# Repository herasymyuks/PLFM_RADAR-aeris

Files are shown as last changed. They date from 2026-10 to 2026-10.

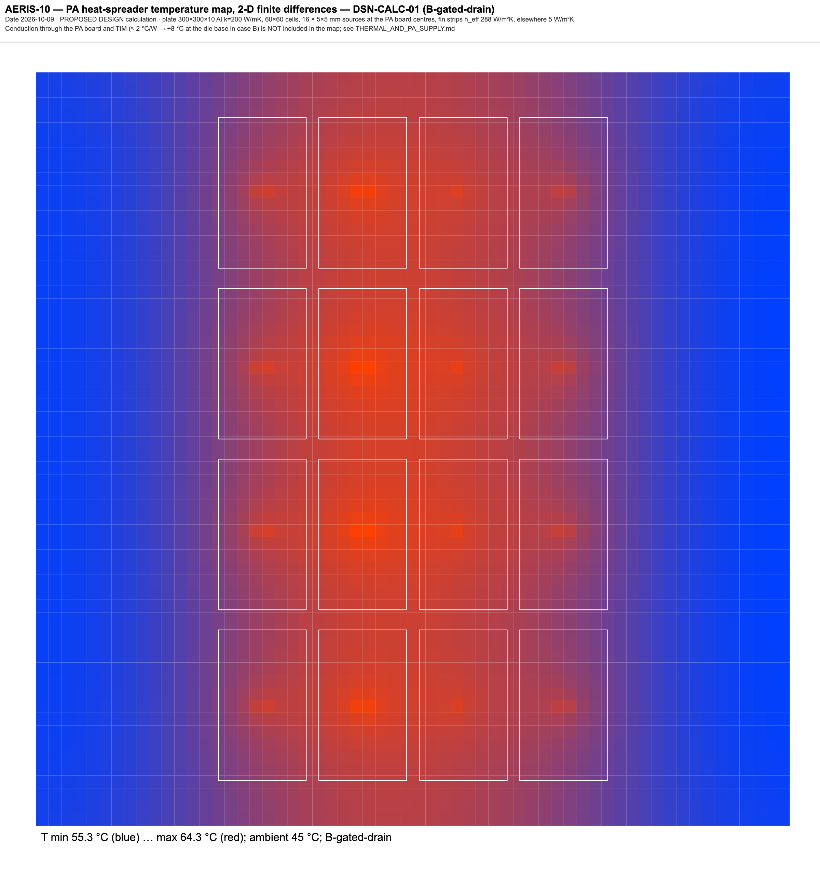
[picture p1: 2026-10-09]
manual/figures/thermal_map_B-gated-drain.png

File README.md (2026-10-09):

# AERIS-10: Open Source Pulse Linear Frequency Modulated Phased Array Radar



)


AERIS-10 Radar System

AERIS-10 is an open-source, low-cost 10.5 GHz phased array radar system featuring Pulse Linear Frequency Modulated (LFM) modulation. Available in two versions (3km and 20km range), it's designed for researchers, drone developers, and serious SDR enthusiasts who want to explore and experiment with phased array radar technology.

AERIS-10 Radar System

## 📡 Overview

The AERIS-10 project aims to democratize radar technology by providing a fully open-source, modular, and hackable radar system. Whether you're a university researcher, a drone startup, or an advanced maker, AERIS-10 offers a platform for experimenting with beamforming, pulse compression, Doppler processing, and target tracking.

## 🔬 Key Features

- **Open Source Hardware & Software** - Complete schematics, PCB layouts, firmware, and software available
- **Dual Version Availability**:
  - **AERIS-10N (Nexus)**: 3km range with 8x16 patch antenna array
  - **AERIS-10X (Extended)**: 20km range with 32x16 dielectric-filled slotted waveguide array
- **Full Electronic Beam Steering** - ±45° electronic steering in elevation and azimuth
- **Advanced Signal Processing** - On-board FPGA handles pulse compression, Doppler FFT, MTI, and CFAR
- **Python GUI** - User-friendly interface with map integration
- **GPS/IMU Integration** - Real-time position and attitude correction
- **Modular Design** - Separate power management, frequency synthesis, and RF boards

## 🏗️ System Architecture

AERIS-10 Radar System

### Hardware Components

The AERIS-10 main sub-systems are:

- **Power Management Board** - Supplies all necessary voltage levels to the electronics components with proper filtering and sequencing (sequencing ensured by the microcontroller)

- **Frequency Synthesizer Board** - Uses a high-performance Low Jitter Clock Generator (AD9523-1) that supplies phase-aligned clock references for:
  - RX and TX Frequency Synthesizers (ADF4382)
  - DAC
  - ADC
  - FPGA

- **Main Board** containing:
  - **DAC** - Generates the RADAR Chirps
  - **2x Microwave Mixers (LT5552)** - For up-conversion and IF-down-conversion
  - **4x 4-Channel Phase Shifters (ADAR1000)** - For RX and TX chain beamforming
  - **16x Front End Chips (ADTR1107)** - Used for both Low Noise Amplifying (RX) and Power Amplifying (TX) stages
  - **XC7A50T-2FTG256I FPGA** (per the Main Board schematic, U42; earlier documentation said XC7A100T — see `docs/FPGA/FPGA_PROJECT_RECONSTRUCTION.md`) - Handles RADAR Signal Processing:
    - PLFM Chirps generation via the DAC
    - Raw ADC data read
    - Automatic Gain Control (AGC)
    - I/Q Baseband Down-Conversion
    - Decimation
    - Filtering
    - Forward FFT
    - Pulse Compression
    - Doppler, MTI and CFAR processing
    - USB Interface
  - **STM32F746xx Microcontroller** - Used for:
    - Power-up and power-down sequencing (see Power Management Excel File)
    - FPGA communication
    - Setup and Interface with:
      - Clock Generator (AD9523-1)
      - 2x Frequency Synthesizers (ADF4382)
      - 4x 4-Channel Phase Shifters (ADAR1000) for RADAR pulse sequencing
      - 2x ADS7830 ADCs (on Power Amplifier Boards) for Idq measurement
      - 2x DAC5578 (on Power Amplifier Boards) for Vg control
      - GPS module for GUI map centering
      - GY-85 IMU for pitch/roll correction of target coordinates
      - BMP180 Barometer
      - Stepper Motor
      - 8x ADS7830 Temperature Sensors for cooling fan control
      - RF switches

- **16x Power Amplifier Boards** - Used only for AERIS-10E version, featuring 10Watt QPA2962 GaN amplifier for extended range

- **Antenna Arrays**:
  - **AERIS-10N (Nexus)** - 8x16 patch antenna array
  - **AERIS-10X (Extended)** - 32x16 dielectric-filled slotted waveguide antenna array

- **Miscellaneous Components**:
  - Slip-Ring
  - Stepper Motor and drivers
  - Cooling Fans
  - Enclosure) 

### Processing Pipeline

1. **Waveform Generation** - DAC creates LFM chirps
2. **Up/Down Conversion** - LT5552 mixers handle frequency translation
3. **Beam Steering** - ADAR1000 phase shifters control 16 elements
4. **Signal Processing (FPGA)**:
   - Raw ADC data capture
   - I/Q baseband down-conversion
   - Decimation & filtering (CIC/FIR)
   - Pulse compression
   - Doppler FFT processing
   - MTI & CFAR detection
5. **System Management (STM32)**:
   - Power sequencing
   - Peripheral configuration
   - GPS/IMU integration
   - Stepper motor control
6. **Visualization (Python GUI)**:
   - Real-time target plotting
   - Map integration
   - Radar control interface

AERIS-10 Radar System

## 📊 Technical Specifications

| Parameter | AERIS-10N (Nexus) | AERIS-10X (Extended) |
|---|---|---|
| **Frequency** | 10.5 GHz | 10.5 GHz |
| **Max Range** | 3 km | 20 km |
| **Antenna** | 8x16 Patch Array | 32x16 Slotted Waveguide |
| **Beam Steering** | Electronic (±45°) | Electronic (±45°) |
| **Mechanical Scan** | 360° (stepper motor) | 360° (stepper motor) |
| **Output Power** | ~1Wx16 | 10Wx16 (GaN amplifier) |
| **Processing** | FPGA + STM32 | FPGA + STM32 |

## 🚀 Getting Started

### Prerequisites

- Basic understanding of radar principles
- Experience with PCB assembly (for hardware build)
- Python 3.8+ for the GUI software
- FPGA development tools (Vivado) for signal processing modifications

### Hardware Assembly

1. **Order PCBs**: the designer-released EAGLE export does not exist in `4_Schematics and Boards Layout/4_7_Production Files` (only the Synthesizer P&P/BOM). KiCad-converted manufacturing packages (Gerber, drill, drawings, STEP, DRC) for all four boards are in `engineering/PCB/<BOARD>/` (status in each README — Main and Power Board layouts are unfinished in the source); BETA completions in `beta/pcb/`.
2. **Source Components**: bills of materials with reference designators in `docs/BOM/` (no manufacturer part numbers in the source schematics; BETA BOMs with proposed MPNs in `beta/pcb/`).
3. **Assembly**: `engineering/ASSEMBLY/ASSEMBLY_SEQUENCE.md`, `PARTS_LIST.md` and the CONCEPTUAL exploded view (the `10_docs/assembly_guide.md` referenced earlier was never committed).
4. **Antenna**: no antenna CAD exists in the repository; a PROPOSED 16×8 patch-array panel (KiCad) is in `engineering/DESIGN/ANTENNA/`.
5. **Enclosure**: no enclosure files exist (the `10_docs/Hardware/Enclosure` folder referenced earlier was never committed); a PROPOSED head/pedestal design (FreeCAD/STEP, drawings) is in `engineering/DESIGN/MECHANICAL/`.

> **Reconstruction status (2026-10-09):** see `docs/AERIS10_ENGINEERING_BUILD_MANUAL.md` (master manual), `engineering/DRAWING_REGISTER.md` and `beta/README.md`. Run `bash tools/run_all_checks.sh` for the current validation state.

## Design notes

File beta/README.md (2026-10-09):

# beta/ — BETA completions of the missing AERIS-10 elements

Created 2026-10-09. Everything here is **BETA**: it builds/parses/simulates/routes with the tools on the authoring machine but has **not** been synthesised in Vivado, flashed, run on hardware, reviewed by the original designer or fabricated. Originals under `9_Firmware/` and `4_Schematics and Boards Layout/` are untouched; each sub-project starts from a copy and keeps a `CHANGELOG.md` of every change.

| Sub-project | Content | Build/verify | Status |
|---|---|---|---|
| `fpga/` | RTL copies with syntax/driver fixes, the 5 missing modules (ADC capture, matched-filter chain, range-bin decimator, FFT wrappers), seg3 `.mem`, self-checking testbenches, timing + schematic-derived XDC, Vivado Tcl | `bash beta/fpga/build.sh` (iverilog + verilator) | see `fpga/README.md` |
| `stm32/` | Firmware copies with the 7 defect fixes and hardware-truth decisions (8 MHz HSE), hand-written CubeMX-equivalent files (USB CDC, startup, linker, HAL conf), CMake build with the ARM GNU toolchain, host unit tests | `bash beta/stm32/build.sh` | see `stm32/README.md` |
| `gui/` | `aeris10_gui` package: firmware-exact settings packet, FPGA packet parser, CDC I/O, CFAR/clustering/tracking, simulator, Tk UI, pytest suite, PyInstaller | `pytest -q` in `beta/gui` | see `gui/README.md` |
| `pcb/` | KiCad routing completion (Freerouting), placement of off-board parts, DRC dispositions, BOMs with proposed MPNs, fabrication notes/stack-up proposals, re-exported packages | DRC reports in each board folder | see `pcb/README.md` |

Simulation of the proposed antenna (openEMS, built from source on this machine) is reported in `engineering/DESIGN/ANTENNA/` once run.

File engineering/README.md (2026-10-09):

# engineering/ — AERIS-10 engineering drawings and CAD package

Generated 2026-10-09 (claude.md addendum §16–26). Everything here is derived from the repository's native design files; the EAGLE `.sch/.brd` files remain the design masters and were not modified. Start with:

- `DRAWING_REGISTER.md` — all 73 registered drawings with status (39 SOURCE-DERIVED, 28 PARTIAL, 1 CONCEPTUAL, 5 BLOCKED — MISSING DATA; 0 VERIFIED).
- `MISSING_DRAWINGS_RECOVERY_PLAN.md` — step-by-step guides MDR-01…MDR-11 for what could not be generated.
- `VALIDATION/` — `DRAWING_CHECKS.md` (what was checked and how), `CAD_EXPORT_LOG.md` (every kicad-cli command + exit code), `PCB_CROSS_CHECK.md` (EAGLE XML ↔ KiCad counts), `UNRESOLVED_GEOMETRY.md` (G-01…G-12).

| Directory | Content | Generator |
|---|---|---|
| `SYSTEM/block_diagrams`, `interfaces`, `data_flow`, `architecture/README.md` | SYS-01…SYS-03 DOT + SVG/PDF/PNG, Mermaid twin, interconnection table | hand-authored DOT from schematic nets (Graphviz) |
| `ELECTRICAL/schematics/<BOARD>/` | SVG per sheet, multi-page PDF, PNG, `sheets.json` | `tools/render_eagle_schematic.py`, `tools/svg_sheets_to_pdf.py` |
| `ELECTRICAL/netlists`, `connection_diagrams` | netlist CSV (by net, by part), connection reports, unresolved-connection and missing-symbol/footprint reports | `tools/gen_schematic_reports.py` |
| `ELECTRICAL/power_distribution` | ELEC-PWR-01 diagram + 36-row rail register | hand-authored DOT |
| `PCB/<BOARD>/` | KiCad conversion (`kicad/`), Gerber, drill, PDF drawings, SVG layers, DXF/STEP, P&P, BOM, IPC-2581, IPC-D-356, DRC, 3-D renders, `README.md`, `STACKUP.md` | `tools/kicad_pcb_pipeline.sh`, `tools/kicad_project_from_dru.py`, `tools/gen_engineering_pcb_docs.py` |
| `MECHANICAL/CAD`, `STEP`, `DXF`, `PDF`, `dimensions` | board bodies, outlines + holes (two independent DXF sources), 1:1 plan view, dimension sheets with hole tables | `tools/gen_mechanical_package.py` |
| `ASSEMBLY/` | parts list, assembly sequence, CONCEPTUAL exploded view, per-board assembly drawing index | `tools/gen_assembly_exploded_view.py` + hand-written MD |
| `SOFTWARE_DIAGRAMS/FPGA`, `STM32`, `PYTHON`, `DATA_FLOW` | SD-01…SD-07 DOT + renders, hierarchy/module tables | `tools/gen_verilog_hierarchy.py`, `tools/gen_python_module_graph.py`, hand-authored DOT |

Regenerate everything (≈ 10 min, needs KiCad 10 and Google Chrome on the machine; Graphviz for the DOT renders):

```bash
bash tools/kicad_pcb_pipeline.sh                      # 4 boards → engineering/PCB/*
python3 tools/gen_engineering_pcb_docs.py             # README/STACKUP per board + PCB_CROSS_CHECK.md
python3 tools/gen_schematic_reports.py                # netlists + connection reports
for b in RF_PA FREQUENCY_SYNTHESIZER MAIN_BOARD POWER_SUPPLY; do
  python3 tools/render_eagle_schematic.py "<path to .sch>" --out engineering/ELECTRICAL/schematics/$b/svg --board $b --root .
  python3 tools/svg_sheets_to_pdf.py -o engineering/ELECTRICAL/schematics/$b/${b}_schematic.pdf --png-dir engineering/ELECTRICAL/schematics/$b/png engineering/ELECTRICAL/schematics/$b/svg/*.svg
done
python3 tools/gen_mechanical_package.py && python3 tools/gen_assembly_exploded_view.py
python3 tools/gen_verilog_hierarchy.py --rtl 9_Firmware/9_2_FPGA --out engineering/SOFTWARE_DIAGRAMS/FPGA
python3 tools/gen_python_module_graph.py
for d in $(find engineering -name "*.dot"); do dot -Tsvg -o ${d%.dot}.svg $d; dot -Tpdf -o ${d%.dot}.pdf $d; dot -Tpng -Gdpi=150 -o ${d%.dot}.png $d; done
python3 tools/gen_drawing_register.py --check
```

Size note: `PCB/MAIN_BOARD/ipc/MAIN_BOARD.xml.gz` and the other large IPC-2581 files are gzip-compressed; `gunzip -k` before use.

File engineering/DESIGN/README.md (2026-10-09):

# engineering/DESIGN — PROPOSED designs for the missing elements

Generated 2026-10-09. Everything here is new engineering content (status **PROPOSED DESIGN**), derived from the verified constraints in the repository plus the decisions logged in `00_DESIGN_BASIS.md` (D-01…D-15). Parameters: `design_parameters.json` (single source; every generator reads it). Nothing here has been simulated on hardware, built or measured.

| Item | Directory | Native / editable | Exports | Generator |
|---|---|---|---|---|
| Design basis + decision log | `00_DESIGN_BASIS.md`, `design_parameters.json` | Markdown/JSON | — | hand-written |
| Antenna: 16-row × 8-patch microstrip array, 10.5 GHz, RO4350B | `ANTENNA/` | `kicad/aeris10_patch_array.kicad_pcb` (KiCad 8+) | layout SVG/PDF/PNG, Gerber + drill + STEP + render in `kicad_exports/`, `ANTENNA_DESIGN_CALC.md`, `openems_patch_row.py` | `tools/design_antenna_array.py` |
| Thermal budget, 22 V supply sizing | `THERMAL/` | Markdown + JSON | — | `tools/design_thermal.py` |
| 22 V PA supply / enable switch / per-PA pulse gating | `ELECTRICAL/PA_SUPPLY_22V/` | block schematic SVG (editable), BOM CSV, net list | PDF/PNG | `tools/design_pa_supply_schematic.py` |
| Radar head + pedestal 3-D | `MECHANICAL/CAD/` | `aeris10_head_pedestal.FCStd` (FreeCAD 1.1) | STEP (assembly, head, pedestal), STL, TechDraw DXF page, mass table, isometric SVG/PDF/PNG (`tools/stl_to_svg_iso.py`) | `tools/design_mechanical_freecad.py` (run with `freecadcmd`) |
| Head/pedestal 2-D drawings DSN-MECH-01…05 | `MECHANICAL/drawings/` | SVG 1:1 | PDF (5 pages), PNG | `tools/design_mechanical_drawings.py` |
| Harness schedule (144 cables, computed lengths) | `HARNESS/` | CSV | Markdown | `tools/design_mechanical_drawings.py` |

Key proposed numbers: head 315 × 315 × 133 mm (W × H × D), all boards vertical; PA heat spreader 300 × 300 × 10 mm with two fin fields; antenna panel 165 × 248 mm; 16 PA boards 4 × 4; pedestal 360 × 360 × 130 mm with slewing bearing, 1:3 GT3 belt to a NEMA 23 (needs `Stepper_steps = 600` in firmware), 12-circuit slip ring; PA drain gating per chirp reduces the PA dissipation from 591 W (as coded) to 68 W.

Regenerate: `python3 tools/design_thermal.py && python3 tools/design_antenna_array.py && python3 tools/design_pa_supply_schematic.py && python3 tools/design_mechanical_drawings.py && freecadcmd -c "exec(open('tools/design_mechanical_freecad.py').read())"`.

What the owner must decide before any of this is built: D-01 (antenna variant), D-07 (measure component heights), D-12 (firmware constant / gear ratio), D-13 (host link through the slip ring), D-14 (where the `TX_GATE` signal comes from), plus conflicts K1–K8.

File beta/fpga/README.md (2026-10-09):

# AERIS-10 FPGA design - BETA project (`beta/fpga/`)

**Status: BETA.** Everything in this directory parses, elaborates, lints and simulates with
open-source tools (Icarus Verilog 13.0, Verilator 5.052, Python 3 / numpy). It has **not been
synthesised** (no Vivado on the authoring machine), has **no timing closure**, has **not been
loaded on hardware**, and the two Xilinx FFT IP cores it needs have **not been generated**.
Nothing under `9_Firmware/9_2_FPGA/` was modified; every difference is listed in
[`CHANGELOG.md`](CHANGELOG.md) with original file:line references.

Starting point: `docs/FPGA/FPGA_PROJECT_RECONSTRUCTION.md` (the original RTL did not elaborate:
3 syntax defects, 5 missing modules, multi-driven registers, undriven control inputs, no 400 MHz
capture, placeholder constraints).

## Directory

```
beta/fpga/
├── build.sh                 open-source flow (exit code = number of failures)      <- RUN THIS
├── gen_chirp_mem.py         verifies the .mem formula, writes the missing seg3 files
├── CHANGELOG.md             every change vs. 9_Firmware/9_2_FPGA, file:line + reason
├── rtl/                     synthesisable Verilog-2001 (34 files; incl. host-link option B and the ISERDES capture path)
│   ├── sim/unisim_sim_models.v   BUFG/IBUFDS/IDDR stand-ins (simulation + lint only)
│   └── unused_orig/              5 untouched originals that are no longer compiled (+README)
├── mem/                     8 original .mem copies + generated long_chirp_seg3_{i,q}.mem
├── tb/                      8 self-checking testbenches (9 runs), gen_vectors.py, vectors/, original TB (reference)
├── constraints/radar_system_top_beta.xdc
├── vivado/create_project.tcl, vivado/build.tcl     (NOT executed)
├── ip/README.md             exact FFT IP settings (xfft v9.1) derived from the port usage
└── logs/                    output of the last build.sh run (iverilog, verilator, vvp logs)
```

## How to run

```sh
cd beta/fpga
./build.sh                 # ~2 min; SKIP_SYSTEM=1 ./build.sh skips the long system test; VERBOSE=1 prints sim output
```
`build.sh` runs, in order: iverilog elaboration (simulation view `-DSIM` and synthesis view),
`verilator --lint-only -Wall` on both views, `gen_chirp_mem.py`, `tb/gen_vectors.py`, and every
`tb/tb_*.v` with `vvp`. A testbench passes only if it exits 0 and prints `PASS` and never `FAIL`.
The RTL's `$readmemh` paths are `mem/...` relative to `beta/fpga` (the script `cd`s there; Vivado
resolves Memory Files by name).

## What passed (last run 2026-10-09, after command set v2 + blind calibration; logs in `logs/`)

| Step | Command (from `build.sh`) | Result | Log |
|---|---|---|---|
| 1 | `iverilog -g2005 -DSIM -s radar_system_top rtl/*.v rtl/sim/unisim_sim_models.v` | PASS | `logs/iverilog_top_sim.log` |
| 2 | `iverilog -g2005 -s radar_system_top ...` (synthesis view) | PASS | `logs/iverilog_top_synth.log` |
| 3a | `verilator --lint-only -Wall -Wno-fatal --top-module radar_system_top ...` (synth view) | PASS, **0 %Error, 165 %Warning** (unchanged) | `logs/verilator_synth.log` |
| 3b | same with `-DSIM` | PASS, **0 %Error, 159 %Warning** | `logs/verilator_sim.log` |
| 4 | `python3 gen_chirp_mem.py` | PASS: seg0/1/2 reproduced within 1 LSB, seg3 written | `logs/gen_chirp_mem.log` |
| 5 | `python3 tb/gen_vectors.py` | PASS | `logs/gen_vectors.log` |
| 6a | `tb_fft_wrappers` - xfft_32 (4 frames incl. back-pressure) and FFT_enhanced (fwd + inv) vs numpy | PASS: 2176 samples within +/-2 LSB | `logs/tb_fft_wrappers.run.log` |
| 6b | `tb_matched_filter` - chain + memory, reference chirp delayed 300 samples | PASS: peak at bin 302 (300 +/-4), peak/sidelobe 4.76 | `logs/tb_matched_filter.run.log` |
| 6c | `tb_range_bin_decimator` - 2 x 1024 bins (one with input gaps) vs numpy, peak mode | PASS: 128/128 bins | `logs/tb_range_bin_decimator.run.log` |
| 6d | `tb_system_smoke` - full top, 10 chirps, synthetic IF echoes, 3.3 ms (see 6i for the two capture modes) | PASS (~65 s each): see below | `logs/tb_system_smoke_mode1.run.log` |
| 6e | `tb_host_bridge` - HOST_LINK unit test (packer + SPI slave): 3 detections, 32 detections (det_wr regression), command set v2 against a 4-word register model | PASS: 2075- and 2162-byte frames, CRC ok; v2 write/read-back/status/unknown ok | `logs/tb_host_bridge.run.log` |
| 6f | `tb_host_bridge_top` - option B bridge through the top: v2 register commands (CFAR_THR 10000 -> 150 written over SPI, 5 read-backs, 0x04 status before/with/after a frame, 0xEE), then the SPI master reads one 64x32 frame after DRDY | PASS (~77 s): 2162-byte frame, 32 detections (only possible because the threshold write took effect), sync/dims/az-el/chirp-count/map/CRC ok, ADAR pass-through gated | `logs/tb_host_bridge_top.run.log` |
| 6g | `tb_adc_iserdes_capture` - ISERDES capture + IDELAY calibration (pattern and blind) + FIFO | PASS (~30 s): pattern method 8/8 lanes locked, centre tap 13, skewed lane 5 -> 5 (8 taps = 0.6 ns compensated), bitslip detected/realigned, 4000 samples exact; blind method on a 120 MHz tone + 0.7 LSB rms noise with lane 2 parked on a metastable tap and lane 0 mis-framed: 8/8 lanes locked, every lane within **+/-0 taps** of the pattern centre, framing restored, 4000 tone samples exact | `logs/tb_adc_iserdes_capture.run.log` |
| 6h | `tb_ddc_4x` - legacy 400 MHz DDC vs polyphase DDC, same input | PASS: 1855 outputs, max diff 0 LSB | `logs/tb_ddc_4x.run.log` |
| 6i | `tb_system_smoke` runs twice: `ADC_CAPTURE_MODE=1` (default) and `=0` | both PASS | `logs/tb_system_smoke_mode1.run.log`, `_mode0` |

`build.sh` summary line: `0 failure(s), 324 verilator warning line(s) (both views)` (165 synth view + 159 sim view; 219 for the first beta, 241 after the host link, 324 after the ISERDES capture path, unchanged 324 after command set v2 + blind calibration: the only new lint findings were two BLKSEQ on block-local temporaries in the sim-only ISERDESE2 model, marked as intended).

System smoke test evidence (`logs/tb_system_smoke.run.log`): DAC left mid-scale (57540 samples);
40 range profiles (4 segments x 10 chirps); for alternating echo delays of 100 and 420 baseband
samples the segment-0 peak sat at decimated bin 8 and 28 on every chirp - a shift of 20 bins for a
320-sample delay change (320/16 = 20), i.e. pulse compression works end to end through capture ->
DDC -> matched filter -> decimator; 2048 Doppler outputs (one 64 x 32 frame); 2688 USB packets with
0 header/footer/sequence errors; no X on outputs; the matched-filter FSM was idle at every toggle.

Verilator warning breakdown (synthesis view, 165): 59 PINCONNECTEMPTY (monitor/unused IP outputs left
unconnected on purpose), 32 UNUSEDSIGNAL (diagnostic nets of the original, unused IP tready/tlast),
22 WIDTHTRUNC / 16 WIDTHEXPAND (original arithmetic widths, the copied host-link modules, the UNISIM
models), 13 PROCASSINIT + 2 BLKSEQ + 1 ZERODLY (simulation-only UNISIM models in `rtl/sim/`), 9
DECLFILENAME (original file names differ from module names - kept so the docs stay valid), 7
UNUSEDPARAM, 3 GENUNNAMED (original `generate`), 1 CMPCONST (`host_bridge_spi`). None was hidden
with a global `-Wno-*`; the few local `lint_off` pragmas are documented in the source next to the
reason.

Additional checks: `tools/check_fpga_constraints.py --top beta/fpga/rtl/radar_system_top.v --xdc
beta/fpga/constraints/radar_system_top_beta.xdc` -> 0 placeholders, 0 invalid properties, 67/183
port bits constrained (the 116 unconstrained bits are exactly the UNRESOLVED ports below).
`tools/gen_verilog_hierarchy.py --rtl beta/fpga/rtl` -> 0 missing RTL modules; the only "missing"
names are the two deliberate IP placeholders (`logs/hier/`).

## What was found and decided (engineering notes)

1. **The reference memories are frequency-domain matched-filter coefficients.**
   `long_chirp_seg{0,1,2}_{i,q}.mem` = `conj(FFT_1024(u_s)) * 31128/max|.|`, where `u` is a
   unit-amplitude 10 -> 30 MHz linear up-chirp, 3000 samples at 100 MSPS (phase fit residual
   0.0018 rad; regenerated to within 1 LSB by `gen_chirp_mem.py`). Segment 3 lies beyond the
   chirp and is therefore all zeros - that is the file that was missing.
   Consequence: the brief's suggestion of a time-domain FIR matched filter would not have used
   the repository data. `matched_filter_processing_chain` is therefore the frequency-domain chain
   the original architecture implies (orphan wrappers `fft_1024_forward/inverse_enhanced` +
   `frequency_matched_filter`), and the reference is multiplied **without** the extra conjugation
   (`CONJUGATE_REF = 0`): with the original conjugating form the numpy model and the RTL produce no
   compression peak (convolution instead of correlation).
   **Open point for the designer:** the same data equals `FFT` of a 30 -> 10 MHz down-chirp, so the
   actual baseband chirp direction after the RF/IF chain decides whether `CONJUGATE_REF` must be
   0 (up-chirp at baseband, as the beta assumes) or 1. `short_chirp_{i,q}.mem` (50 words) matches
   neither a time- nor a frequency-domain chirp and cannot be used - the short-chirp path is
   UNRESOLVED.
2. **AD9484 output is SDR LVDS at the sample rate** (datasheet: "LVDS SDR output", "data clock
   output ... must be captured on the rising edge of the DCO", tSKEW +/-0.07 ns). The capture module
   uses the DCO as the 400 MHz clock (IBUFDS -> BUFG) and an IDDR as a dual-edge sampler, taking
   the falling-edge sample (mid-bit for an edge-aligned bus) by default (`CAPTURE_FALLING`). This
   assumption is documented in `rtl/ad9484_lvds_to_cmos_400m.v` and constrained in the XDC; it must
   be confirmed by Vivado timing analysis and an ADC test pattern on hardware.
3. **Reference alignment by address, not by delay line.** The chain requests reference bin k when
   FFT output bin k appears (1-cycle memory latency compensated), so the fixed 3187-cycle
   `latency_buffer_2159` (tied to an unknown IP latency) is not needed. Works with the behavioural
   model (latency 160) and with any IP latency.
4. **Clock-domain crossings**: `cdc_adc_to_processing` (Gray-coded data words) replaced by Gray-pointer
   FIFOs; a reset synchroniser per non-100 MHz domain; STM32 toggles synchronised in the clock
   domain that consumes them (TX: 120 MHz FSM, RX: 100 MHz).
5. **Register map** (`radar_control_regs`): the receiver's control inputs that were floating wires
   now have one driver with documented reset defaults. Its write/read port is driven by the SPI
   bridge (command set v2, see "Host path"); 5-bit word addresses 0x00..0x10, 16-bit registers,
   table in `engineering/DESIGN/HOST_LINK/HOST_LINK_DESIGN.md` section 7 (kept identical to the RTL).

## ADC capture and DDC front end (`ADC_CAPTURE_MODE`, default 1)

| | mode 0 (legacy) | mode 1 (default) |
|---|---|---|
| Capture | `ad9484_lvds_to_cmos_400m`: IBUFDS -> BUFG (400 MHz global clock) -> IDDR as dual-edge sampler | `ad9484_iserdes_capture`: IBUFDS(DCO) -> BUFIO + BUFR/4; IDELAYE2 (VAR_LOAD) -> ISERDESE2 SDR 1:4 per lane; IDELAYCTRL on 200 MHz from `clk_gen` (MMCM); 32-bit `async_fifo` into clk_100m |
| DDC | `ddc_400m_enhanced`: NCO, mixer, 5-stage CIC at 400 MHz in fabric (timing closure unrealistic), FIFO, FIR | `ddc_4x_100m`: 4-phase NCO + 8 mixers + CIC as 16-tap FIR + the same FIRs, all at 100 MHz; **bit-exact** with the legacy path (`tb_ddc_4x`: max diff 0 LSB) |
| Calibration | none (`CAPTURE_FALLING` edge choice) | `adc_capture_calib`: default tap 16; manual tap/bitslip per lane; **pattern method** (CAL_CTRL bit4 = 0): auto IDELAY sweep with the ADC in a 2-code test pattern (register 0x0D = 0x48, P1/P2 = 0x19..0x1C = pattern A/B; or 0x04 checkerboard / 0x07 toggle), centre tap per lane, lane rotation alignment, lock/undetermined/align_fail status, pattern error counter; **blind method** (CAL_CTRL bit4 = 1, no ADC SPI needed): a CW tone at the IF on the live input, notch residual r[n] = x[n] - 2cos(w)x[n-1] + x[n-2] (CAL_BLIND_COEF = Q1.14 cos(w)), metric = sum of abs(r) over 512 words per tap, one lane swept at a time MSB first, pass = metric <= min + CAL_BLIND_MARGIN + min/16, longest linear run (1-tap holes closed), eye truncated at tap 0 extrapolated with the 32-taps-per-bit period, blind framing alignment (best of 4 framings per lane) before and after each of 2 passes; CAL_BLIND_MIN read-back (register map 0x4..0x10) |

Datasheet facts used (AD9484.pdf, re-checked): LVDS SDR, DCO at the sample rate (400 MHz), data valid
on the rising DCO edge, tSKEW -0.07..+0.07 ns (tPD 0.85 / tCPD 0.6 ns typ), offset binary.

Resource estimate for mode 1 (XC7A50T): 8 ISERDESE2 + 8 IDELAYE2 + 1 IDELAYCTRL (bank 14), 1 BUFIO +
1 BUFR, 1 MMCME2 (of 5) + 1 BUFG, 8 DSP48E1 for the mixers (9x16) + 64 DSP48E1 for the two
unchanged 32-tap FIRs (of 120), CIC adder trees in LUTs (~16 constant multiplies per I/Q), 1 BRAM18
for the 32-bit FIFO (or distributed RAM), small ROM for the 65-entry sine table. The 400 MHz
fabric path (mode 0) is kept only for comparison.

Remaining risks / what to check in Vivado (mode 1):
* BUFR (DCO/4) versus clk_100m (AD9523 OUT6): same nominal frequency, unknown phase; the FIFO
  absorbs phase/jitter, `cal_status[15]` (FIFO overflow) must stay 0 on hardware. If the two clocks
  are not frequency-locked the design needs a re-sampler (not present).
* IDELAYCTRL placement: all IDELAYE2 and the IDELAYCTRL must be in bank 14 (`IODELAY_GROUP` set in
  the XDC); the 200 MHz reference comes from the MMCM through a BUFG.
* Bank 14 is 3.3 V: LVDS_25 inputs only with `DIFF_TERM FALSE` and external 100 Ohm termination
  (design conflict kept visible in the XDC).
* ISERDESE2 Q1..Q4 bit order: resolved from UG471 (see "UG471 checks" below) - `Q1_IS_OLDEST = 0`
  (first bit received on Q4, newest on Q1) in RTL, receiver and TB, and the simulation model was
  corrected to the same order; still confirm on hardware with the ADC PN9 pattern (0x0D = 0x06)
  against a PN9 generator. BUFR framing (which DCO edge starts a 4-sample word) is irrelevant for
  the data path (common rotation of all lanes) and is absorbed by the per-lane alignment.
* Blind calibration limits (`adc_capture_calib.v` header): single CW tone at the programmed
  frequency with every bit toggling (>= ~64 LSB peak for bit 7); the LSB lanes need <= ~1 LSB rms
  input noise at the default 512-word window (0.7 LSB rms in the TB; AD9484 ~47 dB SNR = ~0.5 LSB
  rms) - at 1.4 LSB rms lane 0 reports `undetermined` and keeps its tap; the eye-centre
  extrapolation for runs cut at tap 0 assumes exactly 32 taps per bit (400 MSPS, 78.125 ps/tap)
  and a 5-tap metastable region (`FAIL_HALF = 2`, the simulation model's 0.4 ns; the hardware
  value is unknown, an error of e taps moves the centre by e); the blind framing alignment takes
  the minimum of four metrics without a significance test (`align_fail` stays 0). Run time
  ~3.3 ms (2 passes x 8 lanes x 32 taps x 528 clk_div cycles + 3 alignments).
* Checks after implementation: `report_clock_interaction` (clk_div <-> clk_100m only through the
  FIFO, adc_dco/clk_div/clk_200m as derived clocks), `report_timing_summary` for the clk_div and
  clk_200m paths, `report_cdc`, `report_io`; on hardware: run the auto calibration with the ADC test
  pattern, read `CAL_STAT`/`CAL_LANE_INFO` per lane (windows should be ~27 of 32 taps wide at
  400 MSPS), then switch to normal data and check `CAL_ERR` stays 0 while the pattern check is off.

## UG471 checks (v1.10, `build/docs_ext/ug471.txt` = pdftotext of the web-archive copy, 2026-10-09)

Verbatim quotes used to settle two open points; the simulation model and the RTL default were
changed where they disagreed (CHANGELOG "Command set v2, blind calibration, UG471").

1. ISERDESE2 output order, section "ISERDESE2 Ports - Registered Outputs - Q1 to Q8" (p. 146):
   *"The first data bit received appears on the highest order Q output. The bit ordering at the
   input of an OSERDESE2 is the opposite of the bit ordering at the output of an ISERDESE2 block,
   as shown in Figure 3-3. For example, the least significant bit A of the word FEDCBA is placed at
   the D1 input of an OSERDESE2, but the same bit A emerges from the ISERDESE2 block at the Q8
   output. In other words, D1 is the least significant input to the OSERDESE2, while Q8 is the
   least significant output of the ISERDESE2 block."* (OSERDESE2 section, p. 161: *"data on the D1
   input pin is the first bit transmitted"*). For the 1:4 SDR configuration the first (oldest) bit
   is therefore on **Q4**, the newest on **Q1** -> `Q1_IS_OLDEST = 0`, `word[7:0] = Q4` (s0 = oldest).
   The sim model had Q1 = oldest and was corrected.
2. BITSLIP in SDR mode, section "BITSLIP Submodule - Bitslip Operation" (p. 158): *"By asserting
   the Bitslip pin of the ISERDESE2 block, the incoming serial data stream is reordered at the
   parallel side. ... (Bit 8 of an input ISERDESE2 is the first bit received.) ... The Bitslip
   operation is synchronous to CLKDIV. In SDR mode, every Bitslip operation causes the output
   pattern to shift left by one. In DDR mode, every Bitslip operation causes the output pattern to
   alternate between a shift right by one and shift left by three."* and *"Although the repeating
   pattern seems to show that bitslip is a barrel shifting operation, this is not the case. A
   bitslip operation adds one bit to the input data stream and loses the nth bit in the input data
   stream."* Figure 3-11 (SDR): initial 10010011 -> after one Bitslip 00100111 (Q8..Q1 notation),
   i.e. the word boundary moves one bit later in the serial stream. "Guidelines for Using the
   Bitslip Submodule" (p. 159): *"In NETWORKING mode the Bitslip submodule is available. ... the
   BITSLIP port must be asserted High for one CLKDIV cycle. Bitslip cannot be asserted for two
   consecutive CLKDIV cycles; ... the total latency ... is two CLKDIV cycles. ... The user logic
   should wait for at least two CLKDIV cycles in SDR mode ... before analyzing the received data
   pattern"* - `adc_capture_calib` pulses BITSLIP for one cycle with >= 1 idle cycle between
   pulses and waits SETTLE = 16 cycles; the sim model's slip direction was corrected to Fig. 3-11.
3. LVDS_25 inputs in a 3.3 V HR bank, section "LVDS and LVDS_25 (Low Voltage Differential
   Signaling)" (p. 92): *"It is acceptable to have differential inputs such as LVDS and LVDS_25 in
   I/O banks that are powered at voltage levels other than the nominal voltages required for the
   outputs of those standards (1.8V for LVDS outputs, and 2.5V for LVDS_25 outputs). However,
   these criteria must be met: - The optional internal differential termination is not used
   (DIFF_TERM = FALSE, which is the default value). - The differential signals at the input pins
   meet the VIN requirements in the Recommended Operating Conditions table of the specific device
   family data sheet. - The differential signals at the input pins meet the VIDIFF (min)
   requirements in the corresponding LVDS or LVDS_25 DC specifications tables of the specific
   device family data sheet. - For HR I/O banks in bidirectional configuration, internal
   differential termination is always used."*; Figure 1-72 text: *"RDIFF provides the 100 Ohm
   differential receiver termination because the internal DIFF_TERM is set to FALSE."*; Table 1-55
   note 1a: *"The optional internal differential termination is not used (DIFF_TERM = FALSE, which
   is the default value) unless the VCCO voltage is at the level required for outputs."*;
   "Differential Termination Attribute" (p. 49): *"The VCCO of the I/O bank must be connected to
   1.8V for LVDS, and 2.5V for the other differential I/O standards to provide 100 Ohm of effective
   differential termination. DIFF_TERM is only available for inputs and can only be used the
   appropriate VCCO voltage."* -> the XDC keeps `LVDS_25` + `DIFF_TERM FALSE` on the nine bank-14
   pairs and states that an external 100 Ohm termination at the FPGA (absent on the schematic) and a
   VIN/VIDIFF/VICM check of the AD9484 output against DS181 are REQUIRED (board change / verification).

## Constraints (`constraints/radar_system_top_beta.xdc`)

* Pins: verbatim schematic-derived candidates for 64 ports / 64 bits (`PIN_MAP_FROM_SCHEMATIC.md`),
  every ball still to be cross-checked against the AMD FTG256 package file and the final layout.
* Clocks: `create_clock` for clk_100m (10 ns), clk_120m_dac (8.333 ns), adc_dco (2.5 ns),
  ft601_clk_in (10 ns, no pin); `set_clock_groups -asynchronous` for all four; false paths for the
  asynchronous STM32 lines and the SPI pass-through; `set_input_delay` for the ADC bus from the
  datasheet skew plus an **unverified** +/-0.25 ns board allowance (both edges, falling-edge capture).
* **Design conflict kept visible:** bank 14 is 3.3 V on the schematic; the LVDS_25 ADC inputs are
  therefore constrained with `DIFF_TERM FALSE` (external 100 Ohm termination required - option A,
  REQUIRES VERIFICATION; the UG471 criteria are quoted verbatim in the XDC header) and the
  `DIFF_TERM TRUE` lines are left commented as option B (bank VCCO change). `CFGBVS VCCO` / `CONFIG_VOLTAGE 3.3` set from the bank-0 supply.
* Host-link option B pins H11/G12/H12 (DIG_5..7, bank 15, LVCMOS33) added; `spi_sclk` (37 ns)
  is a fifth asynchronous clock group.
* UNRESOLVED (116 bits, listed at the end of the file, unconstrained): `dac_clk` (DAC is clocked by
  AD9523 OUT10, not by the FPGA), all `ft601_*` (FT601 U6 has 0/77 pins connected), `current_*`,
  `new_chirp_frame`, `dbg_*`, `system_status` (no board nets). `write_bitstream` will refuse the
  unconstrained I/O unless they are removed from the top or `UNCONSTRAINEDPINS ALLOW` is set for a
  resource/timing trial only.

## Host path

**Option B (implemented, BETA): SPI bridge on the STM32 SPI1 bus.** `rd_map_packer` turns each
64 x 32 Doppler frame into a 2066..2162-byte frame (header, 2048 x uint8 log-magnitude, up to 32
detections, CRC-16/CCITT-FALSE; layout in `engineering/DESIGN/HOST_LINK/HOST_LINK_DESIGN.md` section
5) and `host_bridge_spi` streams it to the STM32 as an SPI slave (mode 0, MSB first, <= 27 MHz) on
the existing SCLK/MOSI/MISO nets with DIG_5 = `spi_bridge_cs_n` (H11), DIG_6 = `spi_bridge_drdy`
(G12), DIG_7 = `spi_bridge_spare` (H12, packer overflow flag). While the bridge CS is low the
ADAR1000 pass-through is gated (CS high, SCLK/MOSI idle on the 1.8 V side) and MISO is driven by
the bridge; `system_status[1]` latches a conflict if any ADAR CS is low during a transfer. Beam
indices come from the transmitter's STM32-toggle counters (synchronised), the chirp count from the
receiver's chirp pulses, `long_chirp` from the register map. Verified by `tb_host_bridge_top`
(frame read end to end through the top, see table). Firmware side: STM32 PD13 must become an
output (`main.cpp:2313-2317` configures PD13..15 as inputs), see `engineering/DESIGN/HOST_LINK/stm32`.
**Command set v2** (`host_bridge_spi.v`, `HOST_LINK_DESIGN.md` section 7, firmware
`beta/stm32/Core/Src/host_bridge_proto.c`): 0x01 frame read (unchanged), 0x02 register write
(`02 a0 a1 d0 d1 d2 d3 00`, ack 0xA2 in byte 7), 0x03 register read (`03 a0 a1 00 00 00 00`, value
little-endian in bytes 3..6, no turnaround byte: the read is launched when a0 is complete), 0x04
status (8 reply bytes: status word / RTL version 0x0002 / frames produced / 0), unknown command ->
0xEE. The bridge drives the register map's write/read port (5-bit addresses, 16-bit data); the
status word is assembled in the top (bit0 DRDY, bit1 ADAR CS conflict, bit2 capture FIFO overflow,
bit3 all-lanes calibration lock, bit4 packer overflow). Register toggles cross SCLK -> clk through
3-flop synchronisers; a read needs the >= 8 SCLK periods between a0 and d0 (>= 296 ns at 27 MHz,
the fetch takes <= 5 clk cycles); the 0x04 values are sampled in the SCLK domain (quasi-static).
Unresolved for option B: STM32 SPI1 timing versus the FPGA pins (XDC placeholders), BRAM inference
of the SCLK-domain frame RAM read (`host_bridge_spi.v`, asynchronous read registered on falling
SCLK), and the firmware rule that no ADAR1000 transaction overlaps a bridge read.

**Option A (kept unchanged, Main Board rev. B): FT601.** The RTL's original host interface is an FT601 slave-FIFO packetiser. On the Main Board the FT601 is placed but
not wired, and the STM32 reaches the FPGA only via `DIG_0..7` and the SPI1 pass-through (no chip
select for the FPGA). The beta keeps `usb_data_interface` (packet format defined in its header,
checked by `tb_system_smoke`) running on clk_100m so the data path can be simulated; a real FT601
needs the FSM re-timed to `ft601_clk` through `async_fifo`. Any other host path (SPI slave on
`DIG_5..7`, STM32 USB-FS forwarding, a wired FT601) is a board + firmware decision; the register
map's write port is the hook for it.

## Remaining work (ordered)

1. **Generate the two FFT IP cores** per `ip/README.md`, run `tb_fft_wrappers` against the IP
   simulation models (adjust `TOL` if the IP's per-stage rounding differs), record the IP latency
   and check `FFT_WAIT_TIMEOUT` in `doppler_processor.v`.
2. **Synthesis / implementation** with `vivado/create_project.tcl` + `vivado/build.tcl`
   (default part `xc7a50tftg256-2` = schematic U42; README/XDC claim XC7A100T - resolve first).
   Expect resource pressure: two 1024-point FFT IPs, 2 x 32 parallel 18x18 multipliers in the FIR
   (`fir_lowpass.v`, 64 DSP48E1 of the 50T's 120), 400 MHz fabric logic (next item).
3. **400 MHz fabric path replaced** (`ADC_CAPTURE_MODE = 1`, see "ADC capture and DDC front
   end"): ISERDESE2 SDR 1:4 + BUFR/4 + IDELAY calibration and a polyphase DDC at 100 MHz, bit-exact
   with the legacy path in simulation. Remaining: Vivado timing on the clk_div/clk_200m paths,
   IDELAYCTRL/IODELAY_GROUP placement, hardware calibration with the ADC test pattern, Q1..Q4 order.
4. **Matched-filter throughput.** The chain is not pipelined against the collector: one long chirp
   (4 segments) occupies the FSM for ~92 us with the behavioural FFT latency (160 clocks) and
   ~270 us with a realistic IP latency (~2.3k clocks per transform), while the TX repeats long chirps
   every 167 us (`plfm_chirp_controller.v`: 30 us chirp + 137 us listen). Samples arriving while the
   FSM is not in `ST_COLLECT_DATA` are dropped (original behaviour). Needs ping-pong buffering or
   overlapping collect/process; the smoke test uses a 300 us period for this reason.
5. **Segment semantics.** Each 1024-sample segment is compressed against its own reference segment
   and produces its own 64-bin profile; the four profiles per chirp are not summed, and the Doppler
   processor counts each profile as a "chirp" (a 32-"chirp" frame = 8 real chirps). Decide whether to
   sum the partial correlations (true partitioned matched filter) or to use a 4096-point transform.
6. **Hardware bring-up items** (all UNRESOLVED): confirm the chirp direction / `CONJUGATE_REF`;
   AD9484 capture edge and trace skew; bank-14 LVDS termination; ADC test pattern check; DAC data
   timing versus the externally clocked AD9708 (`dac_clk` has no pin); STM32 SPI1 clock rate versus
   the 1-cycle SPI pass-through re-timing; the short-chirp reference; the FT601/host decision.
7. CFAR (the detector is still a fixed threshold, default 10000 via `CFAR_THRESHOLD_DEFAULT`, now
   writable over the bridge as CFAR_THR); removal of the 116 unconstrained debug/status bits from
   the top before a board build. (Register-map host interface: done, command set v2; `det_wr`
   back-port: done - `engineering/DESIGN/HOST_LINK/rtl/` carries the v2 bridge and the extended unit TB.)
8. GUI `beta/gui/aeris10_gui/protocol/register_map.py` still assumes 4-bit addresses (`ADDR_MASK = 0xF`) — RESOLVED 2026-10-09: beta/gui register_map.py now ADDR_MASK = 0x1F with 0x0D/0x0E/0x10
   and carries a "DISCREPANCY" note about section 7 that is now resolved; it needs 0x04 bit4,
   0x0D, 0x0E, 0x10 and a 5-bit address mask.

## Known limitations of the beta (summary)

* Not synthesised, no timing, no hardware test; FFT IP not generated (fail-loud placeholders).
* Behavioural FFT models are not bit-exact with the Xilinx IP (total-shift scaling, round-half-up;
  TB tolerance +/-2 LSB) and their latencies (72 / 160 clocks) are placeholders.
* `rtl/sim/unisim_sim_models.v` models only the behaviour the design uses (no timing, IB ignored).
* USB packetiser runs on clk_100m and drops records that arrive while a packet is in flight
  (counted internally); 11-word packet format is a beta definition.
* The level-shifter pass-through adds one clk_100m cycle to SCLK/MOSI/CS and two to MISO.
* `use_long_chirp` is a register bit (default 1); the TX sequence's long/short alternation is not
  mirrored automatically in the receiver.

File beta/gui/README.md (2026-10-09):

# AERIS-10 Radar Host GUI -- BETA (`beta/gui`)

**BETA statement.** This package has **never been run against hardware**.

* FPGA -> host data: the **default path is the SPI bridge (option B, DSN-LINK-01)**. The
  FPGA serves 64x32 log-magnitude frames over SPI, and the STM32 forwards them unchanged
  over USB CDC, interleaved with status strings and `REG` replies
  (`engineering/DESIGN/HOST_LINK/HOST_LINK_DESIGN.md` section 5). This is simulated and
  unit-tested only. The raw 35-byte RTL packet path (option A, FT601) stays available with
  `--raw-ft601`, but on the board the FT601 is not wired (`docs/PCB/MAIN_BOARD.md`).
* FPGA register access (`REG W/R` over CDC, "FPGA registers / ADC calibration" tab) follows
  `beta/fpga/rtl/radar_control_regs.v`. The text protocol is **the same as the firmware's**
  (`beta/stm32/Core/Src/host_bridge_proto.c`): one command per USB transfer, replies
  `REG 0x%04X 0x%08X\r\n` / `REG ERR\r\n`, a write echoes the written value, and the
  firmware holds a single command slot, so the GUI sends one command at a time and waits for
  the reply (timeout + retransmit). Not bench-tested.
* The STM32 USB CDC path (settings upload, status/GPS reception) is implemented from
  the firmware sources but is **unverified on a board**; the firmware RX path itself is
  reported dead in `docs/STM32/`.
* Range/velocity scaling of the display rests on assumptions listed below.

The original GUI versions in `9_Firmware/9_3_GUI/` are untouched; this is a separate
package. `CHANGELOG.md` records what was taken from which original file and every
behavioural change.

## Install

Tested with CPython 3.14.7 + Tk 9.0 on macOS arm64 (2026-10-09). Python >= 3.10 is
declared; older interpreters are unverified. A Tk-enabled Python is required
(`python3 -c "import tkinter"` must work).

```sh
cd beta/gui
python3 -m venv .venv
.venv/bin/pip install -r requirements.txt       # pinned to the tested versions
# or, for development:  .venv/bin/pip install -e .[dev,packaging]
```

`pyusb` (optional raw-USB fallback) needs the libusb-1.0 system library
(`brew install libusb` / `apt install libusb-1.0-0`). Nothing else needs system packages.

## Run

```sh
.venv/bin/python -m aeris10_gui --demo            # simulator, no hardware
.venv/bin/python -m aeris10_gui                   # hardware mode: pick the STM32 CDC port, press Start
.venv/bin/python -m aeris10_gui --selftest        # hidden window, 3 simulated frames, exit 0 on success
.venv/bin/python -m aeris10_gui --port /dev/cu.usbmodemXXXX
.venv/bin/python -m aeris10_gui --demo --raw-ft601   # option A: raw RTL packets instead of bridge frames
```

In demo mode the simulator also answers `REG` commands from an in-memory model of
`radar_control_regs.v`, so the register panel works without hardware.

After `pip install -e .` the same is available as `aeris10-gui [--demo]`.

Per frame the simulator emits one **bridge frame** (`build_frame`, packed exactly like
`rd_map_packer.v`) plus a status string in the **firmware format**, all in one CDC byte
stream. With `--raw-ft601` it emits 2048 packets in the **RTL wire format** instead. The
GUI decodes both through the same parsers it would use for hardware.

## Test

```sh
.venv/bin/python -m pytest -q
```

72 tests: bridge frames (RTL testbench vector, a hardware source fed a synthetic
CDC stream that interleaves frames, status strings, GPS and REG replies), register commands
(codec, RTL register semantics, client <-> demo register file round trip), settings packet (byte-exact firmware vector, round trip, a model of the
firmware receiver proving unpadded framing is accepted and GUI_V5's 64-byte zero
padding is rejected), FPGA packet (word-level and byte-level vectors from the Verilog,
corruption of footer/redundant copies/detection byte, truncation, stream
resynchronisation), status text / GPS text / GPSB binary, CA-CFAR on synthetic scenes,
DBSCAN clustering, Kalman tracker, simulator -> parser -> assembler exactness,
pipeline target recovery, testbench CSV loading, and a headless Tk smoke test (skipped
if no display).

## Package

```sh
.venv/bin/pip install pyinstaller      # already in requirements.txt
./build_app.sh                         # PyInstaller --onedir -> dist/aeris10-gui/, then runs --demo --selftest
```

Result on the test machine: PyInstaller 6.22.3 on Python 3.14.7 built a 134 MB `--onedir`
bundle and `dist/aeris10-gui/aeris10-gui --demo --selftest` exited 0. If PyInstaller
fails on your interpreter, the fallback is simply `python -m aeris10_gui --demo` inside
the venv. Note: `aeris10_gui/__main__.py` uses a relative import, so PyInstaller is
pointed at `pyinstaller_launcher.py` instead.

## Mapping: original file -> beta module

| Original (`9_Firmware/9_3_GUI/`) | Lines | Beta module | Notes |
|---|---|---|---|
| `GUI_V5.py` `RadarSettings`, `RadarTarget`, `GPSData` dataclasses | 56-88 | `aeris10_gui/model.py` | defaults = firmware defaults |
| `GUI_V5.py` `STM32USBInterface._create_settings_packet` | 454-467 | `protocol/settings_packet.py` | layout re-derived from `RadarSettings.cpp`; padding made a flag (default off) |
| `GUI_V5.py` `STM32USBInterface` (pyusb bulk) | 307-477 | `io/usb_cdc.py` | pyserial CDC-ACM port is primary; pyusb fallback picks the CDC *data* interface |
| `GUI_V5.py` `FTDIInterface` (pyftdi FT2232H) | 479-549 | `io/ftdi_ft601.py` | replaced by an explicit `NotImplementedError` (no hardware) |
| `GUI_V5.py` `RadarProcessor.clustering` | 587-605 | `dsp/clustering.py` | DBSCAN, now actually called |
| `GUI_V5.py` `RadarProcessor.association/tracking` | 607-670 | `dsp/tracking.py` | filterpy Kalman, time injected |
| `GUI_V5.py` `USBPacketParser` (GPS text / GPSB) | 672-751 | `protocol/status_text.py` | 3-field firmware GPS text accepted; status string parser added |
| `GUI_V5.py` `RadarPacketParser` (A5C3 + CRC16) | 753-865 | `protocol/fpga_packet.py` | **replaced**: decodes the RTL format (0xAA ... 0x55, no CRC) |
| `GUI_V5.py` `RadarGUI` (dark theme, control row, notebook, imshow, Treeview, settings tab) | 867-1300 | `ui/main_window.py`, `ui/theme.py` | Google Maps HTML export dropped; PPI polar plot added; no threads |
| `GUI_V6_Demo.py` `SimulatedRadarProcessor` | 61-231 | `sim/simulator.py` | emits I/Q 64x32 + RTL packets + firmware status string |
| `GUI_V6_Demo.py` `animate()` timer loop | 718-748 | `ui/main_window.py` `_tick/step` | |
| `GUI_V4_2_CSV.py` CSV reader | 354-372 | `sim/replay.py` | csv module instead of pandas |
| `test_radar_data.csv` | -- | used by `tests/test_sim_pipeline.py` | read only |
| -- (none existed) | -- | `dsp/cfar.py` | new CA-CFAR 1-D/2-D |
| -- | -- | `processing.py` | frame assembly + pipeline (new) |
| -- | -- | `protocol/bridge_frame.py`, `protocol/register_cmd.py`, `protocol/register_map.py`, `sim/register_file.py`, `ui/register_panel.py` | host link option B + register access (new) |

## Protocol facts the beta relies on (with sources)

| Item | Source | Beta |
|---|---|---|
| Start flag `17 2E 9E ED` | `USBHandler.cpp:38` | `settings_packet.START_FLAG` |
| 82-byte `SET`+3x`>d`+`>I`+6x`>d`+`END`, big-endian | `RadarSettings.cpp:23-120` | `build_settings_packet`, frozen vector in tests |
| `SET` must be at buffer offset 0 after the flag | `USBHandler.cpp:70` | no zero padding by default (`pad_to_64=False`) |
| Firmware value limits | `RadarSettings.cpp:86-101` | `validate_settings` (UI refuses values the firmware would reject) |
| FPGA packet = 11 FT601 words, `0xAA`, 4 range words, 4 Doppler words, detection, `0x55` | `usb_data_interface.v:39-160` | `fpga_packet.encode_words/decode_packet` |
| `range_profile` = `{Q, I}` Doppler word; `doppler_real` = bits 15:0 | `radar_system_top.v:294-331`, `doppler_processor.v:244` | `encode_cell`, `check_top_level_consistency` |
| Emission order range-major, 64 x 32 cells | `doppler_processor.v:244-266`, `radar_receiver_final.v:291-293` | `processing.FrameAssembler` |
| Detection bit = `|I|+|Q| > 10000` | `radar_system_top.v:318` | simulator |
| Status string fields, `ChirpCount` last | `main.cpp:807-877` | `status_text.parse_status_line` |
| `GPS:%.8f,%.8f,%.2f\r\n` (UART3) and 30-byte `GPSB` (CDC) | `gps_handler.cpp:45-119` | `parse_gps_text`, `parse_gpsb` |

## Assumptions and known limitations

1. **A1 -- FT601 byte-lane order.** Bus words are mapped to the host byte stream
   little-endian (lane 0 = `DATA[7:0]` first); `be=01` -> 1 byte, `be=11` -> 4 bytes.
   The RTL declares a 2-bit `ft601_be` for a 32-bit bus (FT601 has 4 byte enables);
   this is an RTL defect to resolve at bring-up. Packet length 35 bytes follows from A1.
2. **No CRC in the RTL packet.** Integrity checking uses header, footer and the
   redundant shifted copies the RTL emits. The simulation-only `usb_packet_analyzer.v`
   expects a *different* layout from the writer; the beta follows the writer.
3. **No bin indices in the packet.** The host counts packets to place cells; any lost
   packet shifts the whole frame until the next resync. Needs a frame marker in the RTL.
4. **Range scaling UNVERIFIED**: cell `r` -> `r * max_distance / 64` m. The physical
   spacing of the 64 decimated range bins is not documented anywhere in the repository.
5. **Velocity scaling** uses the standard pulse-Doppler relation with `prf1` and
   `system_frequency`, natural FFT order (bins >= N/2 negative). Not confirmed against RTL.
6. **Azimuth angle** = `(Azimuth-1) * 360/50` degrees from `main.cpp:188-189`; the
   firmware has no angle table. `BeamPos` (elevation index) is shown as an index.
7. **Settings acknowledgement** does not exist in the protocol; the UI cannot confirm
   the firmware accepted the packet.
8. The status string from the firmware has no terminator; the parser uses the
   `ChirpCount:<n>|` field as end marker.
9. Google Maps export (placeholder API key in V4-V6) was dropped.
10. `filterpy` 1.4.5 (2018) runs on numpy 2.5.3 here; long-term maintenance risk.
11. Only CPython 3.14.7 (Tk 9.0, then 9.1) on macOS was exercised; Windows/Linux and older Pythons
    are unverified.
12. Register map = `radar_control_regs.v` (RTL 0x0002) = HOST_LINK_DESIGN.md section 7 (5-bit
    addresses, 16-bit registers, pattern and blind calibration). The demo register file only
    *simulates* calibration results (lock mask, windows, blind metric); real values come from
    `adc_capture_calib.v` on hardware.
13. **REG text protocol** matches the firmware implementation line for line, but neither side
    has been exercised on hardware. No request ID exists: the client keeps one command in
    flight and relies on timeout/retransmit.

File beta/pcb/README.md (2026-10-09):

# AERIS-10 — BETA PCB packages

**Status of everything in this directory: BETA.** KiCad 10.0.6 copies of the EAGLE → KiCad conversion in `engineering/PCB/`, brought to a routed / DRC-checked state by scripts and Freerouting 2.5.0, with proposed BOM part numbers and fabrication notes. **Not reviewed by the original designer. Not fabricated. Not a release.** The EAGLE originals in `4_Schematics and Boards Layout/` and the reference conversion in `engineering/PCB/` are untouched; no circuit connectivity (netlist) was changed on the four BETA boards. The only exception is the separate, explicitly labelled **Main Board rev. B proposal** in `MAIN_BOARD_REVB/` (FT601 host interface wired; netlist delta in `MAIN_BOARD_REVB/NETLIST_DELTA.csv`) — the EAGLE schematic must be updated by the designer to match it.

| Board | Dir | Unconnected before → after | DRC before → after | Outside outline before → after | Routing work | Remaining blockers |
|---|---|---|---|---|---|---|
| Main Board (10 L, 260×300) | `MAIN_BOARD/` | 15 → **0** | 912 → 1049 (0 real new; +polygon/thermal-pad items now visible, see README) | 11 → 6 (6 net-less 0201 resistors left, DNP) | 7 arc tails, 5-part filter cluster placed + hand-routed, 14 copper polygons given their net | no-net thermal-via pads of U69/U7 and 4 ambiguous BPF2 polygons (schematic/footprint level); FT601 unwired in the schematic |
| Power Supply (2 L, 280×300) | `POWER_SUPPLY/` | 308 → **89** | 163 → 328 | 132 → **0** | 132 parts placed by script, Freerouting ×2 (+1372 tracks, +171 vias), 29 bridges, 22 stitching items, B.Cu GND plane | 89 open connections (`UNROUTED.md`: pour-to-pour VIN/GND distribution, fragmented bottom plane); placement needs designer review |
| RF PA (4 L, 35×60) | `RF_PA/` | 1 → **0** | 67 → 18 | 0 → 0 | 1 GND strap, paddle polygon → GND, zone priorities; RF tracks untouched | 1 clearance 0.123 mm in the source (VIN_M stub) |
| Frequency Synthesizer (6 L, 100×100) | `FREQUENCY_SYNTHESIZER/` | 0 → **0** | 639 → 639 (capped; silk conflicts 147 → 103 measured) | 0 → 0 | copper untouched; 43 silk texts nudged; `DRC_DISPOSITION.md` | 7 courtyard overlaps to review; 0201 silk density |
| Main Board rev. B PROPOSAL (FT601 wired) | `MAIN_BOARD_REVB/` | 0 (rev. A) → 59 | 1049 → 1071 | — | **netlist change**: 64 nets, 20 parts (USB-C, ESD, crystal…); USB/power partly routed by Freerouting | 32-bit FIFO bus unrouted (U42 bank-35 balls have no escape-via room); EAGLE schematic not updated |

"DRC before" = `engineering/PCB/<BOARD>/reports/DRC_report.json`; "after" = `<BOARD>/exports/reports/DRC_report.json` (KiCad caps each violation type at 199 entries). Counts went *up* on the Main Board and Power Supply because the net-less copper polygons that previously hid behind one `shorting_items` entry each are now checked as real copper, and because newly placed/routed parts expose their footprint-level silk/pad issues — the per-board READMEs classify every type.

## Per-board contents

```
beta/pcb/<BOARD>/
├── <BOARD>.kicad_pcb, <BOARD>.kicad_pro   BETA board (open in KiCad 10)
├── README.md                              before/after table, change list, what remains, BETA statement
├── FAB_NOTES.md                           PCBWay stack-up / material / finish / impedance proposal (PROPOSED)
├── BOM_<BOARD>_beta.csv                   BOM with manufacturer, mpn, mpn_confidence, dnp, note
├── UNROUTED.md | DRC_DISPOSITION.md | POLYGON_NET_DISPOSITION.md   where applicable
├── *.json                                 logs of every scripted change (placement, routing merge, bridges, nudges)
├── *.dsn / *.ses / freerouting*.log       Freerouting input/output (Power Supply)
├── reports/                               working DRC reports
└── exports/                               Gerber, drill, PDF drawings, SVG, DXF, STEP, pick-and-place, IPC-2581,
                                           IPC-D-356, DRC, statistics, 3-D renders (tools/beta_export_package.sh)
```

## BOM confidence (lines / quantity)

| Board | HIGH (deviceset = MPN) | MEDIUM (standard passive from value+package) | LOW (guess / non-standard value / conflict) | EMPTY (no value in the source) |
|---|---|---|---|---|
| Main Board | 23 / 204 | 41 / 461 | 30 / 93 | 4 / 18 |
| Power Supply | 7 / 79 | 18 / 225 | 3 / 8 | 0 / 0 |
| RF PA | 5 / 6 | 6 / 19 | 0 / 0 | 0 / 0 |
| Frequency Synthesizer | 10 / 37 | 22 / 110 | 6 / 29 | 2 / 8 |

MPNs are proposals (`tools/beta_bom_mpn.py`): Murata GRM / Yageo RC / Murata LQP03 / TDK VLP families for passives, orderable IC codes for the device sets; voltage ratings, non-E-series values (e.g. 2.443 kΩ, 103 pF, 107.3 nH) and package/value conflicts (47 µF in 0201, NX3225 footprint with a 32.768 kHz value, 5 mΩ shunt with a 0.1 Ω part number) are flagged in the `note` column and must be resolved by the designer.

## Tooling and provenance

`tools/` — pcbnew/kicad-cli scripts (see `tools/README.md`), Freerouting 2.5.0 jar (OpenJDK 27). `CHANGELOG.md` — every change per board in order. All scripts are re-runnable; the sequence per board is documented in `tools/README.md`.

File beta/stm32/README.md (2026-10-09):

# AERIS-10 STM32F746ZGT7 firmware — BETA build tree

**Status: BETA = compiles and links with the ST HAL/USB stack. Not flashed. Not run on hardware. No
peripheral, RF or power-sequence behaviour has been observed.** Everything "hardware" in this tree is an
engineering decision recorded in `DECISIONS.md`, derived from the schematic-based tables in
`docs/STM32/STM32_PROJECT_RECONSTRUCTION.md`, `main.h`, `engineering/ELECTRICAL/power_distribution/power_rails.md`
and ST reference material in `cube/`.

The originals under `9_Firmware/9_1_Microcontroller/` are untouched; this directory holds edited copies.
Every difference is listed in `CHANGELOG.md` (file:line, reason, "defect fix" vs "hardware-truth decision").

## Layout
```
beta/stm32/
├── Core/Inc, Core/Src, Core/Startup   main.cpp/main.h + CubeMX glue (copied), startup_stm32f746xx.s (ST CMSIS template)
├── LIB/                               copy of 9_1_1_C_Cpp_Libraries (+ aeris_beam.*, _excluded/)
├── USB_DEVICE/App, USB_DEVICE/Target  hand-written CubeMX-equivalent USB CDC files
├── STM32F746ZGTx_FLASH.ld             ST Nucleo-F746ZG template (AXIM flash 1 MB @0x08000000, RAM 320 KB @0x20000000)
├── CMakeLists.txt, cmake/arm-none-eabi.cmake, build.sh, setup_cube.sh
├── cube/                              STM32CubeF7 sparse checkout (git-ignored; pinned commits in DECISIONS.md D-15)
├── tests/                             host-side unit tests (run_tests.sh)
├── build/ (ignored), build_out/       artefacts: aeris10_fw.elf/.hex/.bin/.map
├── logs/                              build, size, warning, include-check and test logs
└── CHANGELOG.md, DECISIONS.md, CUBEMX_SETTINGS.md, README.md
```

## 1. Toolchain
- **Arm GNU Toolchain 14.2.Rel1** (`arm-none-eabi-gcc 14.2.1 20241119`). On this machine it was installed from the
  Arm tarball (`arm-gnu-toolchain-14.2.rel1-darwin-arm64-arm-none-eabi.tar.xz`) extracted to
  `~/opt/arm-gnu-toolchain` and symlinked into `/opt/homebrew/bin/arm-none-eabi-*`. The Homebrew cask
  `gcc-arm-embedded` **failed** (its installer needs sudo). Any 12.x–14.x arm-none-eabi GCC should work; the
  CMake toolchain file searches `/opt/homebrew/bin`, `~/opt/arm-gnu-toolchain/bin` and
  `/Applications/ArmGNUToolchain/*/arm-none-eabi/bin`, or pass `-DTOOLCHAIN_PREFIX=/path/arm-none-eabi-`.
- CMake ≥ 3.20 (4.4.3 used), Ninja (optional), Python 3 for the checks, a host C/C++ compiler for the tests.

## 2. STM32CubeF7 (HAL, CMSIS, USB Device Library)
```sh
bash beta/stm32/setup_cube.sh          # sparse clone at the pinned commits, verifies with tools/stm32_check_cube_package.sh
```
Expected: `Package: beta/stm32/cube — missing 0 of 34 required files` (exit 0). Components: HAL 1.3.3
(`e860c4ff`), cmsis_device_f7 v1.2.10 (`2352e888`), USB Device Library (`2a0a3521`), STM32CubeF7 `79165e26`.

## 3. Build
```sh
bash beta/stm32/build.sh               # Debug (-Og -g3); or: bash beta/stm32/build.sh Release
```
`build.sh` configures CMake, builds, prints `arm-none-eabi-size`, writes `logs/build_full.log`,
`logs/build_warnings.log`, `logs/build_errors.log`, `logs/size.log` and copies
`aeris10_fw.elf/.hex/.bin/.map` to `build_out/`. **Exit code 0 only on a clean link.**

### Result on 2026-10-09 (clean build, Debug; includes host bridge v2 + VM tables)
```
Memory region         Used Size  Region Size  %age Used
             RAM:       17480 B       320 KB      5.33%
           FLASH:       93276 B         1 MB      8.90%
   text    data     bss     dec     hex filename
  92480     788   16704  109972   1ad94 aeris10_fw.elf
```
0 errors. 5 unique warnings, all pre-existing code (`logs/build_warnings.log`): `main.cpp` unused `settings`
reference (the original commented-out block), `BMP180.cpp` misleading indentation ×3, `TinyGPS++.cpp` implicit
fall-through. Third-party HAL/USB sources are compiled with `-w`.

Include audit: `python3 tools/check_stm32_includes.py --root <copy>` on `Core/LIB/USB_DEVICE`
(`logs/check_stm32_includes_beta.log`): **0 case mismatches** (was 6); the 11 remaining UNKNOWN headers are
all in `iio*.c` / `iiod.c`, which are not built; HAL/CMSIS/USB headers are reported "not in repository" because
the script does not know about `cube/`. (The script hard-codes the `9_Firmware/9_1_Microcontroller` sub-path,
so it was run against a scratch copy laid out that way.)

## 4. Host unit tests
```sh
bash beta/stm32/tests/run_tests.sh     # needs cc/c++ + python3 only
```
Result 2026-10-09: **6/6 PASSED** (`logs/tests_*.log`)
| Test | What it checks |
|---|---|
| `test_settings_parser.cpp` | real `USBHandler.cpp` + `RadarSettings.cpp`: start flag `[23,46,158,237]`, 82-byte big-endian `SET…END` packet, unpadded and GUI-style 64-byte zero-padded framing, flag+settings in one packet, `SET` straddling a packet boundary, byte-at-a-time, short packets, invalid-value rejection and recovery, big-endian decode against a hand-encoded constant, `REG` text commands coexisting with the binary path (10 cases) |
| `test_beam_matrix.c` | `aeris_beam.c` (verbatim arithmetic of `initializeBeamMatrices`/`degreesTo7BitPhase`): 7-bit phase conversion, reference element, range, hand-computed samples, mirror symmetry, linearity |
| `test_ad9523_regs.c` | real `ad9523.c` + `no_os_spi.c` against a mock SPI register file: full `ad9523_setup()` path, channel distribution registers for OUT0/1/4/5/6/7/8/9/10/11 (dividers 12/9/36/180/60/30, LVDS/CMOS modes), unused outputs powered down, IO_UPDATE/SYNC/status. **This test found defect C8** (see below) |
| `test_adar_vm_tables.c` | ADAR1000 VM tables vs data sheet Tables 10-13: 128 entries, bits 7:6 clear, quadrant signs, spot rows 0/45/90/180/230.625/270/312.1875/357.1875°, strictly monotonic decoded phase (max error 3.12°), `degreesTo7BitPhase` → table round trip |
| `test_host_bridge_cmds.c` | bridge v2 byte sequences with a mock SPI (0x02 + ack 0xA2 / no ack / 0xEE / transfer error, 0x03 LE decode, 0x04 status fields), ASCII `REG W/R` parser (hex/decimal, errors) and reply formatting |
| `check_i2c_timing.py` | decodes TIMINGR: original `0x00808CD2`@36 MHz ≈ 100 kHz; beta `0x10916EA0`@54 MHz ≈ 97.6 kHz, I2C Standard-mode minima met |

Not host-testable as-is (need HAL types): `stm32_spi_prescaler_for()`, the USB glue, power sequencing.

## 5. Defects fixed (details and line numbers in `CHANGELOG.md`)
| ID | Defect in the original | Fix |
|---|---|---|
| C2 | `adf4382a_manager.h` drove PG0..PG9 (PA/clock power enables) as ADF4382 CE/CS/lock-detect | macros alias `main.h` PG6..PG15; CE parameter widened to 16 bit |
| C3 | ADF4382 `platform_ops = NULL` → `no_os_spi_init` returns `-EINVAL` → `Error_Handler()` | `&stm32_spi_ops` |
| C4 | USB RX callback never bound; start-flag wait loop could never exit | `usbd_cdc_if.c:CDC_Receive_FS` → `AERIS_USB_OnReceive()` → `USBHandler` |
| C5 | GUI zero-padding after the start flag landed in the settings buffer; `"SET"` never at offset 0 | parser synchronises on `SET`, handles padded/unpadded/split frames (tested) |
| C6 | `GPS_Init()` never called → `GPS_SendBinaryToGUI()` returned early | `GPS_Init(&huart3)` |
| C7 | SPI chip selects driven low permanently and never toggled; SPI clock PCLK/2 regardless of the 10 MHz request | CS index table + toggling in `stm32_spi.c`, CS parked high, prescaler from `max_speed_hz` |
| C8 | `ad9523_init()` called after `pdata` was configured → whole AD9523 channel/PLL configuration reset to defaults | call removed |
| C9 | `ad9523_setup()` executed twice (first device leaked) | single call after reset release |
| C10 | ADAR1000 phase/gain setters used `(channel & 3)` with 1-based channels → element pattern rotated by one channel per device | `((channel - 1) & 3)` |
| — | `VM_I/VM_Q/VM_GAIN` empty → every phase write was I = Q = 0 | tables from the data sheet (D-19) |
| U10 | IDQ servo for DAC2 read ADC2 into `adc1_readings` and computed from stale data | `adc2_readings` |
| — | `printf()` → weak `__io_putchar` undefined → call to address 0 | retargeted to USART3 |
| — | `USBHandler::processStartFlag` unsigned underflow on packets < 4 bytes | guarded |
| — | `stm32_spi_write_and_read` prototype mismatch (`uint32_t` vs `uint16_t`), hard error on GCC 14 | fixed |
| — | `LIB/errno.h` `#include_next` self-inclusion → `EINVAL` undefined | shim excluded |
| — | `.H` include-case mismatches | files renamed `.h` |

## 6. Hardware-truth decisions (full text in `DECISIONS.md`)
D-01 8 MHz HSE → PLL M8/N432/P2/Q9, 216 MHz, over-drive, 7 WS · D-02 APB1 54 / APB2 108 MHz, TIM1 PSC 215 ·
D-03 I2C TIMINGR 0x10916EA0 (computed, not CubeMX) · D-04 ADF4382 pins per schematic · D-05 CS index/idle-high ·
D-06 SPI 6.75 MHz (≤10 MHz) · D-07 OTG_FS device-only PA11/PA12, no VBUS sensing · D-08 USB IRQ priority 0 ·
D-09 VID/PID 0x0483:0x5740 PLACEHOLDER · D-10 CDC RX hook · D-11 PA sequencing: `+5V5_PA` before VG DAC
programming, VG before VD, VD removed first on power-down (delays are estimates) · D-12 AD9523 single setup ·
D-13 compiler flags = CubeIDE defaults (assumed) · D-14 excluded sources · D-15 pinned Cube commits · D-16 `GPS_Init` · D-17 REG commands executed from the main loop · D-18 bridge v2 framing assumptions · D-19 VM tables / VM_GAIN = 0.

## 6a. Beam steering and host register access (added 2026-10-09)
- **Beam steering is now functional in software**: `ADAR1000_Manager` VM tables come from the ADAR1000 data sheet
  (Rev. B Tables 10-13, `LIB/adar1000_vm_tables.h`), and the channel-offset bug C10 is fixed. Phase words for the 31
  beam positions go through `degreesTo7BitPhase` → table → CHx_RX/TX_PHASE_I/Q. **Not verified on hardware**: no
  phase/gain measurement, no array calibration.
- **Bridge command set v2** (`Core/Src/host_bridge*.c`): `HostBridge_WriteReg/ReadReg/Status` and the CDC text
  commands `REG W <addr> <value>` / `REG R <addr>` → `REG <addr> <value>\r\n` or `REG ERR\r\n` in the status
  stream (D-17, D-18). The FPGA side of 0x02..0x04 is not implemented in `beta/fpga` yet.

## 7. Unresolved / remaining work
1. **Regenerate the CubeMX project** from `CUBEMX_SETTINGS.md` and diff the generated `usbd_conf.c`, `usbd_desc.c`,
   `usbd_cdc_if.c`, `usb_device.c`, startup and linker script against the hand-written files; let CubeMX recompute
   the I2C TIMINGR (D-03) and confirm the clock tree (D-01/D-02).
2. **Hardware bring-up** per `engineering/ASSEMBLY/ASSEMBLY_SEQUENCE.md` §B: flash via SWD
   (`STM32_Programmer_CLI -c port=SWD -w beta/stm32/build_out/aeris10_fw.elf -v -rst`), verify HSE/PLL lock and
   216 MHz (SWO/USART3 output at 115200 proves the clock), CDC enumeration (placeholder VID/PID), start flag +
   settings acceptance, enable-rail order on a scope (power_rails.md §3 + D-11), AD9523 lock, ADF4382 lock, SPI
   waveforms (CS, ≤10 MHz).
3. ADAR1000 phase accuracy on hardware (data-sheet tables realise the nominal phase within ~3°; array calibration
   needed); FPGA implementation of bridge commands 0x02..0x04 and an end-to-end `REG` test.
4. ADAR1000 SCLK limit and FPGA level-shifter bandwidth (SPI1 clock, D-06); AD9523/ADF4382 register-level
   correctness; ADF4382 `DELADJ` "PWM" is a stub (`adf4382a_manager.c:433-460`).
5. VBUS wiring to PA9 (D-07); production VID/PID (D-09); USB interrupt priority policy (D-08).
6. `main.cpp` logic not touched: 180 s OCXO wait at boot; `last_check` reused for the temperature timer
   (`main.cpp:1774` updates `last_check` instead of `last_check1`); `getSystemStatusForGUI()` reports raw ADC
   codes as temperatures (no 0.64705 scale); health check thresholds; the IDQ servo exit conditions.
7. Cache (I/D) stays disabled, MPU background region as generated — review for 216 MHz performance needs.
8. PA drain 22 V source/switch and stepper supply are not in CAD (K4 — hardware design item).
9. Static analysis (cppcheck) and `-fstack-usage` review (`build/**/*.su` are generated) not yet done.

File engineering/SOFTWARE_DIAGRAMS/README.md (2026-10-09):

# AERIS-10 - Editable Software Architecture Diagrams

Project AERIS-10 | Revision A | Date 2026-10-09 | Author: reconstruction team (evidence-based; nothing drawn that is not in the repository)

All diagrams are Graphviz DOT sources (edit the `.dot`, re-render with `dot -Tsvg|-Tpdf|-Tpng -Gdpi=150`). Two of them are generated by scripts in `tools/` and must not be edited by hand; re-run the script instead. Every graph carries a title block (project, drawing ID, revision, date, status, sources) and a legend node with the file:line evidence.

Status vocabulary: VERIFIED (checked against executed tool output or hardware), SOURCE-DERIVED (drawn 1:1 from repository source text), PARTIAL (source-derived but the depicted system is incomplete in the repository), CONCEPTUAL (intent only), BLOCKED - MISSING DATA (cannot be drawn from repository evidence).

| ID | Title | Source evidence | Native file | Exports | Status |
|---|---|---|---|---|---|
| SD-01 | FPGA RTL module hierarchy (auto-generated) | 26 files `9_Firmware/9_2_FPGA/*.v` parsed by `tools/gen_verilog_hierarchy.py` (28 module definitions, 39 instantiations, 5 missing: `ad9484_lvds_to_cmos_400m`, `matched_filter_processing_chain`, `range_bin_decimator`, `xfft_32`, `FFT_enhanced`) | `FPGA/fpga_module_hierarchy.dot` + `FPGA/fpga_module_hierarchy.md` | `.svg .pdf .png` | SOURCE-DERIVED |
| SD-02 | FPGA signal-processing pipeline (ADC -> DDC -> CIC -> FIR -> matched filter -> Doppler -> packetizer; TX chirp -> DAC) with clock domains | `radar_system_top.v`, `radar_receiver_final.v`, `radar_transmitter.v`, `ddc_400m.v`, `usb_data_interface.v`, `lvds_to_cmos_400m.v`, `matched_filter_multi_segment.v`, `doppler_processor.v`, `reconstructed/PIN_MAP_FROM_SCHEMATIC.md` (file:line in every box) | `FPGA/fpga_data_pipeline.dot` | `.svg .pdf .png` | PARTIAL - 5 missing modules, 400 MHz capture not implemented, CFAR/range-profile placeholders, FT601 unwired |
| SD-03 | STM32F746 firmware layered architecture (application -> drivers -> HAL/CubeMX -> peripherals -> external devices) | `9_1_3_C_Cpp_Code/main.cpp`, `main.h`, `9_1_1_C_Cpp_Libraries/*` (includes and call sites cited on every edge), `docs/STM32/STM32_PROJECT_RECONSTRUCTION.md` | `STM32/stm32_firmware_architecture.dot` + `STM32/stm32_architecture.md` | `.svg .pdf .png` | PARTIAL - HAL, CMSIS, startup, linker, USB middleware absent from repository |
| SD-04 | STM32 USB CDC communication flow (GUI -> CDC -> usbd_cdc_if -> USBHandler -> settings) with defects C4/C5/C6 | `main.cpp:128-132, 328-339, 1534-1555, 1692`; `USBHandler.cpp:1-93`; `RadarSettings.h:12`; `gps_handler.cpp:65-119`; `GUI_V5.py:307-477` | `STM32/stm32_usb_cdc_flow.dot` | `.svg .pdf .png` | PARTIAL - `usbd_cdc_if.c` missing; RX callback never bound (static finding, bench-unverified) |
| SD-05 | Python GUI modules, imports and definitions (auto-generated) | 9 files `9_Firmware/9_3_GUI/*.py` parsed with `ast` by `tools/gen_python_module_graph.py`; `GUI_V1.py` shown as SYNTAX ERROR | `PYTHON/python_gui_modules.dot` + `PYTHON/python_gui_modules.md` | `.svg .pdf .png` | SOURCE-DERIVED |
| SD-06 | Python GUI runtime architecture: `GUI_V5.py` (threads, USB/FTDI readers, packet parsers, processing, matplotlib TkAgg) and `GUI_V6_Demo.py` (offline simulator) | `GUI_V5.py` and `GUI_V6_Demo.py` class/method definitions and call sites (line numbers in every box); `docs/GUI/DEPENDENCIES.md` | `PYTHON/python_gui_architecture.dot` | `.svg .pdf .png` | SOURCE-DERIVED (no GUI was executed) |
| SD-07 | End-to-end data flow: antenna -> RF -> ADC -> FPGA -> host, and control path GUI -> STM32 -> SPI/I2C -> AD9523/ADF4382/ADAR1000 -> FPGA DIG_0..4 | `docs/SYSTEM/BLOCK_DIAGRAM.md`, `docs/FPGA/FPGA_PROJECT_RECONSTRUCTION.md`, `docs/STM32/STM32_PROJECT_RECONSTRUCTION.md`, `docs/GUI/DEPENDENCIES.md`, `PIN_MAP_FROM_SCHEMATIC.md`, `main.cpp`, `radar_system_top.v`, `GUI_V5.py` | `DATA_FLOW/end_to_end_data_flow.dot` | `.svg .pdf .png` | PARTIAL - the FPGA-to-host radar-data path is BLOCKED - MISSING DATA (FT601 has no nets; no GUI decodes the RTL packet); antenna, LO mapping and harness unspecified |

## Edge / box conventions

- SD-01: solid box = module defined in repo; dashed red = instantiated without a definition; grey = Xilinx UNISIM primitive; dotted outline = defined but never instantiated. Edge label = instance name @line.
- SD-02 / SD-03 / SD-04 / SD-06: blue = present in source; orange = present but with a documented defect or source-commented placeholder; red dashed = absent from repository; grey dotted = defined/imported but not used (or UNVERIFIED).
- SD-07: solid = confirmed by a schematic net and a firmware/RTL reference; dashed = unverified (single source, anonymous net, inferred mapping, or wiring confirmed but driver/RTL broken); dotted red = missing specification / no hardware path.

## Regeneration

```sh
# from the repository root
python3 tools/gen_verilog_hierarchy.py  --rtl 9_Firmware/9_2_FPGA --out engineering/SOFTWARE_DIAGRAMS/FPGA     # exit 1 = missing module definitions exist (expected today)
python3 tools/gen_python_module_graph.py --src 9_Firmware/9_3_GUI  --out engineering/SOFTWARE_DIAGRAMS/PYTHON   # exit 1 = a file has a SyntaxError (GUI_V1.py, expected today)
for d in engineering/SOFTWARE_DIAGRAMS/*/*.dot; do for f in svg pdf png; do dot -T$f -Gdpi=150 "$d" -o "${d%.dot}.$f"; done; done
```

Tool versions used for the committed exports: Graphviz `dot` 16.1.0 (`/opt/homebrew/bin/dot`), Python 3.14.7. Both scripts are standard-library only, non-destructive, and return 2 on usage/I-O errors.

## What these diagrams do not claim

They document the software **as committed**. They do not establish that any subsystem compiles, synthesises, enumerates, or functions: the FPGA tree has 5 missing modules and no project file, the STM32 tree lacks the HAL/USB stack, and no GUI has been launched. Where a connection is shown dashed or dotted, the repository does not contain enough evidence to call it verified; the legend of each graph lists exactly what was and was not checked.

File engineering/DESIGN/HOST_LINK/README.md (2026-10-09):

# DSN-LINK-01 — FPGA → host data path (PROPOSED DESIGN; option B implemented as BETA)

| File | Content | Verified by |
|---|---|---|
| `HOST_LINK_DESIGN.md` | problem, data-rate budget, options A/B/C, decisions D-16…D-19, pin plans, frame format | — |
| `ft601_pin_assignment.csv`, `ft601_bank35.xdc`, `ft601_added_parts_BOM.csv` | option A: FT601 on the 50 free bank-35 pins (CLK on MRCC C4), constraint fragment, parts to add for Main Board rev. B | pins cross-checked against the EAGLE netlist (no nets on those pads) |
| `option_b_signal_map.csv` | option B: existing nets DIG_5/6/7 + SPI1 ↔ FPGA pads | schematic netlist |
| `rtl/rd_map_packer.v`, `rtl/host_bridge_spi.v` | FPGA frame builder + SPI slave bridge (Verilog-2001) | `rtl/run_tb.sh` → `PASS tb_host_bridge` (iverilog); verilator `-Wall` clean except width warnings |
| `rtl/tb_host_bridge.v` | self-checking testbench; dumps `tb_frame.hex` used by the GUI tests | — |
| `stm32/host_bridge.c/.h` | STM32 driver (EXTI + SPI1 + CDC forward); integrated into `beta/stm32` | `beta/stm32/build.sh` exit 0 |
| `gui/bridge_frame.py` | reference parser; integrated into `beta/gui/aeris10_gui/protocol/` | `pytest tests/test_bridge_frame.py` 9 passed, on the RTL vector |

Not done: integration of the packer into `beta/fpga` (the FPGA beta agent was still working; hook it between `doppler_processor` and the existing `usb_data_interface`, and gate the ADAR1000 SPI pass-through with `bridge_active`), `ui/sources.py` hardware source switch to the bridge frames, bench test of SPI timing and CDC throughput, Main Board rev. B for option A.

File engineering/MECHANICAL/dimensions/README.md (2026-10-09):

# PCB dimensions summary (generated 2026-10-09)

| Board | Outline W × H (mm) | Holes/mounting pads | Bare-board mass ESTIMATE (g, 1.6 mm assumed) | Document |
|---|---|---|---|---|
| Main Board | 260.00 × 300.00 | 10 | ≈ 231 | `MAIN_BOARD_dimensions.md` |
| Power Supply Board | 280.00 × 300.00 | 8 | ≈ 249 | `POWER_SUPPLY_dimensions.md` |
| Frequency Synthesizer | 100.00 × 100.00 | 4 | ≈ 30 | `FREQUENCY_SYNTHESIZER_dimensions.md` |
| RF Power Amplifier | 35.00 × 60.00 | 7 | ≈ 6 | `RF_PA_dimensions.md` |

Thickness is not recorded in any source file; masses are estimates for planning only (see each document §3). Component heights, enclosure, antenna and pedestal geometry: BLOCKED — MISSING DATA (`../../VALIDATION/UNRESOLVED_GEOMETRY.md`).

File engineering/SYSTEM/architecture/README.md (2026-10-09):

# AERIS-10 — System-level engineering diagrams (index)

Revision A · 2026-10-09. All diagrams are **editable Graphviz DOT** (plus one Mermaid twin) and were rendered with `dot` (Graphviz 16.1.0) to SVG/PDF/PNG (`-Gdpi=150`). Every box and edge is traceable to a repository file; nothing was taken from memory of the parts or from the README alone unless marked "documented only". Re-render with:

```sh
cd engineering/SYSTEM/block_diagrams      && dot -Tsvg system_block_diagram.dot -o system_block_diagram.svg && dot -Tpdf system_block_diagram.dot -o system_block_diagram.pdf && dot -Tpng -Gdpi=150 system_block_diagram.dot -o system_block_diagram.png
cd engineering/SYSTEM/interfaces          && dot -Tsvg hardware_interconnection.dot -o hardware_interconnection.svg && dot -Tpdf hardware_interconnection.dot -o hardware_interconnection.pdf && dot -Tpng -Gdpi=150 hardware_interconnection.dot -o hardware_interconnection.png
cd engineering/SYSTEM/data_flow           && dot -Tsvg signal_and_data_flow.dot -o signal_and_data_flow.svg && dot -Tpdf signal_and_data_flow.dot -o signal_and_data_flow.pdf && dot -Tpng -Gdpi=150 signal_and_data_flow.dot -o signal_and_data_flow.png
cd engineering/ELECTRICAL/power_distribution && dot -Tsvg power_distribution.dot -o power_distribution.svg && dot -Tpdf power_distribution.dot -o power_distribution.pdf && dot -Tpng -Gdpi=150 power_distribution.dot -o power_distribution.png
```

Status vocabulary: **VERIFIED** = every element checked against CAD nets and consistent with firmware; **SOURCE-DERIVED** = built from CAD/firmware/docs, some elements unverifiable (listed); **PARTIAL** = significant parts missing from the sources; **CONCEPTUAL** = documented intent only; **BLOCKED — MISSING DATA** = cannot be drawn from the repository.

## Diagram index

| ID | Title | Native file | Exports | Source evidence | Status | Open conflicts referenced |
|---|---|---|---|---|---|---|
| SYS-01 | System block diagram — all subsystems (host, GUI, Power Board, Synth Board, Main Board digital/converter/RF/PA-bias groups, RF PA board, antenna, peripherals) with status legend | `engineering/SYSTEM/block_diagrams/system_block_diagram.dot`; Mermaid twin `system_block_diagram.mmd` | `.svg`, `.pdf`, `.png` | `RADAR_Main_Board.sch` (parts U1, U2, U3, U4, U5, U6, U8, U13, U16, U42, U$1, U$2, U$3, ADAR1_..4_, ADTR1107_1..16, RF_SW_1..16, U7/U69, U11/U73..U87, U10/U88/U89, connectors), `PowerBoard.sch` (U1..U34, X1..X35, SV1), `Clocks_Freq_Synth_board.sch` (IC1, U1..U10, X4..X6, J1..J13, JP1, JP2, X10..X15), `RF_PA.sch` (U$1, J1, J2, X2, X3, `22V`), `main.h` / `main.cpp` (pins, AD9523 channels), `adf4382a_manager.h:32-34`, `radar_system_top.v`, `Power Management V6.xlsx`, `RADAR_V6.drawio` (original block names: FPGA XC7A50T-2FTG256, AD9708, ADF4382 TX/RX, LTC5552 ×2, LPF/BPF, AD9484, EP4RKU+, ADAR1000 ×4, ADTR1107, M3SWA2-34DR+, FT601, STM32F746ZGT7, AD8352, OCXO ECOC-2522-10.000, AD9523, XO CCHD-957-100, VCXO CVHD-950-100.000, MTX2-143+, ATS1005-3DB, QPA2862 ×4 — note drawio writes "QPA2862", CAD has QPA2962_B), `README.md`, `docs/SYSTEM/BLOCK_DIAGRAM.md` | SOURCE-DERIVED (antenna, host PC, 22 V supply, off-board modules are CONCEPTUAL) | K1 (FPGA part), K2 (HSE), K3 (host link / FT601), K4 (22 V PA supply), K6 (ADF4382 pins), K7 (oscillators), K8 (antenna) |
| SYS-02 | Hardware interconnection diagram — one node per board/module, one edge per connector/cable, with connector IDs, pin numbers (where the symbol has them), signal names and interface standard; companion table `interconnection_table.md` (every edge, CONFIRMED / UNVERIFIED / MISSING SPEC) | `engineering/SYSTEM/interfaces/hardware_interconnection.dot`; `engineering/SYSTEM/interfaces/interconnection_table.md` | `.svg`, `.pdf`, `.png` | Connector nets of all four schematics (extracted from the EAGLE XML `<pinref>`s — same method as `tools/extract_eagle_netlist.py`), Synth/PA `.brd` silkscreen text nearest to each connector (SMA function names `LO TX`, `LO RX`, `ADC`, `FPGA=ADC`, `DAC`, `FPGA=DAC`, `FPGA SYS. CLOCK`, `TEST`, `RFIN`, `RFOUT`, `VG`, `CURRENT SENSOR`), `main.h:62-165` (MCU pin per header signal), `docs/SYSTEM/BLOCK_DIAGRAM.md` §2 (corrected: SV1 carries 15 not 16 enables; the "17th SMA pair" J22/J23 are the LO inputs; Synth power connectors X10..X15 resolved through L9..L13) | SOURCE-DERIVED — cables themselves (type, length, gauge, pin order of Molex `S` pads, SMA pair → PA RFIN/RFOUT side, PA instance → Main connector) are UNVERIFIED | K3, K4, K6, K8 |
| SYS-03 | Signal and data flow — reference/clock tree (AD9523 outputs with firmware-programmed frequencies), TX chain (FPGA LUT → AD9708 → LC → LTC5552 → BPF → switch → combiner → ADAR1000 → ADTR1107 → switch → SMA → PA → antenna), RX chain (… → LTC5552 → LC → AD8352 ×2 → AD9484 → FPGA DSP → FT601/USB), control paths; three edge styles (solid confirmed / dashed unverified / dotted-red missing spec) | `engineering/SYSTEM/data_flow/signal_and_data_flow.dot` | `.svg`, `.pdf`, `.png` | `RADAR_Main_Board.sch` nets traced through passives (C272/C274 LO coupling, DAC LC network L22/L25/L26/L27/C127/C59, IF network C268…L9, ADC input R13/R1/C3, 1 pF switch couplings, series resistors on LVDS), `Clocks_Freq_Synth_board.sch` (OUT0/1 → ADF4382 REF via C11/C12/R12, C68/C69/R1; OUT8/9 → SYNC; OUT6 → R39/C15 → J7; OUT10/11 → R40/C17, R41/C19 → J5/J6; balun/attenuator chains), `main.cpp:190` (IF 120 MHz), `main.cpp:933-1072` (VCXO 100 MHz, PLL2 3.6 GHz, dividers /12 /9 /36 /180 /60 /30), `adf4382a_manager.h:32-34` (REF 300 MHz, TX 10.5 GHz, RX 10.38 GHz), `radar_system_top.v:20-114`, `docs/SYSTEM/BLOCK_DIAGRAM.md` §3 | SOURCE-DERIVED — frequencies are firmware intent, not measurements; BPF part numbers, sideband selection, antenna path and FT601 path MISSING | K1, K3, K5 (packet format), K7, K8 |
| SYS-04 (ELEC-PWR-01) | Power distribution — every Power Board rail with regulator, feedback divider, source rail, enable net/MCU pin, firmware sequence step, output connector → destination connector → consumer on Main/Synth/PA boards; companion register `power_rails.md` | `engineering/ELECTRICAL/power_distribution/power_distribution.dot`; `engineering/ELECTRICAL/power_distribution/power_rails.md` | `.svg`, `.pdf`, `.png` | `PowerBoard.sch` (U1..U34 pin nets, R1..R56 dividers, X1..X35, SV1), `RADAR_Main_Board.sch` (rail connectors and consumer pins), `Clocks_Freq_Synth_board.sch` (X10..X15 via L9..L13), `RF_PA.sch` (`22V`, R10, X2, X3), `main.h:94-123`, `main.cpp:1237-1276, 1483-1489, 1560-1601, 372-409, 2239-2247`, `ADAR1000_Manager.cpp:45-55`, `Power Management V6.xlsx` rows 2-64 | SOURCE-DERIVED — output voltages from net names (dividers listed, not recomputed); currents UNKNOWN; findings: 5 enables never asserted in firmware, `+1V8_CLOCK` single output needed twice, U30 fed from VIN, 8 spare outputs | K4; new findings recorded in `power_rails.md` §4 |

## What was verified against the schematics (method)

The four `.sch` files were parsed with Python `xml.etree` (read-only). For each board, `<part>` (name, library, deviceset, device, value) and `<net>/<segment>/<pinref>` (part, gate, pin, net) were tabulated; anonymous nets (`N$…`) were followed through two-pin passives (C, R, L, ferrites) until a named net or an IC pin was reached. The `.brd` files were parsed for `<element>` coordinates and layer-21/51 `<text>` items to attach silkscreen labels to the nearest connector (Synth and PA boards only — the Main Board `.brd` contains no free silkscreen text). Firmware pin macros were read from `main.h`; the enable order and AD9523/ADF4382 settings from `main.cpp`, `ADAR1000_Manager.cpp` and `adf4382a_manager.{h,c}`. The xlsx was unzipped and `xl/worksheets/sheet1.xml` + `sharedStrings.xml` parsed with `xml.etree`. The drawio file was parsed for `mxCell` values to list the original author's block names.

Corrections to `docs/SYSTEM/BLOCK_DIAGRAM.md` established here: (1) SV1 has 15 enable lines; (2) Synth power connectors X10..X15 = `+3V3_XO`, `+3V3_CLOCK`, `+1V8_CLOCK`, `+3V3_LO_1`, `+3V3_LO_2`, `+5V0_LO`; (3) the "17th SMA pair" J22/J23 are the RX-LO and TX-LO inputs of U13/U5 (18 pF coupled); (4) Synth LO SMAs: J10 = `LO TX` (U1 RFOUT1 path), J11 = `LO RX` (U6 RFOUT1 path), J1 = `AUX. LO TX`, J12 = second RX path; (5) `+5V0_ADAR`, `+5V0_ADTR`, `+3V3_SW` outputs (X13, X26, X29) and `+5V0_1..5` (X2, X9, X17, X25, X28) are intermediate rails with no off-board consumer; (6) the PA gate-bias cables are X_1..X_16 (VG_n), the 3-pin X3/X38..X52 carry the INA241 shunt-sense pair.

## Items left UNVERIFIED (and why)

| Item | Reason |
|---|---|
| Pin order of all Molex 22-23-2021/2031 connections | EAGLE symbol names every pad `S`; order not recoverable from the schematic |
| Which SMA of each element pair (e.g. J27/J26) goes to PA `RFIN` vs returns from `RFOUT`, and PA-board-instance → Main-connector assignment | no silkscreen text on the Main Board `.brd`, no cabling document |
| Synth J12 function (`AUX. LO RX`) | silkscreen text not adjacent; assigned by elimination |
| Oscillator identities (X4 100 MHz OCXO vs net `10MHZ_OUT`; X5/X6 50 MHz VCXO vs nets `100MHZ_OUT`/`VCXO_OUT` and firmware 100 MHz) | contradictory sources (K7) |
| `+1V8_CLOCK` distribution to both Main X17 and Synth X12 from the single Power output X10 | no cable/Y-splice in CAD |
| 22 V PA drain source and the switch driven by `EN/DIS_RFPA_VDD` | absent from all CAD (K4) |
| GPS / IMU / BMP180 / stepper-driver / relay module pinouts and supplies | modules named only in the xlsx; no module schematics |
| JP3 pin → FPGA TAP signal assignment | nets `N$32..N$36` not traced here (see `docs/FPGA/`) |
| Host-link packet format, USB 3.0 path | no FT601 nets (K3); RTL/GUI packet formats differ (K5) |
| DIG_0..7 bit meaning | inferred from firmware/RTL names only (`docs/SYSTEM/BLOCK_DIAGRAM.md` §3) |
| Output voltages, regulator current capability, VIN total current | dividers listed, no datasheet for TPS562208 in repo; no budget sum in xlsx |
| Cable types, lengths, coax grade, wire gauge | not in any repository file |
| Antenna feed network, element-to-port mapping, waveguide transition | no antenna CAD (K8) |

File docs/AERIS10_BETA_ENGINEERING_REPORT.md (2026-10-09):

# AERIS-10 — BETA Engineering Report (consolidated)

Version 0.9 (draft, 2026-10-09) · companion to `AERIS10_ENGINEERING_BUILD_MANUAL.md` (v1.3 Part XIII) · repository `https://github.com/herasymyuks/PLFM_RADAR-aeris` (branch `main`).

This report consolidates everything that was built, simulated and calculated for the missing elements of AERIS-10 during the reconstruction and BETA phases, with the verification actually executed for each item and the decisions still owned by the hardware owner. Status words: **BETA** = builds/simulates/tests on the authoring machine, not on hardware; **PROPOSED** = new design content; **BLOCKED** = cannot be done without hardware, Vivado or an owner decision.

## 1. Executive summary

| Area | State before | State now | Executed evidence |
|---|---|---|---|
| FPGA RTL | did not parse; 5 modules/IP missing; 400 MHz fabric; no host path | parses/lints; all modules present; ISERDES 1:4 capture + 100 MHz polyphase DDC (bit-exact vs legacy); SPI host bridge; register map | `beta/fpga/build.sh`: 0 failures, 9 testbench runs PASS (§3) |
| STM32 firmware | no build system/HAL; 7+ defects; empty ADAR1000 phase tables | builds and links (93 KB flash); 12 defects fixed; ADAR1000 tables from the datasheet; bridge + REG commands | `beta/stm32/build.sh` exit 0; host tests 6/6 (§4) |
| Python GUI | V6 stub; no tests; wrong packet format | package with firmware-exact protocol, bridge-frame path, register panel, simulator; PyInstaller app | pytest 72 passed; selftests exit 0 (§5) |
| PCBs | no Gerbers; Main 15 / Power 308 unconnected; 0 MPN | Main/RF PA 0 unconnected; Power 89 (listed); BOM MPNs; fab notes; full packages; Main rev. B with FT601 (§6) | KiCad DRC reports, export logs |
| Host data path | FT601 unwired | option A pin plan (bank 35) + option B SPI bridge implemented end-to-end | tb PASS, firmware build, GUI tests on the RTL vector (§7) |
| Antenna | none | 16×8 patch panel, KiCad board, openEMS simulated | S11 −18 dB at f0, 128 MHz band, coupling −20.7 dB (§8) |
| Thermal / power | none | drain-gating requirement, 22 V module design, 2-D plate map | 64 °C plate / ≈ 73 °C PA base in case B (§9) |
| Mechanics | none | head + pedestal, 51-part detail model, flat patterns, parts list; torque check | FreeCAD model builds; register file check 0 problems (§10) |
| Radar performance | TBD everywhere | range equation with simulated gain | R(1 m²) ≈ 6 km at B = 50 MHz (§11) |

## 2. What is still impossible here

Vivado synthesis/timing/bitstream (open-source flow attempted — §3.4), flashing and bench tests, fabrication, measurement of component heights, antenna coupon on a VNA, PA thermal test, 89 Power Board pour connections (manual CAD), EAGLE schematic updates for rev. B, owner decisions K1–K8 and D-01…D-19.

## 3. FPGA (beta/fpga)

### 3.1 What exists
28 RTL files (15 modified copies of the originals, 9 new, 4 identical), `mem/` incl. generated `long_chirp_seg3`, 7 testbenches, XDC with datasheet input delays and schematic-derived pins (67/183 bits constrained; 116 UNRESOLVED ports are FT601/status/debug), Vivado Tcl, open-source synthesis scripts (§3.4).

### 3.2 Key technical findings
- The `.mem` references are **conjugate FFT-domain** chirp spectra (1024-point); the matched filter is therefore frequency-domain (FFT → × ref → IFFT) and must not conjugate again; `short_chirp_*.mem` matches neither domain → short-chirp path UNRESOLVED.
- AD9484 is SDR LVDS at the sample rate (datasheet); capture redesigned with ISERDESE2 1:4 (BUFIO/BUFR), IDELAYE2 calibration (pattern-based and blind), MMCM 200 MHz reference, async FIFO into `clk_100m`; the 4-phase DDC/CIC at 100 MHz is bit-exact against the legacy 400 MHz chain (8000 samples, max diff 0 LSB).
- Original bugs fixed beyond the inventory: FFT wrapper `tlast` off-by-one, Doppler FFT valid timing, NCO LUT not a sine, FIR/CIC multi-driven monitors, 2-bit FT601 byte-enable, USB packetizer/analyzer inconsistency.
- SPI host bridge (option B) integrated: packer → 2-bank frame RAM → SPI slave on the STM32 SPI1 lines; ADAR1000 pass-through gated during transfers; command set v2 (frame / write / read / status) — see §7.

### 3.3 Executed tests (build.sh)
| Test | Result |
|---|---|
| iverilog elaboration, sim and synth views | PASS |
| verilator --lint-only -Wall | 0 errors (warnings listed in logs) |
| tb_fft_wrappers (vs numpy, ±2 LSB) | PASS |
| tb_matched_filter (peak at expected bin) | PASS |
| tb_range_bin_decimator (128/128) | PASS |
| tb_adc_iserdes_capture (8/8 lanes lock, skewed lane compensated) | PASS |
| tb_ddc_4x (bit-exact vs legacy) | PASS |
| tb_host_bridge / tb_host_bridge_top (frame + register commands) | PASS |
| tb_system_smoke, ADC_CAPTURE_MODE 1 and 0 (pulse compression end-to-end, 2688 packets) | PASS |

### 3.4 Synthesis without Vivado
Open-source flow (`beta/fpga_synth/`, Yosys 0.69 `synth_xilinx -family xc7 -flatten -abc9`, snapshot 65cd160, FFT IP as 3 black boxes): **12 793 LUT (39 %, incl. 3 100 LUTRAM), 4 726 FF (7 %), 106/120 DSP48E1 (88 %), 2 RAMB18, 0 latches, 0 multi-driven**. nextpnr-xilinx (openXC7, chipdb xc7a50t generated from prjxray) packed every primitive (IBUFDS, BUFG, BUFIO, BUFR, IDELAYE2, IDELAYCTRL, ISERDESE2, MMCME2, DSP48E1, RAMB18E1) but placement did not complete (DSP cascade legalisation; SA placer unbounded retry) — **no open-source Fmax, no bitstream**.

Design consequences found by synthesis: (1) only 14 DSPs remain for the three FFT cores (2 × 1024-point + 1 × 32-point) — the design may not fit the XC7A50T as written (K1 decision: XC7A100T would); (2) six `ram_style=block` memories (chirp ROM, Doppler buffer, bridge frame RAM) have asynchronous reads and become ≈ 4 900 LUTs instead of ≈ 8 RAMB36 — needs registered reads; (3) `stm32_sclk_3v3` on J16 is not clock-capable but drives a BUFG — needs `CLOCK_DEDICATED_ROUTE FALSE` or an oversampled SPI slave in `clk_100m`; (4) the full top needs 192 package pins vs 170 user I/O on FTG256 — the 116 unconstrained debug/FT601 bits must leave the top for a board build.

### 3.5 Open
Vivado run (timing on BUFR/MMCM paths, IDELAYCTRL placement), ISERDES bit order on hardware (PN9 check), matched filter not pipelined (~270 µs/chirp with real IP latency vs 167 µs PRI), FFT IP generation, bank-14 LVDS inputs on a 3.3 V bank (UG471 check in §3.6).

### 3.6 UG471 documentary checks
UG471 v1.10 (fetched from the web archive, `build/docs_ext/ug471.txt`): ISERDESE2 "the first data bit received appears on the highest order Q output" → for SDR 1:4 the oldest bit is on Q4 (the beta model had Q1; fixed, `Q1_IS_OLDEST=0`); BITSLIP in SDR mode shifts the output pattern left by one per pulse, one CLKDIV pulse with a gap, latency two CLKDIV cycles (model corrected); LVDS_25 inputs are acceptable in banks powered at other voltages "provided DIFF_TERM = FALSE, VIN/VIDIFF requirements met" → bank 14 at 3.3 V is allowed for inputs with **external 100 Ω termination, which the schematic does not have** (board change, REQUIRES VERIFICATION). Quotes recorded in `beta/fpga/README.md` and the XDC header.

## 4. STM32 firmware (beta/stm32)
Build: CMake + Arm GNU 14.2.Rel1 + STM32CubeF7 (pinned); FLASH 93 276 B, RAM 17 480 B. Hand-written CubeMX-equivalent USB CDC/startup/linker; clock tree for the real 8 MHz crystal. Defects fixed: ADF4382 pin collision, `platform_ops = NULL`, unbound CDC RX, padded settings frames, GPS_Init, AD9523 CS/SPI speed, AD9523 double init (new), IDQ reading bug, printf to UART, ADAR1000 channel index (new, rotated the beam by one element). ADAR1000 vector-modulator tables filled from datasheet Tables 10–13 (128 rows, ≤ 3.1° encoding error). Bridge: frame forwarding + REG W/R text commands. Host tests 6/6 (settings parser incl. padding, beam matrix, AD9523 registers, I2C timing, ADAR tables, bridge commands). Open: CubeMX regeneration, hardware bring-up, per-board phase calibration.

## 5. Python GUI (beta/gui)
Package `aeris10_gui`; default hardware path = bridge frames over CDC (raw FT601 behind `--raw-ft601`); register map transcribed from the RTL; demo register file; PyInstaller bundle. 72 tests; selftests pass in both modes. Open: hardware CDC test, request IDs for REG replies (ordered matching today).

## 6. PCBs (beta/pcb)
| Board | Unconnected before → after | DRC after | Notes |
|---|---|---|---|
| Main | 15 → 0 | 1049 (U69/U7 paddle pads without net, dangling stubs, silk) | +3V3_FT cluster placed/routed; polygon nets dispositioned |
| Power | 308 → 89 | 328 | 132 parts placed by script; Freerouting 2.5.0; 89 pour-to-pour joins listed in `UNROUTED.md` |
| RF PA | 1 → 0 | 18 | 1 clearance in the source |
| Synth | 0 → 0 | 639 (capped; dispositioned) | silk nudged |
BOM MPN confidence per board in `BOM_<BOARD>_beta.csv`; stack-ups/impedance widths in `FAB_NOTES.md` (PROPOSED).
**Main Board rev. B (`beta/pcb/MAIN_BOARD_REVB/`, FT601 host interface):** FT601 fully wired in the KiCad netlist (64 new nets, 194 pad connections, USB-C receptacle, 30 MHz crystal, RREF, VBUS divider, ESD arrays, SuperSpeed coupling caps); first routing attempt with existing copper locked left 59 open connections because 36 of the 47 bank-35 balls have no escape under the existing fan-out; owner decision (2026-10-09): redo the bank-35 fan-out in rev. B — in progress (result in the rev. B README when finished). The EAGLE schematic must be updated by the designer to match; FT601 datasheet checks (RREF, VBUS, VD10, crystal load) are open.

## 7. Host data path (DSN-LINK-01)
Budget: raw RTL stream 16 MB/s needs the FT601 (option A, rev. B); compact map frame 383 kB/s fits the STM32 CDC (option B). Option A: 47 FT601 signals mapped to free bank-35 pins (CLK on MRCC), XDC fragment, added parts BOM. Option B: implemented and tested end-to-end in simulation; firmware and GUI implement the same frame and the same command set (write 0x02 with ack 0xA2, read 0x03, status 0x04). Bench test on hardware is open.

## 8. Antenna (DSN-ANT-01)
16 rows × 8 series-fed patches on RO4350B 0.508 mm (KiCad native board, Gerbers, STEP). openEMS (built from source): one row S11 = −18 dB at 10.5 GHz but only ≈ 128 MHz contiguous −10 dB band (comb of narrow resonances; −6…−8 dB between dips); row directivity 11.5 dBi; three-row coupling S12 ≈ −20.7 dB at f0 (−18.8 dB worst in band). Consequence: if the chirp bandwidth B exceeds ≈ 100 MHz, the row feed must change (travelling-wave or corporate) — decision D-01 rev. B.

## 9. Thermal and 22 V supply (DSN-THM-01, DSN-PSU-01)
QPA2962 dissipates 37 W per device when the drain is on. Firmware as coded (VD left on) → 591 W (case A, plate ≈ 213 °C in the 2-D model — infeasible). With per-chirp drain gating (11.5 % duty) → 68 W; 2-D finite-difference map of the 300×300×10 plate with two fin fields gives plate max 64 °C, PA base ≈ 73 °C at 45 °C ambient. 22 V module: 2-phase boost, LM5069 enable, 16 pulse gates, ≥ 2.7 mF bulk; requires a `TX_GATE` line (FPGA spare pin — UNRESOLVED).

## 10. Mechanics (DSN-MECH-*)
Head 315 × 315 × 133 mm with vertical boards; 51-part FreeCAD detail model (tray 7 bends, front plate, lid, PTFE window stack, PA plate with tapped holes and brackets, carrier rails, standoffs, gland plate; pedestal plates, bearing, GT3 pulleys, slip ring, motor bracket, mast flange), flat patterns with bend allowance, assembly section, parts list (286 fasteners). Mass estimates: head structure 6.4 kg (+ ≈ 4 kg boards/antenna/cables), pedestal 12.4 kg. **Torque check revises D-12:** a NEMA 23 with 1:3 needs ≥ 200 ms per 7.2° step (revolution ≈ 19 s); NEMA 34 allows ≈ 100 ms.

## 11. Radar performance (DSN-CALC-01 §3)
With 16 × 10 W, the simulated panel gain (≈ 22.5 dBi), T_c = 30 µs, 16-chirp integration, NF 4 dB, 6 dB losses and **B = 50 MHz assumed**: R_max ≈ 6 km (1 m²), 3.4 km (0.1 m²), 1.9 km (0.01 m²). The 3 km Nexus goal is met for RCS ≥ 0.1 m²; the 20 km Extended goal needs ≈ +21 dB (longer integration, narrower B, lower losses, higher gain).

## 12. Decisions required from the owner
K1 FPGA part, K2 HSE crystal (beta assumes 8 MHz), K3 host path (option A rev. B vs option B), K4 22 V supply/`TX_GATE` pin, K5 packet format (bridge frame proposed), K6 ADF4382 pins, K7 synth oscillators, K8 antenna variant; D-01 feed topology vs B, D-07 component heights, D-12 motor class/ratio, D-13 slip-ring channels, D-14 gating line, D-16…D-19 host link.

## 13. File index
`beta/README.md`, `engineering/README.md`, `engineering/DRAWING_REGISTER.md`, `engineering/DESIGN/README.md`, `engineering/DESIGN/CALCS/DESIGN_CALCULATIONS.md`, `engineering/DESIGN/ANTENNA/simulation/TUNING_LOG.md`, `engineering/DESIGN/HOST_LINK/HOST_LINK_DESIGN.md`, `engineering/DESIGN/MECHANICAL/MECHANICAL_PARTS_LIST.md`, `docs/04_RECOVERY_TASKS.md`, `docs/TESTING/ACCEPTANCE_CRITERIA.md`.

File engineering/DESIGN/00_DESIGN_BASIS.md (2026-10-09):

# AERIS-10 — Design basis for the missing elements (PROPOSED DESIGNS)

Document DSN-00 · Rev A · 2026-10-09 · Status: **PROPOSED DESIGN** (new engineering content; nothing here is a reconstruction of an existing design).

Everything under `engineering/DESIGN/` is *proposed*: it closes the BLOCKED items of `engineering/DRAWING_REGISTER.md` (enclosure, internal layout, antenna, cooling, pedestal, 22 V PA supply, harness) with designs derived from the **verified constraints** of the repository plus **explicit design decisions** logged below. Parameters live in `design_parameters.json`; every generator (`tools/design_*.py`) reads that file so a changed decision regenerates every drawing. Status vocabulary for these drawings: `PROPOSED DESIGN` (with the decisions it depends on) — never SOURCE-DERIVED or VERIFIED.

## 1. Verified inputs (from the repository)

| Input | Value | Evidence |
|---|---|---|
| Carrier | 10.5 GHz, λ = 28.57 mm | `main.cpp` wavelength constant; `00_notation/parameter_table.md` |
| Array | 16 elements, uniform linear, pitch λ/2 = 14.3 mm, electronically scanned in **elevation** (31 positions, Δφ ±160° ⇒ ≈ ±33°); azimuth by **mechanical rotation**, 50 positions/rev = 7.2°, 4 stepper steps per position (200 steps/rev) | `02_hardware/04_antenna_beamforming.md` §3–4; `main.cpp:187-195, 514-521` |
| Patch variant | "8×16 patch array", ~20 dBi TBD, 1 W/element (ADTR1107); Extended variant: slotted waveguide + QPA2962 10 W | `parameter_table.md` rows 77, 87 |
| Waveform timing | 16 long chirps (30 µs / PRI 167 µs) + guard 175.4 µs + 16 short chirps (0.5 µs / PRI 175 µs) per beam position | `main.cpp:180-186` |
| PA | QPA2962: PSAT 40 dBm, PAE 22 %, VD 22 V, IDQ 1.68 A, PDISS max 40 W @ TBASE 85 °C, 5×5 mm package | `7_Components Datasheets…/QPA2962/QPA2962 Data Sheet.pdf` p.1-2 |
| PA board | 35 × 60 mm, 7 × Ø3.2 holes, X2 VG (Molex 2-pin), X3 sense (3-pin), `22V` AK300/2 terminal, J1 RFIN / J2 RFOUT SMA | `engineering/PCB/RF_PA/`, `engineering/MECHANICAL/dimensions/RF_PA_dimensions.md` |
| Other boards | Main 260 × 300 (10 holes), Power 280 × 300 (8 holes), Synth 100 × 100 (4 holes) | `engineering/MECHANICAL/dimensions/` |
| System DC input | VIN 12–17 V (Power Board X1) | `Power Management V6.xlsx`; `power_rails.md` |
| Stepper driver | TB6600-class, 9–42 V, 4 A, 20 V selected | xlsx row 63 |
| Cooling | "apply when temperature reaches a threshold (relay)" — a fan relay exists in the plan | xlsx row 64 |
| Host link | USB 2.0 full-speed CDC via Main Board X53 | schematic |
| Yaw sensor | IMU in the head is used to point the array north at start-up | `main.cpp:1513-1519` |

## 2. Design decisions (log)
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

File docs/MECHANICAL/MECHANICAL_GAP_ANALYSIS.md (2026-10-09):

# Mechanical Gap Analysis — AERIS-10

Status date 2026-10-08. Evidence: repository-wide file search (`find` by extension), EAGLE `.brd` parsing (`tools/gen_board_outline_svg.py`), documentation grep, Word/draw.io text extraction. No dimension in this document was invented; every number has a file source.

> **Update 2026-10-09:** mechanical artefacts generated from the PCB geometry (DXF, STEP bodies, 1:1 plan view, dimension sheets with hole tables and mass ESTIMATES), the CONCEPTUAL exploded view, parts list and assembly sequence are in `engineering/MECHANICAL/` and `engineering/ASSEMBLY/`; the unresolved geometry register is `engineering/VALIDATION/UNRESOLVED_GEOMETRY.md`; reconstruction guides for enclosure/antenna/pedestal/cooling drawings are MDR-01…MDR-05 in `engineering/MISSING_DRAWINGS_RECOVERY_PLAN.md`.

## 1. Mechanical source files found

| Path | Type | What it is | Mechanical value |
|---|---|---|---|
| `2_Functional Diagram & Interconnection Matrices/Functional_Diagram.dwg` | AutoCAD DWG (header `AC1027`, AutoCAD 2013–2017) | functional block diagram | none (not a drawing of a part) |
| `5_Simulations/Sim_BPF_Te_100um/Drawing1.dxf` (+ `.bak`) | DXF (`AC1032`) | 2-D layout of the simulated microstrip band-pass filter (7 MLIN + 2 MTEE from the Qucs netlist); units unverified | filter geometry only |
| `5_Simulations/Sim_BPF_Te_100um/Sim_BPF_Te_100um.gds` | GDSII | same filter | same |
| `4_Schematics and Boards Layout/4_6_Schematics/*/*.brd` | EAGLE board | PCB outlines, mounting holes | **the only verified mechanical data** (section 3) |
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

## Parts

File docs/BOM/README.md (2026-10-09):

# Bill of Materials Package — AERIS-10

Generated 2026-10-08 by `python3 tools/gen_eagle_bom.py` directly from the EAGLE schematics (no EAGLE run). Regenerate after any schematic change:

```
S="4_Schematics and Boards Layout/4_6_Schematics"
python3 tools/gen_eagle_bom.py "$S/MainBoard/RADAR_Main_Board.sch"                        --out docs/BOM/BOM_MAIN_BOARD.csv            --refs docs/BOM/REFS_MAIN_BOARD.csv            --md docs/BOM/BOM_MAIN_BOARD.md
python3 tools/gen_eagle_bom.py "$S/PowerBoard/PowerBoard.sch"                              --out docs/BOM/BOM_POWER_SUPPLY.csv          --refs docs/BOM/REFS_POWER_SUPPLY.csv          --md docs/BOM/BOM_POWER_SUPPLY.md
python3 tools/gen_eagle_bom.py "$S/PowerAmplifierBoard/RF_PA.sch"                          --out docs/BOM/BOM_RF_PA.csv                 --refs docs/BOM/REFS_RF_PA.csv                 --md docs/BOM/BOM_RF_PA.md
python3 tools/gen_eagle_bom.py "$S/FrequencySynthesizerBoard/Clocks_Freq_Synth_board.sch"  --out docs/BOM/BOM_FREQUENCY_SYNTHESIZER.csv --refs docs/BOM/REFS_FREQUENCY_SYNTHESIZER.csv --md docs/BOM/BOM_FREQUENCY_SYNTHESIZER.md
```

## What is in each file

| File | Content |
|---|---|
| `BOM_<BOARD>.csv` | grouped line items: `item, qty, value, deviceset, device, package, library, mpn_attribute, manufacturer_attribute, mpn_candidate, mpn_status, references` |
| `BOM_<BOARD>.md` | same, human-readable |
| `REFS_<BOARD>.csv` | one row per reference designator (for pick-and-place / assembly cross-check) |

## Summary

| Board | Physical references | Line items | Lines with MPN attribute | References without value | Status |
|---|---:|---:|---:|---:|---|
| Main Board | 776 | 98 | 0 | 244 | INCOMPLETE — no MPNs, FT601 (U6) unconnected but listed, 11 parts parked off-board |
| Power Supply | 312 | 28 | 0 | 80 | INCOMPLETE — no MPNs, 132 parts not placed on the board |
| RF PA | 25 | 11 | 0 | 6 | INCOMPLETE — no MPNs; `QPA2962_B` is a deviceset name |
| Frequency Synthesizer | 184 | 40 | 0 | 47 | INCOMPLETE — matches the existing `Clocks_Freq_Synth_board_BOM.xlsx` (40 lines) which also has empty MPN columns |

**`mpn_status` meaning:** `VERIFIED (attribute)` — an explicit MPN attribute exists in the schematic (none today); `UNVERIFIED (deviceset name)` — the EAGLE deviceset name looks like a part number (e.g. `ADAR1000ACCZN`, `TPS562208DDCT`) but has not been checked against a distributor; `GENERIC — value/package only` — passive to be sourced by value/package/tolerance (tolerance and voltage rating are **not** in the schematics).

## System-level items not on any PCB (from `README.md`, `Power Management V6.xlsx`, `main.cpp`) — quantities and part numbers UNKNOWN unless stated

| Item | Evidence | Part number |
|---|---|---|
| GPS module (NMEA 9600 on UART5) | `main.cpp:2143-2170`; xlsx "NEO-6M" | NEO-6M (xlsx only) |
| IMU GY-85 (ADXL345/ITG3205/HMC5883L, I2C3) | `GY_85_HAL.c`; xlsx | GY-85 module |
| Barometer BMP180 (I2C3) | `BMP180.cpp`; xlsx | BMP180 |
| Temperature sensors TMP37 ×8 via ADS7830 | `main.cpp:1752-1775`; xlsx | TMP37 |
| Stepper motor 200 steps/rev + driver | `main.cpp:195`; xlsx "TBS6600 [9-42 V]" (TB6600-class) | motor UNKNOWN |
| Slip ring | `README.md:86`; `Project_Description.docx` | UNKNOWN |
| Cooling fans | `main.h:142` `EN_DIS_COOLING`; xlsx "COOLING SYSTEM" | UNKNOWN |
| Antenna array (8×16 patch or 32×16 slotted waveguide) | `README.md:82-83` | no CAD, no part |
| Enclosure | `README.md:143` (missing path) | none |
| Inter-board cables: SMA (37 + 11 + 2 ports), Molex 22-23-20xx (56 + 34 + 6 + 2 headers) | schematics | cable assemblies not defined |

## Validation procedure (BOM)

1. Regenerate with the command above; compare `qty` sum with the element count of the `.brd` (776 / 312 / 25 / 184).
2. For every `UNVERIFIED` line, look the deviceset up at a distributor and write the confirmed MPN into the schematic part attribute `MPN` (EAGLE: part → *Attributes*), then regenerate — the status becomes `VERIFIED (attribute)`.
3. Fill every empty `value` (244/80/6/47 today) in the schematic; passives also need tolerance/voltage attributes.
4. Add a `DNP` attribute for parts not populated in a given variant (FT601 and its decoupling; variant-specific PA parts).
5. Acceptance: 0 `UNVERIFIED`, 0 empty values, DNP column present, generated CSV identical in part count to the `.mnt` pick-and-place.

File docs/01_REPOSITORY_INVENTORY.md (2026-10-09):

# 01 — Repository Inventory (AERIS-10)

Generated 2026-10-08 by `tools/gen_inventory_doc.py` from the live file tree (524 files, `.git` excluded). Regenerate after any change: `python3 tools/gen_inventory_doc.py`.

Status legend: COMPLETE — usable as-is for its purpose; INCOMPLETE — exists but cannot fulfil its purpose (syntax error, fragment, contradictory); MISSING DEPENDENCY — needs files absent from the repository; PLACEHOLDER — template/stub content; REQUIRES VALIDATION — plausible but not verified by an executed check; UNKNOWN — no check applied.

## Status summary

| Status | Files |
|---|---:|
| COMPLETE | 220 |
| INCOMPLETE | 7 |
| MISSING DEPENDENCY | 37 |
| PLACEHOLDER | 3 |
| REQUIRES VALIDATION | 256 |
| UNKNOWN | 1 |

## Subsystem summary

| Subsystem | Files |
|---|---:|
| Automation | 16 |
| Datasheets | 48 |
| Docs: hardware | 9 |
| Docs: notation | 3 |
| Docs: physics | 12 |
| Docs: research | 9 |
| Docs: software | 4 |
| Engineering manual (generated) | 37 |
| FPGA | 37 |
| Media / utilities | 7 |
| PCB | 2 |
| PCB: Frequency Synthesizer | 2 |
| PCB: Main Board | 2 |
| PCB: Power Supply | 2 |
| PCB: Production files | 8 |
| PCB: RF PA | 2 |
| Planning (GSD) | 71 |
| Power management | 1 |
| Project description | 1 |
| Python GUI | 14 |
| Root | 2 |
| STM32 firmware | 138 |
| Simulation | 82 |
| System diagrams | 3 |
| Utility scripts | 12 |

## File table

| Path | File type | Subsystem | Purpose | Dependencies | Status |
|---|---|---|---|---|---|
| `README.md` | Markdown | Root | Project overview; claims Gerbers, assembly guide (10_docs/) and enclosure files that do not exist | — | INCOMPLETE |
| `claude.md` | Markdown | Root | Task specification for this engineering reconstruction | — | COMPLETE |
| `.planning/PROJECT.md` | Markdown | Planning (GSD) | GSD planning / phase records (process artefacts) | — | COMPLETE |
| `.planning/REQUIREMENTS.md` | Markdown | Planning (GSD) | GSD planning / phase records (process artefacts) | — | COMPLETE |
| `.planning/ROADMAP.md` | Markdown | Planning (GSD) | GSD planning / phase records (process artefacts) | — | COMPLETE |
| `.planning/STATE.md` | Markdown | Planning (GSD) | GSD planning / phase records (process artefacts) | — | COMPLETE |
| `.planning/config.json` | JSON | Planning (GSD) | GSD planning / phase records (process artefacts) | — | COMPLETE |
| `.planning/codebase/ARCHITECTURE.md` | Markdown | Planning (GSD) | GSD planning / phase records (process artefacts) | — | COMPLETE |
| `.planning/codebase/CONCERNS.md` | Markdown | Planning (GSD) | GSD planning / phase records (process artefacts) | — | COMPLETE |
| `.planning/codebase/CONVENTIONS.md` | Markdown | Planning (GSD) | GSD planning / phase records (process artefacts) | — | COMPLETE |
| `.planning/codebase/INTEGRATIONS.md` | Markdown | Planning (GSD) | GSD planning / phase records (process artefacts) | — | COMPLETE |
| `.planning/codebase/STACK.md` | Markdown | Planning (GSD) | GSD planning / phase records (process artefacts) | — | COMPLETE |
| `.planning/codebase/STRUCTURE.md` | Markdown | Planning (GSD) | GSD planning / phase records (process artefacts) | — | COMPLETE |
| `.planning/codebase/TESTING.md` | Markdown | Planning (GSD) | GSD planning / phase records (process artefacts) | — | COMPLETE |
| `.planning/phases/01-notation-parameter-standardization/01-01-PLAN.md` | Markdown | Planning (GSD) | GSD planning / phase records (process artefacts) | — | COMPLETE |
| `.planning/phases/01-notation-parameter-standardization/01-01-SUMMARY.md` | Markdown | Planning (GSD) | GSD planning / phase records (process artefacts) | — | COMPLETE |
| `.planning/phases/01-notation-parameter-standardization/01-02-PLAN.md` | Markdown | Planning (GSD) | GSD planning / phase records (process artefacts) | — | COMPLETE |
| `.planning/phases/01-notation-parameter-standardization/01-02-SUMMARY.md` | Markdown | Planning (GSD) | GSD planning / phase records (process artefacts) | — | COMPLETE |
| `.planning/phases/01-notation-parameter-standardization/01-RESEARCH.md` | Markdown | Planning (GSD) | GSD planning / phase records (process artefacts) | — | COMPLETE |
| `.planning/phases/01-notation-parameter-standardization/01-VERIFICATION.md` | Markdown | Planning (GSD) | GSD planning / phase records (process artefacts) | — | COMPLETE |
| `.planning/phases/02-physics-foundation/02-01-PLAN.md` | Markdown | Planning (GSD) | GSD planning / phase records (process artefacts) | — | COMPLETE |
| `.planning/phases/02-physics-foundation/02-01-SUMMARY.md` | Markdown | Planning (GSD) | GSD planning / phase records (process artefacts) | — | COMPLETE |
| `.planning/phases/02-physics-foundation/02-02-PLAN.md` | Markdown | Planning (GSD) | GSD planning / phase records (process artefacts) | — | COMPLETE |
| `.planning/phases/02-physics-foundation/02-02-SUMMARY.md` | Markdown | Planning (GSD) | GSD planning / phase records (process artefacts) | — | COMPLETE |
| `.planning/phases/02-physics-foundation/02-03-PLAN.md` | Markdown | Planning (GSD) | GSD planning / phase records (process artefacts) | — | COMPLETE |
| `.planning/phases/02-physics-foundation/02-03-SUMMARY.md` | Markdown | Planning (GSD) | GSD planning / phase records (process artefacts) | — | COMPLETE |
| `.planning/phases/02-physics-foundation/02-04-PLAN.md` | Markdown | Planning (GSD) | GSD planning / phase records (process artefacts) | — | COMPLETE |
| `.planning/phases/02-physics-foundation/02-04-SUMMARY.md` | Markdown | Planning (GSD) | GSD planning / phase records (process artefacts) | — | COMPLETE |
| `.planning/phases/02-physics-foundation/02-RESEARCH.md` | Markdown | Planning (GSD) | GSD planning / phase records (process artefacts) | — | COMPLETE |
| `.planning/phases/02-physics-foundation/02-VERIFICATION.md` | Markdown | Planning (GSD) | GSD planning / phase records (process artefacts) | — | COMPLETE |
| `.planning/phases/03-hardware-documentation/03-01-PLAN.md` | Markdown | Planning (GSD) | GSD planning / phase records (process artefacts) | — | COMPLETE |
| `.planning/phases/03-hardware-documentation/03-01-SUMMARY.md` | Markdown | Planning (GSD) | GSD planning / phase records (process artefacts) | — | COMPLETE |
| `.planning/phases/03-hardware-documentation/03-02-PLAN.md` | Markdown | Planning (GSD) | GSD planning / phase records (process artefacts) | — | COMPLETE |
| `.planning/phases/03-hardware-documentation/03-02-SUMMARY.md` | Markdown | Planning (GSD) | GSD planning / phase records (process artefacts) | — | COMPLETE |
| `.planning/phases/03-hardware-documentation/03-03-PLAN.md` | Markdown | Planning (GSD) | GSD planning / phase records (process artefacts) | — | COMPLETE |
| `.planning/phases/03-hardware-documentation/03-03-SUMMARY.md` | Markdown | Planning (GSD) | GSD planning / phase records (process artefacts) | — | COMPLETE |
| `.planning/phases/03-hardware-documentation/03-04-PLAN.md` | Markdown | Planning (GSD) | GSD planning / phase records (process artefacts) | — | COMPLETE |
| `.planning/phases/03-hardware-documentation/03-04-SUMMARY.md` | Markdown | Planning (GSD) | GSD planning / phase records (process artefacts) | — | COMPLETE |
| `.planning/phases/03-hardware-documentation/03-05-PLAN.md` | Markdown | Planning (GSD) | GSD planning / phase records (process artefacts) | — | COMPLETE |
| `.planning/phases/03-hardware-documentation/03-05-SUMMARY.md` | Markdown | Planning (GSD) | GSD planning / phase records (process artefacts) | — | COMPLETE |
| `.planning/phases/03-hardware-documentation/03-RESEARCH.md` | Markdown | Planning (GSD) | GSD planning / phase records (process artefacts) | — | COMPLETE |
| `.planning/phases/03-hardware-documentation/03-VERIFICATION.md` | Markdown | Planning (GSD) | GSD planning / phase records (process artefacts) | — | COMPLETE |
| `.planning/phases/04-software-documentation/04-01-PLAN.md` | Markdown | Planning (GSD) | GSD planning / phase records (process artefacts) | — | COMPLETE |
| `.planning/phases/04-software-documentation/04-01-SUMMARY.md` | Markdown | Planning (GSD) | GSD planning / phase records (process artefacts) | — | COMPLETE |
| `.planning/phases/04-software-documentation/04-02-PLAN.md` | Markdown | Planning (GSD) | GSD planning / phase records (process artefacts) | — | COMPLETE |
| `.planning/phases/04-software-documentation/04-02-SUMMARY.md` | Markdown | Planning (GSD) | GSD planning / phase records (process artefacts) | — | COMPLETE |
| `.planning/phases/04-software-documentation/04-03-PLAN.md` | Markdown | Planning (GSD) | GSD planning / phase records (process artefacts) | — | COMPLETE |
| `.planning/phases/04-software-documentation/04-03-SUMMARY.md` | Markdown | Planning (GSD) | GSD planning / phase records (process artefacts) | — | COMPLETE |
| `.planning/phases/04-software-documentation/04-RESEARCH.md` | Markdown | Planning (GSD) | GSD planning / phase records (process artefacts) | — | COMPLETE |
| `.planning/phases/04-software-documentation/04-VERIFICATION.md` | Markdown | Planning (GSD) | GSD planning / phase records (process artefacts) | — | COMPLETE |
| `.planning/phases/05-software-improvement-research/05-01-PLAN.md` | Markdown | Planning (GSD) | GSD planning / phase records (process artefacts) | — | COMPLETE |
| `.planning/phases/05-software-improvement-research/05-01-SUMMARY.md` | Markdown | Planning (GSD) | GSD planning / phase records (process artefacts) | — | COMPLETE |
| `.planning/phases/05-software-improvement-research/05-02-PLAN.md` | Markdown | Planning (GSD) | GSD planning / phase records (process artefacts) | — | COMPLETE |
| `.planning/phases/05-software-improvement-research/05-02-SUMMARY.md` | Markdown | Planning (GSD) | GSD planning / phase records (process artefacts) | — | COMPLETE |
| `.planning/phases/05-software-improvement-research/05-03-PLAN.md` | Markdown | Planning (GSD) | GSD planning / phase records (process artefacts) | — | COMPLETE |
| `.planning/phases/05-software-improvement-research/05-03-SUMMARY.md` | Markdown | Planning (GSD) | GSD planning / phase records (process artefacts) | — | COMPLETE |
| `.planning/phases/05-software-improvement-research/05-04-PLAN.md` | Markdown | Planning (GSD) | GSD planning / phase records (process artefacts) | — | COMPLETE |
| `.planning/phases/05-software-improvement-research/05-04-SUMMARY.md` | Markdown | Planning (GSD) | GSD planning / phase records (process artefacts) | — | COMPLETE |
| `.planning/phases/05-software-improvement-research/05-RESEARCH.md` | Markdown | Planning (GSD) | GSD planning / phase records (process artefacts) | — | COMPLETE |
| `.planning/phases/05-software-improvement-research/05-VERIFICATION.md` | Markdown | Planning (GSD) | GSD planning / phase records (process artefacts) | — | COMPLETE |
| `.planning/phases/06-hardware-improvement-research/06-01-PLAN.md` | Markdown | Planning (GSD) | GSD planning / phase records (process artefacts) | — | COMPLETE |
| `.planning/phases/06-hardware-improvement-research/06-01-SUMMARY.md` | Markdown | Planning (GSD) | GSD planning / phase records (process artefacts) | — | COMPLETE |
| `.planning/phases/06-hardware-improvement-research/06-02-PLAN.md` | Markdown | Planning (GSD) | GSD planning / phase records (process artefacts) | — | COMPLETE |
| `.planning/phases/06-hardware-improvement-research/06-02-SUMMARY.md` | Markdown | Planning (GSD) | GSD planning / phase records (process artefacts) | — | COMPLETE |
| `.planning/phases/06-hardware-improvement-research/06-03-PLAN.md` | Markdown | Planning (GSD) | GSD planning / phase records (process artefacts) | — | COMPLETE |
| `.planning/phases/06-hardware-improvement-research/06-03-SUMMARY.md` | Markdown | Planning (GSD) | GSD planning / phase records (process artefacts) | — | COMPLETE |
| `.planning/phases/06-hardware-improvement-research/06-RESEARCH.md` | Markdown | Planning (GSD) | GSD planning / phase records (process artefacts) | — | COMPLETE |
| `.planning/phases/06-hardware-improvement-research/06-VERIFICATION.md` | Markdown | Planning (GSD) | GSD planning / phase records (process artefacts) | — | COMPLETE |
| `.planning/research/ARCHITECTURE.md` | Markdown | Planning (GSD) | GSD planning / phase records (process artefacts) | — | COMPLETE |
| `.planning/research/FEATURES.md` | Markdown | Planning (GSD) | GSD planning / phase records (process artefacts) | — | COMPLETE |
| `.planning/research/PITFALLS.md` | Markdown | Planning (GSD) | GSD planning / phase records (process artefacts) | — | COMPLETE |
| `.planning/research/STACK.md` | Markdown | Planning (GSD) | GSD planning / phase records (process artefacts) | — | COMPLETE |
| `.planning/research/SUMMARY.md` | Markdown | Planning (GSD) | GSD planning / phase records (process artefacts) | — | COMPLETE |
| `00_notation/conventions.md` | Markdown | Docs: notation | Notation / parameter documentation | — | COMPLETE |
| `00_notation/parameter_table.md` | Markdown | Docs: notation | Notation / parameter documentation | — | COMPLETE |
| `00_notation/symbol_table.md` | Markdown | Docs: notation | Notation / parameter documentation | — | COMPLETE |
| `01_physics/01_fmcw_theory.md` | Markdown | Docs: physics | Physics derivation documentation | — | COMPLETE |
| `01_physics/02_lfm_waveform_model.md` | Markdown | Docs: physics | Physics derivation documentation | — | COMPLETE |
| `01_physics/03_beamforming_theory.md` | Markdown | Docs: physics | Physics derivation documentation | — | COMPLETE |
| `01_physics/04_detection_theory.md` | Markdown | Docs: physics | Physics derivation documentation | — | COMPLETE |
| `01_physics/05_noise_analysis.md` | Markdown | Docs: physics | Physics derivation documentation | — | COMPLETE |
| `01_physics/06_calibration_theory.md` | Markdown | Docs: physics | Physics derivation documentation | — | COMPLETE |
| `01_physics/figures/beam_pattern_N16_taylor.svg` | SVG figure | Docs: physics | Generated physics figure or generator script | numpy, matplotlib | COMPLETE |
| `01_physics/figures/beam_pattern_N16_uniform.svg` | SVG figure | Docs: physics | Generated physics figure or generator script | numpy, matplotlib | COMPLETE |
| `01_physics/figures/detection_curves_swerling0.svg` | SVG figure | Docs: physics | Generated physics figure or generator script | numpy, matplotlib | COMPLETE |
| `01_physics/figures/detection_curves_swerling1.svg` | SVG figure | Docs: physics | Generated physics figure or generator script | numpy, matplotlib | COMPLETE |
| `01_physics/figures/gen_detection_curves.py` | Python | Docs: physics | Generated physics figure or generator script | numpy, matplotlib | COMPLETE |
| `01_physics/figures/generate_beam_patterns.py` | Python | Docs: physics | Generated physics figure or generator script | numpy, matplotlib | COMPLETE |
| `02_hardware/01_system_overview.md` | Markdown | Docs: hardware | Hardware documentation (derived from RTL/firmware; partly contradicts schematic) | — | REQUIRES VALIDATION |
| `02_hardware/02_rf_frontend.md` | Markdown | Docs: hardware | Hardware documentation (derived from RTL/firmware; partly contradicts schematic) | — | REQUIRES VALIDATION |
| `02_hardware/03_frequency_synthesis.md` | Markdown | Docs: hardware | Hardware documentation (derived from RTL/firmware; partly contradicts schematic) | — | REQUIRES VALIDATION |
| `02_hardware/04_antenna_beamforming.md` | Markdown | Docs: hardware | Hardware documentation (derived from RTL/firmware; partly contradicts schematic) | — | REQUIRES VALIDATION |
| `02_hardware/05_fpga_board.md` | Markdown | Docs: hardware | Hardware documentation (derived from RTL/firmware; partly contradicts schematic) | — | REQUIRES VALIDATION |
| `02_hardware/06_power_management.md` | Markdown | Docs: hardware | Hardware documentation (derived from RTL/firmware; partly contradicts schematic) | — | REQUIRES VALIDATION |
| `02_hardware/07_timing_budget.md` | Markdown | Docs: hardware | Hardware documentation (derived from RTL/firmware; partly contradicts schematic) | — | REQUIRES VALIDATION |
| `02_hardware/08_power_budget.md` | Markdown | Docs: hardware | Hardware documentation (derived from RTL/firmware; partly contradicts schematic) | — | REQUIRES VALIDATION |
| `02_hardware/09_gps_imu_transforms.md` | Markdown | Docs: hardware | Hardware documentation (derived from RTL/firmware; partly contradicts schematic) | — | REQUIRES VALIDATION |
| `03_software/01_fpga_pipeline.md` | Markdown | Docs: software | Software documentation | — | REQUIRES VALIDATION |
| `03_software/02_stm32_firmware.md` | Markdown | Docs: software | Software documentation | — | REQUIRES VALIDATION |
| `03_software/03_python_gui.md` | Markdown | Docs: software | Software documentation | — | REQUIRES VALIDATION |
| `03_software/04_usb_protocol.md` | Markdown | Docs: software | Software documentation | — | REQUIRES VALIDATION |
| `04_research/01_cfar_variants.md` | Markdown | Docs: research | Improvement research survey | — | COMPLETE |
| `04_research/02_clutter_rejection.md` | Markdown | Docs: research | Improvement research survey | — | COMPLETE |
| `04_research/03_range_extension.md` | Markdown | Docs: research | Improvement research survey | — | COMPLETE |
| `04_research/04_fpga_optimization.md` | Markdown | Docs: research | Improvement research survey | — | COMPLETE |
| `04_research/05_ml_detection.md` | Markdown | Docs: research | Improvement research survey | — | COMPLETE |
| `04_research/06_pulse_compression.md` | Markdown | Docs: research | Improvement research survey | — | COMPLETE |
| `04_research/07_target_tracking.md` | Markdown | Docs: research | Improvement research survey | — | COMPLETE |
| `04_research/08_adaptive_beamforming.md` | Markdown | Docs: research | Improvement research survey | — | COMPLETE |
| `1_Project_Description/Project_Description.docx` | Word document | Project description | Project description (Word) | — | COMPLETE |
| `2_Functional Diagram & Interconnection Matrices/Functional_Diagram.dwg` | AutoCAD drawing | System diagrams | AutoCAD functional diagram (binary; not a mechanical drawing) | AutoCAD | REQUIRES VALIDATION |
| `2_Functional Diagram & Interconnection Matrices/RADAR_V6.drawio` | draw.io diagram | System diagrams | System block diagram (draw.io XML) | — | COMPLETE |
| `2_Functional Diagram & Interconnection Matrices/RADAR_V6.jpg` | Image | System diagrams | Rendered block diagram | — | COMPLETE |
| `3_Power Management/Power Management V6.xlsx` | Excel workbook | Power management | Rail list and sequencing table (source for STM32 EN_* GPIO sequencing) | — | REQUIRES VALIDATION |
| `4_Schematics and Boards Layout/4_4_Board Stack-up/Stack_Hybrid.png` | Image | PCB | Hybrid stack-up image (no numeric layer table in text form) | — | REQUIRES VALIDATION |
| `4_Schematics and Boards Layout/4_6_Schematics/Stack_Hybrid.png` | Image | PCB | Duplicate of 4_4_Board Stack-up/Stack_Hybrid.png | — | COMPLETE |
| `4_Schematics and Boards Layout/4_6_Schematics/FrequencySynthesizerBoard/Clocks_Freq_Synth_board.brd` | EAGLE board | PCB: Frequency Synthesizer | EAGLE board: frequency synthesizer | .sch | REQUIRES VALIDATION |
| `4_Schematics and Boards Layout/4_6_Schematics/FrequencySynthesizerBoard/Clocks_Freq_Synth_board.sch` | Schematic (EAGLE/Qucs) | PCB: Frequency Synthesizer | EAGLE schematic: AD9523-1 clock + 2x ADF4382 synthesizers | embedded libraries | REQUIRES VALIDATION |
| `4_Schematics and Boards Layout/4_6_Schematics/MainBoard/RADAR_Main_Board.brd` | EAGLE board | PCB: Main Board | EAGLE board layout for Main Board | .sch (forward/back annotation) | REQUIRES VALIDATION |
| `4_Schematics and Boards Layout/4_6_Schematics/MainBoard/RADAR_Main_Board.sch` | Schematic (EAGLE/Qucs) | PCB: Main Board | EAGLE 7.4.0 schematic: XC7A50T-2FTG256I (U42), STM32F746ZGT7 (U2), AD9484, AD9708, 4x ADAR1000, 16x ADTR1107, 2x LTC5552, FT601Q (U6, UNCONNECTED) | embedded libraries | REQUIRES VALIDATION |
| `4_Schematics and Boards Layout/4_6_Schematics/PowerAmplifierBoard/RF_PA.brd` | EAGLE board | PCB: RF PA | EAGLE board: RF PA | .sch | REQUIRES VALIDATION |
| `4_Schematics and Boards Layout/4_6_Schematics/PowerAmplifierBoard/RF_PA.sch` | Schematic (EAGLE/Qucs) | PCB: RF PA | EAGLE schematic: QPA2962 GaN PA board (AERIS-10X) | embedded libraries | REQUIRES VALIDATION |
| `4_Schematics and Boards Layout/4_6_Schematics/PowerBoard/PowerBoard.brd` | EAGLE board | PCB: Power Supply | EAGLE board: power supply board | .sch | REQUIRES VALIDATION |
| `4_Schematics and Boards Layout/4_6_Schematics/PowerBoard/PowerBoard.sch` | Schematic (EAGLE/Qucs) | PCB: Power Supply | EAGLE schematic: power supply board | embedded libraries | REQUIRES VALIDATION |
| `4_Schematics and Boards Layout/4_7_Production Files/Frequency_Synthesizer/Clocks_Freq_Synth_board-smd.mnt` | EAGLE mount/PnP | PCB: Production files | EAGLE SMD mount (pick-and-place) file | .brd | REQUIRES VALIDATION |
| `4_Schematics and Boards Layout/4_7_Production Files/Frequency_Synthesizer/Clocks_Freq_Synth_board-tht.csv` | CSV data | PCB: Production files | THT placement CSV | .brd | REQUIRES VALIDATION |
| `4_Schematics and Boards Layout/4_7_Production Files/Frequency_Synthesizer/Clocks_Freq_Synth_board-tht.mnt` | EAGLE mount/PnP | PCB: Production files | EAGLE THT mount file | .brd | REQUIRES VALIDATION |
| `4_Schematics and Boards Layout/4_7_Production Files/Frequency_Synthesizer/Clocks_Freq_Synth_board_BOM.xlsx` | Excel workbook | PCB: Production files | BOM for frequency synthesizer board (only board with a BOM) | .sch | REQUIRES VALIDATION |
| `4_Schematics and Boards Layout/4_7_Production Files/Frequency_Synthesizer/PCBWay_Impedance_Note_RO4350B_h0p102mm.pdf` | PDF | PCB: Production files | Fab impedance note (RO4350B, 0.102 mm) — only stack-up evidence in text form | — | REQUIRES VALIDATION |
| `4_Schematics and Boards Layout/4_7_Production Files/Frequency_Synthesizer/mnt.csv` | CSV data | PCB: Production files | Placement CSV | .brd | REQUIRES VALIDATION |
| `4_Schematics and Boards Layout/4_7_Production Files/Frequency_Synthesizer/smd_.xlsx` | Excel workbook | PCB: Production files | SMD placement workbook | .brd | REQUIRES VALIDATION |
| `4_Schematics and Boards Layout/4_7_Production Files/Frequency_Synthesizer/th_.xlsx` | Excel workbook | PCB: Production files | THT placement workbook | .brd | REQUIRES VALIDATION |
| `5_Simulations/E_plane_Kaiser25dB_like.png` | Image | Simulation | RF/analog simulation (Qucs .sch/.dat/.dpl, Touchstone, MATLAB/Octave, Python) | Qucs / Octave / Python | REQUIRES VALIDATION |
| `5_Simulations/E_plane_cut.png` | Image | Simulation | RF/analog simulation (Qucs .sch/.dat/.dpl, Touchstone, MATLAB/Octave, Python) | Qucs / Octave / Python | REQUIRES VALIDATION |
| `5_Simulations/H_plane_Kaiser25dB_like.png` | Image | Simulation | RF/analog simulation (Qucs .sch/.dat/.dpl, Touchstone, MATLAB/Octave, Python) | Qucs / Octave / Python | REQUIRES VALIDATION |
| `5_Simulations/H_plane_cut.png` | Image | Simulation | RF/analog simulation (Qucs .sch/.dat/.dpl, Touchstone, MATLAB/Octave, Python) | Qucs / Octave / Python | REQUIRES VALIDATION |
| `5_Simulations/Heatmap_Kaiser25dB_like.png` | Image | Simulation | RF/analog simulation (Qucs .sch/.dat/.dpl, Touchstone, MATLAB/Octave, Python) | Qucs / Octave / Python | REQUIRES VALIDATION |
| `5_Simulations/QPA2962.dat` | Simulation data (Qucs) | Simulation | RF/analog simulation (Qucs .sch/.dat/.dpl, Touchstone, MATLAB/Octave, Python) | Qucs / Octave / Python | REQUIRES VALIDATION |
| `5_Simulations/QPA2962.dpl` | Qucs display | Simulation | RF/analog simulation (Qucs .sch/.dat/.dpl, Touchstone, MATLAB/Octave, Python) | Qucs / Octave / Python | REQUIRES VALIDATION |
| `5_Simulations/QPA2962.sch` | Schematic (EAGLE/Qucs) | Simulation | RF/analog simulation (Qucs .sch/.dat/.dpl, Touchstone, MATLAB/Octave, Python) | Qucs / Octave / Python | REQUIRES VALIDATION |
| `5_Simulations/Slotted_DielectricFilled_Waveguide.m` | MATLAB/Octave | Simulation | RF/analog simulation (Qucs .sch/.dat/.dpl, Touchstone, MATLAB/Octave, Python) | Qucs / Octave / Python | REQUIRES VALIDATION |
| `5_Simulations/Stub_BPF_V5.dat` | Simulation data (Qucs) | Simulation | RF/analog simulation (Qucs .sch/.dat/.dpl, Touchstone, MATLAB/Octave, Python) | Qucs / Octave / Python | REQUIRES VALIDATION |
| `5_Simulations/Stub_BPF_V5.dpl` | Qucs display | Simulation | RF/analog simulation (Qucs .sch/.dat/.dpl, Touchstone, MATLAB/Octave, Python) | Qucs / Octave / Python | REQUIRES VALIDATION |
| `5_Simulations/Stub_BPF_V5.sch` | Schematic (EAGLE/Qucs) | Simulation | RF/analog simulation (Qucs .sch/.dat/.dpl, Touchstone, MATLAB/Octave, Python) | Qucs / Octave / Python | REQUIRES VALIDATION |
| `5_Simulations/array_pattern_Kaiser25dB_like.py` | Python | Simulation | RF/analog simulation (Qucs .sch/.dat/.dpl, Touchstone, MATLAB/Octave, Python) | Qucs / Octave / Python | REQUIRES VALIDATION |
| `5_Simulations/array_pattern_heatmap.png` | Image | Simulation | RF/analog simulation (Qucs .sch/.dat/.dpl, Touchstone, MATLAB/Octave, Python) | Qucs / Octave / Python | REQUIRES VALIDATION |
| `5_Simulations/slot_layout_taper32.csv` | CSV data | Simulation | RF/analog simulation (Qucs .sch/.dat/.dpl, Touchstone, MATLAB/Octave, Python) | Qucs / Octave / Python | REQUIRES VALIDATION |
| `5_Simulations/wg_alumina_slotted_openems.m` | MATLAB/Octave | Simulation | RF/analog simulation (Qucs .sch/.dat/.dpl, Touchstone, MATLAB/Octave, Python) | Qucs / Octave / Python | REQUIRES VALIDATION |
| `5_Simulations/Antenna/Quartz_Waveguide.py` | Python | Simulation | openEMS antenna simulation script | openEMS, CSXCAD python | REQUIRES VALIDATION |
| `5_Simulations/Antenna/openems_quartz_slotted_wg_10p5GHz.py` | Python | Simulation | openEMS antenna simulation script | openEMS, CSXCAD python | REQUIRES VALIDATION |
| `5_Simulations/DAC_ReconstructionFilter/DAC_RLPF.dat` | Simulation data (Qucs) | Simulation | RF/analog simulation (Qucs .sch/.dat/.dpl, Touchstone, MATLAB/Octave, Python) | Qucs / Octave / Python | REQUIRES VALIDATION |
| `5_Simulations/DAC_ReconstructionFilter/DAC_RLPF.dpl` | Qucs display | Simulation | RF/analog simulation (Qucs .sch/.dat/.dpl, Touchstone, MATLAB/Octave, Python) | Qucs / Octave / Python | REQUIRES VALIDATION |
| `5_Simulations/DAC_ReconstructionFilter/DAC_RLPF.sch` | Schematic (EAGLE/Qucs) | Simulation | RF/analog simulation (Qucs .sch/.dat/.dpl, Touchstone, MATLAB/Octave, Python) | Qucs / Octave / Python | REQUIRES VALIDATION |
| `5_Simulations/DAC_ReconstructionFilter/Generate_ChirpcsvFile.py` | Python | Simulation | RF/analog simulation (Qucs .sch/.dat/.dpl, Touchstone, MATLAB/Octave, Python) | Qucs / Octave / Python | REQUIRES VALIDATION |
| `5_Simulations/DAC_ReconstructionFilter/dac_output.csv` | CSV data | Simulation | RF/analog simulation (Qucs .sch/.dat/.dpl, Touchstone, MATLAB/Octave, Python) | Qucs / Octave / Python | REQUIRES VALIDATION |
| `5_Simulations/DAC_ReconstructionFilter/multi_ramp_output.csv` | CSV data | Simulation | RF/analog simulation (Qucs .sch/.dat/.dpl, Touchstone, MATLAB/Octave, Python) | Qucs / Octave / Python | REQUIRES VALIDATION |
| `5_Simulations/DAC_ReconstructionFilter/multi_ramp_stairs.csv` | CSV data | Simulation | RF/analog simulation (Qucs .sch/.dat/.dpl, Touchstone, MATLAB/Octave, Python) | Qucs / Octave / Python | REQUIRES VALIDATION |
| `5_Simulations/DAC_ReconstructionFilter/ramp_output.csv` | CSV data | Simulation | RF/analog simulation (Qucs .sch/.dat/.dpl, Touchstone, MATLAB/Octave, Python) | Qucs / Octave / Python | REQUIRES VALIDATION |
| `5_Simulations/Fencing/Via_fencing.py` | Python | Simulation | RF/analog simulation (Qucs .sch/.dat/.dpl, Touchstone, MATLAB/Octave, Python) | Qucs / Octave / Python | REQUIRES VALIDATION |
| `5_Simulations/Fencing/Via_fencing2.py` | Python | Simulation | RF/analog simulation (Qucs .sch/.dat/.dpl, Touchstone, MATLAB/Octave, Python) | Qucs / Octave / Python | REQUIRES VALIDATION |
| `5_Simulations/Fencing/via_fence_setup_pitch.png` | Image | Simulation | RF/analog simulation (Qucs .sch/.dat/.dpl, Touchstone, MATLAB/Octave, Python) | Qucs / Octave / Python | REQUIRES VALIDATION |
| `5_Simulations/Fencing/via_fence_setup_pitch_offset.png` | Image | Simulation | RF/analog simulation (Qucs .sch/.dat/.dpl, Touchstone, MATLAB/Octave, Python) | Qucs / Octave / Python | REQUIRES VALIDATION |
| `5_Simulations/IF_BPF/IF_BPF.dat` | Simulation data (Qucs) | Simulation | RF/analog simulation (Qucs .sch/.dat/.dpl, Touchstone, MATLAB/Octave, Python) | Qucs / Octave / Python | REQUIRES VALIDATION |
| `5_Simulations/IF_BPF/IF_BPF.dpl` | Qucs display | Simulation | RF/analog simulation (Qucs .sch/.dat/.dpl, Touchstone, MATLAB/Octave, Python) | Qucs / Octave / Python | REQUIRES VALIDATION |
| `5_Simulations/IF_BPF/IF_BPF.sch` | Schematic (EAGLE/Qucs) | Simulation | RF/analog simulation (Qucs .sch/.dat/.dpl, Touchstone, MATLAB/Octave, Python) | Qucs / Octave / Python | REQUIRES VALIDATION |
| `5_Simulations/IF_BPF_Balanced/IF_BPF_Balanced.dat` | Simulation data (Qucs) | Simulation | RF/analog simulation (Qucs .sch/.dat/.dpl, Touchstone, MATLAB/Octave, Python) | Qucs / Octave / Python | REQUIRES VALIDATION |
| `5_Simulations/IF_BPF_Balanced/IF_BPF_Balanced.dpl` | Qucs display | Simulation | RF/analog simulation (Qucs .sch/.dat/.dpl, Touchstone, MATLAB/Octave, Python) | Qucs / Octave / Python | REQUIRES VALIDATION |
| `5_Simulations/IF_BPF_Balanced/IF_BPF_Balanced.sch` | Schematic (EAGLE/Qucs) | Simulation | RF/analog simulation (Qucs .sch/.dat/.dpl, Touchstone, MATLAB/Octave, Python) | Qucs / Octave / Python | REQUIRES VALIDATION |
| `5_Simulations/IF_BPF_Balanced/multiband_signal.csv` | CSV data | Simulation | RF/analog simulation (Qucs .sch/.dat/.dpl, Touchstone, MATLAB/Octave, Python) | Qucs / Octave / Python | REQUIRES VALIDATION |
| `5_Simulations/IF_BPF_Balanced/six_tone_signal.csv` | CSV data | Simulation | RF/analog simulation (Qucs .sch/.dat/.dpl, Touchstone, MATLAB/Octave, Python) | Qucs / Octave / Python | REQUIRES VALIDATION |
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

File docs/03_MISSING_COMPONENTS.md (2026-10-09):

# 03 — Missing Components Register

Status date 2026-10-08. Priorities: **P0** blocks a reproducible build or a required artefact; **P1** blocks a complete release or reliable validation; **P2** documentation/maintainability. "Impact" names the build output that cannot be produced. Recovery procedures are detailed in `docs/04_RECOVERY_TASKS.md` (task IDs in the last column). Automated presence check: `python3 tools/check_missing_files.py` (IDs starting with FPGA-/STM-/GUI-/PCB-/MECH-/REPO- are the manifest IDs of that script).

## FPGA

| ID | Component | Evidence | Impact | Recovery procedure | Verification | Priority | Task |
|---|---|---|---|---|---|---|---|
| FPGA-00 | Parseable RTL | `radar_system_top.v:312` `wire` inside `always`; `:155-156` procedural assignment to `wire`; `ddc_400m.v:252-266` use-before-declare; `radar_receiver_final.v:150/192`, `:216-217` phantom ports (iverilog/verilator logs `build/lint/`) | no elaboration, no synthesis | edit the six locations (FPGA-T03) | `tools/fpga_lint.sh` no "syntax error" | P0 | R-FPGA-03 |
| FPGA-01 | Pin-complete XDC | `cntrt.xdc`: 142 placeholder lines, 180/180 bits unassigned, `PACKAGE_PIN_BANK` invalid (:320-321), LVCMOS33 on 1.8 V bank signals (:85,:92) | no implementation/bitstream | use `reconstructed/radar_system_top_schematic_derived.xdc` after designer verification; resolve 25 ports with no board counterpart | `tools/check_fpga_constraints.py` exit 0 | P0 | R-FPGA-02 |
| FPGA-02 | Vivado project / build script | no `.xpr`, `.tcl` existed | no reproducible build | `tools/vivado/create_project.tcl` (generated; part must be passed) | `.xpr` created, elaboration log archived | P0 | R-FPGA-04 |
| FPGA-03 | RTL modules `ad9484_lvds_to_cmos_400m`, `range_bin_decimator`, `matched_filter_processing_chain` | instantiated at `radar_receiver_final.v:82,226`, `matched_filter_multi_segment.v:361`; no definition repo-wide | elaboration fails | obtain original ISE project or re-implement to the inferred interfaces (FPGA-T04) | iverilog "missing modules" list empty | P0 | R-FPGA-05 |
| FPGA-04 | Xilinx FFT IP `xfft_32`, `FFT_enhanced` (.xci) | `doppler_processor.v:283`, `fft_1024_forward.v:102`, `fft_1024_inverse.v:78` | elaboration fails | regenerate in Vivado IP catalog to the port widths used | `.xci` committed; elaboration OK | P0 | R-FPGA-05 |
| FPGA-05 | `long_chirp_seg3_i/q.mem` | `chirp_memory_loader_param.v:58-59`; files absent; other 8 present | ROM segment 3 uninitialised | obtain from generator or set `LONG_SEGMENTS=3` (designer) | `$readmemh` without warnings | P0 | R-FPGA-06 |
| FPGA-06 | Portable `$readmemh` paths | `chirp_memory_loader_param.v:3-12` absolute `C:/Users/dell/...` | sim/synth cannot find files on any other machine | override parameters at `radar_receiver_final.v:144` with relative names | Vivado log no "cannot open" | P0 | R-FPGA-06 |
| FPGA-07 | Device decision XC7A50T vs XC7A100T | schematic/xlsx/drawio 50T vs README/XDC/docs 100T | wrong part → wrong resources, wrong constraints | designer decision (FPGA-T01) | recorded decision | P0 | R-FPGA-01 |
| FPGA-08 | 400 MHz LVDS capture structure | `lvds_to_cmos_400m.v:35-43` flop-derived clock; no ISERDES/IDDR in active path | design non-functional | redesign ADC front-end with IDDR/ISERDES + BUFIO/BUFR or MMCM | timing report; hardware capture test | P0 (functional) | R-FPGA-07 |
| FPGA-09 | Multi-driven registers | `plfm_chirp_controller.v:564-576/683-784`; `usb_data_interface.v:65-79/176-182`; `cic_decimator_4x_enhanced.v:71/181/291` | synthesis error | single-driver refactor | verilator MULTIDRIVEN = 0 | P0 | R-FPGA-07 |
| FPGA-10 | Level-shifter instantiation (STM32 SPI → ADAR1000) | `radar_transmitter.v:59-71` undriven; `level_shifter_interface.v` orphan | ADAR1000 unreachable | instantiate or route SPI differently | verilator UNDRIVEN = 0 for those nets | P0 (functional) | R-FPGA-07 |
| FPGA-11 | Host data path | FT601 unconnected on Main Board; RTL assumes it | no radar data to host | architecture decision (K3) | decision record | P0 | R-SYS-01 |
| FPGA-12 | Clock-group constraints, CDC fixes | no `set_clock_groups`; `cdc_adc_to_processing` Gray-codes data | timing/CDC unsafe | add constraints; use `cdc_handshake` | `report_cdc` clean | P1 | R-FPGA-08 |
| FPGA-13 | Runnable testbench with pass/fail | SVA only, no gating (`radar_system_tb.v:528-543`) | no regression | add `$fatal`, scoreboard; run xsim | sim log PASS | P1 | R-FPGA-09 |
| FPGA-14 | Authoritative TX LUT | `plfm_chirp_controller.v:99-560` vs `chirp_lut_init.v` differ; no generator script | waveform ambiguity | obtain generator; delete dead copy | one LUT source, generator committed | P1 | R-FPGA-06 |
| FPGA-15 | Bitstream | none | — | after all above | `.bit` + reports | P1 | R-FPGA-10 |

## STM32

| ID | Component | Evidence | Impact | Recovery procedure | Verification | Priority | Task |
|---|---|---|---|---|---|---|---|
| STM-01 | `.ioc` | absent repo-wide | no regeneration of USB/startup/linker | regenerate from `docs/STM32` §3 (STM-T02) | generated MSP = repo MSP | P0 | R-STM-02 |
| STM-02 | Linker script | absent | no link | CubeMX output | link OK | P0 | R-STM-02 |
| STM-03 | Startup `.s` | absent (`system_stm32f7xx.c:124` references it) | no boot | CubeF7 template | link OK | P0 | R-STM-02 |
| STM-04 | Build system | absent | no reproducible build | CubeIDE project or `reconstructed/CMakeLists.txt` (UNVERIFIED) | `.elf` built | P0 | R-STM-03 |
| STM-05..08 | USB Device app files | `main.cpp:21,23`; `gps_handler.h:6-7` include them; absent | no USB, no `MX_USB_DEVICE_Init` | CubeMX USB_DEVICE CDC generation + USER CODE RX forwarding (C4) | enumeration test | P0 | R-STM-02, R-STM-04 |
| STM-09 | HAL driver sources | 50 headers absent (`tools/check_stm32_includes.py`) | no compile | STM32CubeF7 | S-02 exit 0 | P0 | R-STM-01 |
| STM-10 | CMSIS device header | `system_stm32f7xx.c:47` | no compile | STM32CubeF7 | S-02 | P0 | R-STM-01 |
| STM-11 | HSE crystal consistency | 8 MHz (sch XTAL1) vs 25 MHz (`hal_conf.h:97`, `main.cpp:1823`) | PLL out of range → no clock/USB | designer decision (C1) | measured SYSCLK 72 MHz, USB 48 MHz | P0 | R-STM-05 |
| STM-12 | ADF4382 pin macros | `adf4382a_manager.h:9-28` collide with PA enables | PA rails toggled, LO never configured | use `main.h` macros (C2) | code review; LO lock LEDs | P0 | R-STM-06 |
| STM-13 | ADF4382 SPI platform ops | `adf4382a_manager.c:42,51` NULL → `Error_Handler` | firmware halts at init | set `stm32_spi_ops` + CS (C3, C7) | init returns 0 | P0 | R-STM-06 |
| STM-14 | USB RX forwarding | `main.cpp:328-339` never bound (C4); padding (C5) | GUI cannot start radar | USER CODE in `usbd_cdc_if.c`; fix padding | READY_FOR_DATA reached | P0 | R-STM-04 |
| STM-15 | Case-mismatched headers | `ADS7830.H`, `DAC5578.H`, `platform_noos_stm32.H` | build fails on Linux/CI | rename | includes check 0 mismatches | P1 | R-STM-03 |
| STM-16 | `hal_set_gpio_by_index` | `platform_noos_stm32.c:50-58` undefined | link error if compiled | exclude file | link OK | P1 | R-STM-03 |
| STM-17 | `GPS_Init` call | never called (`gps_handler.cpp:6,67`) | no GPS to GUI | add call (C6) | GPSB packets observed | P1 | R-STM-07 |
| STM-18 | USB VID/PID | unknown | GUI device filter | choose/record in `usbd_desc.c` | enumeration | P1 | R-STM-02 |
| STM-19 | `STM32_ALGO.docx` content | 0-byte file | algorithm documentation lost | obtain from author | file > 0 bytes | P2 | R-DOC-03 |

## Python GUI

| ID | Component | Evidence | Impact | Recovery | Verification | Priority | Task |
|---|---|---|---|---|---|---|---|
| GUI-01 | `requirements.txt` | absent → **generated** | env not reproducible | done (`9_Firmware/9_3_GUI/requirements.txt`) | P-01 PASSED | P1 | done |
| GUI-02 | `pyproject.toml` | absent → **generated** | no packaging | done | `python -m build` (NOT RUN) | P2 | R-GUI-03 |
| GUI-03 | Complete `GUI_V6.py` | stub classes `:90-92,365-375,419-425`; undefined `STM32USBInterface` `:392` | documented "current" GUI unusable | complete or demote to V5 | module runs | P1 | R-GUI-01 |
| GUI-04 | Protocol alignment with firmware/RTL | `docs/GUI/DEPENDENCIES.md` §6 | no end-to-end data | architecture decision K3/K5 | AC-P6 | P1 | R-SYS-01 |
| GUI-05 | Unit tests | none | no regression | write tests for parsers/CFAR | pytest | P1 | R-GUI-02 |
| GUI-06 | FT601 host library | pyftdi lacks FT601 support | V6 cannot open device | FTDI D3XX binding or drop FT601 | import + open | P1 | R-SYS-01 |
| GUI-07 | `GUI_V1.py` fragment, `GUI_V5_Demo.py` truncated | syntax error; `AttributeError` at `:955` | confusion, failed syntax check | archive | P-02 exit 0 | P2 | R-GUI-01 |
| GUI-08 | Google Maps API key | placeholder in V4–V6 | map blank | user key via config | map renders | P2 | R-GUI-03 |

## PCB

| ID | Component | Evidence | Impact | Recovery | Verification | Priority | Task |
|---|---|---|---|---|---|---|---|
| PCB-MB-01..04 | Main Board Gerber, drill, BOM(MPN), P&P | none exist | cannot fabricate | P-EAGLE-04/06/07 after layout completion | `check_manufacturing_files.py` | P0 | R-PCB-01, R-PCB-05 |
| PCB-MB-05 | Main Board layout completion | 2 390 airwires, 11 off-board parts, 211 approved DRC, `+3V3_FT` unrouted | fabrication would be wrong | designer completes routing; FT601 decision | RATSNEST nothing to do; DRC 0 | P0 | R-PCB-01 |
| PCB-PS-01..03 | Power Board Gerber, drill, BOM | none | cannot fabricate | as above | tool | P0 | R-PCB-02, R-PCB-05 |
| PCB-PS-04 | Power Board layout completion + sch/brd version mismatch | 309 airwires, 132 off-board, brd 7.4.0 vs sch 9.6.2 | — | re-link in 9.6.2, place, route | consistency + RATSNEST | P0 | R-PCB-02 |
| PCB-PA-01..03 | RF PA Gerber, drill, BOM | none (layout complete) | cannot fabricate | P-EAGLE-04/06 | tool | P0 | R-PCB-03, R-PCB-05 |
| PCB-FS-01..02 | Synth Gerber, drill | none (P&P + BOM exist) | cannot fabricate | P-EAGLE-04 | tool | P0 | R-PCB-04 |
| PCB-FS-03 | Synth BOM MPNs | xlsx MPN columns empty | cannot purchase | fill attributes | `mpn_status` VERIFIED | P0 | R-PCB-05 |
| PCB-ALL-01 | Stack-up per board | PNG (6L, unlabeled) ≠ DRU ≠ impedance note | impedance/thickness unknown | vendor stack-up | fab drawing | P0 | R-PCB-06 |
| PCB-ALL-02 | Fab + assembly drawings, schematic PDFs, ERC/DRC reports | none | incomplete package | P-EAGLE-02/03/07/08 | files present | P1 | R-PCB-05 |
| PCB-ALL-03 | Datasheets for parts actually used (TPS562208, LM2662, AD9523-1, FT601, STM32F746, XC7A50T, oscillators, GY-85, BMP180, NEO-6M, TB6600) | absent; unrelated ones present (TPS562201, LM2663, MAX20029, STUW81300, QPM1021, QPA1013, TGA2623) | review impossible | collect | files present | P2 | R-DOC-02 |

## Mechanical

| ID | Component | Evidence | Impact | Recovery | Verification | Priority | Task |
|---|---|---|---|---|---|---|---|
| MECH-01 | `10_docs/assembly_guide.md` | `README.md:141`; absent | no assembly instructions | write per `ASSEMBLY_DOCUMENTATION_REQUIREMENTS.md` §2 after CAD exists | link check | P1 | R-MECH-02 |
| MECH-02 | `10_docs/Hardware/Enclosure` | `README.md:143`; absent | no enclosure | obtain CAD from designer | STEP/STL present | P1 | R-MECH-01 |
| MECH-03 | Antenna array CAD/drawing | two contradictory simulations, no CAD | cannot build antenna | designer decision + CAD | drawing present | P1 | R-MECH-01 |
| MECH-04 | Pedestal, slip ring, stepper, fans part numbers | none | cannot source | designer | BOM lines | P1 | R-MECH-01 |
| MECH-05 | PCB thickness / mass | stack-up unresolved | no mass budget | after PCB-ALL-01 | table | P2 | R-PCB-06 |
| MECH-06 | Outline/hole drawings | absent → **generated** (`docs/MECHANICAL/drawings/`) | — | done | AC-M1 MET | — | done |

## Repository / documentation

| ID | Component | Evidence | Impact | Recovery | Verification | Priority | Task |
|---|---|---|---|---|---|---|---|
| REPO-01 | `LICENSE` | README MIT badge, no file | licensing unclear | add MIT LICENSE (owner decision) | file | P2 | R-DOC-01 |
| REPO-02 | `.gitignore` | none; 16 `.pyc`, `.bak`, zip committed | noise | add | file | P2 | R-DOC-01 |
| REPO-03 | Git repository scope | project folder has no own `.git`; `git rev-parse --show-toplevel` = `/Users/void` | history/attribution unreliable | `git init` in `PLFM_RADAR` (owner decision) | `.git` present | P2 | R-DOC-01 |
| REPO-04 | README accuracy | Gerber claim, XC7A100T, `10_docs` links | misleads users | correct (owner) | link check | P2 | R-DOC-01 |
| REPO-05 | Broken doc links | 34 (`tools/check_doc_links.py`) | navigation | fix targets | tool exit 0 | P2 | R-DOC-01 |
| DOC-01..06 | Documentation tree of `claude.md` §13 | absent → **generated** | — | done | manifest DOC-* present | P2 | done |

---

## Update 2026-10-09 — engineering drawings package

The PCB production entries above (Gerber/drill/BOM/P&P for the four boards) now have a **generated** counterpart under `engineering/PCB/<BOARD>/` (KiCad 10 conversion of the EAGLE boards, DRC with EAGLE-DRU-derived rules, cross-checked against the EAGLE XML). They remain listed as missing because the designer-released EAGLE export does not exist, manufacturer part numbers are absent and the Main/Power layouts are unfinished. New missing items identified by the drawing work are registered in `engineering/VALIDATION/UNRESOLVED_GEOMETRY.md` (G-01…G-12) and `engineering/MISSING_DRAWINGS_RECOVERY_PLAN.md` (MDR-01…MDR-11). New design findings (firmware never asserts `EN_+3V3_ADTR`, `EN_+5V0_PA1/2/3`, `EN_+5V5_PA`; Power Board U30 input from VIN; `+1V8_CLOCK` single output needed twice; SV1 carries 15 enables) are in `engineering/ELECTRICAL/power_distribution/power_rails.md` §4.

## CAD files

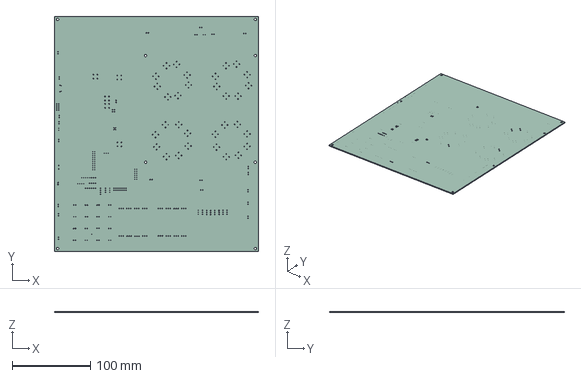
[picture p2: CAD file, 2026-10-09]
beta/pcb/MAIN_BOARD_REVB/exports/mechanical/MAIN_BOARD_REVB_board_only.step
260.0 x 300.0 x 1.51 mm

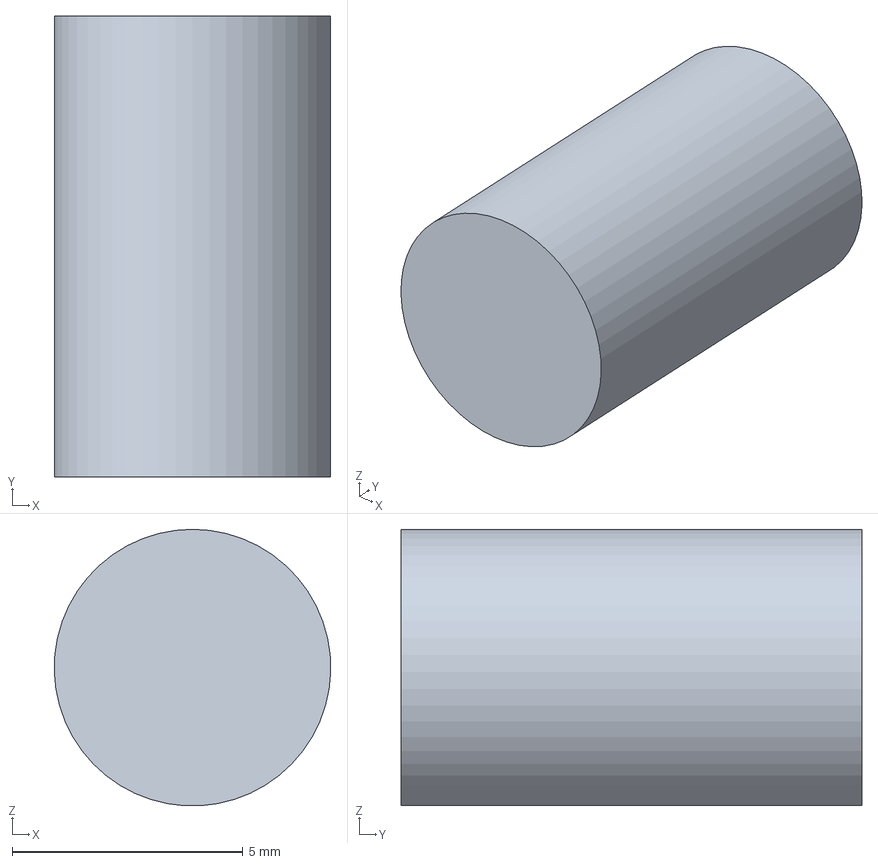
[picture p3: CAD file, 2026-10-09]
engineering/DESIGN/MECHANICAL/CAD/detail/parts/Main_Board_standoff_M3_10_hex_at__4_296_.step
6.00 x 10.0 x 5.99 mm

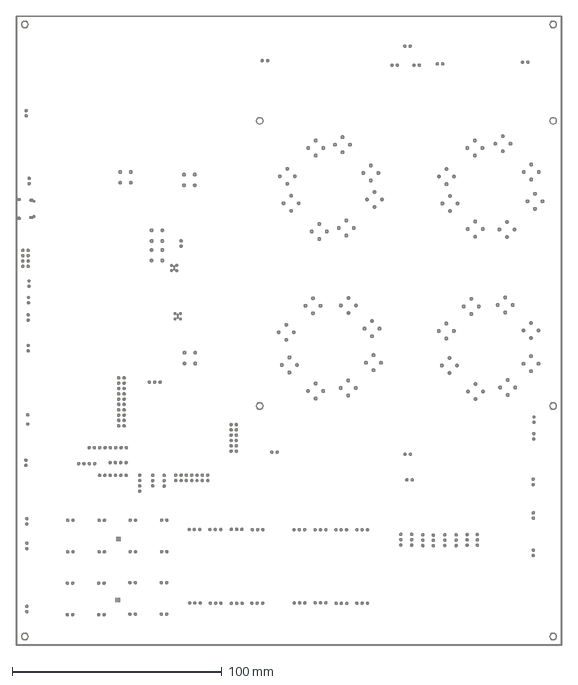
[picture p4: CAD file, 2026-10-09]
beta/pcb/MAIN_BOARD_REVB/exports/mechanical/MAIN_BOARD_REVB_outline.dxf
260.0 x 300.0 mm

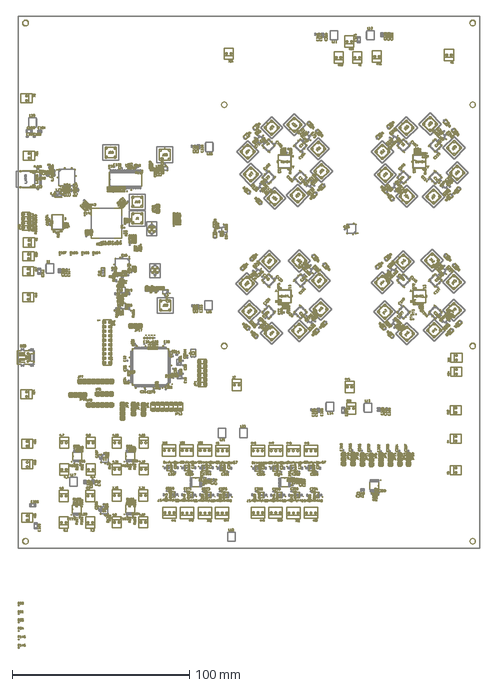
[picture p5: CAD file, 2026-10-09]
beta/pcb/MAIN_BOARD_REVB/exports/mechanical/MAIN_BOARD_REVB_top_fab.dxf
261.2 x 356.2 mm

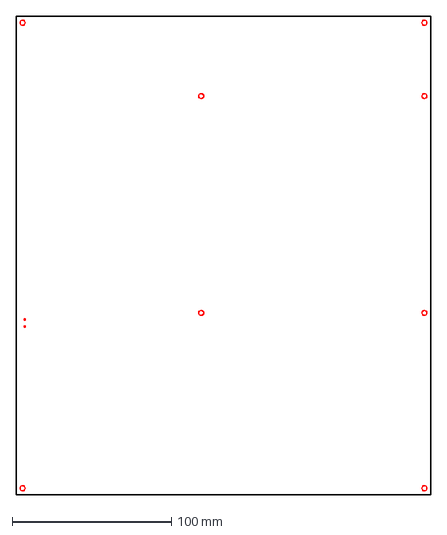
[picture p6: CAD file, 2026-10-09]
engineering/MECHANICAL/DXF/MAIN_BOARD_outline_holes_eagle.dxf
260.0 x 300.0 mm

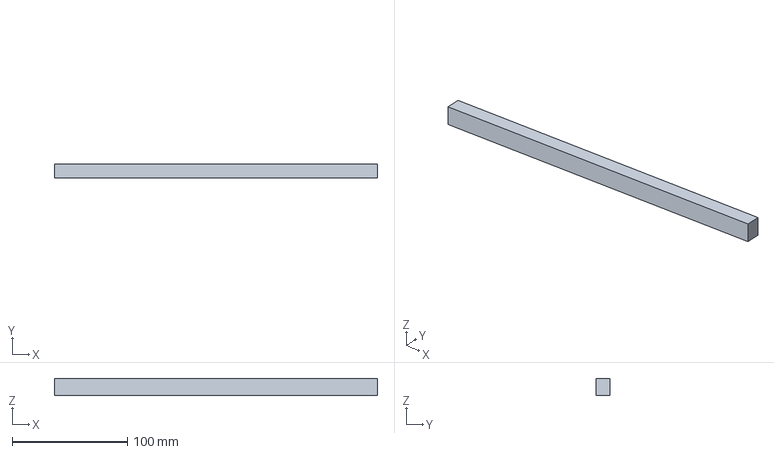
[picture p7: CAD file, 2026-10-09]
engineering/DESIGN/MECHANICAL/CAD/detail/parts/Main_Board_carrier_rail_bottom_U15_12_1_.step
280.0 x 12.0 x 15.0 mm

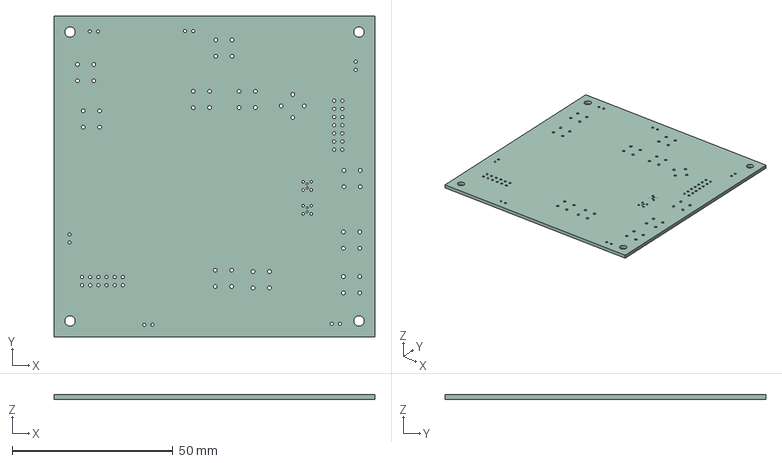
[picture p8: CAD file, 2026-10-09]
beta/pcb/FREQUENCY_SYNTHESIZER/exports/mechanical/FREQUENCY_SYNTHESIZER_board_only.step
100.0 x 100.0 x 1.51 mm

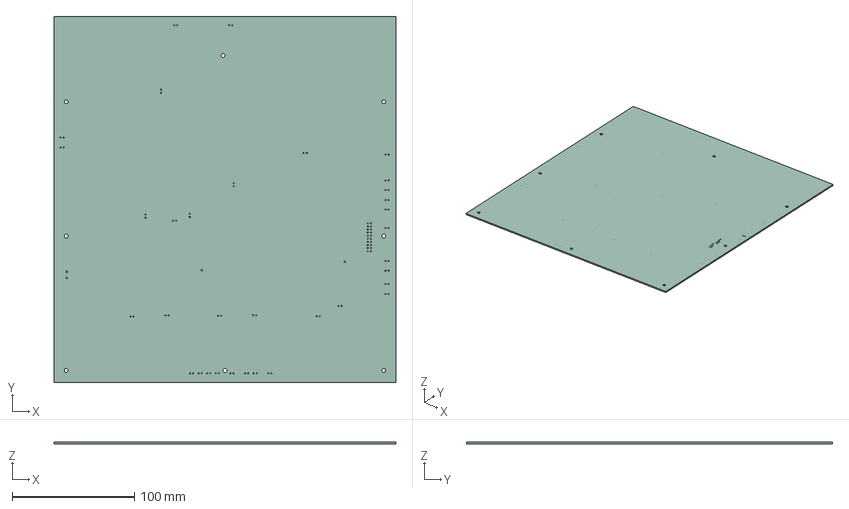
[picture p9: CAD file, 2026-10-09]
beta/pcb/POWER_SUPPLY/exports/mechanical/POWER_SUPPLY_board_only.step
280.0 x 300.0 x 1.51 mm

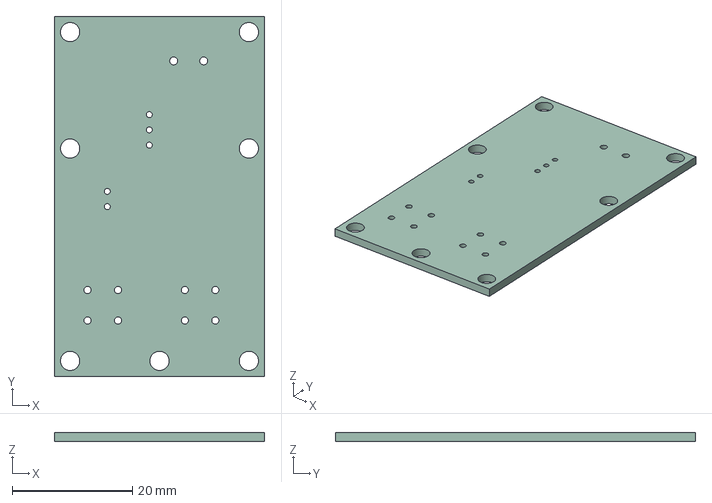
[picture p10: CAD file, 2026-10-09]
beta/pcb/RF_PA/exports/mechanical/RF_PA_board_only.step
35.0 x 60.0 x 1.51 mm

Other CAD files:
engineering/MECHANICAL/STEP/MAIN_BOARD_board_only.step
engineering/DESIGN/MECHANICAL/CAD/detail/parts/Main_Board_standoff_M3_10_hex_at__116_25.step
engineering/DESIGN/MECHANICAL/CAD/detail/parts/Main_Board_standoff_M3_10_hex_at__256_11.step
engineering/DESIGN/MECHANICAL/CAD/detail/parts/Main_Board_standoff_M3_10_hex_at__4_4_.step
engineering/DESIGN/MECHANICAL/CAD/detail/parts/Main_Board_standoff_M3_10_hex_at__116_11.step
engineering/DESIGN/MECHANICAL/CAD/detail/parts/Main_Board_carrier_rail_top_U15_12_1_5_A.step
engineering/DESIGN/MECHANICAL/CAD/detail/parts/Main_Board_standoff_M3_10_hex_at__256_25.step
engineering/DESIGN/MECHANICAL/CAD/detail/parts/Main_Board_standoff_M3_10_hex_at__256_29.step
engineering/DESIGN/MECHANICAL/CAD/detail/parts/Main_Board_standoff_M3_10_hex_at__256_4_.step
beta/pcb/FREQUENCY_SYNTHESIZER/exports/mechanical/FREQUENCY_SYNTHESIZER_outline.dxf
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

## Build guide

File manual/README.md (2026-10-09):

# manual/ — AERIS-10 complete manual (build kit)

This directory is the input kit for a Claude Design run that assembles the complete illustrated engineering & assembly manual. The instructions are in the repository root: **`MANUAL_BUILD_SPEC.md`** (role, hard rules, deliverables, procedure, response format).

| File | Purpose |
|---|---|
| `00_OUTLINE.md` | binding chapter list with sources and figure slots (concatenation order) |
| `STYLE_GUIDE.md` | writing/figure/caption/status rules |
| `FIGURE_PLAN.md` | figure per chapter: existing asset path or render command |
| `ASSET_INDEX.md` | generated index of 225 candidate figures with register status (`python3 tools/gen_manual_asset_index.py`) |
| `ASSEMBLY_STEPS_SOURCE.md` | consolidated assembly / harness / pedestal / bring-up steps with checks — source of chapter 15/16 |
| `chapters/*.md` | 22 chapter files (stubs until written) |
| `tools/build_manual.py` | `--check` validates chapters/figures/links; without flags builds `AERIS10_MANUAL.md`, `build/AERIS10_MANUAL.html` (images embedded) and `build/AERIS10_MANUAL.pdf` (headless Chrome) |

Workflow: write chapters → render missing figures into `manual/figures/` → `python3 tools/build_manual.py --check` (0 problems) → `python3 tools/build_manual.py` → fill `FIGURE_LOG.md` and `MANUAL_VALIDATION.md`.

## Build status (2026-10-09)

All 22 chapters written (97.6 k words, 69 figures); `build/AERIS10_MANUAL.pdf` (191 pages) and `.html` built; validation in `MANUAL_VALIDATION.md`, figures in `FIGURE_LOG.md`. Rebuild after any chapter edit: `python3 tools/build_manual.py --check && python3 tools/gen_figure_log.py && python3 tools/build_manual.py`.

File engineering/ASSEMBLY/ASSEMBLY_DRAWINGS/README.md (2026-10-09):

# Assembly drawings (per board)

ASM-DRW-01 · Rev A · 2026-10-09 · Status: SOURCE-DERIVED (KiCad plots of the converted EAGLE boards; not reviewed by the designer).

| Board | Top assembly (fab layer + silk + pad outlines) | Bottom assembly (mirrored) | Pick-and-place | BOM |
|---|---|---|---|---|
| Main Board | `../../PCB/MAIN_BOARD/drawings/MAIN_BOARD_assembly_top.pdf` | `../../PCB/MAIN_BOARD/drawings/MAIN_BOARD_assembly_bottom_mirrored.pdf` | `../../PCB/MAIN_BOARD/assembly/MAIN_BOARD_pick_and_place.csv` | `../../PCB/MAIN_BOARD/assembly/MAIN_BOARD_BOM.csv` |
| Power Supply | `../../PCB/POWER_SUPPLY/drawings/POWER_SUPPLY_assembly_top.pdf` | `../../PCB/POWER_SUPPLY/drawings/POWER_SUPPLY_assembly_bottom_mirrored.pdf` | `../../PCB/POWER_SUPPLY/assembly/POWER_SUPPLY_pick_and_place.csv` | `../../PCB/POWER_SUPPLY/assembly/POWER_SUPPLY_BOM.csv` |
| RF PA | `../../PCB/RF_PA/drawings/RF_PA_assembly_top.pdf` | `../../PCB/RF_PA/drawings/RF_PA_assembly_bottom_mirrored.pdf` | `../../PCB/RF_PA/assembly/RF_PA_pick_and_place.csv` | `../../PCB/RF_PA/assembly/RF_PA_BOM.csv` |
| Frequency Synthesizer | `../../PCB/FREQUENCY_SYNTHESIZER/drawings/FREQUENCY_SYNTHESIZER_assembly_top.pdf` | `../../PCB/FREQUENCY_SYNTHESIZER/drawings/FREQUENCY_SYNTHESIZER_assembly_bottom_mirrored.pdf` | `../../PCB/FREQUENCY_SYNTHESIZER/assembly/FREQUENCY_SYNTHESIZER_pick_and_place.csv` | `../../PCB/FREQUENCY_SYNTHESIZER/assembly/FREQUENCY_SYNTHESIZER_BOM.csv` |

System-level assembly: `../EXPLODED_VIEWS/aeris10_exploded_conceptual.pdf` (CONCEPTUAL), `../PARTS_LIST.md`, `../ASSEMBLY_SEQUENCE.md`.
Missing: component heights (no 3-D models), polarity/pin-1 marks depend on the EAGLE package silkscreen (present where the library drew them), no assembly notes from the designer.

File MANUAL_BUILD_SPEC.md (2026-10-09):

# CLAUDE DESIGN — AERIS-10 COMPLETE ENGINEERING & ASSEMBLY MANUAL

## ROLE

You are a technical-documentation team (radar systems engineer, FPGA/embedded engineer, PCB and RF engineer, mechanical engineer, technical illustrator, technical editor) assembling the **complete illustrated engineering and assembly manual of the AERIS-10 radar** from the material already in this repository. You do not re-derive the engineering: you compile, verify cross-references, render missing figures with the existing tools, and write the narrative and step-by-step procedures around the verified artefacts.

## OBJECTIVE

Produce `manual/AERIS10_MANUAL.md` (single Markdown master with relative figure links) and its rendered `manual/build/AERIS10_MANUAL.html` and `manual/build/AERIS10_MANUAL.pdf` (via `python3 tools/build_manual.py`), covering: system description, theory of operation, every subsystem with schematics/block diagrams/drawings, manufacturing data, firmware/FPGA/GUI build procedures, the proposed designs (antenna, host link, 22 V supply, enclosure, pedestal), the step-by-step assembly and integration procedure with inspection points, test and acceptance, and the honest status of every item.

## INPUTS (read in this order)

1. `manual/00_OUTLINE.md` — chapter plan with the source files for every chapter (binding).
2. `manual/STYLE_GUIDE.md` — writing, figure, caption, status-label and numbering rules (binding).
3. `manual/FIGURE_PLAN.md` — figure list per chapter (existing assets + figures to render) and `manual/ASSET_INDEX.md` (all 200+ candidate figures with register status).
4. `manual/ASSEMBLY_STEPS_SOURCE.md` — consolidated assembly/integration steps to turn into the procedure chapter.
5. `docs/AERIS10_ENGINEERING_BUILD_MANUAL.md` (v1.3, Parts I–XIII), `docs/AERIS10_BETA_ENGINEERING_REPORT.md`, `engineering/DRAWING_REGISTER.md`, `engineering/DESIGN/00_DESIGN_BASIS.md`, the `README.md`/`CHANGELOG.md` of `beta/fpga`, `beta/stm32`, `beta/gui`, `beta/pcb`.
6. Everything they reference (schematic reports, PCB READMEs, calculation sheets, interconnection table, power-rail register, harness schedule, parts lists).

## AUTHORSHIP (mandatory)

The manual is authored by **Antidrone Ukraine — antidrone.cc**. Put this on: the title page (author line + website), the running header/footer of every page (`tools/build_manual.py` does it automatically: header "AERIS-10 — Engineering & Assembly Manual", footer "© Antidrone Ukraine · antidrone.cc · <date> · <status>"), the front-matter revision table (author column), the title block line of every generated drawing (`tools/eagle_svg_common.py` `ATTRIBUTION`, applied when figures are regenerated), the HTML `<meta name="author">`, and the PDF metadata. Original project files from the upstream repository keep their own authorship and are labelled ORIGINAL PROJECT FILE; the manual's authorship covers the compilation, the generated drawings, the reconstruction and the proposed designs.

## HARD RULES

- **Never invent**: every number, pin, part, dimension and claim must trace to a file in the repository; cite it inline as `(source: path[:line])`. If a value is unknown, write "UNKNOWN — see <register/recovery item>", never a placeholder number.
- **Status labels are mandatory** on every figure caption and every procedure: VERIFIED / SOURCE-DERIVED / PARTIAL / CONCEPTUAL / PROPOSED DESIGN / BETA / ORIGINAL PROJECT FILE (vocabulary in `STYLE_GUIDE.md`). Nothing in this project is VERIFIED on hardware; do not promote a status.
- **Preserve originals**: do not modify anything under `9_Firmware/`, `4_Schematics and Boards Layout/`, `engineering/`, `beta/` except by running the listed generators. New files go under `manual/` only (plus `tools/build_manual.py` fixes).
- **Figures**: reuse existing SVG/PNG/PDF assets by relative path; render missing ones only with the repository's tools (`tools/render_eagle_schematic.py`, `tools/svg_sheets_to_pdf.py`, `tools/stl_to_svg_iso.py`, `tools/gen_assembly_exploded_view.py`, `tools/design_mechanical_drawings.py`, Graphviz `dot` for `.dot` files, kicad-cli for board plots). Do not hand-draw geometry; a new diagram may only be a DOT/Mermaid/SVG that restates verified relationships (and says so).
- **Assembly steps** must be numbered, each with: purpose, parts/tools (with the parts-list ID or BOM reference), the action, the check (acceptance value or visual criterion), and the figure reference. Steps that depend on an open decision (K1–K8, D-xx) carry a ⚠ marker and name the decision.
- **Language**: English for the manual (the repository's documentation language). Chat commentary to the user: Ukrainian.
- Keep the Markdown master buildable: `python3 tools/build_manual.py --check` must report 0 missing figures and 0 broken links before you finish.

## DELIVERABLES

| File | Content |
|---|---|
| `manual/AERIS10_MANUAL.md` | the complete manual (≥ the chapter set in `00_OUTLINE.md`; every chapter with text, figures, tables, cross-references) |
| `manual/chapters/*.md` | one file per chapter (the master `AERIS10_MANUAL.md` is concatenated from them by `tools/build_manual.py` — write the chapters, not the master) |
| `manual/build/AERIS10_MANUAL.html`, `.pdf` | rendered outputs with embedded figures (PNG preferred for PDF; SVG allowed in HTML) |
| `manual/FIGURE_LOG.md` | every figure used: number, caption, path, status, how it was produced (existing / rendered by which command) |
| `manual/MANUAL_VALIDATION.md` | `build_manual.py --check` output, link check, list of claims that could not be sourced (must be empty or explained), word/figure counts |

## PROCEDURE

1. Run `python3 tools/gen_manual_asset_index.py` and read `manual/ASSET_INDEX.md`; map each outline figure slot to an asset (or mark "to render").
2. Render the missing figures listed in `FIGURE_PLAN.md` §"to render" with the stated commands into `manual/figures/` (PNG, ≤ 2400 px wide; keep the SVG too).
3. Write each chapter file from its source list; copy tables from the source documents verbatim (do not retype numbers); add narrative only where the sources support it.
4. Write the assembly/integration chapter from `ASSEMBLY_STEPS_SOURCE.md`, one numbered step per row, with figures from DSN-MECH-04/06/07, the harness schedule and the connector matrix.
5. Build: `python3 tools/build_manual.py` (concatenates `chapters/` in outline order, numbers figures, embeds images, writes HTML and prints to PDF through headless Chrome).
6. Validate: `python3 tools/build_manual.py --check` and `python3 tools/check_doc_links.py`; fix until clean; write `MANUAL_VALIDATION.md`.
7. Report in the final message: chapter list with word counts, figure count by status, validation results, claims left unsourced, and the paths of the HTML/PDF.

## FINAL RESPONSE FORMAT

A. Manual structure (chapters, pages/words). B. Figures (count by status, rendered vs reused). C. Validation results (commands + PASS/FAIL). D. Unsourced or ambiguous items left in the text (with the exact phrase). E. Paths of all deliverables.

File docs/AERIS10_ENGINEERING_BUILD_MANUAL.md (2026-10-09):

# AERIS-10 — Engineering Reconstruction, Build Preparation & Documentation Manual

Version 1.4 — 2026-10-09 (1.3: beta completions; 1.2: proposed designs; 1.1: drawings package; 1.0: 2026-10-08). Produced from the repository `PLFM_RADAR` as found (original content dated 2026-03-14), without modifying any original file. Every statement cites repository evidence or an executed command; items that could not be verified are marked UNRESOLVED / REQUIRES VERIFICATION. The authoring environment had Python 3.14.7, Icarus Verilog 13.0, Verilator 5.052, and — from version 1.1 — KiCad 10.0.6 (kicad-cli), Graphviz 16.1 and Google Chrome (headless, for SVG→PDF/PNG); no Vivado, ARM toolchain or EAGLE. Nothing was synthesised, compiled for the target or tested on hardware; CAD exports were produced through a KiCad conversion of the EAGLE files (Part XI), not by EAGLE itself.

**Readiness in one sentence:** the repository is a documented design study with schematics for four boards, partially routed layouts, non-building FPGA RTL, non-building STM32 firmware, one offline-runnable Python demo, and no mechanical design. No subsystem can be built reproducibly today; the blockers, their evidence and the recovery procedures are enumerated in this manual and its companion documents.

Companion documents (all under `docs/`):

| File | Content |
|---|---|
| `01_REPOSITORY_INVENTORY.md` | 482-row file inventory with status |
| `02_DEPENDENCY_MAP.md` | source → output graphs per subsystem |
| `03_MISSING_COMPONENTS.md` | register with ID / evidence / impact / recovery / priority |
| `04_RECOVERY_TASKS.md` | task tracker (7 done, 20 open, 9 blocked) |
| `05_TRACEABILITY_MATRIX.md` | requirement ↔ evidence ↔ artefact |
| `FPGA/FPGA_PROJECT_RECONSTRUCTION.md` | RTL/XDC analysis, pin map, Vivado procedures |
| `STM32/STM32_PROJECT_RECONSTRUCTION.md` | firmware analysis, `.ioc` reconstruction, build procedures |
| `PCB/00_COMMON_EAGLE_PROCEDURES.md`, `PCB/MAIN_BOARD.md`, `PCB/POWER_SUPPLY.md`, `PCB/RF_PA.md`, `PCB/FREQUENCY_SYNTHESIZER.md` | per-board manufacturing readiness |
| `BOM/README.md` + `BOM_*.csv/.md` | bills of materials extracted from the schematics |
| `SYSTEM/BLOCK_DIAGRAM.md` | verified block diagram and inter-board connector matrix |
| `GUI/INSTALLATION.md`, `GUI/DEPENDENCIES.md` | Python environment and dependency analysis |
| `MECHANICAL/MECHANICAL_GAP_ANALYSIS.md`, `MECHANICAL/ASSEMBLY_DOCUMENTATION_REQUIREMENTS.md`, `MECHANICAL/drawings/*.svg` | mechanical evidence, gaps, PCB outline drawings |
| `TESTING/VALIDATION_PLAN.md`, `TESTING/ACCEPTANCE_CRITERIA.md` | tests with executed results; acceptance status |
| `../engineering/` (`DRAWING_REGISTER.md`, `MISSING_DRAWINGS_RECOVERY_PLAN.md`, `SYSTEM/`, `ELECTRICAL/`, `PCB/`, `MECHANICAL/`, `ASSEMBLY/`, `SOFTWARE_DIAGRAMS/`, `VALIDATION/`) | engineering drawings and CAD package (Part XI) |

---

# Part I — Project Overview

## I.1 Architecture (as evidenced)

AERIS-10 is a 10.5 GHz pulsed-LFM phased-array radar (README). The CAD shows four PCBs and off-board modules; the data flow is: AD9523 clock generator (Synth board) → ADF4382 LOs → LTC5552 mixers (Main) ← AD9708 DAC ← FPGA chirp LUT; receive ADTR1107 ×16 → ADAR1000 ×4 beamformers → mixer → AD8352 IF amps → AD9484 8-bit 400 MSPS ADC → FPGA (DDC, CIC, FIR, matched filter, Doppler) → host. The STM32F746ZGT7 sequences 16 power rails, programs AD9523/ADF4382/ADAR1000/DAC5578/ADS7830, reads GPS/IMU/barometer/temperatures, drives a stepper and talks to the host over USB-FS CDC. See `docs/SYSTEM/BLOCK_DIAGRAM.md` for the verified diagram and the connector matrix.

## I.2 Subsystems and their state

| Subsystem | Location | State (evidence) |
|---|---|---|
| FPGA RTL | `9_Firmware/9_2_FPGA/` (25 `.v`, 8 `.mem`, 1 `.xdc`) | does not parse (`radar_system_top.v:312`); 6 missing modules/IP; XDC 100 % placeholders; device contradiction (XC7A50T CAD vs XC7A100T docs) |
| STM32 firmware | `9_Firmware/9_1_Microcontroller/` (136 files) | application sources only; no `.ioc`, linker, startup, HAL, USB middleware, build system; 7 functional defects incl. HSE 8 vs 25 MHz |
| Python GUI | `9_Firmware/9_3_GUI/` (9 versions) | V5 complete for hardware; V6 (documented as current) is a stub; V6_Demo runs offline; no tests |
| Main Board | EAGLE 7.4.0, 260 × 300 mm, 10 Cu | 2 390 airwires, 11 parts off-board, 211 approved DRC; FT601 unconnected |
| Power Supply | sch 9.6.2 / brd 7.4.0, 280 × 300 mm, 2 Cu | 309 airwires, 132 parts off-board |
| RF PA | 9.6.2, 35 × 60 mm, 4 Cu | routed, no outputs |
| Frequency Synthesizer | 9.6.2, 100 × 100 mm, 6 Cu | routed; P&P + MPN-less BOM; no Gerbers |
| Mechanical | — | no CAD at all; README references to `10_docs/` are dead |
| Documentation | `00_notation … 04_research`, `.planning` | extensive, but derived from RTL/firmware and repeats the XC7A100T error |

## I.3 Repository map

See `docs/01_REPOSITORY_INVENTORY.md` (generated). Top level: `1_Project_Description` (docx), `2_Functional Diagram…` (drawio/dwg/jpg), `3_Power Management` (xlsx), `4_Schematics and Boards Layout` (EAGLE + partial production files), `5_Simulations` (Qucs, openEMS, KiCad filter export), `6_Application Notes`, `7_Components Datasheets…` (44 PDFs), `8_Utils` (photos, Python utilities), `9_Firmware` (STM32, FPGA, GUI), `00_notation`–`04_research` and `research/` (engineering docs), `.planning` (process records). Added by this reconstruction: `docs/`, `tools/`, `9_Firmware/9_2_FPGA/reconstructed/`, `9_Firmware/9_1_Microcontroller/reconstructed/`, `9_Firmware/9_3_GUI/requirements.txt`, `pyproject.toml`.

## I.4 Toolchains

| Subsystem | Required | Evidence of version used originally |
|---|---|---|
| FPGA | AMD Vivado (2020.2+; FFT IP v9.1) | none; `$readmemh` path names an ISE project (`chirp_memory_loader_param.v:3`) |
| STM32 | STM32CubeIDE/CubeMX + STM32CubeF7, GNU Arm Embedded | generated-file headers © 2025 (CubeMX ≥ 6.x), exact version unknown |
| GUI | CPython ≥ 3.10 with Tk; packages in `requirements.txt` | none; tested on 3.14.7 |
| PCB | EAGLE 9.6.2 (or Fusion 360 Electronics / KiCad import) | file headers 7.4.0 and 9.6.2 |
| Simulation | QucsStudio 5.8, openEMS, MATLAB/Octave | file headers |

---

# Part II — Environment Preparation

| Item | Procedure | Verification |
|---|---|---|
| OS | macOS 13+/Linux/Windows 10+ for Vivado (Linux/Windows only), CubeIDE, EAGLE, Python | — |
| Python | GUI-T01/T02 (`docs/GUI/INSTALLATION.md`) | `tools/check_python_imports.py --try-import` all OK (executed) |
| Open-source RTL tools | `brew install icarus-verilog verilator` (done on the authoring machine) | `tools/fpga_lint.sh` runs |
| Vivado | install ML Standard (Artix-7 in free list) | `vivado -version` |
| STM32 | STM-T01 | `tools/stm32_check_cube_package.sh <CubeF7>` exit 0 |
| EAGLE/KiCad | install; EAGLE 9.6.2 needed for the 9.6.2 files | opens `Clocks_Freq_Synth_board.sch` |
| Version compatibility | EAGLE 7.4 cannot open 9.6.2 files; KiCad importer approximates DRU; filterpy (2018) vs numpy 2 untested at runtime | documented in subsystem docs |
| External dependencies | STM32CubeF7, UNISIM, FFT IP, libusb, FTDI D3XX (only if FT601 is retained) | — |

---

# Part III — FPGA Project Preparation

Full detail: `docs/FPGA/FPGA_PROJECT_RECONSTRUCTION.md`.

**Missing configurations:** device/package/speed (CAD: `xc7a50tftg256-2`); every PACKAGE_PIN; three clock input constraints; FFT IP (`xfft_32`, `FFT_enhanced`); three RTL modules; `long_chirp_seg3_*.mem`; project file.

**Project reconstruction:** FPGA-T01 (part) → FPGA-T02 (`vivado -mode batch -source tools/vivado/create_project.tcl -tclargs xc7a50tftg256-2`) → FPGA-T03 (6 syntax/declaration edits) → FPGA-T04 (recover modules/IP, fix `.mem` paths) → FPGA-T05 (xsim) → FPGA-T06/T07 (synthesis, implementation, bitstream prerequisites).

**Source integration:** 23 synthesisable files (all `.v` except `radar_system_tb.v` and the module-less `chirp_lut_init.v`), `.mem` files as Memory Files, constraints = timing part of `cntrt.xdc` + `reconstructed/radar_system_top_schematic_derived.xdc` (64 ports mapped from the schematic with confidence levels; 25 ports UNRESOLVED because the FT601 is not wired and status/debug outputs have no nets).

**Static verification performed:** iverilog/verilator FAIL at `radar_system_top.v:312`; after scratch patches: 6 missing modules, 9 use-before-declare errors, 207 lint warnings (4 MULTIDRIVEN, 14 UNDRIVEN). `tools/check_fpga_constraints.py`: 142 placeholders, 180/180 bits unassigned. No test PASSED.

**Design-level findings that block function even after the build is repaired:** 400 MHz ADC capture not implemented (`lvds_to_cmos_400m.v:35-43`); level shifter never instantiated (ADAR1000 SPI dead); receiver controls undriven; fixed-threshold "CFAR"; bank-14 LVDS inputs on a 3.3 V bank with `DIFF_TERM`; LVCMOS33 assigned to 1.8 V bank-34 signals; no clock groups.

---

# Part IV — STM32 Firmware Preparation

Full detail: `docs/STM32/STM32_PROJECT_RECONSTRUCTION.md`.

**Project reconstruction:** STM-T01 (CubeIDE + CubeF7) → STM-T02 (regenerate `.ioc` from the verified peripheral/pin/clock tables: I2C1/2/3, SPI1/4, UART5, USART3, TIM1, OTG_FS CDC, 60 GPIO macros — all confirmed against schematic U2 nets) → STM-T03 (build-set cleanup: `.H` headers, excluded files, defines) → STM-T04 (7 defects) → STM-T05 (compile/link/size) → STM-T06 (hardware verification).

**Middleware integration:** USB Device Library Core + CDC from CubeF7; CubeMX-generated `usb_device.c`, `usbd_cdc_if.c` (must forward RX to `usbHandler.processUSBData()` in USER CODE — the repository's `main.cpp:328-339` callback is never bound), `usbd_conf.c`, `usbd_desc.c` (VID/PID unknown).

**Toolchain configuration:** `-DSTM32F746xx -DUSE_HAL_DRIVER`, Cortex-M7 FPv5-SP hard-float (ASSUMED CubeIDE defaults); `reconstructed/CMakeLists.txt` provided, UNVERIFIED.

**Build verification:** checklist in STM32 doc §6; current status: includes check FAIL (53 absent headers — expected until CubeF7 is added), no target build attempted.

**Unresolved:** HSE 8 MHz (board) vs 25 MHz (firmware) — PLL cannot lock as coded; ADF4382 pin macros collide with PA enables; ADF4382 SPI `platform_ops = NULL` → `Error_Handler`; USB RX dead; start-flag padding; `GPS_Init` never called; AD9523 CS never toggled; SPI at 36 MHz vs 10 MHz requested.

---

# Part V — Python Application

Full detail: `docs/GUI/INSTALLATION.md`, `docs/GUI/DEPENDENCIES.md`.

**Dependencies:** numpy, scipy, matplotlib (TkAgg), scikit-learn, filterpy, crcmod, pyusb (+libusb), pyftdi, pandas (CSV replay), tkinterweb (V5_Demo only). Generated `requirements.txt` (tested versions annotated; lower bounds UNVERIFIED) and `pyproject.toml` (entry points `aeris10-gui` → `GUI_V6:main`, `aeris10-gui-demo` → `GUI_V6_Demo:main`).

**Installation:** GUI-T01/T02 executed in a scratch venv: all packages installed and import-tested on Python 3.14.7.

**Configuration:** no config files; Google Maps API key placeholder in V4–V6; USB VID/PID for FTDI only (FT2232H 0403:6010 in V2–V5; FT601 0403:6030/6031 in V6, unsupported by pyftdi); STM32 CDC opened by raw bulk endpoints (platform-problematic).

**Offline validation:** `GUI_V6_Demo.py` is the only hardware-free runnable program (module import verified; window launch NOT executed). `GUI_V4_2_CSV.py` + `test_radar_data.csv` verified consistent (synthetic data). `GUI_V6.py` and `GUI_V5_Demo.py` cannot run (stubs / missing methods); `GUI_V1.py` is a fragment with a syntax error.

**Protocol:** GUI ↔ firmware settings packet consistent (82 B big-endian); start-flag padding breaks firmware parsing; FPGA packet format differs from every GUI parser; GPS text format mismatch. Documentation (`04_usb_protocol.md`) wrong on endianness and MCU family.

---

# Part VI — PCB Manufacturing Package Preparation

Full detail: `docs/PCB/*.md`, `docs/BOM/README.md`.

**CAD inspection (executed on XML):** formats/versions, sheet/part/net counts, routing completeness (airwires), approved DRC/ERC, layer setup, DRU parameters, outlines and holes, connector/net maps, sch/brd consistency — tabulated per board.

**Output generation:** executed on 2026-10-09 through KiCad 10 (`tools/kicad_pcb_pipeline.sh`): Gerber X2, Excellon PTH/NPTH + maps, layer/assembly/outline PDFs, per-layer SVG, DXF, STEP, P&P, IPC-2581, IPC-D-356, DRC (rules from the EAGLE DRU) and 3-D renders for all four boards → `engineering/PCB/<BOARD>/` (README with hole table, cross-check and checklist; `STACKUP.md`). The EAGLE-native path (P-EAGLE-01..09, P-KICAD-01 in `00_COMMON_EAGLE_PROCEDURES.md`) remains the authoritative export and is still not executed. Main/Power packages are PARTIAL (unfinished routing: 15 / 308 unconnected items after pour fill).

**BOM preparation (executed):** `tools/gen_eagle_bom.py` → 776 / 312 / 25 / 184 references in 98 / 28 / 11 / 40 lines; **0 MPN attributes on any board**; 244 / 80 / 6 / 47 references without value. Validation procedure in `docs/BOM/README.md`. System-level items (GPS, IMU, barometer, TMP37 ×8, stepper + TB6600-class driver, slip ring, fans, antenna, enclosure, cables) have no part numbers.

**Manufacturing checks:** `tools/check_manufacturing_files.py` FAIL for the designer-released folder (`4_Schematics and Boards Layout/4_7_Production Files/`: no Gerber/drill; Synth P&P + BOM only); with `--include-generated` (KiCad package) exit 0. `engineering/VALIDATION/PCB_CROSS_CHECK.md`: 32/32 EAGLE↔KiCad count checks OK. Stack-up unresolved for all boards (`Stack_Hybrid.png` 6-layer unlabeled vs DRU vs PCBWay note). README's "All Gerber files are available" is false.

---

# Part VII — Mechanical Documentation

Full detail: `docs/MECHANICAL/*.md`.

**Available design evidence:** PCB outlines and mounting holes from the `.brd` files (drawn in `docs/MECHANICAL/drawings/`; DXF/STEP/1:1 plan view/dimension sheets in `engineering/MECHANICAL/`): Main 260 × 300 mm / 8 × Ø3.2; Power 280 × 300 mm / 8 × Ø3.2 (hole pattern suggests a smaller final outline — UNRESOLVED); RF PA 35 × 60 mm / 7 × Ø3.2; Synth 100 × 100 mm / 4 × Ø3.2. Element spacing λ/2 ≈ 14.3 mm and 16-element aperture 214.3 mm (`02_hardware/04_antenna_beamforming.md:280,288`). Stepper 200 steps/rev, 50 azimuth positions (`main.cpp:189,195`).

**Missing models:** enclosure, antenna (two contradictory waveguide simulations, no patch CAD), pedestal/slip ring/stepper/fans, heatsinks, cables, 3-D PCB models, thickness and mass. `10_docs/assembly_guide.md` and `10_docs/Hardware/Enclosure` (README) do not exist.

**Required drawings:** A1–A11 list in `ASSEMBLY_DOCUMENTATION_REQUIREMENTS.md`; delivered: outline/dimension drawings, block/interconnection diagrams, CONCEPTUAL exploded view, parts list, assembly sequence (`engineering/ASSEMBLY/`); BLOCKED: enclosure, antenna, pedestal, cooling (guides MDR-01…05).

**Documentation requirements:** minimum content of the assembly guide (§2 of that document), exploded-view procedure (§3).

---

# Part VIII — Integration Dependencies

**Subsystem interface inventory:** `docs/SYSTEM/BLOCK_DIAGRAM.md` §2–3 (Power→Main/Synth rail connectors; Main↔Synth JP1/JP13 control + SMA clocks; Main↔PA 16 × bias/sense + 17 SMA pairs; Main↔host mini-USB; peripheral headers).

**Documentation gaps:** anonymous nets on 34 Main-Board SMAs and 16 PA connectors (assignment table must be produced from the schematic); cable lengths/gauges; LO SMA mapping; antenna feed transition.

**Configuration consistency:** eight open conflicts K1–K8 (FPGA part; HSE; host data path; PA supply; packet format; ADF4382 pins; Synth oscillators; antenna variant).

**Unresolved integration assumptions:** `clk_100m` is free-running (AD9523 OUT6) while the RTL crosses 400 MHz/4 samples into it without a phase relationship — sample drops/duplicates are expected unless the design is changed; the 3.3 V bank-14 LVDS inputs; whether the SPI1 pass-through through the FPGA was ever functional (level shifter not instantiated).

---

# Part IX — Test and Acceptance Procedures

`docs/TESTING/VALIDATION_PLAN.md` lists 10 FPGA, 10 STM32, 9 Python, 9 PCB and 3 repository tests with type (design check vs physical), command, tool availability and executed result; `ACCEPTANCE_CRITERIA.md` gives 41 objective criteria.

**Executed and PASSED:** P-01 dependency install, P-03 import test, P-08 demo-data consistency, B-03 embedded libraries, B-07 outline extraction, F-05 pin-map generation (generation only), S-07 GPIO macro cross-check (with two conflicts found), R-01 inventory.

**Executed and FAILED (expected, documenting the state):** F-01..F-04 (RTL parse/elaborate/lint/constraints), S-01 (includes), P-02 (GUI_V1 syntax), B-04 (Main/Power consistency), B-05 (BOM MPN), B-06 (manufacturing files), R-02 (doc links), R-03 (manifest: 25 P0 items missing).

**Not run (tools/hardware unavailable):** Vivado synthesis/timing/bitstream, xsim, ARM build, EAGLE ERC/DRC/CAM, GUI window launch, all physical tests.

**Evidence collection:** logs under `build/` (lint logs produced), test IDs referenced in reports; physical tests require instrument records.

Run everything: `bash tools/run_all_checks.sh` → currently 7 of 8 checks FAIL, 1 PASS (inventory).

---

# Part X — Final Readiness Report

## X.1 Completed items (this reconstruction)

- Documentation tree per specification + `docs/BOM`, `docs/SYSTEM`, `docs/PCB/00_COMMON_EAGLE_PROCEDURES.md`.
- 11 validation/generation scripts in `tools/` + `tools/vivado/create_project.tcl` (non-destructive; exit codes; stdlib only).
- Schematic-derived FPGA pin map (64/67 ports) and candidate XDC.
- BOMs for four boards; PCB outline/hole drawings; connector matrix; block diagram.
- Python `requirements.txt` / `pyproject.toml`, verified by installation.
- STM32 `.ioc` content reconstruction tables; Cube package checker; CMake template (unverified).
- **Version 1.1:** engineering drawings package `engineering/` — 73 registered drawings (39 SOURCE-DERIVED, 28 PARTIAL, 1 CONCEPTUAL, 5 BLOCKED), 13 additional generator/validation scripts (29 in `tools/` total). See Part XI.

## X.2 Missing items (P0, from `03_MISSING_COMPONENTS.md`)

FPGA: parseable RTL, pin-complete XDC, project, 3 RTL modules, 2 FFT IP, seg3 `.mem`, portable paths, device decision, ADC capture structure, multi-driven registers, level shifter, host data path (12). STM32: `.ioc`, linker, startup, build system, 4 USB files, HAL, CMSIS, HSE conflict, ADF4382 pins, ADF4382 SPI ops, USB RX (14 entries). PCB: Gerber/drill/BOM for 4 boards, two unfinished layouts, stack-ups (11). Total P0: 37 register entries; manifest check reports 25 missing P0 file patterns.

## X.3 Blockers (cannot be resolved from repository content)

1. FPGA part number (XC7A50T-2FTG256I vs XC7A100T).
2. Original FPGA project (missing modules, FFT IP, `.mem` generator, seg3 files, authoritative TX LUT).
3. STM32 HSE crystal (8 vs 25 MHz) and board revision.
4. Host data path architecture (FT601 unwired).
5. Main and Power Board layout completion; stack-ups for all boards.
6. All mechanical design data (enclosure, antenna, pedestal, part numbers).
7. PA supply architecture (22 V rail) and Synth oscillator topology.

## X.4 Open technical questions

Listed per subsystem: FPGA doc §8 (6 items), STM32 doc §5 (10 items), PCB docs §"open items", Mechanical gap analysis §7 (5 items), Block diagram §4 (K1–K8).

## X.5 Recommended next engineering actions (ordered, with dependencies)

1. **R-SYS-01, R-FPGA-01, R-STM-05, R-PCB-06** — architecture/designer decisions (host link, FPGA part, HSE, stack-ups). Everything else depends on these.
2. **R-STM-01..03** — toolchain + CubeMX regeneration + build-set cleanup → first firmware build (independent of hardware).
3. **R-FPGA-03..06** — syntax fixes, Vivado project, module/IP recovery, `.mem` → first elaboration.
4. **R-PCB-03, R-PCB-04, R-PCB-05** — export RF PA and Synth production packages; complete BOMs with MPNs (can proceed in parallel with 2–3).
5. **R-STM-04, R-STM-06, R-STM-07** — firmware functional fixes → bench test with the GUI (needs 2).
6. **R-FPGA-07..10** — functional RTL redesign (ADC capture, CDC, single drivers, CFAR), constraints, testbench, synthesis → bitstream (needs 1, 3).
7. **R-PCB-01, R-PCB-02** — finish Main and Power layouts (needs 1), then export.
8. **R-GUI-01..03** — consolidate GUI, tests, packaging (needs 1 for protocol).
9. **R-MECH-01, R-MECH-02** — obtain CAD, write assembly guide, exploded view (needs 7 for board outlines).
10. **R-DOC-01..03** — README/LICENSE/.gitignore/links, datasheets, `STM32_ALGO.docx`.

## X.6 Completeness metric

Method: acceptance criteria MET ÷ total criteria (`docs/TESTING/ACCEPTANCE_CRITERIA.md`), and manifest items present ÷ manifest items (`tools/check_missing_files.py`).

| Metric | Value |
|---|---|
| Acceptance criteria MET | 5 / 41 = **12 %** (AC-P1, AC-P2, AC-M1, AC-D1, AC-D5) |
| Expected-artefact manifest present | 24 / 59 = **41 %** after v1.1 (documentation + GUI packaging + Synth P&P/BOM + 13 engineering-package entries); P0 present 1 / 26 — unchanged, because generated Gerbers are not the designer-released export |
| Documentation package of the specification | 20 / 20 files = 100 % (plus 8 extra) |
| Build-artefact completeness (bitstream, firmware image, GUI package, 4 manufacturing packages) | 0 / 7 = **0 %** designer-released; 2 / 4 manufacturing packages exist as generated KiCad conversions of routed boards (RF PA, Synth) and 2 as PARTIAL conversions of unfinished layouts |
| Engineering drawings (addendum §26) | 73 registered: 68 generated (39 SOURCE-DERIVED + 28 PARTIAL + 1 CONCEPTUAL), 5 BLOCKED; 0 VERIFIED |

These percentages measure verified reproducibility, not effort; the design-level defects found (Parts III–IV) mean that even with all missing files recovered, functional hardware is not established by any evidence in the repository.

---

# Part XI — Engineering Drawings & CAD Package (addendum §16–26, version 1.1)

Index: `engineering/README.md`. Register: `engineering/DRAWING_REGISTER.md` (73 drawings, statuses, missing data, file check 0 problems). Recovery guides: `engineering/MISSING_DRAWINGS_RECOVERY_PLAN.md` (MDR-01…MDR-11). Validation: `engineering/VALIDATION/{DRAWING_CHECKS,CAD_EXPORT_LOG,PCB_CROSS_CHECK,UNRESOLVED_GEOMETRY}.md`.

## XI.1 Electrical schematics (§16)

| Deliverable | Location | Status |
|---|---|---|
| Editable native schematics | the EAGLE `.sch` files (unchanged masters); KiCad twins not created (GUI-only import, MDR-10) | present |
| SVG sheets + multi-page PDF + PNG, 7 sheets, title block with project/ID/rev/date/sheet/units/source/status | `engineering/ELECTRICAL/schematics/<BOARD>/` (`tools/render_eagle_schematic.py`, `tools/svg_sheets_to_pdf.py`) | SOURCE-DERIVED |
| Netlist (by net, by part), IPC-D-356 | `engineering/ELECTRICAL/netlists/<BOARD>_netlist*.csv`, `engineering/PCB/<BOARD>/ipc/*.d356` | SOURCE-DERIVED |
| Component-to-net report with connector pin-outs | `engineering/ELECTRICAL/connection_diagrams/<BOARD>_connection_report.md` | SOURCE-DERIVED |
| Unresolved-connection report (single-pin nets, open pins, sch↔brd parity, airwires) | `engineering/ELECTRICAL/netlists/<BOARD>_unresolved_connections.md` — Synth 5 single-pin nets / 34 open pins; Main 3 / 280 / 2 390 airwires; Power 0 / 24 / 309; PA 0 / 0 | needs designer disposition |
| Missing-symbol / footprint report | `engineering/ELECTRICAL/netlists/<BOARD>_missing_symbols_footprints.md` — none missing on any board | MET |

## XI.2 System architecture diagrams (§17)

SYS-01 block diagram (DOT + Mermaid), SYS-02 interconnection diagram + table (every connector/cable, pins where the symbols carry them, CBL-IDs proposed), SYS-03 signal/data flow (frequencies = firmware intent), ELEC-PWR-01 power distribution + 36-rail register; SD-01…SD-07 software diagrams (auto-generated FPGA hierarchy and Python module graph; hand-authored pipeline, STM32, USB CDC, GUI runtime, end-to-end flow). All DOT files are editable; SVG/PDF/PNG rendered with Graphviz. New findings from this work: 15 (not 16) enable lines on SV1; firmware never asserts the ADTR/PA/5V5 enables; U30 ADM7151 input from VIN; `+1V8_CLOCK` needed by two boards from one output; J22/J23 are the LO inputs.

## XI.3 PCB fabrication and assembly drawings (§18)

Per board, the 15 items of §18 are tabulated in `engineering/PCB/<BOARD>/README.md` §1 with file names and status. Stack-up: layer order and copper from the DRU; materials/thickness/finish/impedance BLOCKED — MISSING DATA (`STACKUP.md`). Every file identifies its source board file and the absence of a source revision. DRC results (KiCad, DRU-derived rules): RF PA 48, Synth 639, Main 912 + 15 unconnected, Power 160 + 308 unconnected — dispositions pending.

## XI.4 Mechanical (§19) and exploded views (§20)

Generated from verified geometry: outline + hole DXF (two independent sources, EAGLE XML and KiCad), board-only STEP (thickness ASSUMED 1.6 mm), 1:1 plan view, dimension sheets with hole tables, pitch and mass ESTIMATES. CONCEPTUAL only: exploded view ASM-EXP-01 (balloons ↔ `PARTS_LIST.md`), assembly sequence (electrical order SOURCE-DERIVED, mechanical steps CONCEPTUAL). BLOCKED: enclosure, internal layout, antenna, cooling, pedestal — no geometry exists; guides MDR-01…MDR-06 state exactly what must be decided and how to produce the drawings in FreeCAD/KiCad.

## XI.5 Standards and status vocabulary (§22)

Title blocks carry project, drawing ID, revision, date, sheet, units, scale, source and status (ISO 7200 fields); no standards compliance is claimed. No drawing is VERIFIED: nothing was compared with an EAGLE/vendor output or with hardware (MDR-11).

## XI.6 Final drawings report (§26)

| Item | Value |
|---|---|
| Drawings identified as required | 73 registered (+ the 15-item §18 list per board inside each PCB README) |
| Existing drawings found | drawio/jpg/dwg block diagram, unlabelled stack-up PNG, Synth P&P + BOM, photos, first-pass outline SVGs — none dimensioned |
| Generated from verified evidence (SOURCE-DERIVED) | 39 |
| Partially reconstructed (PARTIAL / CONCEPTUAL) | 28 + 1 |
| Blocked by missing source information | 5 (enclosure, internal layout, antenna, cooling, pedestal) |
| Native editable files created | 11 DOT, 1 Mermaid, 4 `.kicad_pcb` + `.kicad_pro`, 16 DXF, 8 STEP, 78 SVG (schematics, layers, mechanical, exploded), 16 CSV, 4 Gerber job sets |
| PDF/SVG/PNG exports | 53 PDF, 78 SVG, 32 PNG |
| CAD validation | export log 0 failed steps (final run); EAGLE↔KiCad cross-check 32/32; register file check 73 drawings / 0 problems; DRC executed (not passed) |
| Remaining engineering decisions | K1–K8 (part, HSE, host link, PA supply, packet format, ADF4382 pins, oscillators, antenna) + G-01…G-12 geometry + MPNs + stack-ups |

---

# Part XII — Proposed Designs for the Missing Elements (version 1.2)

The BLOCKED drawings of Part XI (enclosure, internal layout, antenna, cooling, pedestal) and conflict K4 (22 V PA supply) now have **PROPOSED DESIGNS** under `engineering/DESIGN/` (index `engineering/DESIGN/README.md`, basis and decision log `00_DESIGN_BASIS.md`, parameters `design_parameters.json`). They are new engineering content derived from the verified constraints (board outlines/holes, connector positions from the P&P files, firmware timing and scan geometry, QPA2962/RO4350B datasheets) plus fifteen logged decisions D-01…D-15; nothing was simulated on hardware, built or measured. Register IDs DSN-* (11 entries, status PROPOSED DESIGN).

| Element | Proposal | Native file | Key result | Must be confirmed |
|---|---|---|---|---|
| Antenna (DSN-ANT-01) | 16 horizontal rows × 8 series-fed patches, 14.3 mm row pitch, RO4350B 0.508 mm, end-launch 2.92 mm per row, equal-length feeds | `engineering/DESIGN/ANTENNA/kicad/aeris10_patch_array.kicad_pcb` | patch 9.35 × 7.30 mm, panel 165 × 248 mm, est. ≈ 25 dBi, HPBW ≈ 6.3° (el) / 10° (az) | openEMS run (`openems_patch_row.py`), coupon measurement, B (bandwidth) |
| Thermal (DSN-THM-01) | per-chirp drain gating → 68 W average (vs 591 W as coded); 300 × 300 × 10 Al spreader with 2 fin fields, 2 × 60 mm fans, ≥ 16 CFM | `engineering/DESIGN/THERMAL/THERMAL_AND_PA_SUPPLY.md` | PA base ≈ 66 °C at 45 °C ambient | PA-board via-field Rth, fan parts |
| 22 V PA supply (DSN-PSU-01) | 2-phase boost 12–17 → 22 V, LM5069 hot-swap enable from `EN/DIS_RFPA_VDD`, 16 × LTC7003/N-FET pulse gates from a `TX_GATE` line, ≥ 2.7 mF bulk | `engineering/DESIGN/ELECTRICAL/PA_SUPPLY_22V/DSN-PSU-01_block_schematic.svg` | 45.6 A pulsed / 3.5 A average | FPGA spare pin for `TX_GATE`, KiCad capture (MDR-12) |
| Radar head (DSN-MECH-3D, -01…-04) | 315 × 315 × 133 mm folded-Al chassis; all boards vertical behind the antenna: antenna → PA plate → 16 PA (4 × 4) → Main → Synth → Power; radome window; side cooling ducts | `engineering/DESIGN/MECHANICAL/CAD/aeris10_head_pedestal.FCStd` (+ STEP/STL/DXF) | mass ESTIMATE ≈ 9.9 kg (envelopes as solids) | component heights (D-07), fasteners, sealing |
| Pedestal (DSN-MECH-05) | 360 × 360 × 130 mm base, slewing bearing OD190/ID100, 1:3 GT3 belt to a NEMA 23, 12-circuit through-bore slip ring | same FCStd | needs `Stepper_steps = 600` in `main.cpp:195` | part selection, mast interface, driver location |
| Harness (DSN-HAR-01) | 144 cables with proposed lengths (≈ 42 m) from connector positions | `engineering/DESIGN/HARNESS/harness_schedule.csv` | — | rail pairs not matched by net name; first fit |

Regeneration: see `engineering/DESIGN/README.md`. Tools added: `tools/design_antenna_array.py`, `design_thermal.py`, `design_pa_supply_schematic.py`, `design_layout.py`, `design_mechanical_freecad.py`, `design_mechanical_drawings.py`, `stl_to_svg_iso.py` (FreeCAD 1.1 installed in `~/Applications` for the 3-D model).

---

# Part XIII — BETA Completions (version 1.3)

Everything that was missing now exists at least in a BETA state under `beta/` (index `beta/README.md`; each sub-project has `README.md` + `CHANGELOG.md`; originals untouched). BETA = builds/simulates/routes/tests on this machine; **not** synthesised in Vivado, flashed, fabricated, measured, or reviewed by the original designer. Repository: `https://github.com/herasymyuks/PLFM_RADAR-aeris` (all work pushed).

| Sub-project | What exists now | Verified by (executed) | Still open |
|---|---|---|---|
| `beta/fpga` | RTL copies with syntax/driver fixes; 5 missing modules written (FFT-domain matched-filter chain, range-bin decimator, FFT wrappers with behavioural core + IP settings); seg3 `.mem` generated (the `.mem` files proved to be conj-FFT references); **ADC capture redesigned with ISERDESE2 1:4 (BUFIO/BUFR, IDELAYE2 calibration FSM, MMCM 200 MHz ref) and a bit-exact 4-phase polyphase DDC/CIC at 100 MHz** (`ADC_CAPTURE_MODE`, legacy 400 MHz path kept selectable); SPI host bridge integrated; timing + schematic-derived XDC with datasheet input delays; Vivado Tcl | `beta/fpga/build.sh`: iverilog elaboration (sim + synth views) PASS, verilator 0 errors, 9 testbench runs PASS: FFT wrappers, matched filter, decimator, ISERDES capture (8/8 lanes locked, skewed lane compensated), DDC 4× vs legacy max diff 0 LSB, host bridge (unit + top), system smoke in both capture modes | Vivado synthesis/timing, ISERDES bit-order/BITSLIP check on hardware (PN9), IDELAYCTRL placement, BUFR↔clk_100m phase, matched filter not pipelined, FFT IP generation, register write path from the host, bank-14 LVDS on 3.3 V |
| `beta/stm32` | CMake project with Arm GNU 14.2 + STM32CubeF7 (pinned sparse clone), hand-written CubeMX-equivalent USB CDC/startup/linker/HAL conf, 11 defect fixes (incl. 2 newly found AD9523 init bugs), hardware-truth decisions (8 MHz HSE clock tree, ADF4382 pins, power-enable sequencing), host-link bridge driver | `beta/stm32/build.sh` exit 0 (FLASH 92 KB, RAM 17 KB); host tests 4/4 (settings parser incl. padded frames, beam matrix, AD9523 register table, I2C timing) | CubeMX regeneration, flash + bring-up, ADAR1000 `VM_*` tables empty in the original, production VID/PID |
| `beta/gui` | `aeris10_gui` package: firmware-exact settings packet, RTL packet parser, bridge-frame parser, CDC I/O, CA-CFAR/DBSCAN/Kalman, simulator in RTL format, Tk UI, PyInstaller app | `pytest -q`: 55 passed; `--selftest` exit 0; PyInstaller `dist/aeris10-gui --demo --selftest` exit 0 | hardware CDC test, hardware source switch to bridge frames, Windows/Linux packaging |
| `beta/pcb` | KiCad completion of the four boards: Main 15 → 0 unconnected (arc stubs, +3V3_FT cluster placed/routed, polygon-net dispositions), RF PA 1 → 0, Power 308 → 89 (132 parts placed, Freerouting 2.5.0, GND plane), Synth DRC disposition; BOMs with proposed MPNs (HIGH/MEDIUM/LOW/EMPTY counts per board); `FAB_NOTES.md` with PCBWay stack-ups and measured impedance widths; full re-exported packages | DRC reports per board (`exports/reports/`), export logs exit 0 | Power Board 89 pour-to-pour connections (manual), Main U69/U7 paddle nets + BPF2 polygons (schematic fix), 0201 silkscreen density, stack-up/MPN sign-off |
| `engineering/DESIGN/HOST_LINK` (DSN-LINK-01) | FPGA→host path: option A FT601 pin plan on the 50 free bank-35 pins (+ XDC, parts to add for Main Board rev. B); option B SPI bridge over the already-routed DIG_5/6/7 + SPI1 lines: RTL packer + SPI slave, STM32 driver (integrated, builds), GUI parser (tested on the RTL vector) | iverilog `PASS tb_host_bridge`, verilator clean, firmware build exit 0, pytest 9 passed | bridge integration into the beta top (in progress), bench SPI/CDC test, Main Board rev. B |
| `engineering/DESIGN/ANTENNA` | openEMS built from source; one-row FDTD run and tuning loop | S11 −18 dB at 10.5 GHz, contiguous −10 dB band only ≈ 128 MHz (comb response), row directivity 11.5 dBi | feed topology if B > ~100 MHz; 16-row coupling; coupon measurement |
| `engineering/DESIGN/MECHANICAL` (detail) | 51-part FreeCAD model (tray with flanges, front plate, lid, window stack, PA plate with tapped holes and brackets, carrier rails, standoffs, gland plate; pedestal plates, bearing, pulleys, slip ring, motor bracket, mast flange); flat patterns with bend allowance; assembly section with fasteners; parts list with fastener totals | model builds; register file check 0 problems | bend reliefs/welds, lid stiffening, part numbers, sealing test |

Tooling installed on the authoring machine for this phase (all user-level): KiCad 10.0.6, FreeCAD 1.1.4, openEMS (source build, `~/opt/openEMS`), Arm GNU Toolchain 14.2 (tarball), OpenJDK 27 + Freerouting 2.5.0, Graphviz, poppler.

---

# Part XIV — Complete Illustrated Manual (version 1.4)

The complete engineering & assembly manual compiled from this reconstruction (22 chapters, 69 figures, 191 pages; authored by Antidrone Ukraine · antidrone.cc) is `manual/AERIS10_MANUAL.md` with rendered `manual/build/AERIS10_MANUAL.pdf` / `.html`; build kit and validation in `manual/` (`MANUAL_BUILD_SPEC.md`, `00_OUTLINE.md`, `FIGURE_LOG.md`, `MANUAL_VALIDATION.md`).

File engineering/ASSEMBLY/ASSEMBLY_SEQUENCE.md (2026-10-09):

# AERIS-10 — Assembly and integration sequence

| Field | Value |
|---|---|
| Project | AERIS-10 |
| Document | ASM-SEQ-01 |
| Revision | A |
| Date | 2026-10-09 |
| Status | **PARTIAL** — electrical integration order is SOURCE-DERIVED (connector matrix + firmware power sequence); mechanical steps are CONCEPTUAL because no enclosure/antenna/pedestal design exists |

Nothing in this sequence has been executed on hardware. Steps marked ⚠ depend on a design decision that is still open (conflicts K1–K8 in `docs/SYSTEM/BLOCK_DIAGRAM.md`).

## A. Pre-assembly inspection checkpoints (per PCB assembly)

| CP | Check | Acceptance | Evidence/tool |
|---|---|---|---|
| CP-1 | Bare board matches outline and hole table | dimensions per `engineering/MECHANICAL/dimensions/<BOARD>_dimensions.md`, ±0.2 mm (vendor tolerance UNSPECIFIED) | caliper; fab CoC |
| CP-2 | Assembled board matches BOM + pick-and-place | every reference populated with the BOM value; polarity per `drawings/<BOARD>_assembly_top.pdf` | AOI / visual |
| CP-3 | No shorts between rails | > 1 kΩ between every rail and GND before power-up (rail list `engineering/ELECTRICAL/power_distribution/power_rails.md`) | DMM |
| CP-4 | Power Board rails at nominal with no load | each X2..X35 output within the net-name voltage (currents UNKNOWN) | bench PSU + DMM |

## B. Electrical integration order (bench, no enclosure)

1. **Power Board alone** — apply VIN (12–17 V per xlsx) through X1; verify CP-4. ⚠ U30 ADM7151 input from VIN needs design review (`power_rails.md` §4).
2. **Main Board ↔ Power Board** — connect the 20-way enable bus SV1↔SV1 (CBL-20) and the rail cables CBL-01..CBL-15 (Molex 22-23-2021, 2-pin, pin order of the `S` pads UNVERIFIED — buzz out before connecting). All rails are enabled only by the STM32, so nothing but the always-on rails should be present until firmware runs.
3. **Program the STM32** (SWD; firmware image MISSING today) and observe the enable sequence F0–F10 (`power_rails.md` §3): +1V8_CLOCK → +3V3_CLOCK → +1V0/+1V8/+3V3 FPGA → ADAR rails → switch rails. ⚠ HSE 8 MHz (board) vs 25 MHz (firmware) must be resolved first or the PLL will not lock.
4. **Frequency Synthesizer** — connect power X10..X15 (rails +3V3_XO, +3V3_CLOCK, +1V8_CLOCK, +3V3_LO_1, +3V3_LO_2, +5V0_LO) and control headers JP1↔Main JP1, JP2↔Main JP13 (CBL-30..); then SMA clocks Synth J7→Main J1 (FPGA 100 MHz), J5/J6→J20/J18 (DAC 120 MHz), J3→J21 (ADC 400 MHz), LO J10→Main J23 (TX), J11→J22 (RX) — table `interconnection_table.md` §5–6. Verify AD9523 lock and output frequencies with a counter (acceptance: 100 / 120 / 400 MHz ± 1 ppm, firmware intent `main.cpp:933-1072`).
5. **Program the FPGA** (bitstream MISSING; ⚠ part number XC7A50T vs XC7A100T) via JP3 JTAG; check the STM32↔FPGA handshake DIG_0..4 (PD8..PD12).
6. **RF PA boards (16)** — for each PA n: VG cable CBL-56+n from Main X_k (mapping X_7=VG_1 … X_10=VG_16 per `interconnection_table.md` §7 — PA-instance assignment UNDOCUMENTED, label cables on first build), sense cable to X3/X38..X52, 22 V drain from the external PA supply (⚠ K4). Bias-up per xlsx L58-L62: VG −4 V → VD 22 V → raise VG to IDQ 1.68 A. ⚠ Firmware never enables +5V5_PA / +5V0_PA_x / +3V3_ADTR as coded (`power_rails.md` §3) — fix before this step.
7. **RF interconnect** — Main J24..J55 ↔ PA J1/J2 (which SMA of each pair is RFIN vs RFOUT is UNVERIFIED — determine from the Main Board switch RF_SW_n routing before cabling). Terminate unused ports with 50 Ω.
8. **Host link** — mini-USB X53 → PC; GUI_V5 enumerates CDC; send settings packet (⚠ firmware RX callback never bound, defect C4). Radar data path FPGA→host does not exist (FT601 unwired, K3).
9. **Antenna** — ⚠ no design; connect only after an antenna/feed design exists.

## C. Mechanical assembly (PROPOSED — detailed parts in `engineering/DESIGN/MECHANICAL/MECHANICAL_PARTS_LIST.md`, section DSN-MECH-07)

| Step | Action | Fasteners | Inspection |
|---|---|---|---|
| M1 | Mount Power Board on chassis base using the 8 × Ø3.2 holes (`POWER_SUPPLY_dimensions.md` §2) | M3 (inferred from hole size) | stand-off height ≥ tallest bottom-side part (UNKNOWN) |
| M2 | Mount Main Board above/next to it using 10 × Ø3.2 holes; keep SMA field (J1..J55) accessible | M3 (inferred) | RF connector clearance UNKNOWN |
| M3 | Mount Synth board (4 × Ø3.2) close to Main J1/J18/J20/J21/J22/J23 to keep coax short | M3 (inferred) | — |
| M4 | Mount 16 PA boards (7 × Ø3.2 each) on a heat-spreader; thermal interface under QPA2962 | M3 (inferred) | thermal design MISSING |
| M5 | Route harness per cable IDs; strain-relieve coax | — | continuity per `interconnection_table.md` |
| M6 | Install antenna panel and pedestal | — | BLOCKED — no CAD |

## D. Evidence to collect during first integration

Rail voltages (CP-4), AD9523 lock + frequencies (B.4), STM32 CDC enumeration log (B.8), PA IDQ per board (B.6), photos of the first harness with cable labels → store under `engineering/VALIDATION/` and update `docs/TESTING/ACCEPTANCE_CRITERIA.md` (AC-S6, AC-S7, AC-F9).

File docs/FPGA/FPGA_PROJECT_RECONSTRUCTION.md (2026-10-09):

# FPGA Project Reconstruction — AERIS-10 (`9_Firmware/9_2_FPGA/`)

Status date: 2026-10-08. Evidence: static inspection of all 25 `.v`, 1 `.xdc`, 8 `.mem` files; Icarus Verilog 13.0 and Verilator 5.052 runs (section 4); EAGLE schematic netlist extraction (`tools/extract_eagle_netlist.py`). Line references are relative to `9_Firmware/9_2_FPGA/` unless a full path is given. Nothing in this document was verified on hardware. No repository RTL file was modified; all generated artefacts are new files.

**Bottom line:** the FPGA sources cannot be elaborated by any tool today. Before a Vivado project can even reach synthesis, four user modules and two Xilinx FFT IP configurations must be recovered, three syntax/declaration defects must be fixed, and the device part number must be confirmed (schematic says XC7A50T-2FTG256I; README/XDC say XC7A100T). Pin assignment can be reconstructed for 64 of 67 top-level ports from the Main Board schematic, but 25 ports (FT601 USB 3.0, status and debug outputs) have no board counterpart because the FT601 was never wired.

---

## 1. Device identification

| Source | Device statement | Evidence |
|---|---|---|
| Main Board schematic | **XC7A50T-2FTG256I**, package `BGA256C100P16X16_1700X1700X155` | `4_Schematics and Boards Layout/4_6_Schematics/MainBoard/RADAR_Main_Board.sch` part `U42`, library/deviceset `XC7A50T-2FTG256I` |
| Power budget workbook | `XC7A50T-2FTG256` | `3_Power Management/Power Management V6.xlsx` (sharedStrings entry 25) |
| Block diagram | `XC7A50T-2FTG256` | `2_Functional Diagram & Interconnection Matrices/RADAR_V6.drawio` |
| Constraint file | `# Device: [XC7A100T]` (placeholder brackets, no package, no speed grade) | `cntrt.xdc:4` |
| README / hardware docs | "XC7A100T FPGA" | `README.md:52`; `02_hardware/05_fpga_board.md:1,15,30,34,262` |

**Conclusion:** the only CAD evidence is XC7A50T-2FTG256I (speed grade −2, industrial). The XC7A100T claim appears only in prose and in a placeholder comment. Resource estimates in `02_hardware/05_fpga_board.md:44` (300 I/O etc.) therefore describe the wrong device. Vivado part string for the CAD device: `xc7a50tftg256-2`. Whether the design (two 1024-point FFT IPs, 64 parallel DSP multipliers in the FIR, ~32k flip-flops of matched-filter buffers — section 7) fits a 50T (52 160 logic cells, 120 DSP48E1, 2 700 Kbit BRAM per AMD DS180) is **UNRESOLVED** and must be answered by a real synthesis run. Any part substitution must be checked against AMD DS180 Table "Artix-7 Device-Package Combinations" and the board must be re-verified: `UNRESOLVED — REQUIRES BOARD DESIGN VERIFICATION`.

---

## 2. Source inventory and module hierarchy

### 2.1 Files

| File | Module(s) defined | Role | Status |
|---|---|---|---|
| `radar_system_top.v` | `radar_system_top` (line 18) | top level, 67 ports / 180 bits | INCOMPLETE — syntax error at :312 (`wire` declared inside `always`), `wire` assigned procedurally at :155-156/:304-318 |
| `radar_transmitter.v` | `radar_transmitter` (:21) | chirp controller + DAC interface + ADAR load/TR | REQUIRES VALIDATION — SPI level-shifter outputs undriven (:59-71) |
| `plfm_chirp_controller.v` | `plfm_chirp_controller_enhanced` (:3) | TX FSM, inline chirp LUTs (3600 + 60 entries, :99-560) | REQUIRES VALIDATION — `chirp_counter` multi-driven from `clk_100m` (:564-576) and `clk_120m` (:683-784) |
| `dac_interface_single.v` | `dac_interface_enhanced` | 8-bit DAC register; forwards `clk_120m` directly to `dac_clk` (:23) | REQUIRES VALIDATION |
| `edge_detector.v` | `edge_detector_enhanced` | STM32 toggle detection | REQUIRES VALIDATION — edge uses first synchroniser stage (:16-23) |
| `radar_receiver_final.v` | `radar_receiver_final` (:3) | RX chain wrapper | INCOMPLETE — instantiates 2 missing modules (:82, :226), phantom ports `.ref_i/.ref_q` (:216-217), use-before-declare (:150 vs :192), undriven controls (:21-22, :206-208) |
| `lvds_to_cmos_400m.v` | `lvds_to_cmos_400m` | IBUFDS+BUFG on DCO, then a flop re-sampling its own clock (:35-43) | INCOMPLETE — not a clock capture structure |
| `ad9484_interface_400m.v` | `ad9484_interface_400m` | IBUFDS x9 + IDDR x8 capture | ORPHAN (never instantiated; different port list from the missing `ad9484_lvds_to_cmos_400m`) |
| `ddc_input_interface.v` | `ddc_input_interface` | input formatting | REQUIRES VALIDATION |
| `ddc_400m.v` | `ddc_400m_enhanced`, `lfsr_dither_enhanced` | NCO mixer, CIC, FIR | INCOMPLETE — use-before-declare :252-266 vs :272-275; `reset_monitors` in async reset condition :118 |
| `nco_400m_enhanced.v` | `nco_400m_enhanced` | 64-entry quarter-wave LUT NCO | REQUIRES VALIDATION — LUT monotonicity questionable (:34-49) |
| `cic_decimator_4x_enhanced.v` | `cic_decimator_4x_enhanced` | CIC /4 | INCOMPLETE — three always blocks drive the same regs (:71, :181, :291); `posedge reset_monitors` used as a clock |
| `fir_lowpass.v` | `fir_lowpass_parallel_enhanced` | 32-tap parallel FIR | REQUIRES VALIDATION — 32 multipliers + combinational adder tree (:50-73) |
| `cdc_modules.v` | `cdc_adc_to_processing`, `cdc_single_bit`, `cdc_handshake` | clock crossing | REQUIRES VALIDATION — Gray-coding arbitrary data (:74) is not a valid CDC; the two safe modules are orphans |
| `chirp_memory_loader_param.v` | `chirp_memory_loader_param` | `$readmemh` ROM loader | MISSING DEPENDENCY — absolute Windows paths (:3-12); `long_chirp_seg3_{i,q}.mem` do not exist |
| `latency_buffer_2159.v` | `latency_buffer_2159` | delay line | REQUIRES VALIDATION — asynchronous read (:102) blocks BRAM inference; LATENCY 3187 vs name 2159 |
| `matched_filter_multi_segment.v` | `matched_filter_multi_segment` | segment FSM | MISSING DEPENDENCY — instantiates `matched_filter_processing_chain` (:361) which does not exist |
| `frequency_matched_filter.v` | `frequency_matched_filter` | frequency-domain multiply | ORPHAN |
| `fft_1024_forward.v`, `fft_1024_inverse.v` | `fft_1024_forward_enhanced`, `fft_1024_inverse_enhanced` | wrappers around Xilinx FFT IP `FFT_enhanced` (:102 / :78) | ORPHAN + MISSING IP |
| `doppler_processor.v` | `doppler_processor_optimized` | 32-point Doppler FFT via Xilinx IP `xfft_32` (:283) | MISSING IP; incomplete case :159; paste artefact :210-211 |
| `usb_data_interface.v` | `usb_data_interface` | FT601 32-bit FIFO master | REQUIRES VALIDATION — `ft601_clk_out` driven from two clocks (:65-79, :176-182); SV `typedef enum` in a `.v` file (:46) |
| `usb_packet_analyzer.v` | `usb_packet_analyzer` | verification helper | ORPHAN |
| `level_shifter_interface.v` | `level_shifter_interface` | 3.3 V <-> 1.8 V SPI pass-through | ORPHAN (never instantiated, hence the undriven top-level SPI outputs) |
| `chirp_lut_init.v` | none (bare `initial` at :6) | alternative TX LUT values, differ from inline copy | PLACEHOLDER / dead code |
| `radar_system_tb.v` | `radar_system_tb` | system testbench with SystemVerilog assertions (:528-543) | REQUIRES VALIDATION — needs an SVA-capable simulator |
| `cntrt.xdc` | — | constraints | PLACEHOLDER — 142 placeholder lines (section 5) |
| `long_chirp_seg{0,1,2}_{i,q}.mem` | — | 1024 lines each, 4 hex digits (16-bit) | COMPLETE (format verified) |
| `short_chirp_{i,q}.mem` | — | 50 lines each | COMPLETE |

### 2.2 Instantiation tree (as written)

```
radar_system_top                                   radar_system_top.v:18
├── BUFG x3 (clk_100m / clk_120m_dac / ft601_clk)   :174 :179 :184     (UNISIM)
├── radar_transmitter tx_inst                       :204
│   ├── edge_detector_enhanced x3                    radar_transmitter.v:93,100,107
│   ├── plfm_chirp_controller_enhanced               :115
│   └── dac_interface_enhanced                       :148
├── radar_receiver_final rx_inst                    :270
│   ├── lvds_to_cmos_400m (IBUFDS, BUFG)             radar_receiver_final.v:61
│   ├── ad9484_lvds_to_cmos_400m                     :82     *** MISSING ***
│   ├── cdc_adc_to_processing #(8,3)                 :94
│   ├── ddc_400m_enhanced                            :114
│   │   ├── lfsr_dither_enhanced                     ddc_400m.v:131
│   │   ├── nco_400m_enhanced                        :152
│   │   ├── cic_decimator_4x_enhanced x2             :223 :232
│   │   ├── cdc_adc_to_processing #(18,3) x2         :243 :256
│   │   └── fir_lowpass_parallel_enhanced x2         :278 :290
│   ├── ddc_input_interface                          :129
│   ├── chirp_memory_loader_param                    :144   ($readmemh x10, 2 files missing)
│   ├── latency_buffer_2159 #(32,3187)               :173
│   ├── matched_filter_multi_segment                 :198
│   │   └── matched_filter_processing_chain          matched_filter_multi_segment.v:361  *** MISSING ***
│   ├── range_bin_decimator #(1024,64,16)            :226   *** MISSING ***
│   └── doppler_processor_optimized #(32,64,32)      :290
│       └── xfft_32                                  doppler_processor.v:283   *** MISSING Xilinx FFT IP ***
└── usb_data_interface usb_inst                     :345
Orphans: ad9484_interface_400m, fft_1024_forward_enhanced -> FFT_enhanced (*** MISSING IP ***),
         fft_1024_inverse_enhanced -> FFT_enhanced, frequency_matched_filter, level_shifter_interface,
         cdc_single_bit, cdc_handshake, usb_packet_analyzer
```

### 2.3 Missing modules — inferred interfaces (from the instantiations only; INFERENCE, not design data)

| Missing module | Instantiated at | Inferred ports / parameters | Probable origin |
|---|---|---|---|
| `ad9484_lvds_to_cmos_400m` | `radar_receiver_final.v:82-92` | in `adc_d_p[7:0]`, `adc_d_n[7:0]`, `adc_dco_p`, `adc_dco_n`, `reset_n`; out `adc_data_cmos[7:0]`, `adc_dco_cmos`, `adc_valid`, `adc_pwdn` | a renamed rewrite of `ad9484_interface_400m.v` (which lacks `adc_pwdn`, `adc_dco_cmos`, `adc_valid`) |
| `range_bin_decimator` | `radar_receiver_final.v:226-242` | params `INPUT_BINS=1024, OUTPUT_BINS=64, DECIMATION_FACTOR=16`; in `clk, reset_n, range_i_in[15:0], range_q_in[15:0], range_valid_in, decimation_mode[1:0], start_bin[9:0]`; out `range_i_out, range_q_out, range_valid_out, range_bin_index[5:0]` | not present in any form |
| `matched_filter_processing_chain` | `matched_filter_multi_segment.v:361-386` | in `clk, reset_n, adc_data_i/q[15:0], adc_valid, chirp_counter[5:0], long_chirp_real/imag[15:0], short_chirp_real/imag[15:0]`; out `range_profile_i/q[15:0], range_profile_valid, chain_state[3:0]` | likely composed of the orphans `fft_1024_forward_enhanced` -> `frequency_matched_filter` -> `fft_1024_inverse_enhanced` |
| `xfft_32` | `doppler_processor.v:283-296` | AXI4-Stream FFT, 32-point, `s_axis_config_tdata[7:0]`, 32-bit `{Q,I}` data | Xilinx FFT IP (`.xci` absent) |
| `FFT_enhanced` | `fft_1024_forward.v:102`, `fft_1024_inverse.v:78` | AXI4-Stream FFT, 1024-point, runtime-configurable direction (config bit 0), `s_axis_config_tdata[15:0]` | Xilinx FFT IP (`.xci` absent); `fft_1024_forward.v:101` "This must match the name in your project" |
| `BUFG`, `IBUFDS`, `IDDR` | various | 7-series primitives | UNISIM (Vivado provides; for iverilog/verilator use `$XILINX_VIVADO/data/verilog/src/unisims`) |

No `.xpr`, `.xise`, `.xci`, `.coe`, `.ucf`, `.dcp` or `.bit` file exists anywhere in the repository (`find` executed 2026-10-08). The `$readmemh` path `C:/Users/dell/Desktop/ASUS/RADAR_V5/Firmware/FPGA/PLFM_RADAR_Xilinx_ISE_V2/...` (`chirp_memory_loader_param.v:3-12`) shows the original project was a Xilinx ISE project; nothing of it survives.

---

## 3. Top-level ports and physical assignment status

Automated check (`python3 tools/check_fpga_constraints.py`, executed 2026-10-08, exit 1):

```
Top module      : radar_system_top (67 ports, 180 bits)
Placeholders    : 142 active lines (+2 in comments)
No PACKAGE_PIN  : 180 / 180 port bits
No IOSTANDARD   : 21 port bits -> clk_100m, clk_120m_dac, ft601_clk_in, current_elevation[5:0], current_azimuth[5:0], current_chirp[5:0]
Invalid props   : 2  (line 320-321: PACKAGE_PIN_BANK is not a Vivado property)
Clocks          : clk_100m 10.0 ns (:14), clk_120m_dac 8.333 ns (:18), ft601_clk_in 10.0 ns (:22), adc_dco_p 2.5 ns (:26)
```

### 3.1 Ports with a schematic-derived candidate pin (64 ports, 100 bits)

Generated by `python3 tools/gen_xdc_from_schematic.py` into `9_Firmware/9_2_FPGA/reconstructed/radar_system_top_schematic_derived.xdc` and `.../PIN_MAP_FROM_SCHEMATIC.md`. The pad (ball) comes verbatim from the schematic library connect table of part U42; the net-name-to-port interpretation carries the stated confidence. **Caveat:** the library `XC7A50T-2FTG256I` is project-authored (not an AMD file); every ball must be cross-checked against the AMD FTG256 package file (`xc7a50tftg256pkg.txt`, UG475) before use, and the Main Board layout is not finished (see `docs/PCB/MAIN_BOARD.md`), so the pin set may still change.

| RTL port group | Schematic nets | Balls | Bank / VCCO (schematic) | Confidence | Note |
|---|---|---|---|---|---|
| `adc_d_p[7:0]` / `adc_d_n[7:0]` | `ADC_D0..7_P/N` | P15/P16, R15/R16, T14/T15, R13/T13, R10/R11, T9/T10, T7/T8, R6/R7 | 14 / +3V3_FPGA | HIGH | **LVDS_25 with `DIFF_TERM TRUE` (cntrt.xdc:160-167) requires VCCO = 2.5 V in HR banks (AMD UG471); bank 14 is 3.3 V on the schematic → constraint/board conflict, REQUIRES VERIFICATION** |
| `adc_dco_p/n` | `ADC_DCO_P/N` | N14 / P14 (MRCC pair) | 14 / +3V3_FPGA | HIGH | same LVDS/VCCO issue |
| `adc_pwdn` | `ADC_PWRD` | T5 | 14 | HIGH | |
| `dac_data[7:0]` | `DAC_0..7` | A14, A13, A12, B11, B10, A10, A9, A8 | 15 / +3V3_FPGA | HIGH | 22 Ω series resistors to AD9708 |
| `dac_sleep` | `DAC_SLEEP` | A15 | 15 | HIGH | |
| `clk_100m` | `FPGA_SYS_CLOCK` | E12 (MRCC) | 15 | MEDIUM | from SMA J1; 100 MHz supported only by firmware AD9523 OUT6 programming (`main.cpp:995-996`) |
| `clk_120m_dac` | `FPGA_DAC_CLOCK` | C13 (MRCC) | 15 | MEDIUM | 120 MHz per firmware AD9523 OUT11 (`main.cpp:1025-1026`); routed to SMA J18 |
| `tx_mixer_en`, `rx_mixer_en` | `MIX_TX_EN`, `MIX_RX_EN` | C11, D11 | 15 | HIGH | LTC5552 EN pins |
| `fpga_rf_switch` | `M3S_VCTRL` | G15 | 15 | MEDIUM | drives VCTRL of all 17 M3SWA2-34DR+ switches |
| `stm32_new_chirp`, `stm32_new_elevation`, `stm32_new_azimuth`, `stm32_mixers_enable`, `reset_n` | `DIG_0..DIG_4` | F13, E16, D16, F15, E15 | 15 | MEDIUM | STM32 PD8..PD12; mapping from `main.cpp:448,484,514,1483,1660` ("New chirp signal to FPGA", elevation, azimuth, mixers, "RESET FPGA") |
| `stm32_sclk_3v3`, `stm32_mosi_3v3`, `stm32_miso_3v3` | `STM32_SCLK1/MOSI1/MISO1` | J16, H13, G14 | 15 | HIGH | shared with STM32 PA5/PA7/PA6 (SPI1) |
| `stm32_cs_adar1..4_3v3` | `ADAR_1..4_CS_3V3` | F14, H16, G16, J15 | 15 | HIGH | shared with STM32 PA0..PA3 |
| `stm32_sclk_1v8`, `stm32_mosi_1v8`, `stm32_miso_1v8` | `STM32_SCLK_1V8/MOSI_1V8/MISO_1V8` | P5, M1, N3 | 34 / +1V8_FPGA | HIGH | **cntrt.xdc:116 says LVCMOS18 — consistent** |
| `stm32_cs_adar1..4_1v8` | `ADAR_1..4_CS_1V8` | L5, L4, M4, M2 | 34 / +1V8_FPGA | HIGH | |
| `adar_tx_load_1..4` | `ADAR_TX_LOAD_1..4` | P3, T4, R3, R2 | 34 / +1V8_FPGA | HIGH | **cntrt.xdc:85 assigns LVCMOS33 to `adar_*_load_*` — contradicts the 1.8 V bank; must be LVCMOS18** |
| `adar_rx_load_1..4` | `ADAR_RX_LOAD_1..4` | M5, T2, R1, N4 | 34 / +1V8_FPGA | HIGH | same LVCMOS33 error at `cntrt.xdc:85` |
| `adar_tr_1..4` | `ADAR_TR_1..4` | N2, N1, P1, P4 | 34 / +1V8_FPGA | HIGH | same error at `cntrt.xdc:92` |

### 3.2 Ports with no board counterpart (UNRESOLVED — REQUIRES BOARD DESIGN VERIFICATION)

| Ports | Bits | Reason |
|---|---|---|
| `dac_clk` | 1 | RTL forwards `clk_120m` to a pin (`dac_interface_single.v:23`); the board clocks the AD9708 from AD9523 OUT10 via SMA J20 (`main.cpp:1019-1020`); no FPGA net |
| `ft601_clk_in`, `ft601_data[31:0]`, `ft601_be[1:0]`, `ft601_txe_n`, `ft601_rxf_n`, `ft601_txe`, `ft601_rxf`, `ft601_wr_n`, `ft601_rd_n`, `ft601_oe_n`, `ft601_siwu_n`, `ft601_srb[1:0]`, `ft601_swb[1:0]`, `ft601_clk_out` | 49 | FT601Q-B-T (U6) is placed on the schematic with 0 of 77 pins connected; decoupling parts parked outside the outline; no FPGA pin carries a USB net. The RTL's USB 3.0 path has no hardware |
| `current_elevation[5:0]`, `current_azimuth[5:0]`, `current_chirp[5:0]`, `new_chirp_frame` | 19 | no status nets on the schematic |
| `dbg_doppler_data[31:0]`, `dbg_doppler_valid`, `dbg_doppler_bin[4:0]`, `dbg_range_bin[5:0]`, `system_status[3:0]` | 48 | debug outputs; no nets |

Schematic FPGA nets with no RTL port: `ADC_OR_P/N` (M6/N6, over-range), `FPGA_ADC_CLOCK_P/N` (N11/N12, 400 MHz LVDS from AD9523 OUT5 — the RTL uses the ADC DCO instead), `FPGA_CLOCK_TEST` (H14, 20 MHz test clock), `DIG_5..7` (H11/G12/H12, STM32 PD13..PD15 configured as inputs), QSPI flash `FPGA_FLASH_*` (bank 14, MT25QL01G), JTAG.

### 3.3 Other constraint defects in `cntrt.xdc`

| Line(s) | Defect | Fix |
|---|---|---|
| 4-5 | `[XC7A100T]`, `[DATE]` placeholders | set real part in the Vivado project (not in XDC) |
| 33-295 | 140 `PACKAGE_PIN [PIN_NUMBER*]` | replace with the schematic-derived file after designer verification |
| 283, 287, 290 | `# ... (continue for all N bits)` — 37 debug bits never listed | remove debug ports from the top or leave unconstrained (`-quiet`) |
| 85, 92 | LVCMOS33 on bank-34 (1.8 V) signals | LVCMOS18 |
| 160-167 | LVDS_25 + DIFF_TERM on a 3.3 V bank | designer decision: change bank VCCO to 2.5 V, or use external 100 Ω termination with `DIFF_TERM FALSE` (per UG471), or move pins |
| 14-27 | four unrelated clocks, no `set_clock_groups -asynchronous` | add clock groups; without it Vivado times every cross-domain path |
| 309-310 | multicycle path between asynchronous clocks `clk_100m` -> `ft601_clk_in` | remove (meaningless once clock groups are asynchronous) |
| — | no constraint for the flop-derived internal 400 MHz clock (section 7) | design change required, not a constraint |
| 320-321 | `PACKAGE_PIN_BANK` is not a Vivado property | delete |
| — | no `CONFIG_VOLTAGE` / `CFGBVS` | add `set_property CFGBVS VCCO` / `CONFIG_VOLTAGE 3.3` (bank 0 VCCO is +3V3_FPGA on the schematic; CFGBVS pulled via 4.7 kΩ to N$114 — verify the pull direction before setting) |

---

## 4. Static verification actually performed (results, not claims)

Tools: Icarus Verilog 13.0, Verilator 5.052 (`/opt/homebrew/bin`), installed 2026-10-08. Vivado, yosys, xvlog: not installed. Script: `tools/fpga_lint.sh` (logs under `build/lint/` or `$LOG_DIR`).

| Run | Command (abridged) | Exit | Result |
|---|---|---|---|
| A | `iverilog -g2012 -s radar_system_top` on all `.v` except testbench, including `chirp_lut_init.v` | 2 | `chirp_lut_init.v:6: syntax error` (`initial` outside a module) |
| B | same without `chirp_lut_init.v` | 2 | `radar_system_top.v:312: syntax error / Syntax in assignment statement l-value` |
| C | run B + `-I 9_Firmware/9_2_FPGA` | 2 | identical (never reaches `$readmemh`) |
| D | `iverilog -g2012 -s radar_system_tb` | 20 | 18 SVA syntax errors `radar_system_tb.v:528-543` + error B |
| lint | `verilator --lint-only -Wall -Wno-fatal --top-module radar_system_top` | 1 | `radar_system_top.v:312:13: syntax error, unexpected wire`; 23 EOFNEWLINE |
| E–J (scratch copy only, repo untouched) | after hoisting the `wire` at :312, `wire`→`reg` at :155-156, removing `.ref_i/.ref_q`, and stubbing the missing modules | 10/11 | iverilog: "modules were missing: BUFG, IBUFDS, ad9484_lvds_to_cmos_400m, matched_filter_processing_chain, range_bin_decimator, xfft_32"; then use-before-declare errors `ddc_400m.v:252-266`, `radar_receiver_final.v:150`, `radar_system_tb.v:329`. Verilator with stubs: 0 errors, 207 warnings (14 UNDRIVEN, 4 MULTIDRIVEN, 5 MULTIDRIVENPROC, 18 PINMISSING, 17 WIDTHTRUNC, 1 CASEINCOMPLETE, ...) |
| sim | `vvp` | not run | no executable could be produced |

**No simulation or synthesis test PASSED.** All results above are FAIL or informational.

---

## 5. Procedures

### FPGA-T01 — Resolve the device part

- **Purpose:** choose the Vivado part string from verified evidence.
- **Prerequisites:** access to the hardware designer or to a physical Main Board.
- **Required input files:** `RADAR_Main_Board.sch` (U42), `cntrt.xdc:4`, `README.md:52`.
- **Software:** none (or Vivado for `get_parts`).
- **Procedure:** (1) read the marking on the physical FPGA if a board exists; (2) otherwise take the CAD part XC7A50T-2FTG256I; (3) record the decision with its evidence in `docs/04_RECOVERY_TASKS.md` (R-FPGA-01); (4) if XC7A100T is intended, confirm in AMD DS180 Table 2 that the chosen package exists for it and raise a PCB change request. Parameters known: package FTG256, speed −2, temperature I (from CAD). Parameters requiring verification: actual mounted device.
- **Expected output:** one line in `tools/vivado/create_project.tcl` invocation, e.g. `-tclargs xc7a50tftg256-2`.
- **Verification:** `vivado -mode tcl` → `get_parts xc7a50tftg256-2` returns the part.
- **Troubleshooting:** if the resource report later shows > 100 % utilisation, the 50T is too small; that is a design, not a constraint, problem.
- **Completion criteria:** part string recorded with evidence; README/docs/XDC comment corrected in a reviewed change.

### FPGA-T02 — Create the Vivado project

- **Purpose:** obtain Vivado elaboration messages on the real tool.
- **Prerequisites:** FPGA-T01; Vivado 2020.2 or newer (version not evidenced in repo; the IP names `xfft_32`/`FFT_enhanced` are user instance names, so any Vivado with FFT IP v9.1 should regenerate them).
- **Required input files:** all `9_Firmware/9_2_FPGA/*.v` except `radar_system_tb.v` (simulation set) and `chirp_lut_init.v` (not a module); `*.mem`; `cntrt.xdc` (timing section only) and `reconstructed/radar_system_top_schematic_derived.xdc`.
- **Software and version:** AMD Vivado (any 2020.2+ ML Standard edition; Artix-7 is in the free device list).
- **Procedure:**
  1. Open a shell at the repository root.
  2. Run `vivado -mode batch -source tools/vivado/create_project.tcl -tclargs xc7a50tftg256-2` (part from FPGA-T01). The script adds the source set, the `.mem` files as Memory Files, the two XDC files, and the testbench to `sim_1`; it writes `build/vivado/aeris10/aeris10.xpr`.
  3. Open the project in the GUI: `vivado build/vivado/aeris10/aeris10.xpr`.
  4. Flow Navigator → *RTL Analysis → Open Elaborated Design*. Collect the Messages window content (File → Export → Export Messages) into `build/vivado/elab_messages.txt`.
- **Parameters known:** source list (verified by `tools/fpga_lint.sh`), top `radar_system_top`. **Parameters requiring verification:** part; every PACKAGE_PIN (section 3.1 caveat).
- **Expected output:** `.xpr` and an elaboration log that reproduces section 4 errors (`[Synth 8-xxxx]` on `radar_system_top.v:312`, missing modules).
- **Verification:** the log lists exactly the six missing modules of section 2.3 and no others.
- **Troubleshooting:** "file not found" for `.mem` → Vivado resolves `$readmemh` relative to the project; override the ten file-name parameters of `chirp_memory_loader_param` at `radar_receiver_final.v:144` with repository-relative names (a source edit that must be reviewed, see FPGA-T04).
- **Completion criteria:** `.xpr` exists and elaboration messages are archived.

### FPGA-T03 — Fix the syntax and declaration-order defects (reviewed RTL edits)

- **Purpose:** make the RTL parse.
- **Prerequisites:** FPGA-T02 or `tools/fpga_lint.sh`.
- **Required input files:** `radar_system_top.v`, `radar_receiver_final.v`, `ddc_400m.v`, `radar_system_tb.v`.
- **Procedure (each edit is a design change; commit separately with review):**
  1. `radar_system_top.v:312-313`: move `wire [16:0] mag = ...` to module scope as `wire [16:0] mag = (...)`, or compute inside the block into a `reg`.
  2. `radar_system_top.v:155-156`: `wire rx_cfar_detection, rx_cfar_valid` → `reg` (they are assigned at :304-318).
  3. `radar_receiver_final.v:216-217`: delete `.ref_i(16'd0)`, `.ref_q(16'd0)` (ports do not exist in `matched_filter_multi_segment.v:3-39`) **or** add the intended ports to the module — designer decision.
  4. `ddc_400m.v`: move declarations at :272-275 above first use at :252.
  5. `radar_receiver_final.v`: move declaration at :192 above :150.
  6. `radar_system_tb.v`: move `sin_lut` declaration (:343) above :329.
- **Expected output:** `tools/fpga_lint.sh` iverilog run stops only on missing modules.
- **Verification:** `LOG_DIR=build/lint tools/fpga_lint.sh`; `grep -c "missing" build/lint/iverilog_top.log` ≥ 1 and no "syntax error".
- **Troubleshooting:** verilator `MULTIDRIVEN` warnings remain — those are section 7 design defects, out of scope for this task.
- **Completion criteria:** no syntax errors from either tool.

### FPGA-T04 — Recover or re-implement the missing modules and IP

- **Purpose:** complete the hierarchy.
- **Prerequisites:** FPGA-T03.
- **Required inputs from the designer:** the original ISE/Vivado project (`PLFM_RADAR_Xilinx_ISE_V2`), or the RTL of `ad9484_lvds_to_cmos_400m`, `range_bin_decimator`, `matched_filter_processing_chain`; FFT IP settings.
- **Procedure if the originals are unavailable:**
  1. FFT IP: Vivado IP Catalog → *Fast Fourier Transform* (v9.1). Create instance `FFT_enhanced`: 1 channel, transform length 1024, architecture Pipelined Streaming I/O, data width 16, phase factor width 16, scaled fixed-point (config word width must come out as 16 bits to match `fft_1024_forward.v:102-122`; adjust scaling-schedule options until `s_axis_config_tdata` is `[15:0]`), runtime-configurable transform direction. Create instance `xfft_32`: length 32, data width 16, config word `[7:0]` (`doppler_processor.v:283-296`). Record the resulting `.xci` files under `9_Firmware/9_2_FPGA/ip/` (directory to be created; does not exist yet). **All IP parameters beyond the port widths are UNVERIFIED assumptions.**
  2. `ad9484_lvds_to_cmos_400m`: wrap `ad9484_interface_400m.v` (IBUFDS/IDDR) behind the inferred port list, after resolving whether the AD9484 LVDS output is DDR at 200 MHz bit clock (AD9484 datasheet `7_Components Datasheets and Application notes/AD9484/AD9484.pdf`, "LVDS DDR output" — REQUIRES VERIFICATION) and replacing the flop-derived clock of `lvds_to_cmos_400m.v:35-43` with a proper BUFIO/BUFR or MMCM structure.
  3. `matched_filter_processing_chain`: compose the orphans `fft_1024_forward_enhanced` → `frequency_matched_filter` → `fft_1024_inverse_enhanced`; the reference-memory semantics (time vs frequency domain, `frequency_matched_filter.v:13`) must be confirmed with the `.mem` generator (missing).
  4. `range_bin_decimator`: new module per the inferred interface (peak-detect mode `decimation_mode=2'b01`).
  5. Add `long_chirp_seg3_{i,q}.mem` (or set `LONG_SEGMENTS=3` in `matched_filter_multi_segment.v:52` if 3072 samples cover the 3000-sample chirp — designer decision) and replace the Windows paths at `chirp_memory_loader_param.v:3-12` with project-relative names.
- **Expected output:** iverilog elaboration (with UNISIM models) succeeds; Vivado elaborated design opens.
- **Verification:** `tools/fpga_lint.sh` exit 0 when run with `-y $XILINX_VIVADO/data/verilog/src/unisims` added (edit the script's iverilog line or set `IVERILOG_EXTRA`).
- **Completion criteria:** zero missing modules; every `.xci` committed.

### FPGA-T05 — Simulation

- **Purpose:** run `radar_system_tb`.
- **Prerequisites:** FPGA-T04.
- **Software:** Vivado xsim (supports the SVA properties at `radar_system_tb.v:528-543`; Icarus does not).
- **Procedure:** in the project, Flow → *Run Simulation → Run Behavioral Simulation*; set simulation run time ≥ 500 µs (`radar_system_tb.v:149-162`); the TB generates 64 chirp toggles at 3 µs spacing (:230-254) which is shorter than the 167 µs chirp-plus-listen period of `plfm_chirp_controller.v:41-42` — adjust the stimulus or expect overlapping chirps. Disable `$dumpvars(0, ...)` (:549-557) or restrict depth; a full dump at 400 MHz for 500 µs is multi-GB.
- **Expected output:** console counts summary (:495-521).
- **Verification:** the TB has no pass/fail gating; a PASS can only be declared after adding `$fatal` on assertion failure and a scoreboard — this is new verification work.
- **Completion criteria:** assertions execute without error and the Doppler output monitor (:481-489) reports non-zero valid samples.

### FPGA-T06 — Synthesis and implementation report inspection

- **Purpose:** quantify resources and timing on the real part.
- **Prerequisites:** FPGA-T04, verified XDC.
- **Procedure:** `launch_runs synth_1 -jobs 4; wait_on_run synth_1; open_run synth_1; report_utilization -file build/vivado/util.rpt; report_timing_summary -file build/vivado/timing.rpt; report_clock_interaction -file build/vivado/clkint.rpt; report_cdc -file build/vivado/cdc.rpt`. Then `launch_runs impl_1 -to_step write_bitstream`.
- **What to look for:** utilisation > 100 % on DSP (FIR = 64 DSP48E1 for two instances, `fir_lowpass.v:50-73`; 50T has 120) or on slice registers (matched-filter arrays ≈ 32 768 FFs, `matched_filter_multi_segment.v:60-61,329-332`); WNS < 0 on any 400 MHz path (CIC integrators `cic_decimator_4x_enhanced.v:94-137`); `report_cdc` critical entries on `cdc_adc_to_processing`; `report_clock_interaction` showing "unsafe" between the four external clocks.
- **Completion criteria:** `write_bitstream` completes; reports archived; all CRITICAL WARNINGs dispositioned in writing.

### FPGA-T07 — Prerequisites for bitstream generation (checklist)

1. Part confirmed (FPGA-T01).
2. All 180 port bits either constrained to designer-verified balls or removed from the top (section 3.2 ports).
3. Bank voltage legality: bank 14 LVDS inputs vs 3.3 V VCCO resolved; bank 34 LVCMOS18.
4. Missing modules/IP recovered (FPGA-T04).
5. Clock architecture decided: is `clk_100m` phase-locked to ADC DCO/4? (`cdc_adc_to_processing` drops/duplicates samples otherwise; `ddc_400m.v:243-267`).
6. Multi-driven registers removed (`plfm_chirp_controller.v` `chirp_counter`; `usb_data_interface.v` `ft601_clk_out`; CIC monitors).
7. USB path decided: the FT601 does not exist on the board; either wire it (PCB change) or remove `usb_data_interface` and route data through the STM32 (which has no high-speed path to the FPGA — only `DIG_0..7` GPIO and SPI1).
8. `CFGBVS`/`CONFIG_VOLTAGE` set; configuration mode (M0..M2 pull resistors R138-R140 on the schematic — values define master SPI from MT25QL01G; verify).
9. Timing closure (FPGA-T06).

---

## 6. Clock architecture (RTL evidence vs board evidence)

| Clock | RTL (XDC) | Board / firmware |
|---|---|---|
| `clk_100m` 100 MHz | external pin, BUFG `radar_system_top.v:174` | AD9523 OUT6 "FPGA_SYSTEM_CLOCK" /36 = 100 MHz LVCMOS (`main.cpp:995-996`) → SMA J1 → FPGA E12 |
| `clk_120m_dac` 120 MHz | external pin, BUFG :179; also forwarded to `dac_clk` pin | AD9523 OUT11 "FPGA_DAC" /30 = 120 MHz (`main.cpp:1025-1026`) → FPGA C13; the DAC itself gets OUT10 via SMA J20 |
| `ft601_clk_in` 100 MHz | external pin from FT601 | FT601 unconnected — clock does not exist |
| `adc_dco_p/n` 400 MHz | IBUFDS → BUFG → flop (`lvds_to_cmos_400m.v:17-43`) | AD9484 DCO → N14/P14; AD9523 OUT4 clocks the ADC at 400 MHz (`main.cpp:983-984`); OUT5 "FPGA_ADC" 400 MHz LVDS → N11/N12 (unused by RTL) |
| internal `clk_400m` | flop output used as a clock for NCO/mixer/CIC | not a real clock; design defect |

Absent in RTL: any MMCM/PLL (`grep MMCME2|PLLE2|clk_wiz` → none). Absent in XDC: `set_clock_groups`.

---

## 7. Design defects that block synthesis or function (evidence)

| # | Defect | Evidence |
|---|---|---|
| 1 | 400 MHz capture not implemented; internal clock is a flop re-sampling its own clock | `lvds_to_cmos_400m.v:35-43`; consumers `radar_receiver_final.v:99,115` |
| 2 | `chirp_counter` written from two clock domains | `plfm_chirp_controller.v:564-576` (clk_100m) and `:683-784` (clk_120m) |
| 3 | `ft601_clk_out` written from two always blocks on different clocks | `usb_data_interface.v:65-79`, `:176-182` |
| 4 | CIC monitor registers written from three always blocks, one clocked by the floating input `reset_monitors` | `cic_decimator_4x_enhanced.v:71,181,291`; left unconnected at `ddc_400m.v:223-240` |
| 5 | Async-reset block with data-dependent reset condition | `ddc_400m.v:117-125` |
| 6 | Receiver control inputs undriven → matched filter never starts; `range_bin` never assigned | `radar_receiver_final.v:17,21-22,206-208` |
| 7 | STM32 SPI pass-through outputs undriven (level shifter never instantiated) → ADAR1000 SPI cannot work through the FPGA | `radar_transmitter.v:59-71`; `level_shifter_interface.v:10` orphan |
| 8 | Unsynchronised cross-domain sampling of `range_profile`, `doppler_*`, `cfar_*` in the FT601 domain | `usb_data_interface.v:84,106-109,124-132,147-150` |
| 9 | CFAR is a fixed threshold `mag > 17'd10000`; range profile output is the Doppler data "as a placeholder" | `radar_system_top.v:298-331` |
| 10 | Two conflicting TX LUT value sets | `plfm_chirp_controller.v:99-560` vs `chirp_lut_init.v:7` (e.g. index 1: 237 vs 128) |
| 11 | Asynchronous BRAM read prevents block-RAM inference of the 4096x32 latency buffer | `latency_buffer_2159.v:102` |
| 12 | FT601 interface definition inconsistent with the FT601 datasheet (TXE_N/RXF_N are device outputs; BE is 4 bits in 32-bit mode) | `radar_system_top.v:79-94`, `usb_data_interface.v:16-35` — REQUIRES VERIFICATION against `7_Components Datasheets` (no FT601 datasheet present) |

---

## 8. Information required from the hardware designer

1. Confirmed FPGA part (CAD: XC7A50T-2FTG256I).
2. Confirmation of every ball in `reconstructed/PIN_MAP_FROM_SCHEMATIC.md` against the AMD package file and the final routed board.
3. Bank 14 VCCO decision for the LVDS inputs (2.5 V or external termination).
4. The original ISE/Vivado project, the four missing RTL modules, the two FFT IP configurations, `long_chirp_seg3_*.mem`, and the `.mem`/LUT generator script (which TX LUT set is authoritative).
5. Clocking intent: is `clk_100m` phase-locked to DCO/4; AD9484 output mode (DDR/SDR) and bit-clock rate.
6. The intended host data path (FT601 is not wired; STM32 has only USB FS).

---

## 9. Generated artefacts (this reconstruction)

| Path | Content | Status |
|---|---|---|
| `9_Firmware/9_2_FPGA/reconstructed/radar_system_top_schematic_derived.xdc` | 64 ports / 100 bits with PACKAGE_PIN + IOSTANDARD from schematic banks; unresolved ports listed as comments | REQUIRES VALIDATION (not hardware-verified) |
| `9_Firmware/9_2_FPGA/reconstructed/PIN_MAP_FROM_SCHEMATIC.md` | mapping table with confidence and notes | REQUIRES VALIDATION |
| `tools/check_fpga_constraints.py` | placeholder / coverage checker | executed, exit 1 (expected) |
| `tools/extract_eagle_netlist.py`, `tools/gen_xdc_from_schematic.py` | netlist extraction and XDC generation | executed |
| `tools/fpga_lint.sh` | iverilog/verilator wrapper | executed, FAIL (expected) |
| `tools/vivado/create_project.tcl` | project creation (part mandatory) | NOT executed (no Vivado on this machine) |

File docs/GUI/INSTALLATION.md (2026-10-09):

# Python GUI — Installation and Validation

Applies to `9_Firmware/9_3_GUI/`. Generated files: `requirements.txt`, `pyproject.toml` (same directory). Tested environment: CPython 3.14.7 + Tk 9.0, macOS arm64, 2026-10-08. Steps marked *executed* were run during this reconstruction; the others are documented procedures.

### GUI-T01 — Create the virtual environment (executed)

- **Purpose:** isolated, reproducible interpreter.
- **Prerequisites:** Python ≥ 3.10 with Tk (`python3 -c "import tkinter; print(tkinter.TkVersion)"` must print a version). macOS: `brew install python@3.12` or python.org installer; Debian/Ubuntu: `apt install python3 python3-venv python3-tk libusb-1.0-0`; Windows: python.org installer (Tk included).
- **Procedure:**
  ```
  cd 9_Firmware/9_3_GUI
  python3 -m venv .venv
  source .venv/bin/activate          # Windows: .venv\Scripts\activate
  python -m pip install --upgrade pip
  ```
- **Verification:** `python -c "import sys; print(sys.prefix)"` points into `.venv`.

### GUI-T02 — Install dependencies (executed in a scratch venv)

- **Procedure:** `pip install -r requirements.txt` (pins are lower bounds; the versions listed as "tested" in the file are known-good).
- **System libraries:** `pyusb` needs libusb-1.0 (`brew install libusb` / `apt install libusb-1.0-0`). `pyftdi` needs the FTDI device to be free of the kernel driver (macOS: no action; Linux: udev rule; Windows: Zadig/WinUSB).
- **Expected output:** `pip check` prints "No broken requirements found".
- **Troubleshooting:** `filterpy` is unmaintained; if it fails on a future numpy, pin `numpy<3`. `tkinterweb` is only needed for `GUI_V5_Demo.py`, which is not runnable anyway — skip it with `pip install -r requirements.txt --no-deps` is **not** recommended; instead delete the line.

### GUI-T03 — Import checks (executed)

- **Procedure:** from the repository root: `python3 tools/check_python_imports.py --dir 9_Firmware/9_3_GUI --try-import` (inside the venv).
- **Expected output:** every third-party module `OK`; `GUI_V1.py` reported as `SYNTAX ERROR` (known fragment).
- **Completion criteria:** exit code 1 only because of `GUI_V1.py`; all imports OK. To get exit 0, pass `--dir` paths that exclude V1 or remove/relocate the fragment (repository decision).

### GUI-T04 — Offline / demo mode

- **Only runnable demo:** `GUI_V6_Demo.py` (self-contained `SimulatedRadarProcessor`, `GUI_V6_Demo.py:61-231`; needs numpy, matplotlib, tkinter).
- **Procedure:** `python GUI_V6_Demo.py` → window "Radar Demo"; press *Start*; targets drift in the PPI; *Record* writes `.npz`; *Save config* writes JSON.
- **CSV replay:** `python GUI_V4_2_CSV.py` → *Load CSV* → select `test_radar_data.csv`. Known defects: derived columns are computed before the file is read (`:354-368`, works on the second load) and the error-path lambda references an unbound variable (`:430`).
- **Not runnable:** `GUI_V5_Demo.py` (missing methods, `AttributeError` at `:955`), `GUI_V6.py` (stub classes), `GUI_V1.py`.
- **Status:** the window launch was **not executed** during this reconstruction (static + module-import verification only).

### GUI-T05 — GUI startup smoke test (procedure; not executed)

```
cd 9_Firmware/9_3_GUI && source .venv/bin/activate
python - <<'EOF'
import importlib, tkinter
for m in ("GUI_V6_Demo", "GUI_V4_2_CSV", "GUI_V5"):
    importlib.import_module(m); print("import OK", m)
root = tkinter.Tk(); root.after(1500, root.destroy); root.mainloop(); print("Tk OK")
EOF
```
Then launch `GUI_V6_Demo.py` and confirm the window appears within 5 s and closes cleanly (exit code 0). On a headless CI runner use `xvfb-run -a python GUI_V6_Demo.py` with a watchdog that sends `root.destroy()` after N seconds (requires a small wrapper; not provided).

### GUI-T06 — Hardware-dependent features (do not expect to work without the fixes in `docs/STM32` and `docs/FPGA`)

| Feature | File / lines | Hardware required | Known blocker |
|---|---|---|---|
| STM32 settings upload | `GUI_V5.py:403-469` | STM32 CDC on USB-FS | firmware RX path dead (STM32 C4); start-flag padding (C5) |
| GPS display | `GUI_V5.py:684-751` | STM32 | `GPS_Init` never called (C6); text format mismatch |
| Radar data stream | `GUI_V5.py:755-797` (FT2232H) / `GUI_V6.py:94-363` (FT601) | FTDI bridge | neither chip is wired on the Main Board; RTL packet format differs |
| Map | V4+ | Google Maps API key | placeholder key |

### GUI-T07 — Packaging for distribution (procedure; not executed)

- **Wheel:** `cd 9_Firmware/9_3_GUI && pip install build && python -m build` → `dist/aeris10_gui-0.6.0-py3-none-any.whl`; `pip install dist/*.whl` provides `aeris10-gui` (→ `GUI_V6:main`, non-functional until V6 is completed) and `aeris10-gui-demo` (→ `GUI_V6_Demo:main`).
- **Stand-alone binary:** `pip install pyinstaller && pyinstaller --onefile --windowed --name aeris10-demo GUI_V6_Demo.py` → `dist/aeris10-demo(.exe/.app)`. Add `--hidden-import matplotlib.backends.backend_tkagg` if the backend is missing at runtime. For the hardware GUIs add `--collect-all pyftdi --collect-all usb`.
- **Acceptance:** the packaged demo starts on a machine without Python installed and shows moving targets; size and start-up time recorded.

### GUI-T08 — Recommended clean-up (repository decisions, not performed)

1. Move `GUI_V1.py`, `GUI_V5_Demo.py`, `GUI_V6.py` to an `archive/` folder or complete them; the `pyproject.toml` `py-modules` list must then be updated.
2. Replace bare `except: pass` blocks (`.planning/codebase/CONCERNS.md`).
3. Decide the host interface (STM32 CDC-ACM via `pyserial` is the only path with hardware) and remove the FTDI code paths or wire an FTDI chip.

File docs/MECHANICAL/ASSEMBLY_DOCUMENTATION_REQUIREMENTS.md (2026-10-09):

# Assembly Documentation Requirements — AERIS-10

Purpose: define the assembly documentation package that `README.md:141-143` promises (`10_docs/assembly_guide.md`, `10_docs/Hardware/Enclosure`) but that does not exist, and state what can be written today versus what needs designer input. Status date 2026-10-08.

> **Update 2026-10-09:** mechanical artefacts generated from the PCB geometry (DXF, STEP bodies, 1:1 plan view, dimension sheets with hole tables and mass ESTIMATES), the CONCEPTUAL exploded view, parts list and assembly sequence are in `engineering/MECHANICAL/` and `engineering/ASSEMBLY/`; the unresolved geometry register is `engineering/VALIDATION/UNRESOLVED_GEOMETRY.md`; reconstruction guides for enclosure/antenna/pedestal/cooling drawings are MDR-01…MDR-05 in `engineering/MISSING_DRAWINGS_RECOVERY_PLAN.md`.

## 1. Required assembly views and documents

| # | Document | Content | Can be produced now? | Source |
|---|---|---|---|---|
| A1 | Board outline & hole drawings (4 boards) | outline, NPTH positions, connector positions | **YES — produced** (`docs/MECHANICAL/drawings/*_outline.svg`) | EAGLE `.brd` |
| A2 | PCB assembly drawings top/bottom (component outlines + reference designators) | per board | NO (needs EAGLE/KiCad run; P-EAGLE-07) | `.brd` |
| A3 | Inter-board interconnection table (cable list) | from/to connector, signal, cable type, length | PARTIAL — signal map possible from schematic net names on the Molex/SMA connectors; lengths unknown | `.sch` files |
| A4 | System block diagram with physical interfaces | boards, antenna, pedestal, host | YES for electrical blocks (`docs/SYSTEM/BLOCK_DIAGRAM.md`); NO for mechanical envelope | `RADAR_V6.drawio`, schematics, firmware |
| A5 | Enclosure drawing (overall dimensions, mounting, openings for 37+11+2 SMA, mini-USB, power terminal) | — | NO — no enclosure CAD | designer |
| A6 | Exploded view (enclosure, Main Board, Power Board, Synth board, PA boards ×16, antenna, pedestal) | — | NO — no 3-D models | designer |
| A7 | Antenna array drawing (element positions, feed interface) | — | NO — two contradictory simulation geometries, no CAD | antenna designer |
| A8 | Pedestal / azimuth drive (stepper, slip ring, bearing) | — | NO | designer |
| A9 | Thermal/airflow layout (fans, PA heatsinks) | — | NO | designer |
| A10 | Assembly sequence and torque/ESD notes | step list | PARTIAL — electrical bring-up order is known (power sequencing from firmware); mechanical order unknown | `main.cpp:1240-1275,1485-1489`, `Power Management V6.xlsx` |
| A11 | Mass and centre-of-gravity table | per assembly | NO (no thickness, no enclosure) | — |

## 2. Minimum content of `10_docs/assembly_guide.md` (to be written once A5–A9 exist)

1. Safety: PA drain voltage (+22 V per `Power Management V6.xlsx`; actual rail UNRESOLVED), RF exposure at 10.5 GHz with up to 16 × 10 W (Extended variant), ESD for GaN/GaAs MMICs.
2. Kitting: BOMs from `docs/BOM/` (after MPN completion), cables (A3), hardware (M3 screws for the Ø3.2 holes — standoff heights unknown).
3. PCB inspection: visual, continuity on power rails per the Power Board silkscreen rail list, no shorts between `+1V0_FPGA/+1V8_FPGA/+3V3_FPGA` and GND.
4. Board mounting order and standoffs (A5/A6).
5. Cabling: SMA map (A3) — the Frequency Synthesizer silkscreen names its SMAs (`LO TX, LO RX, AUX. LO TX, AUX. LO RX, ADC, FPGA=ADC, FPGA=DAC, DAC, FPGA SYS. CLOCK, TEST, AD9523 PLL_OUT, TX_LO MUXOUT, RX_LO MUXOUT`); Main Board receives `FPGA_SYS_CLOCK` on J1, `FPGA_DAC_CLOCK` on J18, DAC clock on J20, ADC clock on J19 (`docs/PCB/MAIN_BOARD.md`); the remaining 33 Main-Board SMAs (J22–J55) carry RF/antenna/test signals whose assignment must be tabulated from the schematic before cabling.
6. First power-up: STM32 sequencing (`docs/STM32/STM32_PROJECT_RECONSTRUCTION.md` STM-T06 step 4), expected LED behaviour (`LED_1..4` on PF12–PF15: LO lock indication `main.cpp:1453-1474`).
7. Antenna attachment and boresight alignment; stepper homing to North (`main.cpp:1513-1519`).
8. Host connection: mini-USB X53 (STM32 CDC) — the only host link on the current hardware.

## 3. Exploded-view documentation package — procedure (once CAD exists)

- **Software:** Fusion 360 / FreeCAD / SolidWorks.
- **Procedure:** import PCB STEP models (EAGLE 9 → Fusion "Push to 3D" or KiCad → File → Export → STEP after assigning component models), the enclosure STEP, antenna STEP; create an assembly with mates on the Ø3.2 hole patterns; generate an exploded view with a parts list balloon table; export `ASSEMBLY_EXPLODED.pdf` (A3), `ASSEMBLY_ISO.png`, `ASSEMBLY.step`.
- **Verification:** every BOM line item (docs/BOM + system-level items) has a balloon; hole patterns mate without interference; SMA connector positions match the enclosure openings.
- **Acceptance:** the exploded view, the assembly guide and the BOMs agree on part count and reference numbering.

## 4. What this reconstruction delivered

- `docs/MECHANICAL/drawings/MAIN_BOARD_outline.svg`, `POWER_SUPPLY_outline.svg`, `RF_PA_outline.svg`, `FREQUENCY_SYNTHESIZER_outline.svg` (A1).
- `docs/SYSTEM/BLOCK_DIAGRAM.md` (A4, electrical).
- `docs/BOM/` (kitting input).
- This requirements list and `MECHANICAL_GAP_ANALYSIS.md`.

No enclosure, antenna, pedestal, exploded view or mass data was created, because no verified geometry exists in the repository.

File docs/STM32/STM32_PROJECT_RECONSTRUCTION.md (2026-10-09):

# STM32 Firmware Project Reconstruction — AERIS-10 (`9_Firmware/9_1_Microcontroller/`)

Status date: 2026-10-08. Evidence: static inspection of all 136 source files, include-graph analysis (`tools/check_stm32_includes.py`), host-compiler syntax probes, EAGLE schematic netlist (`tools/extract_eagle_netlist.py --part U2`). `LIB` = `9_1_1_C_Cpp_Libraries`, `CODE` = `9_1_3_C_Cpp_Code`. No firmware was compiled for the target (no ARM toolchain on the authoring machine); nothing was flashed or run.

**Bottom line:** the repository contains only application-level sources. There is no CubeMX `.ioc`, no linker script, no startup file, no build system, no CMSIS device header, no STM32CubeF7 HAL driver sources, and no USB Device library or CubeMX USB application files (`usb_device.c`, `usbd_cdc_if.c`, `usbd_conf.c`, `usbd_desc.c`). All of these are obtainable from STMicroelectronics packages or regenerable from CubeMX using the verified settings in section 3, **except** four design conflicts that only the hardware designer can resolve (section 5).

---

## 1. MCU identification

| Evidence | Statement | Source |
|---|---|---|
| Main Board schematic/board | `STM32F746ZGT7`, part U2, LQFP-144 (pad numbers 1..144) | `RADAR_Main_Board.sch` deviceset `STM32F746ZGT7`; `tools/extract_eagle_netlist.py --part U2` → 116 connected pins |
| README | "STM32F746xx" | `README.md:63` |
| Firmware | family-level only (`stm32f7xx_hal.h`); no `STM32F746xx`, no `USE_HAL_DRIVER` define anywhere | `grep -rnE "STM32F7[0-9]{2}xx|USE_HAL_DRIVER" 9_Firmware/9_1_Microcontroller` → 0 hits |
| Peripherals used | OTG_FS (`OTG_FS_IRQHandler`), MPU, DWT → Cortex-M7 | `LIB/stm32f7xx_it.c:204-213`; `CODE/main.cpp:2354-2379, 303` |

**Confirmed:** STM32F746ZGT7 (Cortex-M7, 1 MB flash, 320 KB SRAM, LQFP-144, −40..+105 °C "7" grade) from CAD. **Assumption:** the preprocessor symbol `STM32F746xx` must be supplied by the build system.

---

## 2. Missing build infrastructure (whole repository searched 2026-10-08)

| ID | Artifact | Status | Recovery source |
|---|---|---|---|
| STM-01 | `*.ioc` CubeMX project | MISSING | regenerate (section 4, STM-T02) |
| STM-02 | linker script `STM32F746ZGTX_FLASH.ld` | MISSING | CubeMX/CubeIDE generates; or STM32CubeF7 template |
| STM-03 | `startup_stm32f746zgtx.s` | MISSING | STM32CubeF7 `Drivers/CMSIS/Device/ST/STM32F7xx/Source/Templates/gcc/startup_stm32f746xx.s` |
| STM-04 | `.cproject`/`.project`/Makefile/CMake | MISSING | CubeIDE project or `reconstructed/CMakeLists.txt` (section 7, UNVERIFIED) |
| STM-05..08 | `usb_device.c/.h`, `usbd_cdc_if.c/.h`, `usbd_conf.c/.h`, `usbd_desc.c/.h` | MISSING | CubeMX generates with USB_DEVICE middleware = CDC |
| STM-09 | HAL driver sources `stm32f7xx_hal*.c` | MISSING | STM32CubeF7 `Drivers/STM32F7xx_HAL_Driver` |
| STM-10 | CMSIS `stm32f7xx.h`, `stm32f746xx.h`, `system_stm32f7xx.h`, `core_cm7.h` | MISSING | STM32CubeF7 `Drivers/CMSIS` |
| STM-11 | `Middlewares/ST/STM32_USB_Device_Library` (Core + Class/CDC) | MISSING | STM32CubeF7 |
| STM-12 | USB descriptors (VID/PID/strings) | UNKNOWN | not in repo; the GUI enumerates by bulk endpoints on interface (0,0) without a VID/PID filter for the STM32 (`9_Firmware/9_3_GUI/GUI_V5.py:358-399`) |

Automated check: `python3 tools/check_stm32_includes.py` (executed, exit 1) lists 50 HAL headers, 1 CMSIS header and 2 USB headers that are included but absent, plus 6 case-mismatched includes (section 5, C3).

Present CubeMX-generated files (reusable verbatim): `LIB/stm32f7xx_hal_conf.h`, `LIB/stm32f7xx_hal_msp.c`, `LIB/stm32f7xx_it.c/.h`, `LIB/system_stm32f7xx.c`, `LIB/syscalls.c`, `LIB/sysmem.c`, `CODE/main.h`, `CODE/main.cpp` (CubeMX `main.c` skeleton renamed to `.cpp`; `/* USER CODE */` fences intact).

---

## 3. Verified configuration (reconstructable `.ioc` content)

Everything in this section is read from source and cross-checked against the schematic. Values marked **ASSUMED** are standard CubeIDE defaults not evidenced in the repository.

### 3.1 Clock tree (`CODE/main.cpp:1803-1849`, `LIB/stm32f7xx_hal_conf.h`)

| Item | Value in firmware | Evidence | Schematic |
|---|---|---|---|
| HSE | 25 MHz crystal, `RCC_HSE_ON` | `hal_conf.h:97` `HSE_VALUE=25000000`; `main.cpp:1821` | **XTAL1 = NX3225GD-8MHZ-STD-CRA-3 (8 MHz) on PH0/PH1** — `RADAR_Main_Board.sch` part XTAL1; nets `STM32_OSC_N/P` → U2 pins 23/24 (PH0/PH1) |
| PLL | source HSE, M=25, N=144, P=/2, Q=3 | `main.cpp:1823-1827` | with 8 MHz HSE the PLL input would be 0.32 MHz (below the 0.95 MHz minimum of RM0385) → **CONFLICT C1** |
| SYSCLK / AHB / APB1 / APB2 | 72 / 72 / 36 / 72 MHz (derived for 25 MHz HSE) | `main.cpp:1835-1846`; comments `:285,294` | — |
| USB clock | PLLQ = 48 MHz | PLLQ=3 | — |
| Flash latency | 2 WS | `main.cpp:1846` | — |
| Voltage scale | SCALE3 | `main.cpp:1815` | — |
| LSE | 32.768 kHz crystal present on board, not used by firmware | `hal_conf.h:125`; XTAL3 `NX3215SA-32.768KHz` | PC14/PC15 |
| HSI / LSI | 16 MHz / 32 kHz (defaults) | `hal_conf.h:110,117` | — |
| TIM prescaler | `RCC_TIMPRES_ACTIVATED` | `main.cpp:1852-1866` | — |

### 3.2 Peripherals and pins (`LIB/stm32f7xx_hal_msp.c`, `CODE/main.cpp`, schematic U2 nets)

| Peripheral | Pins / AF (MSP) | Init parameters (`main.cpp`) | Schematic net (U2) | Use |
|---|---|---|---|---|
| I2C1 | PB6 SCL, PB7 SDA, AF4, OD | timing `0x00808CD2` (`:1872-1912`) | `STM32_SCL1/SDA1` | DAC5578 x2 @0x48/0x49 (PA gate bias) |
| I2C2 | PF0 SDA, PF1 SCL, AF4 | `0x00808CD2` (`:1920-1960`) | `STM32_SDA2/SCL2` | ADS7830 x2 @0x48/0x4A (Idq), @0x49 (temps) |
| I2C3 | PA8 SCL, PC9 SDA, AF4 | `0x00808CD2` (`:1968-2008`) | `STM32_SCL3/SDA3` | GY-85 IMU, BMP180 |
| SPI1 | PA5 SCK, PA6 MISO, PA7 MOSI, AF5 | master, 8-bit, CPOL0/CPHA0, soft NSS, **prescaler /2 = 36 MHz** (`:2016-2048`) | `STM32_SCLK1/MISO1/MOSI1` → FPGA J16/G14/H13 and (via FPGA bank 34) ADAR1000 | ADAR1000 x4; CS on PA0..PA3 (`ADAR_1..4_CS_3V3`) |
| SPI4 | PE2 SCK, PE5 MISO, PE6 MOSI, AF5 | identical, /2 (`:2056-2088`) | `STM32_SCLK4/MISO4/MOSI4` → connector to Frequency Synthesizer board | AD9523 (CS PF7), ADF4382 TX/RX (CS PG14/PG10) |
| UART5 | PC12 TX, PD2 RX, AF8 | 9600 8N1 (`:2143-2170`) | `STM32_TX5/RX5` | GPS NMEA |
| USART3 | PB10 TX, PB11 RX, AF7 | 115200 8N1 (`:2178-2205`) | `STM32_TX3/RX3` | debug / `GPS_SendToGUI` text |
| TIM1 | — | PSC 71, ARR 0xFFFE, 1 MHz tick (`:2096-2135`) | — | `delay_us` |
| USB OTG_FS | PA11 DM, PA12 DP (AF10 in missing `usbd_conf.c`), PA10 ID | CDC class (missing files) | `STM32_USB_FS_D_N/D_P/ID` → mini-USB X53 | host link |
| SWD | PA13/PA14, SWO PB3 | — | `STM32_SWDIO/SWCLK/SWO` | debug |
| DMA | **none** configured | `HAL_DMA_MODULE_ENABLED` set but no `hdma` | — | — |
| NVIC | only `OTG_FS_IRQn` handler present (`stm32f7xx_it.c:204-213`); its enable lives in missing `usbd_conf.c` | | | |

### 3.3 GPIO map (`CODE/main.h:62-165`, all confirmed by schematic nets on U2)

| Port.Pin | Macro | Net (schematic) |
|---|---|---|
| PF3..PF10 | `AD9523_PD, _REF_SEL, _SYNC, _RESET, _CS, _STATUS0, _STATUS1, _EEPROM_SEL` | `AD9523_*` |
| PF12..PF15 | `LED_1..LED_4` | `N$52, N$91, N$93, N$94` (LEDs) |
| PA0..PA3 | `ADAR_1..4_CS_3V3` | `ADAR_1..4_CS_3V3` (also to FPGA F14/H16/G16/J15) |
| PG0..PG5 | `EN_P_5V0_PA1, _PA2, _PA3, EN_P_5V5_PA, EN_P_1V8_CLOCK, EN_P_3V3_CLOCK` | `EN_+5V0_PA1..3, EN_+5V5_PA, EN_+1V8_CLOCK, EN_+3V3_CLOCK` |
| PG6..PG10 | `ADF4382_RX_LKDET, _DELADJ, _DELSTR, _CE, _CS` | `ADF4382_RX_*` |
| PG11..PG15 | `ADF4382_TX_LKDET, _DELSTR, _DELADJ, _CS, _CE` | `ADF4382_TX_*` |
| PE7..PE15 | `EN_P_1V0_FPGA, EN_P_1V8_FPGA, EN_P_3V3_FPGA, EN_P_5V0_ADAR, EN_P_3V3_ADAR12, EN_P_3V3_ADAR34, EN_P_3V3_ADTR, EN_P_3V3_SW, EN_P_3V3_VDD_SW` | `EN_+1V0_FPGA ... EN_+3V3_VDD_SW` |
| PC6..PC8 | `MAG_DRDY, ACC_INT, GYR_INT` | same |
| PD4..PD7 | `STEPPER_CW_P, STEPPER_CLK_P, EN_DIS_RFPA_VDD, EN_DIS_COOLING` | `STEPPER_CW+, STEPPER_CLK+, EN/DIS_RFPA_VDD, EN/DIS_COOLING` |
| PB4, PB5, PB8, PB9 | `DAC_1_VG_CLR, DAC_1_VG_LDAC, DAC_2_VG_CLR, DAC_2_VG_LDAC` | same |
| PD8..PD12 (no macro) | FPGA handshake: new chirp, new elevation, new azimuth, mixers enable, FPGA reset | `DIG_0..DIG_4` → FPGA F13/E16/D16/F15/E15 (`main.cpp:448,484,514,1483,1660`) |
| PD13..PD15 | inputs, never read | `DIG_5..7` → FPGA H11/G12/H12 |
| BOOT0 | GND | — |

### 3.4 HAL modules enabled (`LIB/stm32f7xx_hal_conf.h:38-88`)

HAL, SPI, TIM, UART, PCD, GPIO, EXTI, DMA, RCC, FLASH, PWR, I2C, CORTEX. Required driver sources from STM32CubeF7 `Drivers/STM32F7xx_HAL_Driver/Src`: `stm32f7xx_hal.c, _cortex.c, _rcc.c, _rcc_ex.c, _gpio.c, _dma.c, _dma_ex.c, _exti.c, _flash.c, _flash_ex.c, _pwr.c, _pwr_ex.c, _i2c.c, _i2c_ex.c, _spi.c, _spi_ex.c, _tim.c, _tim_ex.c, _uart.c, _uart_ex.c, _pcd.c, _pcd_ex.c, stm32f7xx_ll_usb.c`. Options: `VDD_VALUE 3300`, `TICK_INT_PRIORITY 15`, `USE_RTOS 0`, `PREFETCH_ENABLE 0`, no register callbacks, `USE_FULL_ASSERT` off.

### 3.5 USB CDC middleware requirements

| File | Provides | Required by |
|---|---|---|
| `USB_DEVICE/App/usb_device.c/.h` | `MX_USB_DEVICE_Init()`, `hUsbDeviceFS` | `main.cpp:21,129,1229` |
| `USB_DEVICE/App/usbd_cdc_if.c/.h` | `CDC_Transmit_FS`, `USBD_Interface_fops_FS`, static `CDC_Receive_FS` | `main.cpp:23,1692`; `gps_handler.cpp:118` |
| `USB_DEVICE/App/usbd_desc.c/.h` | VID/PID/strings | enumeration (values unknown) |
| `USB_DEVICE/Target/usbd_conf.c/.h` | `HAL_PCD_MspInit` (PA11/PA12 AF10, NVIC `OTG_FS_IRQn`), `hpcd_USB_OTG_FS` | `stm32f7xx_it.c:58` |
| `Middlewares/ST/STM32_USB_Device_Library/Core`, `Class/CDC` | stack; `USBD_CDC_SetRxBuffer/ReceivePacket` | `main.cpp:336-337` |

**Design defect C4:** `main.cpp:328-339` defines `extern "C" void CDC_Receive_FS(uint8_t*, uint32_t*)`, but the CubeMX-generated `usbd_cdc_if.c` binds its own `static int8_t CDC_Receive_FS` in `USBD_Interface_fops_FS`. The `main.cpp` function is never called; the start-flag wait loop at `main.cpp:1534-1555` can never exit. The USER CODE edit that forwards received bytes to `usbHandler.processUSBData()` is not in the repository.

### 3.6 Memory layout / linker / startup requirements

- Device: 1 MB flash at 0x08000000 (AXIM) / 0x00200000 (ITCM), 320 KB RAM (DTCM 64 KB at 0x20000000, SRAM1 240 KB at 0x20010000, SRAM2 16 KB at 0x2004C000) — **from RM0385, not from repo**.
- `sysmem.c` needs `_end` and `_estack` symbols from the linker script; `syscalls.c` needs newlib (`--specs=nano.specs` ASSUMED).
- `MPU_Config()` (`main.cpp:2354-2379`) configures a background region; no cache enable calls (`SCB_EnableICache/DCache`) — CubeIDE default for F7 is cache off unless ticked (ASSUMED).
- Startup must call `SystemInit()` (`system_stm32f7xx.c`) — standard template.
- C++: `main.cpp` uses `<iostream>`, `<vector>` (`main.cpp:44-45`) → `arm-none-eabi-g++`, libstdc++ (nano or full). `<iostream>` pulls in static-init I/O objects (~ tens of kB flash; ASSUMED not blocking on 1 MB).

---

## 4. Procedures

### STM-T01 — Install toolchain and STM32CubeF7

- **Purpose:** obtain compiler and HAL/CMSIS/USB sources.
- **Prerequisites:** internet access; ~3 GB disk.
- **Software and version:** STM32CubeIDE 1.16+ (bundles GNU Arm 12/13, CubeMX 6.11+, CubeF7 1.17.x) — **version not evidenced in repository**; `hal_conf.h` template © 2017 and generated files © 2025 imply CubeMX ≥ 6.x. Alternative: `brew install --cask gcc-arm-embedded` + `git clone --recursive https://github.com/STMicroelectronics/STM32CubeF7`.
- **Procedure:** install CubeIDE (macOS: download from st.com; needs a free ST account); or install the Arm toolchain and clone STM32CubeF7 to `~/STM32Cube/Repository/STM32Cube_FW_F7_V1.17.x`.
- **Verification:** `arm-none-eabi-gcc --version`; `bash tools/stm32_check_cube_package.sh <path-to-STM32CubeF7>` reports every required file as FOUND.
- **Completion criteria:** script exit 0.

### STM-T02 — Regenerate the CubeMX project

- **Purpose:** recreate `.ioc`, startup, linker script, HAL glue and USB CDC application files.
- **Prerequisites:** STM-T01.
- **Required input files:** section 3 tables; `LIB/stm32f7xx_hal_msp.c`; `CODE/main.cpp`.
- **Procedure (CubeIDE):**
  1. File → New → STM32 Project → MCU selector → `STM32F746ZGTx` → name `aeris10_stm32`, language **C++**, binary Executable, project type STM32Cube.
  2. Pinout & Configuration: set each peripheral exactly as in section 3.2 (I2C1/2/3 with the pin assignments listed; SPI1 and SPI4 full-duplex master, prescaler 2; UART5 9600; USART3 115200; TIM1 internal clock, PSC 71, ARR 65534; USB_OTG_FS mode *Device_Only*; Middleware → USB_DEVICE → Class *Communication Device Class (Virtual Port Com)*). Set the GPIO outputs/inputs of section 3.3 with the macro names as user labels. Set PD8..PD12 output, PD13..PD15 input.
  3. Clock Configuration: HSE input **enter the crystal value decided in C1** (firmware expects 25 MHz; board has 8 MHz). Target HCLK 72 MHz, USB 48 MHz. If 8 MHz is kept: M=4 (2 MHz PFD), N=144, P=2, Q=6 reproduces 72/48 MHz — **this is a proposal, not evidence**; the firmware constants at `main.cpp:1823-1827` must then change.
  4. Project Manager → Code Generator: *Copy only the necessary library files*, *Generate peripheral initialization as a pair of .c/.h files* **unchecked** (the repo's `main.cpp` contains all `MX_*_Init` inline), keep user code on regeneration.
  5. Generate code. The IDE produces `Core/Src/main.c`, `Core/Src/stm32f7xx_hal_msp.c`, `stm32f7xx_it.c`, `system_stm32f7xx.c`, `syscalls.c`, `sysmem.c`, `Core/Startup/startup_stm32f746zgtx.s`, `STM32F746ZGTX_FLASH.ld`, `USB_DEVICE/App/*`, `USB_DEVICE/Target/*`, `Drivers/`, `Middlewares/`.
  6. Replace `Core/Src/main.c` by the repository `CODE/main.cpp` (delete the generated `main.c`), copy `CODE/main.h` over `Core/Inc/main.h`, copy `LIB/stm32f7xx_hal_conf.h`, `stm32f7xx_hal_msp.c`, `stm32f7xx_it.c/.h` over the generated ones (diff first; they must be identical in peripheral content), and add `LIB/` as a source folder with the exclusions of STM-T03.
  7. Diff the generated `usbd_conf.c` NVIC/GPIO code against `stm32f7xx_it.c:204-213` (consistent) and record the VID/PID chosen in `usbd_desc.c` (**unknown original value**).
- **Expected output:** `.ioc` + full project tree.
- **Verification:** generated `stm32f7xx_hal_msp.c` diff against `LIB/stm32f7xx_hal_msp.c` shows only cosmetic differences.
- **Troubleshooting:** CubeMX refuses PLL settings → the 8 MHz vs 25 MHz decision (C1) is unresolved.
- **Completion criteria:** project builds to the first *application* error (STM-T03).

### STM-T03 — Build-set cleanup (source edits requiring review)

| Issue | Evidence | Action |
|---|---|---|
| Uppercase headers `ADS7830.H`, `DAC5578.H`, `platform_noos_stm32.H` included as `.h` | `LIB/ADS7830.c:1`, `LIB/DA5578.c:1`, `LIB/platform_noos_stm32.c:2`, `CODE/main.cpp:54,64,65` | rename files to `.h` (case-sensitive filesystems/CI) |
| `platform_noos_stm32.c` calls undefined `hal_set_gpio_by_index` | `LIB/platform_noos_stm32.c:50-58` | exclude from build (its functions are never called from `main.cpp`) or implement |
| `iio.c`, `iio_app.c`, `iiod.c`, `no_os_*` networking | include `tcp_socket.h`, `lwip_socket.h`, platform headers | exclude `iio*.c`, `iiod.c` from build; they are not used by `main.cpp` |
| `LIB/errno.h` shadows toolchain `<errno.h>` via `#include_next` | `LIB/errno.h:94` | keep `LIB` after system includes, or remove the file (verify with GCC) |
| Two ADAR1000 drivers | `adar1000.c` (no callers) and `ADAR1000_Manager.cpp` (used) | exclude `adar1000.c` or keep (both compile; macros identical) |
| `printf` → `__io_putchar` unimplemented | `LIB/syscalls.c:35,80-88` | retarget to USART3 if debug output is wanted (optional) |
| Defines | `-DSTM32F746xx -DUSE_HAL_DRIVER` | mandatory; `-mcpu=cortex-m7 -mfpu=fpv5-sp-d16 -mfloat-abi=hard` (**ASSUMED** CubeIDE default for F746) |

### STM-T04 — Fix the blocking firmware defects (designer/firmware-author decisions)

| ID | Defect | Evidence | Resolution options |
|---|---|---|---|
| C1 | HSE 25 MHz (firmware) vs 8 MHz crystal (schematic) | `hal_conf.h:97`, `main.cpp:1823`; XTAL1 NX3225GD-8MHZ | board revision check; change PLLM/Q or crystal |
| C2 | `adf4382a_manager.h:9-28` maps ADF4382 control to PG0..PG9, which `main.h:94-123` assigns to PA/clock power enables; `ADF4382A_Manager_Init` drives `EN_P_5V0_PA1` as TX_CE (`adf4382a_manager.c:83-84,482-483`) and reads lock detect from enable outputs (`:330-331`) | schematic: ADF4382 pins are PG6..PG15 (`main.h:124-157` matches) | make `adf4382a_manager.h` use the `main.h` macros; **safety-relevant** (PA rails toggled out of sequence) |
| C3 | `adf4382a_manager.c:42,51` passes `platform_ops = NULL`; `no_os_spi_init` returns `-EINVAL` (`no_os_spi.c:57-58`) → `Error_Handler()` at `main.cpp:1411-1414` (infinite loop, IRQs off) | | set `platform_ops = &stm32_spi_ops` as done for AD9523 (`main.cpp:1039`) and route CS through PG10/PG14 — the custom `stm32_spi.c:23-38` ignores `chip_select`, so CS handling must be added |
| C4 | USB RX dead (section 3.5) | `main.cpp:328-339` | add USER CODE in `usbd_cdc_if.c` `CDC_Receive_FS` calling a C-linkage shim to `usbHandler.processUSBData(Buf, *Len)` |
| C5 | Start-flag padding: GUI sends flag + 60 zero bytes (`GUI_V5.py:444-446`); `USBHandler.cpp:51-52` forwards the zeros into the settings buffer, then `:70` requires `"SET"` at offset 0 → settings never accepted | | reset `buffer_index` after the flag, or search for `SET` anywhere |
| C6 | `GPS_Init()` never called → `gui_huart == NULL` → `GPS_SendBinaryToGUI` returns early | `gps_handler.cpp:6,65-67` | call `GPS_Init(&huart3)` (or route via USB CDC) |
| C7 | AD9523 CS (PF7) driven low at GPIO init and never toggled; SPI4 runs at 36 MHz although drivers request 10 MHz (`stm32_spi.c:17` stores `max_speed_hz` but never applies it) | `main.cpp:1037,2232-2234` | implement CS and prescaler in `stm32_spi.c`; verify AD9523/ADF4382 SPI max clock in datasheets |

### STM-T05 — Compile, link, size

- **Procedure:** CubeIDE *Project → Build All* (Debug). Or with the reconstructed CMake (section 7): `cmake -S 9_Firmware/9_1_Microcontroller/reconstructed -B build/stm32 -DCMAKE_TOOLCHAIN_FILE=... -DCUBE_F7=<path> && cmake --build build/stm32`.
- **Expected output:** `aeris10_stm32.elf`, `.map`; `arm-none-eabi-size` text+data < 1 048 576 B, bss+data < 327 680 B.
- **Static analysis:** `cppcheck --enable=warning,style --std=c++17 -I LIB -I CODE CODE/main.cpp LIB/*.cpp LIB/USBHandler.cpp` (cppcheck not installed on the authoring machine; command UNVERIFIED).
- **Completion criteria:** zero errors; size within limits; map file archived under `build/stm32/`.

### STM-T06 — Firmware verification (hardware)

1. Flash via SWD (`STM32_Programmer_CLI -c port=SWD -w aeris10_stm32.elf -v -rst`).
2. USART3 at 115200: expect `printf` output only after `__io_putchar` retarget.
3. USB: host enumerates a CDC ACM device (VID/PID as set in `usbd_desc.c`); send `[23,46,158,237]` (4 bytes, unpadded) then the 82-byte settings packet (`SET` + 3 doubles + uint32 + 6 doubles + `END`, big-endian — `RadarSettings.cpp:23-113`); firmware must transmit the status string (`main.cpp:1692`).
4. Power sequencing with a scope on `EN_*` rails: order per `main.cpp:1240-1275, 1485-1489` and `3_Power Management/Power Management V6.xlsx` (clock 1.8 V → 3.3 V → FPGA 1.0 → 1.8 → 3.3 → ADAR 3.3 → ADAR 5.0 → ADTR → PA drain).
5. Note the 180 s OCXO warm-up delay at start (`main.cpp:1237`).

---

## 5. Unresolved-configuration table

| ID | Item | Firmware value | Other evidence | Status |
|---|---|---|---|---|
| U1 | HSE frequency | 25 MHz | schematic 8 MHz | **CONFLICT — REQUIRES BOARD DESIGN VERIFICATION** |
| U2 | ADF4382 control pins | `adf4382a_manager.h` PG0..PG9 | `main.h` + schematic PG6..PG15 | **CONFLICT** (code bug) |
| U3 | USB VID/PID/strings | — | — | UNKNOWN |
| U4 | SPI clock for AD9523/ADF4382/ADAR1000 | 36 MHz actual | drivers request 10 MHz | REQUIRES DATASHEET VERIFICATION |
| U5 | I2C timing `0x00808CD2` at PCLK1 36 MHz | — | — | REQUIRES CubeMX VERIFICATION (bus speed unknown) |
| U6 | Compiler flags / FPU | — | — | ASSUMED CubeIDE defaults |
| U7 | Cache / MPU settings beyond background region | cache not enabled in code | — | ASSUMED off |
| U8 | `STM32_ALGO.docx` (algorithm description) | file is 0 bytes | — | MISSING CONTENT |
| U9 | Interrupt priorities | only SysTick (15) | — | UNVERIFIED (none set for USB in repo) |
| U10 | Idq loop channel mix-up `main.cpp:1650-1652` (reads hadc2 into adc1_readings) | — | — | SUSPECTED BUG, not verified |

---

## 6. Build verification checklist

- [ ] `tools/stm32_check_cube_package.sh <CubeF7>` exit 0
- [ ] `.ioc` regenerated; generated MSP identical in content to `LIB/stm32f7xx_hal_msp.c`
- [ ] Case-mismatch headers renamed; `python3 tools/check_stm32_includes.py` shows 0 CASE MISMATCH
- [ ] C1 decided and PLL constants consistent with the crystal
- [ ] C2, C3, C4, C5, C6, C7 fixed and reviewed
- [ ] `arm-none-eabi-g++` build: 0 errors, warnings reviewed
- [ ] `arm-none-eabi-size` within 1 MB / 320 KB
- [ ] `.elf`/`.map` archived; flashed; CDC enumeration observed; settings accepted (state `READY_FOR_DATA`)

---

## 7. Generated artefacts

| Path | Content | Status |
|---|---|---|
| `tools/check_stm32_includes.py` | include classifier | executed, exit 1 (expected) |
| `tools/stm32_check_cube_package.sh` | verifies a STM32CubeF7 tree has every required file | NOT executed against a package (none on this machine); self-test with a missing path exits 2 |
| `9_Firmware/9_1_Microcontroller/reconstructed/CMakeLists.txt` | source list from this analysis, flags ASSUMED, requires `-DCUBE_F7=<path>` and the CubeMX-generated USB/startup/linker files | NOT built (no toolchain) — UNVERIFIED |

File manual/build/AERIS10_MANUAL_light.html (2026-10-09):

AERIS-10 — Engineering & Assembly Manual

© Antidrone Ukraine · antidrone.cc · 2026-10-09 · BETA — not hardware-verified

# AERIS-10

## Pulsed-LFM X-band phased-array radar

## Complete Engineering & Assembly Manual

Antidrone Ukraine · antidrone.cc

Edition 2026-10-09 — BETA (reconstruction, proposed designs and beta implementations; not hardware-verified)

Repository: https://github.com/herasymyuks/PLFM_RADAR-aeris · Upstream project files: NawfalMotii79/PLFM_RADAR (ORIGINAL PROJECT FILE where labelled)

# AERIS-10 — Complete Engineering & Assembly Manual

Author: Antidrone Ukraine · antidrone.cc

Built 2026-10-09 by tools/build_manual.py from manual/chapters (order: manual/00_OUTLINE.md). Status: BETA documentation — no item is hardware-verified; see the status label on every figure and procedure.

<!-- chapter 0: Title, status statement, how to read, revision table -->

# AERIS-10 — Complete Engineering & Assembly Manual

Author: Antidrone Ukraine · antidrone.cc

Status summary: this chapter is editorial (BETA documentation edition). It introduces a manual in which no item is VERIFIED on hardware; every figure and procedure carries one of the labels defined in section 4 below.

Sources: docs/AERIS10_ENGINEERING_BUILD_MANUAL.md (header, v1.3), docs/AERIS10_BETA_ENGINEERING_REPORT.md §1–2, MANUAL_BUILD_SPEC.md, manual/STYLE_GUIDE.md, manual/00_OUTLINE.md, README.md.

Planned figures: none.

## 1. Title and authorship

Field | Value
Title | AERIS-10 — Pulsed-LFM X-band phased-array radar — Complete Engineering & Assembly Manual
Author (compilation, generated drawings, reconstruction, proposed designs) | Antidrone Ukraine · antidrone.cc
Edition | 2026-10-09 — BETA
Compiled from | repository PLFM_RADAR (branch main), reconstruction documents docs/, engineering package engineering/, BETA implementations beta/
Upstream project files | NawfalMotii79/PLFM_RADAR, labelled ORIGINAL PROJECT FILE wherever they appear (source: README.md badges; MANUAL_BUILD_SPEC.md §AUTHORSHIP)
Build | python3 tools/build_manual.py concatenates manual/chapters/*.md in the order of manual/00_OUTLINE.md and writes manual/AERIS10_MANUAL.md, manual/build/AERIS10_MANUAL.html and manual/build/AERIS10_MANUAL.pdf

The manual's authorship covers the compilation, the generated drawings (title blocks carry the ATTRIBUTION line of tools/eagle_svg_common.py), the reconstruction work and the proposed designs. Original upstream files (EAGLE schematics and boards, firmware sources, GUI scripts, photographs, the draw.io block diagram) keep their own authorship and are labelled ORIGINAL PROJECT FILE in captions and tables (source: manual/STYLE_GUIDE.md, rule "Authorship").

## 2. Revision table

Edition | Date | Author | Scope | Status
2026-10-09 | 2026-10-09 | Antidrone Ukraine · antidrone.cc | First complete edition: system description, theory of operation, architecture and interfaces, four PCBs, antenna, host link and 22 V supply, mechanical design, FPGA/STM32/GUI, manufacturing, assembly and bring-up procedures, open-issue registers, appendices | BETA — not hardware-verified

Lineage of the source documents this edition compiles (each is cited where used):

Source document | Version / date | Content
docs/AERIS10_ENGINEERING_BUILD_MANUAL.md | v1.3, 2026-10-09 (v1.0 2026-10-08; v1.1 drawings package; v1.2 proposed designs; v1.3 BETA) | reconstruction, build preparation and documentation manual, Parts I–XIII
docs/AERIS10_BETA_ENGINEERING_REPORT.md | v0.9 draft, 2026-10-09 | consolidated report of everything built, simulated and calculated in the BETA phase, with executed evidence
engineering/DRAWING_REGISTER.md | 2026-10-09 | 89 registered drawings (39 SOURCE-DERIVED, 28 PARTIAL, 16 PROPOSED, 1 CONCEPTUAL, 5 BLOCKED); file check 333 OK, 0 problems
engineering/DESIGN/00_DESIGN_BASIS.md | DSN-00 Rev A, 2026-10-09 | design basis and decision log D-01…D-15 for the proposed designs
beta/fpga, beta/stm32, beta/gui, beta/pcb READMEs and CHANGELOGs | 2026-10-09 | BETA implementations (build/simulate/test on a workstation only)
Upstream repository content | dated 2026-03-14 (source: docs/AERIS10_ENGINEERING_BUILD_MANUAL.md header) | schematics, layouts, firmware, GUI, physics notes, photographs

## 3. Status statement

The reconstruction manual summarises the repository state in one sentence: "the repository is a documented design study with schematics for four boards, partially routed layouts, non-building FPGA RTL, non-building STM32 firmware, one offline-runnable Python demo, and no mechanical design. No subsystem can be built reproducibly today" (source: docs/AERIS10_ENGINEERING_BUILD_MANUAL.md, header, "Readiness in one sentence"). The BETA phase changed the software state on the authoring workstation but not the hardware state; the executed evidence per area is (source: docs/AERIS10_BETA_ENGINEERING_REPORT.md §1, copied):

Area | State before | State now | Executed evidence
FPGA RTL | did not parse; 5 modules/IP missing; 400 MHz fabric; no host path | parses/lints; all modules present; ISERDES 1:4 capture + 100 MHz polyphase DDC (bit-exact vs legacy); SPI host bridge; register map | beta/fpga/build.sh: 0 failures, 9 testbench runs PASS
STM32 firmware | no build system/HAL; 7+ defects; empty ADAR1000 phase tables | builds and links (93 KB flash); 12 defects fixed; ADAR1000 tables from the datasheet; bridge + REG commands | beta/stm32/build.sh exit 0; host tests 6/6
Python GUI | V6 stub; no tests; wrong packet format | package with firmware-exact protocol, bridge-frame path, register panel, simulator; PyInstaller app | pytest 72 passed; selftests exit 0
PCBs | no Gerbers; Main 15 / Power 308 unconnected; 0 MPN | Main/RF PA 0 unconnected; Power 89 (listed); BOM MPNs; fab notes; full packages; Main rev. B with FT601 | KiCad DRC reports, export logs
Host data path | FT601 unwired | option A pin plan (bank 35) + option B SPI bridge implemented end-to-end | tb PASS, firmware build, GUI tests on the RTL vector
Antenna | none | 16×8 patch panel, KiCad board, openEMS simulated | S11 −18 dB at f0, 128 MHz band, coupling −20.7 dB
Thermal / power | none | drain-gating requirement, 22 V module design, 2-D plate map | 64 °C plate / ≈ 73 °C PA base in case B
Mechanics | none | head + pedestal, 51-part detail model, flat patterns, parts list; torque check | FreeCAD model builds; register file check 0 problems
Radar performance | TBD everywhere | range equation with simulated gain | R(1 m²) ≈ 6 km at B = 50 MHz

What remains impossible on the authoring machine, and therefore is not claimed anywhere in this manual: Vivado synthesis, timing and bitstream generation; flashing and bench tests; PCB fabrication; measurement of component heights; antenna coupon on a VNA; PA thermal test; the 89 Power Board pour connections (manual CAD); EAGLE schematic updates for rev. B; the owner decisions K1–K8 and D-01…D-19 (source: docs/AERIS10_BETA_ENGINEERING_REPORT.md §2).

## 4. How to read the status labels

Every figure caption and every procedure title carries exactly one of the following labels (source: manual/STYLE_GUIDE.md, "Status vocabulary"; MANUAL_BUILD_SPEC.md, "HARD RULES"). Nothing in this manual is promoted above the status recorded in its source register.

Label | Meaning | Typical content
ORIGINAL PROJECT FILE | as found in the upstream repository; authorship stays with the upstream project; photographs carry no dimensions | 8_Utils/*.jpg, 2_Functional Diagram & Interconnection Matrices/RADAR_V6.jpg, EAGLE .sch/.brd, 9_Firmware/
SOURCE-DERIVED | generated from the native design files by a repository tool; some elements may be unverifiable and are listed | schematic renders, KiCad-converted board plots, system diagrams SYS-01…04, netlists
PARTIAL | significant parts missing from the sources | FPGA pipeline SD-02, STM32 diagrams SD-03/04, end-to-end flow SD-07
CONCEPTUAL | documented intent only, no geometry or wiring behind it | exploded view ASM-EXP-01, antenna and host blocks in SYS-01
PROPOSED DESIGN | new engineering content that depends on logged decisions D-xx | antenna panel, head and pedestal, 22 V supply, harness schedule, host link
BETA | builds, simulates or tests on a workstation; not synthesised for the target, not flashed, not on hardware | beta/fpga, beta/stm32, beta/gui, beta/pcb
BLOCKED — MISSING DATA | cannot be produced from the repository | enclosure dimensions, component heights, cable lengths (G-01…G-12)
VERIFIED | reserved for hardware- or vendor-confirmed items; currently unused in the whole project | —

Supplementary vocabularies used inside copied tables keep the meaning of their source: CONFIRMED / UNVERIFIED / MISSING SPEC (interconnection and power-rail registers, source: engineering/SYSTEM/interfaces/interconnection_table.md), DONE / OPEN / BLOCKED (task tracker, source: docs/04_RECOVERY_TASKS.md), MET / NOT MET / NOT RUN / PARTIALLY MET (acceptance criteria, source: docs/TESTING/ACCEPTANCE_CRITERIA.md), ASSUMED / ESTIMATE (numbers, source: manual/STYLE_GUIDE.md). Citations are inline, in the form (source: path:line) or (source: path §section); a table copied from a source states the source once in its caption or lead-in. Where a value is not available in any repository file the text says "UNKNOWN" and names the register item that tracks it.

Identifier families used for cross-references (defined in Appendix D): K1–K8 configuration conflicts, D-01…D-19 design decisions, G-01…G-12 geometry gaps, MDR-01…13 missing-drawing recovery guides, DSN- proposed-design drawings, SYS-/SD-/ELEC-/MECH-/ASM-/PCB- registered drawings, CBL- cables, AC- acceptance criteria, R- recovery tasks, C1–C7 firmware conflicts, MAN- observations raised by this manual.

## 5. Safety

Three hazards are present in the design as documented and are repeated before the first procedure step that needs them (source: manual/STYLE_GUIDE.md, rule "Procedures"): the 22 V PA drain supply (QPA2962 bias-up sequence VG −4 V → VD +22 V, 2 A per board, 16 boards; source: engineering/ELECTRICAL/power_distribution/power_rails.md §1 row +22V0/VD), RF radiation from the array (up to 16 × 10 W peak for the Extended variant; source: README.md, Technical Specifications), and the rotating pedestal (head mass estimate 10.4 kg, 50 azimuth positions per revolution; source: engineering/DESIGN/CALCS/DESIGN_CALCULATIONS.md §2).

## 6. Upstream acknowledgement

The AERIS-10 project was published by NawfalMotii79 as PLFM_RADAR under an MIT licence badge (source: README.md, lines 3–6). The upstream repository supplies the four EAGLE schematic/board sets, the FPGA RTL, the STM32 sources, the Python GUI versions, the physics and hardware notes under 00_notation/, 01_physics/, 02_hardware/, the power-management spreadsheet, the draw.io block diagram and the photographs. These files are reproduced or rendered in this manual as ORIGINAL PROJECT FILE and were not modified (source: MANUAL_BUILD_SPEC.md, "Preserve originals"). No LICENSE file exists in the repository root; acceptance criterion AC-D4 records that the licence file consistent with the badge is NOT MET (source: docs/TESTING/ACCEPTANCE_CRITERIA.md, row AC-D4).

## 7. Document map

Chapter order equals the concatenation order of manual/00_OUTLINE.md (copied):

# | Chapter | Content | Status of content

0 | Front matter | title, revision table, status statement, labels, acknowledgement, map | editorial
1 | System overview | pulsed-LFM X-band phased array, variants Nexus/Extended, documented vs calculated performance, conflicts K1–K8 | SOURCE-DERIVED + PROPOSED (calculations)
2 | Theory of operation | waveform and timing, pulse compression, Doppler, beamforming, FPGA chain, data path | ORIGINAL PROJECT FILE (physics notes) + PARTIAL (RTL diagrams) + BETA
3 | Architecture and interfaces | boards, connectors, cables, power rails, enable sequence, harness | SOURCE-DERIVED + PROPOSED (harness)
4 | Main Board | schematic set, layout, BOM, DRC state, rev. B host interface | SOURCE-DERIVED + BETA
5 | Power Supply Board | same pattern | SOURCE-DERIVED + BETA
6 | Frequency Synthesizer | same pattern | SOURCE-DERIVED + BETA
7 | RF PA board (×16) | same pattern + thermal | SOURCE-DERIVED + BETA + PROPOSED
8 | Antenna | proposed 16×8 patch panel, simulation, fabrication data | PROPOSED DESIGN
9 | Host link and 22 V supply | FPGA→host options A/B, 22 V PA supply module | PROPOSED DESIGN + BETA
10 | Mechanical design | head and pedestal, drawings, parts, flat patterns, thermal map, torque | PROPOSED DESIGN
11 | FPGA firmware | hierarchy, build, constraints, tests, synthesis status | BETA
12 | STM32 firmware | architecture, build, defects fixed, sequencing, USB protocol | BETA
13 | GUI software | install, run, protocol, register panel, packaging | BETA
14 | Manufacturing | packages per board, stack-ups, BOMs, fab checklist | SOURCE-DERIVED + BETA
15 | Assembly procedure | numbered steps with checks | PROPOSED DESIGN (geometry)
16 | Bring-up and test | power-up, flashing, calibration, bench tests, acceptance | procedures OPEN, not executed
17 | Open issues and decisions | K, D, G, MDR, R registers | registers
A | Drawing register | copy of engineering/DRAWING_REGISTER.md | register
B | Parts and cables | BOM summaries, mechanical parts, cable schedule | SOURCE-DERIVED + PROPOSED
C | Tooling | generators and checkers under tools/ | documentation
D | Glossary | acronyms, symbols, status vocabulary, ID families | documentation

<!-- chapter 1: What AERIS-10 is: pulsed-LFM X-band phased array, variants Nexus/Extended, performance targets vs calculated -->

# System overview — what AERIS-10 is

Author: Antidrone Ukraine · antidrone.cc

Status summary: system description SOURCE-DERIVED (reconstructed from the four EAGLE schematics, the firmware and the RTL); variant table and performance targets ORIGINAL PROJECT FILE (README claims, not verified); calculated performance PROPOSED DESIGN / BETA (DSN-CALC-01, with stated assumptions); figures F1.1 SOURCE-DERIVED, F1.2 and F1.3 ORIGINAL PROJECT FILE. Eight configuration conflicts K1–K8 between the CAD and the documentation remain open.

Sources: README.md, 00_notation/parameter_table.md, docs/SYSTEM/BLOCK_DIAGRAM.md, docs/AERIS10_BETA_ENGINEERING_REPORT.md, engineering/DESIGN/CALCS/DESIGN_CALCULATIONS.md §3, engineering/SYSTEM/architecture/README.md, 02_hardware/01_system_overview.md.

Planned figures: F1.1 system block diagram (SYS-01), F1.2 original draw.io block diagram, F1.3 prototype photographs.

## 1. Purpose and principle

AERIS-10 is described by its upstream README as "an open-source, low-cost 10.5 GHz phased array radar system featuring Pulse Linear Frequency Modulated (LFM) modulation", available in two versions (3 km and 20 km range) for researchers, drone developers and SDR enthusiasts (source: README.md, introduction). The radar transmits linear-frequency-modulated pulses (chirps) at X-band, steers the beam electronically in elevation with four ADAR1000 beamformer ICs across a 16-element linear array, rotates the head mechanically in azimuth with a stepper motor, and processes the echoes in an FPGA (down-conversion, decimation, pulse compression, Doppler FFT, detection) before sending results to a host PC running a Python GUI (source: README.md, "Processing Pipeline"; engineering/DESIGN/00_DESIGN_BASIS.md §1, row "Array").

The carrier frequency f_c = 10.5 GHz and wavelength λ = 0.02857 m are the canonical values (source: 00_notation/parameter_table.md, "Inconsistency Resolutions" §1; 9_Firmware/9_1_Microcontroller/9_1_3_C_Cpp_Code/main.cpp:1133). The pulse timing coded in the firmware is: long chirp 30 µs at PRI 167 µs, short chirp 0.5 µs at PRI 175 µs, guard 175.4 µs, 32 chirps per beam position, 31 elevation positions, 50 azimuth positions per revolution (source: main.cpp:178-184, main.cpp:190; 00_notation/parameter_table.md, "Waveform and Timing"). The chirp bandwidth B is TBD in the parameter table ("Requires ADF4382 config"); every range-resolution and range-equation number in this manual that depends on B says so explicitly.

Figure 1 — F1.1 — System block diagram SYS-01, all subsystems with status legend — SOURCE-DERIVED; antenna, host PC, 22 V supply and off-board modules are CONCEPTUAL (source: engineering/SYSTEM/block_diagrams/system_block_diagram.dot; produced by Graphviz dot -Tpng -Gdpi=150)

Figure 1 — F1.1 — System block diagram SYS-01, all subsystems with status legend — SOURCE-DERIVED; antenna, host PC, 22 V supply and off-board modules are CONCEPTUAL (source: engineering/SYSTEM/block_diagrams/system_block_diagram.dot; produced by Graphviz dot -Tpng -Gdpi=150)

Figure F1.1 shows what is wired in the CAD, not what the README describes; every box and edge is traceable to a repository file (source: engineering/SYSTEM/architecture/README.md, row SYS-01). The original designer's block diagram is reproduced as F1.2 for comparison; it labels the FPGA XC7A50T-2FTG256 and names the parts FPGA, AD9708, ADF4382 TX/RX, LTC5552 ×2, LPF/BPF, AD9484, EP4RKU+, ADAR1000 ×4, ADTR1107, M3SWA2-34DR+, FT601, STM32F746ZGT7, AD8352, OCXO ECOC-2522-10.000, AD9523, XO CCHD-957-100, VCXO CVHD-950-100.000, MTX2-143+, ATS1005-3DB and "QPA2862 ×4" (the CAD has QPA2962_B) (source: engineering/SYSTEM/architecture/README.md, row SYS-01, "RADAR_V6.drawio original block names").

Figure 2 — F1.2 — Original functional block diagram RADAR_V6, draw.io 29.6.1 export — ORIGINAL PROJECT FILE, upstream authorship, not dimensioned (source: 2_Functional Diagram & Interconnection Matrices/RADAR_V6.jpg; as found)

## 2. Variants

The README specifies two variants (source: README.md, "Technical Specifications", copied verbatim):

Parameter | AERIS-10N (Nexus) | AERIS-10X (Extended)
Frequency | 10.5 GHz | 10.5 GHz
Max Range | 3 km | 20 km
Antenna | 8x16 Patch Array | 32x16 Slotted Waveguide
Beam Steering | Electronic (±45°) | Electronic (±45°)
Mechanical Scan | 360° (stepper motor) | 360° (stepper motor)
Output Power | ~1Wx16 | 10Wx16 (GaN amplifier)
Processing | FPGA + STM32 | FPGA + STM32

The hardware notes add the following per-variant differences (source: 02_hardware/01_system_overview.md §2.1, copied; gains are marked TBD in the source):

| Nexus (AERIS-10N) | Extended (AERIS-10X)
Transmit power P_t per element | 1 W (ADTR1107) | 10 W (QPA2962 GaN)
Antenna type | 8x16 patch array | 32x16 slotted waveguide
Antenna gain G | ~20 dBi (patch, TBD) | ~30 dBi (waveguide, TBD)
Detection range R_max | 3 km | 20 km

Three facts qualify this table. (1) The README names the PA-board variant "AERIS-10E" in one place and "AERIS-10X" elsewhere (source: README.md:79 vs README.md:24,83); this manual uses AERIS-10X. (2) The "±45°" steering figure is a README statement; the firmware phase table spans −160° to +160° and the parameter table derives from it a steering range it states as "approximately ±33°" (source: 00_notation/parameter_table.md, "Inconsistency Resolutions" §4) — the arithmetic disagreement between the project's own documents is recorded as observation MAN-01 in chapter 17. (3) No antenna CAD exists for either variant (conflict K8); the only antenna geometry in the repository is the PROPOSED 16-row × 8-patch panel of engineering/DESIGN/ANTENNA/ (chapter 8).

Figure 3 — F1.3 — Prototype antenna array photograph — ORIGINAL PROJECT FILE, undimensioned, not used for any dimension in this manual (source: 8_Utils/Antenna_Array.jpg; as found)

Figure 4 — F1.3b — Prototype electronics photograph — ORIGINAL PROJECT FILE, undimensioned, not used for any dimension in this manual (source: 8_Utils/0044.jpg; as found)
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

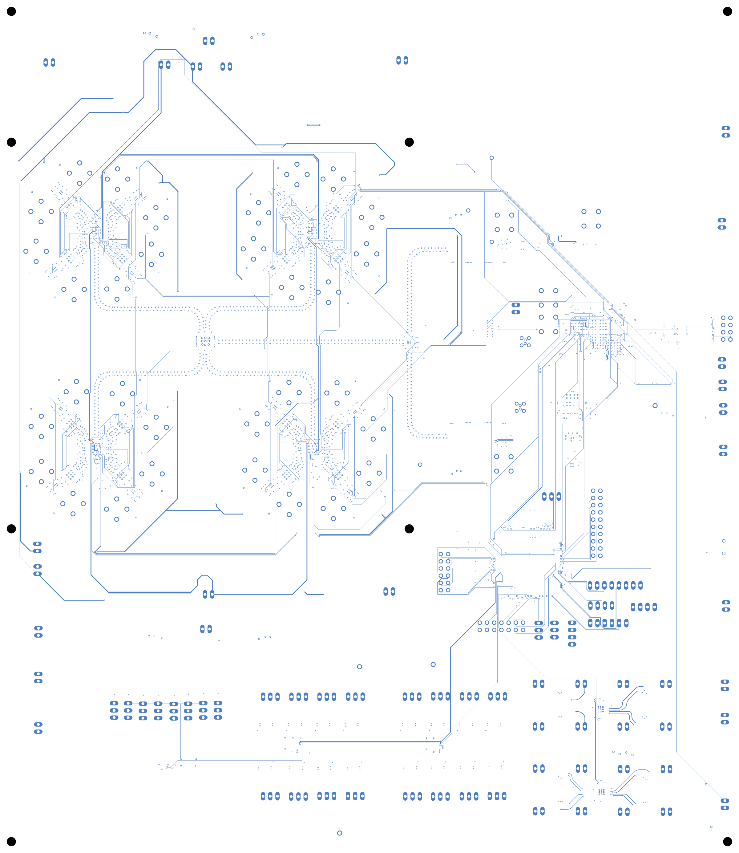
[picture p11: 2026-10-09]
manual/figures/MAIN_BOARD_bottom_composite_mirrored.png

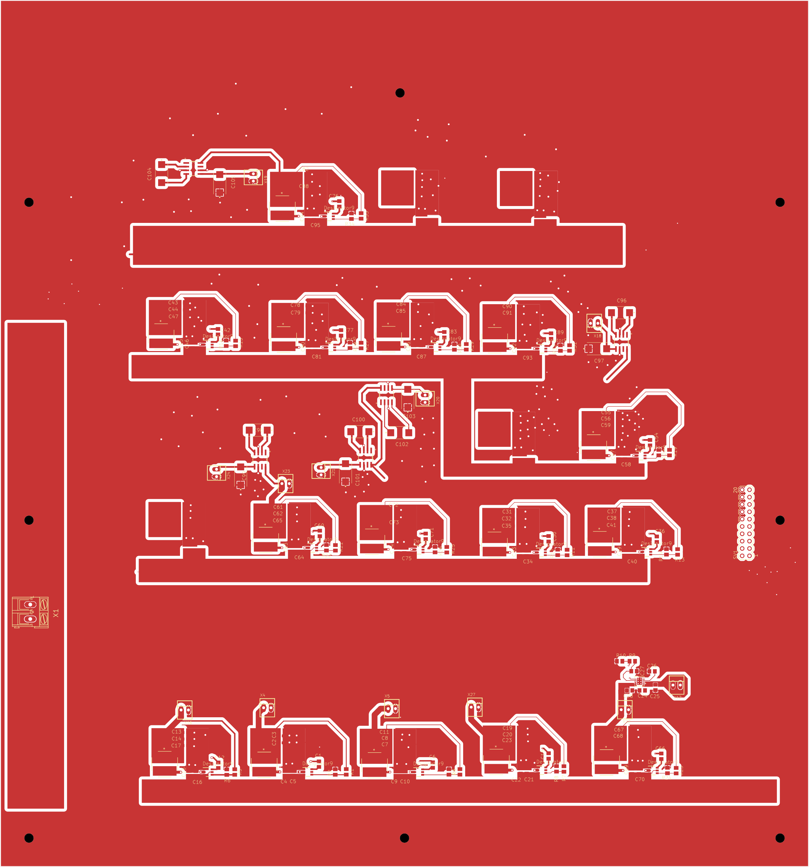
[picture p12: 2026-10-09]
manual/figures/POWER_SUPPLY_top_composite.png

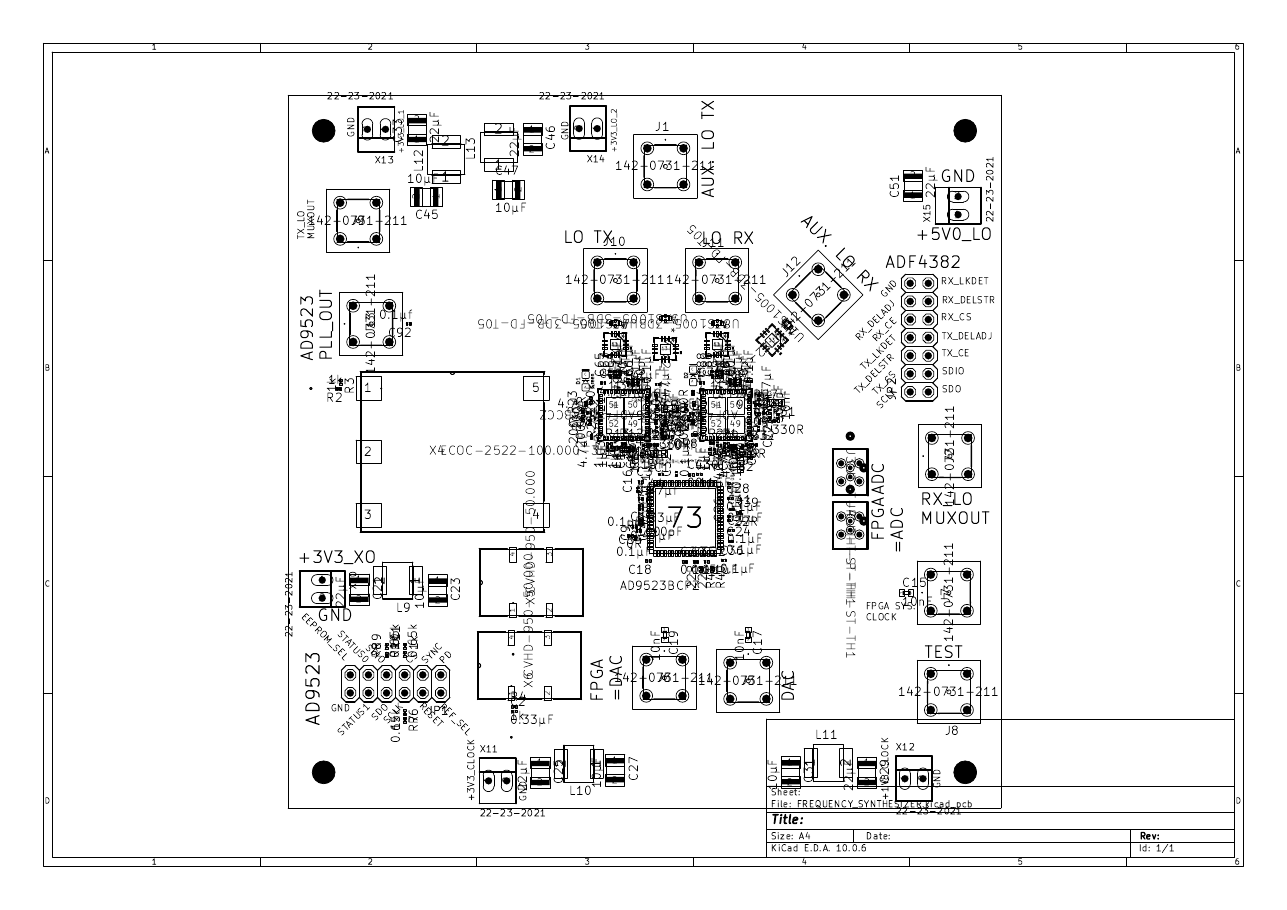
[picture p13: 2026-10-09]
manual/figures/FREQUENCY_SYNTHESIZER_assembly_top-1.png

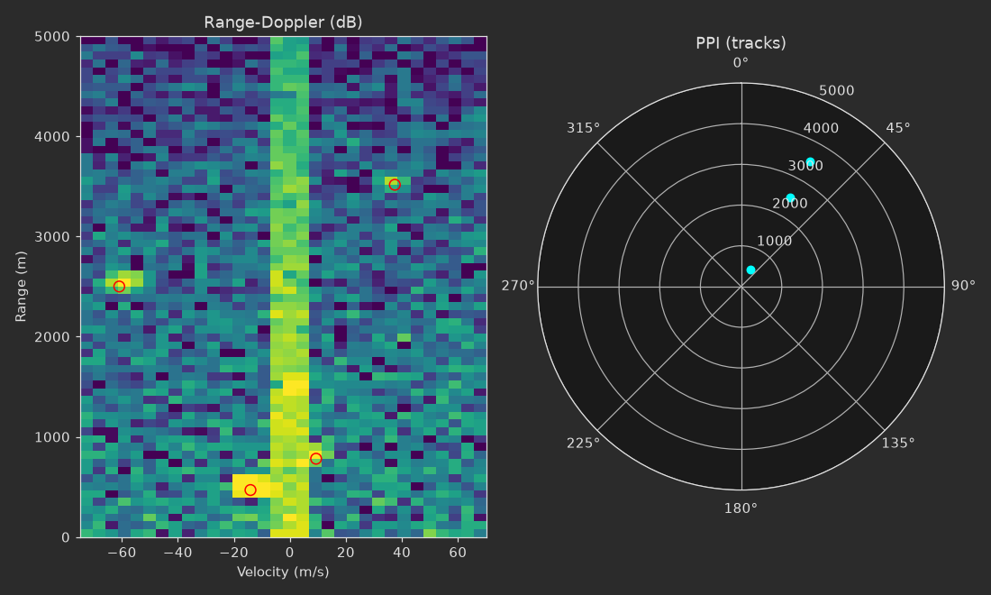
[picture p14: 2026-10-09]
manual/figures/gui_demo_plots.png

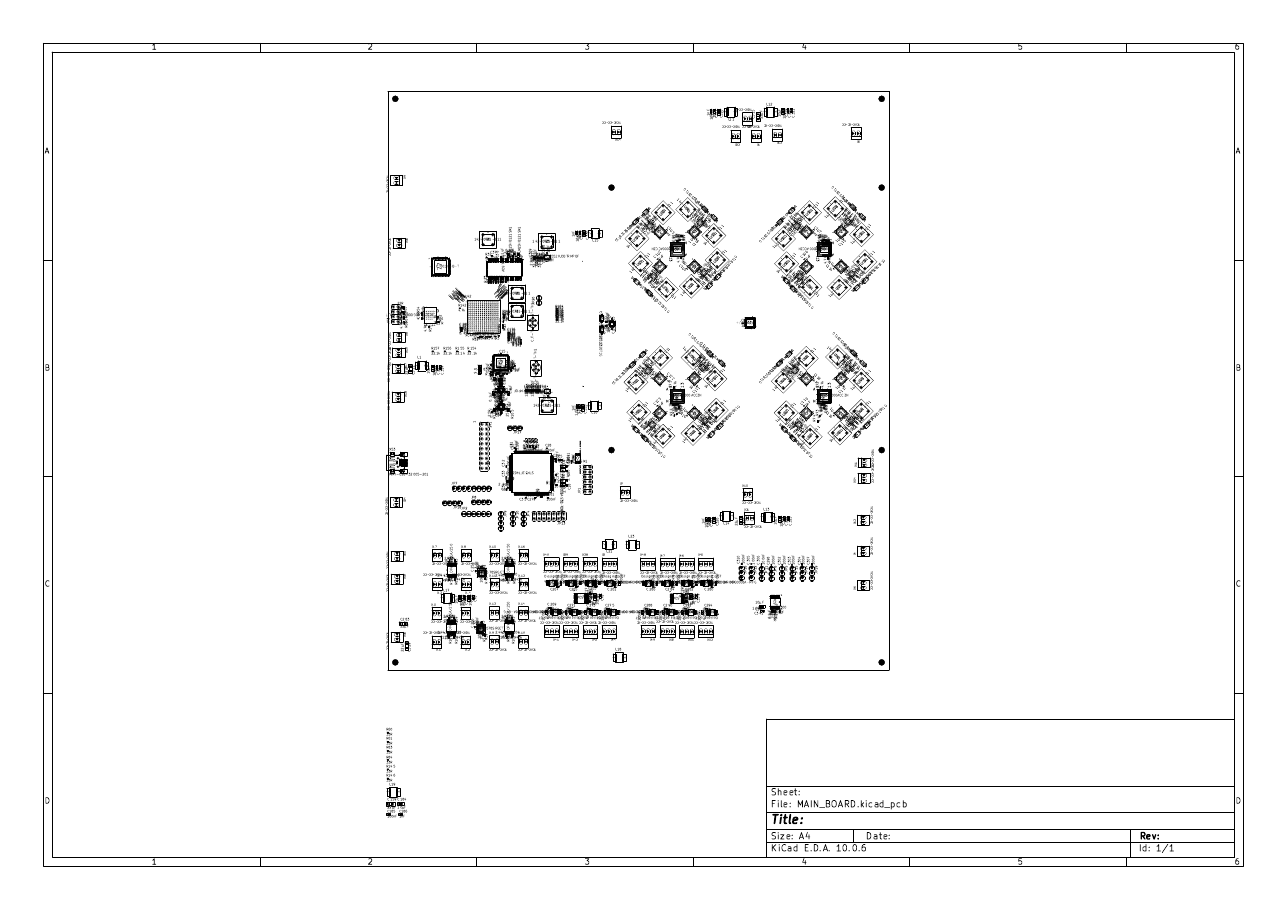
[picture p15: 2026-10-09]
manual/figures/MAIN_BOARD_assembly_top-1.png

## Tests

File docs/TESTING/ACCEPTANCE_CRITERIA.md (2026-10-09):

# Acceptance Criteria — AERIS-10 Reconstruction

Each criterion is objective, references the test ID in `VALIDATION_PLAN.md`, and states the evidence that must exist. Current status (2026-10-08) is given honestly: nothing hardware-related is accepted.

## A. FPGA

| ID | Criterion | Evidence required | Status |
|---|---|---|---|
| AC-F1 | RTL parses and elaborates with iverilog and verilator with zero errors (F-01..F-03) | `build/lint/iverilog_top.log` empty of errors; verilator 0 `%Error` | **NOT MET** |
| AC-F2 | No module instantiated without definition; all Xilinx IP as committed `.xci` | Vivado elaboration log; `ls 9_Firmware/9_2_FPGA/ip/*.xci` | **NOT MET** (6 missing) |
| AC-F3 | `cntrt.xdc` (or successor) has zero placeholders and every top-level port bit constrained or removed; F-04 exit 0 | tool output | **NOT MET** |
| AC-F4 | Pin map confirmed by the designer against the AMD FTG256 package file and the routed board | signed-off `PIN_MAP_FROM_SCHEMATIC.md` with "VERIFIED" column | **NOT MET** |
| AC-F5 | Synthesis on the confirmed part with ≤ 90 % of LUT/FF/DSP/BRAM and zero unresolved CRITICAL WARNINGs | `build/vivado/util.rpt` | **NOT MET** |
| AC-F6 | Timing closure WNS ≥ 0, WHS ≥ 0 on all constrained clocks; `report_cdc` no critical | `timing.rpt`, `cdc.rpt` | **NOT MET** |
| AC-F7 | Testbench runs on xsim with pass/fail gating and passes | sim log with 0 assertion failures | **NOT MET** |
| AC-F8 | Bitstream generated and archived with its build log | `build/vivado/*.bit` + log | **NOT MET** |
| AC-F9 | (Physical) ADC capture validated with a CW tone: correct frequency bin, no bit errors over 10 s | ILA capture / host data | NOT RUN |

## B. STM32

| ID | Criterion | Evidence | Status |
|---|---|---|---|
| AC-S1 | Cube package check exit 0 (S-02) | script output | NOT MET (no package) |
| AC-S2 | `.ioc` regenerated; generated MSP equals repository MSP in peripheral content | diff | NOT MET |
| AC-S3 | `tools/check_stm32_includes.py` exit 0 after adding Cube sources to the include path (run with `--root` of the full project) and zero case mismatches | tool output | NOT MET |
| AC-S4 | Firmware compiles and links with `arm-none-eabi-g++`, zero errors; size < 1 MB flash / 320 KB RAM | `build/stm32/*.map`, `size` output | NOT MET |
| AC-S5 | Conflicts C1–C7 closed with documented decisions | `docs/04_RECOVERY_TASKS.md` entries R-STM-xx marked DONE | NOT MET |
| AC-S6 | (Physical) CDC enumerates; start flag + settings accepted; status string received | host log | NOT RUN |
| AC-S7 | (Physical) rail sequencing order and delays match `Power Management V6.xlsx` | scope captures | NOT RUN |

## C. Python GUI

| ID | Criterion | Evidence | Status |
|---|---|---|---|
| AC-P1 | `pip install -r requirements.txt` succeeds on a clean venv (P-01) | pip log | **MET** (2026-10-08, Python 3.14.7) |
| AC-P2 | All third-party imports succeed (P-03) | tool output | **MET** for GUI modules |
| AC-P3 | Every file in `9_Firmware/9_3_GUI` parses (P-02) | tool exit 0 | NOT MET (`GUI_V1.py`) |
| AC-P4 | `GUI_V6_Demo.py` starts, shows moving targets, closes with exit 0 (P-07) | screenshot + exit code | NOT RUN |
| AC-P5 | A unit-test suite exists and passes (parsers, CFAR, packet decode) (P-06) | pytest log | NOT MET (no tests) |
| AC-P6 | One hardware GUI decodes the real firmware/FPGA packet format end-to-end (P-09) | capture + decoded targets | NOT RUN (formats inconsistent today) |
| AC-P7 | Packaged demo runs on a machine without Python | installer test log | NOT RUN |

## D. PCB

| ID | Criterion | Evidence | Status |
|---|---|---|---|
| AC-B1 | Fresh ERC and DRC reports with 0 unapproved errors for each board (B-01, B-02); every approved error justified | reports under `docs/PCB/reports/` (to be created) | NOT MET |
| AC-B2 | `RATSNEST` "Nothing to do" and 0 elements outside the outline for Main and Power | EAGLE status line screenshot | NOT MET |
| AC-B3 | sch/brd consistent, single EAGLE version per board (B-04) | consistency check pass | NOT MET (Main, Power) |
| AC-B4 | Gerber + drill + fab + assembly + P&P + BOM(MPN) + schematic PDF for all four boards (B-06 exit 0) | `tools/check_manufacturing_files.py` exit 0 | **PARTIALLY MET** (2026-10-09): a complete *generated* package exists for all four boards (`engineering/PCB/<BOARD>/`, KiCad conversion; `--include-generated` exit 0) and schematic PDFs (`engineering/ELECTRICAL/schematics/`); NOT MET for the designer-released EAGLE export (`4_Schematics and Boards Layout/4_7_Production Files/`), MPNs and vendor fab notes |
| AC-B5 | BOMs 100 % MPN, 0 empty values, DNP column (B-05) | `docs/BOM/*` regenerated with `mpn_status` all VERIFIED | NOT MET |
| AC-B6 | Vendor stack-up drawing per board consistent with DRU and impedance note | fab documents | NOT MET |
| AC-B7 | (Physical) impedance coupons 50 Ω ± 10 %, 100 Ω ± 8 % | TDR report | NOT RUN |
| AC-B8 | Design conflicts K1 (FPGA part), K2 (HSE), K3 (host link), K4 (PA supply), K7 (oscillators) closed | decision records | NOT MET |

## E. Mechanical

| ID | Criterion | Evidence | Status |
|---|---|---|---|
| AC-M1 | Outline/hole drawings for all PCBs | `docs/MECHANICAL/drawings/*.svg`; `engineering/MECHANICAL/` (DXF, STEP, 1:1 plan view, dimension sheets) | **MET** (generated from `.brd`; thickness ASSUMED) |
| AC-M2 | Enclosure, antenna and pedestal CAD committed with drawings | STEP + PDF under `10_docs/Hardware/` (missing today) | NOT MET |
| AC-M3 | Assembly guide `10_docs/assembly_guide.md` (missing today) with the content of `ASSEMBLY_DOCUMENTATION_REQUIREMENTS.md` §2 | file exists, link check passes | NOT MET |
| AC-M4 | Exploded view with balloons matching BOM | PDF | PARTIAL (2026-10-09): CONCEPTUAL view `engineering/ASSEMBLY/EXPLODED_VIEWS/aeris10_exploded_conceptual.pdf` with balloons ↔ `PARTS_LIST.md`; real geometry BLOCKED (MDR-06) |
| AC-M5 | Mass table per assembly | measured or CAD-derived values | NOT MET |

## F. Documentation / repository

| ID | Criterion | Evidence | Status |
|---|---|---|---|
| AC-D1 | Documentation tree of `claude.md` §13 present | `tools/check_missing_files.py` DOC-* all present | **MET** after this reconstruction |
| AC-D2 | `tools/check_doc_links.py` exit 0 | tool output | NOT MET (pre-existing broken links listed in VALIDATION_PLAN R-02) |
| AC-D3 | README corrected: Gerber claim, FPGA part, `10_docs` references | diff | NOT MET (README not modified — content change needs the owner's decision) |
| AC-D4 | LICENSE file consistent with the MIT badge; `.gitignore` | files | NOT MET |
| AC-D5 | Every P0 item in `docs/03_MISSING_COMPONENTS.md` has an owner and a recovery task | `docs/04_RECOVERY_TASKS.md` | **MET** (tasks defined; none closed) |

## G. Engineering drawings package (added 2026-10-09)

| ID | Criterion | Evidence | Status |
|---|---|---|---|
| AC-E1 | Every drawing in `engineering/DRAWING_REGISTER.md` has its native file and exports present and well-formed | `python3 tools/gen_drawing_register.py --check` exit 0 | **MET** (89 drawings incl. 16 PROPOSED, 0 problems — regenerated 2026-10-09) |
| AC-E2 | EAGLE XML ↔ KiCad conversion counts agree for all boards | `engineering/VALIDATION/PCB_CROSS_CHECK.md` | **MET** (32/32 rows OK) |
| AC-E3 | No missing symbols/footprints; schematic ↔ board part lists identical | `tools/gen_schematic_reports.py` exit 0 | **MET** |
| AC-E4 | Any drawing VERIFIED against EAGLE output or hardware | `VALIDATION/DRAWING_CHECKS.md` §2 | NOT MET (0 VERIFIED) |
| AC-E5 | Enclosure/antenna/pedestal/cooling drawings exist | register MECH-ENC/ANT/PED/COOL | NOT MET (BLOCKED — MISSING DATA) |
| AC-E6 | Proposed designs (DSN-*) registered with native editable files and exports present | `tools/gen_drawing_register.py --check` | **MET** (16 PROPOSED entries, 0 file problems) |
| AC-E7 | Antenna proposal simulated (|S11| < −10 dB at f0 ± B/2) and coupon measured | openEMS log + VNA data | NOT RUN |
| AC-E8 | Owner approval of decisions D-01…D-15 recorded | signed decision log | NOT MET |

## H. BETA tree (added 2026-10-09) — criteria evaluated on `beta/`, not on the originals

| ID | Criterion | Evidence | Status |
|---|---|---|---|
| AC-X1 | beta RTL parses/elaborates/lints with 0 errors and all testbenches pass | `beta/fpga/logs/` | **MET** (BETA) |
| AC-X2 | beta firmware compiles and links; host tests pass (6/6) | `beta/stm32/build_out/`, `logs/` | **MET** (BETA) |
| AC-X3 | beta GUI test suite passes; packaged app starts | `beta/gui` pytest 76 passed; selftest OK | **MET** (BETA) |
| AC-X4 | beta boards: 0 unconnected on Main/RF PA/Synth; Power ≤ 100 open with documented reasons | `beta/pcb/*/exports/reports/DRC_report.json` | **MET** (BETA; Power 89 listed) |
| AC-X5 | host-link bridge testbench, firmware build and GUI parser agree on one frame vector | `tb_frame.hex` shared | **MET** (BETA) |
| AC-X6 | antenna row S11 < −10 dB at f0 in simulation | `TUNING_LOG.md` | **MET** (−18 dB; band 128 MHz) |

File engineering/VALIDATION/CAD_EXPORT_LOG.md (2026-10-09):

# CAD export log

Appended automatically by `tools/kicad_pcb_pipeline.sh`. Each row: UTC time, board, step, exit code, command.

| Time (UTC) | Board | Step | Exit | Command |
|---|---|---|---|---|

_Run 2026-10-08T22:10:42Z with kicad-cli 10.0.6_

| 2026-10-08T22:10:42Z | RF_PA | import | 0 | `~/Applications/KiCad/KiCad.app/Contents/MacOS/kicad-cli pcb import --format eagle --report-format text --report-file engineering/PCB/RF_PA/reports/kicad_import_report.txt -o engineering/PCB/RF_PA/kicad/RF_PA.kicad_pcb 4_Schematics\ and\ Boards\ Layout/4_6_Schematics/PowerAmplifierBoard/RF_PA.brd ` |
| 2026-10-08T22:10:42Z | RF_PA | project-from-dru | 0 | `python3 tools/kicad_project_from_dru.py 4_Schematics\ and\ Boards\ Layout/4_6_Schematics/PowerAmplifierBoard/RF_PA.brd engineering/PCB/RF_PA/kicad/RF_PA.kicad_pcb --md engineering/PCB/RF_PA/reports/design_rules_mapping.md ` |
| 2026-10-08T22:10:42Z | RF_PA | drc | 0 | `~/Applications/KiCad/KiCad.app/Contents/MacOS/kicad-cli pcb drc --format report --severity-all --all-track-errors --refill-zones --save-board --units mm -o engineering/PCB/RF_PA/reports/DRC_report.txt engineering/PCB/RF_PA/kicad/RF_PA.kicad_pcb ` |
| 2026-10-08T22:10:43Z | RF_PA | drc-json | 0 | `~/Applications/KiCad/KiCad.app/Contents/MacOS/kicad-cli pcb drc --format json --severity-all --units mm -o engineering/PCB/RF_PA/reports/DRC_report.json engineering/PCB/RF_PA/kicad/RF_PA.kicad_pcb ` |
| 2026-10-08T22:10:44Z | RF_PA | stats | 0 | `~/Applications/KiCad/KiCad.app/Contents/MacOS/kicad-cli pcb export stats -o engineering/PCB/RF_PA/reports/board_statistics.md engineering/PCB/RF_PA/kicad/RF_PA.kicad_pcb ` |
| 2026-10-08T22:10:44Z | RF_PA | gerbers | 0 | `~/Applications/KiCad/KiCad.app/Contents/MacOS/kicad-cli pcb export gerbers --check-zones --subtract-soldermask -l F.Cu\,In1.Cu\,In2.Cu\,B.Cu\,F.Mask\,B.Mask\,F.Paste\,B.Paste\,F.SilkS\,B.SilkS\,Edge.Cuts\,F.Fab\,B.Fab -o engineering/PCB/RF_PA/gerber/ engineering/PCB/RF_PA/kicad/RF_PA.kicad_pcb ` |
| 2026-10-08T22:10:44Z | RF_PA | drill | 0 | `~/Applications/KiCad/KiCad.app/Contents/MacOS/kicad-cli pcb export drill --format excellon --excellon-units mm --excellon-separate-th --generate-map --map-format pdf --generate-report --report-path engineering/PCB/RF_PA/drill/drill_report.txt -o engineering/PCB/RF_PA/drill/ engineering/PCB/RF_PA/kicad/RF_PA.kicad_pcb ` |
| 2026-10-08T22:10:44Z | RF_PA | pdf-copper | 0 | `~/Applications/KiCad/KiCad.app/Contents/MacOS/kicad-cli pcb export pdf --check-zones --mode-multipage --cl Edge.Cuts -l F.Cu\,In1.Cu\,In2.Cu\,B.Cu --ibt -o engineering/PCB/RF_PA/drawings/RF_PA_copper_layers.pdf engineering/PCB/RF_PA/kicad/RF_PA.kicad_pcb ` |
| 2026-10-08T22:10:45Z | RF_PA | pdf-asm-top | 0 | `~/Applications/KiCad/KiCad.app/Contents/MacOS/kicad-cli pcb export pdf --mode-single --sp -l F.Fab\,F.SilkS\,Edge.Cuts --ibt --black-and-white -o engineering/PCB/RF_PA/drawings/RF_PA_assembly_top.pdf engineering/PCB/RF_PA/kicad/RF_PA.kicad_pcb ` |
| 2026-10-08T22:10:45Z | RF_PA | pdf-asm-bot | 0 | `~/Applications/KiCad/KiCad.app/Contents/MacOS/kicad-cli pcb export pdf --mode-single --sp -m -l B.Fab\,B.SilkS\,Edge.Cuts --ibt --black-and-white -o engineering/PCB/RF_PA/drawings/RF_PA_assembly_bottom_mirrored.pdf engineering/PCB/RF_PA/kicad/RF_PA.kicad_pcb ` |
| 2026-10-08T22:10:45Z | RF_PA | pdf-top | 0 | `~/Applications/KiCad/KiCad.app/Contents/MacOS/kicad-cli pcb export pdf --check-zones --mode-single -l F.Cu\,F.SilkS\,Edge.Cuts --ibt -o engineering/PCB/RF_PA/drawings/RF_PA_top_layer.pdf engineering/PCB/RF_PA/kicad/RF_PA.kicad_pcb ` |
| 2026-10-08T22:10:46Z | RF_PA | pdf-bottom | 0 | `~/Applications/KiCad/KiCad.app/Contents/MacOS/kicad-cli pcb export pdf --check-zones --mode-single -m -l B.Cu\,B.SilkS\,Edge.Cuts --ibt -o engineering/PCB/RF_PA/drawings/RF_PA_bottom_layer_mirrored.pdf engineering/PCB/RF_PA/kicad/RF_PA.kicad_pcb ` |
| 2026-10-08T22:10:46Z | RF_PA | pdf-outline | 0 | `~/Applications/KiCad/KiCad.app/Contents/MacOS/kicad-cli pcb export pdf --mode-single -l Edge.Cuts\,Dwgs.User\,Cmts.User --ibt --black-and-white -o engineering/PCB/RF_PA/drawings/RF_PA_outline.pdf engineering/PCB/RF_PA/kicad/RF_PA.kicad_pcb ` |
| 2026-10-08T22:10:46Z | RF_PA | svg | 0 | `~/Applications/KiCad/KiCad.app/Contents/MacOS/kicad-cli pcb export svg --check-zones --mode-multi --page-size-mode 2 -l F.Cu\,In1.Cu\,In2.Cu\,B.Cu\,F.SilkS\,B.SilkS\,F.Mask\,B.Mask\,Edge.Cuts\,F.Fab\,B.Fab -o engineering/PCB/RF_PA/svg/ engineering/PCB/RF_PA/kicad/RF_PA.kicad_pcb ` |
| 2026-10-08T22:10:47Z | RF_PA | svg-top | 0 | `~/Applications/KiCad/KiCad.app/Contents/MacOS/kicad-cli pcb export svg --check-zones --mode-single --page-size-mode 2 -l F.Cu\,F.SilkS\,Edge.Cuts -o engineering/PCB/RF_PA/svg/RF_PA_top_composite.svg engineering/PCB/RF_PA/kicad/RF_PA.kicad_pcb ` |
| 2026-10-08T22:10:47Z | RF_PA | svg-bottom | 0 | `~/Applications/KiCad/KiCad.app/Contents/MacOS/kicad-cli pcb export svg --check-zones --mode-single --page-size-mode 2 -m -l B.Cu\,B.SilkS\,Edge.Cuts -o engineering/PCB/RF_PA/svg/RF_PA_bottom_composite_mirrored.svg engineering/PCB/RF_PA/kicad/RF_PA.kicad_pcb ` |
| 2026-10-08T22:10:47Z | RF_PA | dxf-outline | 0 | `~/Applications/KiCad/KiCad.app/Contents/MacOS/kicad-cli pcb export dxf --mode-single --ou mm --uc -l Edge.Cuts -o engineering/PCB/RF_PA/mechanical/RF_PA_outline.dxf engineering/PCB/RF_PA/kicad/RF_PA.kicad_pcb ` |
| 2026-10-08T22:10:47Z | RF_PA | dxf-fab | 0 | `~/Applications/KiCad/KiCad.app/Contents/MacOS/kicad-cli pcb export dxf --mode-single --ou mm --uc -l Edge.Cuts\,F.Fab\,F.SilkS -o engineering/PCB/RF_PA/mechanical/RF_PA_top_fab.dxf engineering/PCB/RF_PA/kicad/RF_PA.kicad_pcb ` |
| 2026-10-08T22:10:48Z | RF_PA | step | 0 | `~/Applications/KiCad/KiCad.app/Contents/MacOS/kicad-cli pcb export step --board-only --force -o engineering/PCB/RF_PA/mechanical/RF_PA_board_only.step engineering/PCB/RF_PA/kicad/RF_PA.kicad_pcb ` |
| 2026-10-08T22:10:48Z | RF_PA | pos | 0 | `~/Applications/KiCad/KiCad.app/Contents/MacOS/kicad-cli pcb export pos --format csv --units mm --side both -o engineering/PCB/RF_PA/assembly/RF_PA_pick_and_place.csv engineering/PCB/RF_PA/kicad/RF_PA.kicad_pcb ` |
| 2026-10-08T22:10:48Z | RF_PA | ipc2581 | 0 | `~/Applications/KiCad/KiCad.app/Contents/MacOS/kicad-cli pcb export ipc2581 -o engineering/PCB/RF_PA/ipc/RF_PA.xml engineering/PCB/RF_PA/kicad/RF_PA.kicad_pcb ` |
| 2026-10-08T22:10:49Z | RF_PA | ipcd356 | 0 | `~/Applications/KiCad/KiCad.app/Contents/MacOS/kicad-cli pcb export ipcd356 -o engineering/PCB/RF_PA/ipc/RF_PA_netlist.d356 engineering/PCB/RF_PA/kicad/RF_PA.kicad_pcb ` |
| 2026-10-08T22:10:49Z | RF_PA | render-top | 0 | `~/Applications/KiCad/KiCad.app/Contents/MacOS/kicad-cli pcb render --side top --background opaque --quality high -w 2400 -h 1800 -o engineering/PCB/RF_PA/3d/RF_PA_render_top.png engineering/PCB/RF_PA/kicad/RF_PA.kicad_pcb ` |
| 2026-10-08T22:10:54Z | RF_PA | render-bottom | 0 | `~/Applications/KiCad/KiCad.app/Contents/MacOS/kicad-cli pcb render --side bottom --background opaque --quality high -w 2400 -h 1800 -o engineering/PCB/RF_PA/3d/RF_PA_render_bottom.png engineering/PCB/RF_PA/kicad/RF_PA.kicad_pcb ` |
| 2026-10-08T22:10:58Z | RF_PA | render-iso | 0 | `~/Applications/KiCad/KiCad.app/Contents/MacOS/kicad-cli pcb render --side top --rotate -45\,0\,30 --perspective --background opaque --quality high -w 2400 -h 1800 -o engineering/PCB/RF_PA/3d/RF_PA_render_isometric.png engineering/PCB/RF_PA/kicad/RF_PA.kicad_pcb ` |

_Run 2026-10-08T22:11:11Z with kicad-cli 10.0.6_

| 2026-10-08T22:11:11Z | FREQUENCY_SYNTHESIZER | import | 0 | `~/Applications/KiCad/KiCad.app/Contents/MacOS/kicad-cli pcb import --format eagle --report-format text --report-file engineering/PCB/FREQUENCY_SYNTHESIZER/reports/kicad_import_report.txt -o engineering/PCB/FREQUENCY_SYNTHESIZER/kicad/FREQUENCY_SYNTHESIZER.kicad_pcb 4_Schematics\ and\ Boards\ Layout/4_6_Schematics/FrequencySynthesizerBoard/Clocks_Freq_Synth_board.brd ` |
| 2026-10-08T22:11:11Z | FREQUENCY_SYNTHESIZER | remap-undefined-layer | 0 | `694 items on EAGLE layer 47 Measures → Dwgs.User` |
| 2026-10-08T22:11:11Z | FREQUENCY_SYNTHESIZER | project-from-dru | 0 | `python3 tools/kicad_project_from_dru.py 4_Schematics\ and\ Boards\ Layout/4_6_Schematics/FrequencySynthesizerBoard/Clocks_Freq_Synth_board.brd engineering/PCB/FREQUENCY_SYNTHESIZER/kicad/FREQUENCY_SYNTHESIZER.kicad_pcb --md engineering/PCB/FREQUENCY_SYNTHESIZER/reports/design_rules_mapping.md ` |
| 2026-10-08T22:11:11Z | FREQUENCY_SYNTHESIZER | drc | 0 | `~/Applications/KiCad/KiCad.app/Contents/MacOS/kicad-cli pcb drc --format report --severity-all --all-track-errors --refill-zones --save-board --units mm -o engineering/PCB/FREQUENCY_SYNTHESIZER/reports/DRC_report.txt engineering/PCB/FREQUENCY_SYNTHESIZER/kicad/FREQUENCY_SYNTHESIZER.kicad_pcb ` |
| 2026-10-08T22:11:12Z | FREQUENCY_SYNTHESIZER | drc-json | 0 | `~/Applications/KiCad/KiCad.app/Contents/MacOS/kicad-cli pcb drc --format json --severity-all --units mm -o engineering/PCB/FREQUENCY_SYNTHESIZER/reports/DRC_report.json engineering/PCB/FREQUENCY_SYNTHESIZER/kicad/FREQUENCY_SYNTHESIZER.kicad_pcb ` |
| 2026-10-08T22:11:13Z | FREQUENCY_SYNTHESIZER | stats | 0 | `~/Applications/KiCad/KiCad.app/Contents/MacOS/kicad-cli pcb export stats -o engineering/PCB/FREQUENCY_SYNTHESIZER/reports/board_statistics.md engineering/PCB/FREQUENCY_SYNTHESIZER/kicad/FREQUENCY_SYNTHESIZER.kicad_pcb ` |
| 2026-10-08T22:11:14Z | FREQUENCY_SYNTHESIZER | gerbers | 0 | `~/Applications/KiCad/KiCad.app/Contents/MacOS/kicad-cli pcb export gerbers --check-zones --subtract-soldermask -l F.Cu\,In1.Cu\,In2.Cu\,In3.Cu\,In4.Cu\,B.Cu\,F.Mask\,B.Mask\,F.Paste\,B.Paste\,F.SilkS\,B.SilkS\,Edge.Cuts\,F.Fab\,B.Fab -o engineering/PCB/FREQUENCY_SYNTHESIZER/gerber/ engineering/PCB/FREQUENCY_SYNTHESIZER/kicad/FREQUENCY_SYNTHESIZER.kicad_pcb ` |
| 2026-10-08T22:11:14Z | FREQUENCY_SYNTHESIZER | drill | 0 | `~/Applications/KiCad/KiCad.app/Contents/MacOS/kicad-cli pcb export drill --format excellon --excellon-units mm --excellon-separate-th --generate-map --map-format pdf --generate-report --report-path engineering/PCB/FREQUENCY_SYNTHESIZER/drill/drill_report.txt -o engineering/PCB/FREQUENCY_SYNTHESIZER/drill/ engineering/PCB/FREQUENCY_SYNTHESIZER/kicad/FREQUENCY_SYNTHESIZER.kicad_pcb ` |
| 2026-10-08T22:11:14Z | FREQUENCY_SYNTHESIZER | pdf-copper | 0 | `~/Applications/KiCad/KiCad.app/Contents/MacOS/kicad-cli pcb export pdf --check-zones --mode-multipage --cl Edge.Cuts -l F.Cu\,In1.Cu\,In2.Cu\,In3.Cu\,In4.Cu\,B.Cu --ibt -o engineering/PCB/FREQUENCY_SYNTHESIZER/drawings/FREQUENCY_SYNTHESIZER_copper_layers.pdf engineering/PCB/FREQUENCY_SYNTHESIZER/kicad/FREQUENCY_SYNTHESIZER.kicad_pcb ` |
| 2026-10-08T22:11:15Z | FREQUENCY_SYNTHESIZER | pdf-asm-top | 0 | `~/Applications/KiCad/KiCad.app/Contents/MacOS/kicad-cli pcb export pdf --mode-single --sp -l F.Fab\,F.SilkS\,Edge.Cuts --ibt --black-and-white -o engineering/PCB/FREQUENCY_SYNTHESIZER/drawings/FREQUENCY_SYNTHESIZER_assembly_top.pdf engineering/PCB/FREQUENCY_SYNTHESIZER/kicad/FREQUENCY_SYNTHESIZER.kicad_pcb ` |
| 2026-10-08T22:11:15Z | FREQUENCY_SYNTHESIZER | pdf-asm-bot | 0 | `~/Applications/KiCad/KiCad.app/Contents/MacOS/kicad-cli pcb export pdf --mode-single --sp -m -l B.Fab\,B.SilkS\,Edge.Cuts --ibt --black-and-white -o engineering/PCB/FREQUENCY_SYNTHESIZER/drawings/FREQUENCY_SYNTHESIZER_assembly_bottom_mirrored.pdf engineering/PCB/FREQUENCY_SYNTHESIZER/kicad/FREQUENCY_SYNTHESIZER.kicad_pcb ` |
| 2026-10-08T22:11:16Z | FREQUENCY_SYNTHESIZER | pdf-top | 0 | `~/Applications/KiCad/KiCad.app/Contents/MacOS/kicad-cli pcb export pdf --check-zones --mode-single -l F.Cu\,F.SilkS\,Edge.Cuts --ibt -o engineering/PCB/FREQUENCY_SYNTHESIZER/drawings/FREQUENCY_SYNTHESIZER_top_layer.pdf engineering/PCB/FREQUENCY_SYNTHESIZER/kicad/FREQUENCY_SYNTHESIZER.kicad_pcb ` |
| 2026-10-08T22:11:16Z | FREQUENCY_SYNTHESIZER | pdf-bottom | 0 | `~/Applications/KiCad/KiCad.app/Contents/MacOS/kicad-cli pcb export pdf --check-zones --mode-single -m -l B.Cu\,B.SilkS\,Edge.Cuts --ibt -o engineering/PCB/FREQUENCY_SYNTHESIZER/drawings/FREQUENCY_SYNTHESIZER_bottom_layer_mirrored.pdf engineering/PCB/FREQUENCY_SYNTHESIZER/kicad/FREQUENCY_SYNTHESIZER.kicad_pcb ` |
| 2026-10-08T22:11:17Z | FREQUENCY_SYNTHESIZER | pdf-outline | 0 | `~/Applications/KiCad/KiCad.app/Contents/MacOS/kicad-cli pcb export pdf --mode-single -l Edge.Cuts\,Dwgs.User\,Cmts.User --ibt --black-and-white -o engineering/PCB/FREQUENCY_SYNTHESIZER/drawings/FREQUENCY_SYNTHESIZER_outline.pdf engineering/PCB/FREQUENCY_SYNTHESIZER/kicad/FREQUENCY_SYNTHESIZER.kicad_pcb ` |
| 2026-10-08T22:11:17Z | FREQUENCY_SYNTHESIZER | svg | 0 | `~/Applications/KiCad/KiCad.app/Contents/MacOS/kicad-cli pcb export svg --check-zones --mode-multi --page-size-mode 2 -l F.Cu\,In1.Cu\,In2.Cu\,In3.Cu\,In4.Cu\,B.Cu\,F.SilkS\,B.SilkS\,F.Mask\,B.Mask\,Edge.Cuts\,F.Fab\,B.Fab -o engineering/PCB/FREQUENCY_SYNTHESIZER/svg/ engineering/PCB/FREQUENCY_SYNTHESIZER/kicad/FREQUENCY_SYNTHESIZER.kicad_pcb ` |
| 2026-10-08T22:11:18Z | FREQUENCY_SYNTHESIZER | svg-top | 0 | `~/Applications/KiCad/KiCad.app/Contents/MacOS/kicad-cli pcb export svg --check-zones --mode-single --page-size-mode 2 -l F.Cu\,F.SilkS\,Edge.Cuts -o engineering/PCB/FREQUENCY_SYNTHESIZER/svg/FREQUENCY_SYNTHESIZER_top_composite.svg engineering/PCB/FREQUENCY_SYNTHESIZER/kicad/FREQUENCY_SYNTHESIZER.kicad_pcb ` |
| 2026-10-08T22:11:18Z | FREQUENCY_SYNTHESIZER | svg-bottom | 0 | `~/Applications/KiCad/KiCad.app/Contents/MacOS/kicad-cli pcb export svg --check-zones --mode-single --page-size-mode 2 -m -l B.Cu\,B.SilkS\,Edge.Cuts -o engineering/PCB/FREQUENCY_SYNTHESIZER/svg/FREQUENCY_SYNTHESIZER_bottom_composite_mirrored.svg engineering/PCB/FREQUENCY_SYNTHESIZER/kicad/FREQUENCY_SYNTHESIZER.kicad_pcb ` |
| 2026-10-08T22:11:19Z | FREQUENCY_SYNTHESIZER | dxf-outline | 0 | `~/Applications/KiCad/KiCad.app/Contents/MacOS/kicad-cli pcb export dxf --mode-single --ou mm --uc -l Edge.Cuts -o engineering/PCB/FREQUENCY_SYNTHESIZER/mechanical/FREQUENCY_SYNTHESIZER_outline.dxf engineering/PCB/FREQUENCY_SYNTHESIZER/kicad/FREQUENCY_SYNTHESIZER.kicad_pcb ` |
| 2026-10-08T22:11:19Z | FREQUENCY_SYNTHESIZER | dxf-fab | 0 | `~/Applications/KiCad/KiCad.app/Contents/MacOS/kicad-cli pcb export dxf --mode-single --ou mm --uc -l Edge.Cuts\,F.Fab\,F.SilkS -o engineering/PCB/FREQUENCY_SYNTHESIZER/mechanical/FREQUENCY_SYNTHESIZER_top_fab.dxf engineering/PCB/FREQUENCY_SYNTHESIZER/kicad/FREQUENCY_SYNTHESIZER.kicad_pcb ` |
| 2026-10-08T22:11:19Z | FREQUENCY_SYNTHESIZER | step | 0 | `~/Applications/KiCad/KiCad.app/Contents/MacOS/kicad-cli pcb export step --board-only --force -o engineering/PCB/FREQUENCY_SYNTHESIZER/mechanical/FREQUENCY_SYNTHESIZER_board_only.step engineering/PCB/FREQUENCY_SYNTHESIZER/kicad/FREQUENCY_SYNTHESIZER.kicad_pcb ` |
| 2026-10-08T22:11:20Z | FREQUENCY_SYNTHESIZER | pos | 0 | `~/Applications/KiCad/KiCad.app/Contents/MacOS/kicad-cli pcb export pos --format csv --units mm --side both -o engineering/PCB/FREQUENCY_SYNTHESIZER/assembly/FREQUENCY_SYNTHESIZER_pick_and_place.csv engineering/PCB/FREQUENCY_SYNTHESIZER/kicad/FREQUENCY_SYNTHESIZER.kicad_pcb ` |
| 2026-10-08T22:11:20Z | FREQUENCY_SYNTHESIZER | ipc2581 | 0 | `~/Applications/KiCad/KiCad.app/Contents/MacOS/kicad-cli pcb export ipc2581 -o engineering/PCB/FREQUENCY_SYNTHESIZER/ipc/FREQUENCY_SYNTHESIZER.xml engineering/PCB/FREQUENCY_SYNTHESIZER/kicad/FREQUENCY_SYNTHESIZER.kicad_pcb ` |
| 2026-10-08T22:11:24Z | FREQUENCY_SYNTHESIZER | ipcd356 | 0 | `~/Applications/KiCad/KiCad.app/Contents/MacOS/kicad-cli pcb export ipcd356 -o engineering/PCB/FREQUENCY_SYNTHESIZER/ipc/FREQUENCY_SYNTHESIZER_netlist.d356 engineering/PCB/FREQUENCY_SYNTHESIZER/kicad/FREQUENCY_SYNTHESIZER.kicad_pcb ` |
| 2026-10-08T22:11:24Z | FREQUENCY_SYNTHESIZER | render-top | 0 | `~/Applications/KiCad/KiCad.app/Contents/MacOS/kicad-cli pcb render --side top --background opaque --quality high -w 2400 -h 1800 -o engineering/PCB/FREQUENCY_SYNTHESIZER/3d/FREQUENCY_SYNTHESIZER_render_top.png engineering/PCB/FREQUENCY_SYNTHESIZER/kicad/FREQUENCY_SYNTHESIZER.kicad_pcb ` |
| 2026-10-08T22:11:31Z | FREQUENCY_SYNTHESIZER | render-bottom | 0 | `~/Applications/KiCad/KiCad.app/Contents/MacOS/kicad-cli pcb render --side bottom --background opaque --quality high -w 2400 -h 1800 -o engineering/PCB/FREQUENCY_SYNTHESIZER/3d/FREQUENCY_SYNTHESIZER_render_bottom.png engineering/PCB/FREQUENCY_SYNTHESIZER/kicad/FREQUENCY_SYNTHESIZER.kicad_pcb ` |
| 2026-10-08T22:11:37Z | FREQUENCY_SYNTHESIZER | render-iso | 0 | `~/Applications/KiCad/KiCad.app/Contents/MacOS/kicad-cli pcb render --side top --rotate -45\,0\,30 --perspective --background opaque --quality high -w 2400 -h 1800 -o engineering/PCB/FREQUENCY_SYNTHESIZER/3d/FREQUENCY_SYNTHESIZER_render_isometric.png engineering/PCB/FREQUENCY_SYNTHESIZER/kicad/FREQUENCY_SYNTHESIZER.kicad_pcb ` |
| 2026-10-08T22:11:45Z | POWER_SUPPLY | import | 0 | `~/Applications/KiCad/KiCad.app/Contents/MacOS/kicad-cli pcb import --format eagle --report-format text --report-file engineering/PCB/POWER_SUPPLY/reports/kicad_import_report.txt -o engineering/PCB/POWER_SUPPLY/kicad/POWER_SUPPLY.kicad_pcb 4_Schematics\ and\ Boards\ Layout/4_6_Schematics/PowerBoard/PowerBoard.brd ` |
| 2026-10-08T22:11:45Z | POWER_SUPPLY | remap-undefined-layer | 0 | `325 items on EAGLE layer 47 Measures → Dwgs.User` |
| 2026-10-08T22:11:45Z | POWER_SUPPLY | project-from-dru | 0 | `python3 tools/kicad_project_from_dru.py 4_Schematics\ and\ Boards\ Layout/4_6_Schematics/PowerBoard/PowerBoard.brd engineering/PCB/POWER_SUPPLY/kicad/POWER_SUPPLY.kicad_pcb --md engineering/PCB/POWER_SUPPLY/reports/design_rules_mapping.md ` |
| 2026-10-08T22:11:45Z | POWER_SUPPLY | drc | 0 | `~/Applications/KiCad/KiCad.app/Contents/MacOS/kicad-cli pcb drc --format report --severity-all --all-track-errors --refill-zones --save-board --units mm -o engineering/PCB/POWER_SUPPLY/reports/DRC_report.txt engineering/PCB/POWER_SUPPLY/kicad/POWER_SUPPLY.kicad_pcb ` |
| 2026-10-08T22:11:46Z | POWER_SUPPLY | drc-json | 0 | `~/Applications/KiCad/KiCad.app/Contents/MacOS/kicad-cli pcb drc --format json --severity-all --units mm -o engineering/PCB/POWER_SUPPLY/reports/DRC_report.json engineering/PCB/POWER_SUPPLY/kicad/POWER_SUPPLY.kicad_pcb ` |
| 2026-10-08T22:11:47Z | POWER_SUPPLY | stats | 0 | `~/Applications/KiCad/KiCad.app/Contents/MacOS/kicad-cli pcb export stats -o engineering/PCB/POWER_SUPPLY/reports/board_statistics.md engineering/PCB/POWER_SUPPLY/kicad/POWER_SUPPLY.kicad_pcb ` |
| 2026-10-08T22:11:47Z | POWER_SUPPLY | gerbers | 0 | `~/Applications/KiCad/KiCad.app/Contents/MacOS/kicad-cli pcb export gerbers --check-zones --subtract-soldermask -l F.Cu\,B.Cu\,F.Mask\,B.Mask\,F.Paste\,B.Paste\,F.SilkS\,B.SilkS\,Edge.Cuts\,F.Fab\,B.Fab -o engineering/PCB/POWER_SUPPLY/gerber/ engineering/PCB/POWER_SUPPLY/kicad/POWER_SUPPLY.kicad_pcb ` |
| 2026-10-08T22:11:48Z | POWER_SUPPLY | drill | 0 | `~/Applications/KiCad/KiCad.app/Contents/MacOS/kicad-cli pcb export drill --format excellon --excellon-units mm --excellon-separate-th --generate-map --map-format pdf --generate-report --report-path engineering/PCB/POWER_SUPPLY/drill/drill_report.txt -o engineering/PCB/POWER_SUPPLY/drill/ engineering/PCB/POWER_SUPPLY/kicad/POWER_SUPPLY.kicad_pcb ` |
| 2026-10-08T22:11:49Z | POWER_SUPPLY | pdf-copper | 0 | `~/Applications/KiCad/KiCad.app/Contents/MacOS/kicad-cli pcb export pdf --check-zones --mode-multipage --cl Edge.Cuts -l F.Cu\,B.Cu --ibt -o engineering/PCB/POWER_SUPPLY/drawings/POWER_SUPPLY_copper_layers.pdf engineering/PCB/POWER_SUPPLY/kicad/POWER_SUPPLY.kicad_pcb ` |
| 2026-10-08T22:11:50Z | POWER_SUPPLY | pdf-asm-top | 0 | `~/Applications/KiCad/KiCad.app/Contents/MacOS/kicad-cli pcb export pdf --mode-single --sp -l F.Fab\,F.SilkS\,Edge.Cuts --ibt --black-and-white -o engineering/PCB/POWER_SUPPLY/drawings/POWER_SUPPLY_assembly_top.pdf engineering/PCB/POWER_SUPPLY/kicad/POWER_SUPPLY.kicad_pcb ` |
| 2026-10-08T22:11:50Z | POWER_SUPPLY | pdf-asm-bot | 0 | `~/Applications/KiCad/KiCad.app/Contents/MacOS/kicad-cli pcb export pdf --mode-single --sp -m -l B.Fab\,B.SilkS\,Edge.Cuts --ibt --black-and-white -o engineering/PCB/POWER_SUPPLY/drawings/POWER_SUPPLY_assembly_bottom_mirrored.pdf engineering/PCB/POWER_SUPPLY/kicad/POWER_SUPPLY.kicad_pcb ` |
| 2026-10-08T22:11:50Z | POWER_SUPPLY | pdf-top | 0 | `~/Applications/KiCad/KiCad.app/Contents/MacOS/kicad-cli pcb export pdf --check-zones --mode-single -l F.Cu\,F.SilkS\,Edge.Cuts --ibt -o engineering/PCB/POWER_SUPPLY/drawings/POWER_SUPPLY_top_layer.pdf engineering/PCB/POWER_SUPPLY/kicad/POWER_SUPPLY.kicad_pcb ` |
| 2026-10-08T22:11:51Z | POWER_SUPPLY | pdf-bottom | 0 | `~/Applications/KiCad/KiCad.app/Contents/MacOS/kicad-cli pcb export pdf --check-zones --mode-single -m -l B.Cu\,B.SilkS\,Edge.Cuts --ibt -o engineering/PCB/POWER_SUPPLY/drawings/POWER_SUPPLY_bottom_layer_mirrored.pdf engineering/PCB/POWER_SUPPLY/kicad/POWER_SUPPLY.kicad_pcb ` |
| 2026-10-08T22:11:52Z | POWER_SUPPLY | pdf-outline | 0 | `~/Applications/KiCad/KiCad.app/Contents/MacOS/kicad-cli pcb export pdf --mode-single -l Edge.Cuts\,Dwgs.User\,Cmts.User --ibt --black-and-white -o engineering/PCB/POWER_SUPPLY/drawings/POWER_SUPPLY_outline.pdf engineering/PCB/POWER_SUPPLY/kicad/POWER_SUPPLY.kicad_pcb ` |
| 2026-10-08T22:11:52Z | POWER_SUPPLY | svg | 0 | `~/Applications/KiCad/KiCad.app/Contents/MacOS/kicad-cli pcb export svg --check-zones --mode-multi --page-size-mode 2 -l F.Cu\,B.Cu\,F.SilkS\,B.SilkS\,F.Mask\,B.Mask\,Edge.Cuts\,F.Fab\,B.Fab -o engineering/PCB/POWER_SUPPLY/svg/ engineering/PCB/POWER_SUPPLY/kicad/POWER_SUPPLY.kicad_pcb ` |
| 2026-10-08T22:11:53Z | POWER_SUPPLY | svg-top | 0 | `~/Applications/KiCad/KiCad.app/Contents/MacOS/kicad-cli pcb export svg --check-zones --mode-single --page-size-mode 2 -l F.Cu\,F.SilkS\,Edge.Cuts -o engineering/PCB/POWER_SUPPLY/svg/POWER_SUPPLY_top_composite.svg engineering/PCB/POWER_SUPPLY/kicad/POWER_SUPPLY.kicad_pcb ` |
| 2026-10-08T22:11:54Z | POWER_SUPPLY | svg-bottom | 0 | `~/Applications/KiCad/KiCad.app/Contents/MacOS/kicad-cli pcb export svg --check-zones --mode-single --page-size-mode 2 -m -l B.Cu\,B.SilkS\,Edge.Cuts -o engineering/PCB/POWER_SUPPLY/svg/POWER_SUPPLY_bottom_composite_mirrored.svg engineering/PCB/POWER_SUPPLY/kicad/POWER_SUPPLY.kicad_pcb ` |
| 2026-10-08T22:11:55Z | POWER_SUPPLY | dxf-outline | 0 | `~/Applications/KiCad/KiCad.app/Contents/MacOS/kicad-cli pcb export dxf --mode-single --ou mm --uc -l Edge.Cuts -o engineering/PCB/POWER_SUPPLY/mechanical/POWER_SUPPLY_outline.dxf engineering/PCB/POWER_SUPPLY/kicad/POWER_SUPPLY.kicad_pcb ` |
| 2026-10-08T22:11:55Z | POWER_SUPPLY | dxf-fab | 0 | `~/Applications/KiCad/KiCad.app/Contents/MacOS/kicad-cli pcb export dxf --mode-single --ou mm --uc -l Edge.Cuts\,F.Fab\,F.SilkS -o engineering/PCB/POWER_SUPPLY/mechanical/POWER_SUPPLY_top_fab.dxf engineering/PCB/POWER_SUPPLY/kicad/POWER_SUPPLY.kicad_pcb ` |
| 2026-10-08T22:11:56Z | POWER_SUPPLY | step | 0 | `~/Applications/KiCad/KiCad.app/Contents/MacOS/kicad-cli pcb export step --board-only --force -o engineering/PCB/POWER_SUPPLY/mechanical/POWER_SUPPLY_board_only.step engineering/PCB/POWER_SUPPLY/kicad/POWER_SUPPLY.kicad_pcb ` |
| 2026-10-08T22:11:56Z | POWER_SUPPLY | pos | 0 | `~/Applications/KiCad/KiCad.app/Contents/MacOS/kicad-cli pcb export pos --format csv --units mm --side both -o engineering/PCB/POWER_SUPPLY/assembly/POWER_SUPPLY_pick_and_place.csv engineering/PCB/POWER_SUPPLY/kicad/POWER_SUPPLY.kicad_pcb ` |
| 2026-10-08T22:11:57Z | POWER_SUPPLY | ipc2581 | 0 | `~/Applications/KiCad/KiCad.app/Contents/MacOS/kicad-cli pcb export ipc2581 -o engineering/PCB/POWER_SUPPLY/ipc/POWER_SUPPLY.xml engineering/PCB/POWER_SUPPLY/kicad/POWER_SUPPLY.kicad_pcb ` |
| 2026-10-08T22:12:02Z | POWER_SUPPLY | ipcd356 | 0 | `~/Applications/KiCad/KiCad.app/Contents/MacOS/kicad-cli pcb export ipcd356 -o engineering/PCB/POWER_SUPPLY/ipc/POWER_SUPPLY_netlist.d356 engineering/PCB/POWER_SUPPLY/kicad/POWER_SUPPLY.kicad_pcb ` |
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

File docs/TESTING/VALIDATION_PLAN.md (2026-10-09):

# Validation Plan — AERIS-10

Status date 2026-10-08. Each test has an ID, a command or procedure, the tool that was available on the authoring machine (macOS arm64, Python 3.14.7, iverilog 13.0, verilator 5.052; **no** Vivado, ARM GCC, EAGLE, KiCad), and the result actually obtained. A test is reported PASSED only if it was executed and succeeded. "Software-based design check" means a file/tool check; "physical verification" needs hardware and is never claimed here.

Run everything that is runnable with `bash tools/run_all_checks.sh` (exit code = number of failed checks).

## 1. FPGA

| ID | Test | Type | Command | Tool available | Executed result |
|---|---|---|---|---|---|
| F-01 | Syntax / parse of all RTL | design check | `tools/fpga_lint.sh` (iverilog -g2012) | yes | **FAIL** — `radar_system_top.v:312` syntax error |
| F-02 | Elaboration of `radar_system_top` | design check | same | yes | **FAIL** — not reached (F-01); on a patched scratch copy: 6 missing modules |
| F-03 | Lint | design check | `verilator --lint-only -Wall` (in `tools/fpga_lint.sh`) | yes | **FAIL** — same syntax error; with stubs: 207 warnings incl. MULTIDRIVEN ×4, UNDRIVEN ×14 |
| F-04 | Constraint completeness | design check | `python3 tools/check_fpga_constraints.py` | yes | **FAIL** (exit 1) — 142 placeholder lines, 180/180 bits without PACKAGE_PIN, 21 without IOSTANDARD, 2 invalid properties |
| F-05 | Schematic-derived pin map generation | design check | `python3 tools/gen_xdc_from_schematic.py` | yes | PASSED (exit 0) — 64 ports mapped, 25 ports unresolved (this is a generation step, not a correctness proof) |
| F-06 | Simulation `radar_system_tb` | design check | Vivado xsim (SVA needed) | no | NOT RUN |
| F-07 | Synthesis utilisation on `xc7a50tftg256-2` | design check | `tools/vivado/create_project.tcl` + `launch_runs synth_1` | no | NOT RUN |
| F-08 | Timing summary / clock interaction / CDC report | design check | `report_timing_summary`, `report_cdc` | no | NOT RUN |
| F-09 | Bitstream generation | design check | `write_bitstream` | no | NOT RUN |
| F-10 | ADC LVDS capture on hardware (eye/valid data) | physical | ILA + known tone into AD9484 | no | NOT RUN |

## 2. STM32

| ID | Test | Type | Command | Tool | Result |
|---|---|---|---|---|---|
| S-01 | Dependency / include check | design check | `python3 tools/check_stm32_includes.py` | yes | **FAIL** (exit 1) — 53 absent HAL/CMSIS/USB headers, 6 case mismatches |
| S-02 | Cube package completeness | design check | `tools/stm32_check_cube_package.sh <CubeF7>` | script yes, package no | NOT RUN (self-test with invalid path → exit 2 as designed) |
| S-03 | Host syntax probe (non-target) | design check | `clang -fsyntax-only -DSTM32F746xx -DUSE_HAL_DRIVER …` | yes | 29/60 TUs fail on missing `stm32f7xx_hal.h`; pure no-OS/C++ units pass (informational, **not a build**) |
| S-04 | Cross-compile | design check | `arm-none-eabi-g++` via CubeIDE or `reconstructed/CMakeLists.txt` | no | NOT RUN |
| S-05 | Link + size | design check | `arm-none-eabi-size` | no | NOT RUN |
| S-06 | Static analysis | design check | `cppcheck --enable=warning,style` | no (not installed) | NOT RUN |
| S-07 | Pin-map cross-check firmware ↔ schematic | design check | `tools/extract_eagle_netlist.py --part U2` vs `main.h` | yes | PASSED for the 60 named GPIO macros (all nets found on U2); **conflict found** for HSE (8 vs 25 MHz) and ADF4382 pins in `adf4382a_manager.h` |
| S-08 | Flash + CDC enumeration | physical | ST-LINK, `lsusb`/Device Manager | no | NOT RUN |
| S-09 | Settings packet accepted (state READY_FOR_DATA) | physical | send flag + 82-byte packet | no | NOT RUN (static analysis predicts failure: C4, C5) |
| S-10 | Power-sequence timing on `EN_*` rails | physical | oscilloscope | no | NOT RUN |

## 3. Python

| ID | Test | Type | Command | Tool | Result |
|---|---|---|---|---|---|
| P-01 | Dependency resolution | design check | `pip install -r 9_Firmware/9_3_GUI/requirements.txt` in a venv | yes | PASSED (all 10 packages installed; versions in `docs/GUI/DEPENDENCIES.md`) |
| P-02 | Syntax (ast) of 27 scripts | design check | `python3 tools/check_python_imports.py` | yes | **FAIL** (exit 1) — `GUI_V1.py` IndentationError; 26/27 OK |
| P-03 | Import test of third-party modules | design check | `… --try-import` (venv) | yes | PASSED for all GUI modules; FAIL for `openEMS`/`CSXCAD` (not on PyPI; simulation scripts only) |
| P-04 | Module import of each GUI file | design check | `python -c "import GUI_V6_Demo"` etc. | yes | PASSED for V2, V3, V4, V4_2_CSV, V5, V5_Demo, V6, V6_Demo (import only); V1 FAIL |
| P-05 | pyflakes | design check | `pyflakes 9_Firmware/9_3_GUI/*.py` | yes | undefined names: `GUI_V6.py:392` `STM32USBInterface`; `GUI_V4_2_CSV.py:430` `e`; V5_Demo missing methods (informational) |
| P-06 | Unit tests | design check | `pytest` | yes | NOT RUN — **no tests exist in the repository** |
| P-07 | GUI startup smoke (`GUI_V6_Demo.py` window) | design check | procedure GUI-T05 | yes (Tk 9.0) | NOT RUN (window not launched) |
| P-08 | Demo-data verification (`test_radar_data.csv` vs `GUI_V4_2_CSV.py` reader) | design check | column/row check | yes | PASSED (header matches reader; 16 384 rows = 32 chirps × 512; identical to generator output) |
| P-09 | Hardware link (CDC / FTDI) | physical | — | no | NOT RUN |

## 4. PCB documentation

| ID | Test | Type | Command | Tool | Result |
|---|---|---|---|---|---|
| B-01 | ERC (fresh run) | design check | EAGLE `ERC` | no | NOT RUN — stored approved ERC items: Main 4, others 0 |
| B-02 | DRC (fresh run) | design check | EAGLE `RATSNEST; DRC` | no | NOT RUN — stored: Main 211 approved + 2 390 airwires; Power 309 airwires; Synth 0; PA 0 |
| B-03 | Missing-library detection | design check | XML: all `<library>` embedded | yes | PASSED — no external library references for any board |
| B-04 | sch/brd consistency | design check | part/net set comparison (XML) | yes | PASSED Synth, PA; Main: 10 board-only signals, 210 value mismatches; Power: version mismatch 9.6.2/7.4.0, 1 board-only signal → **FAIL** for Main and Power |
| B-05 | BOM completeness | design check | `python3 tools/gen_eagle_bom.py …` → `docs/BOM/` | yes | **FAIL** — 0 MPN attributes on all boards; value-less references 244/80/6/47 |
| B-06 | Manufacturing-export completeness | design check | `python3 tools/check_manufacturing_files.py` | yes | **FAIL** (exit 1) — no Gerber/drill for any board; P&P + BOM only for Synth |
| B-07 | Outline/hole extraction | design check | `python3 tools/gen_board_outline_svg.py …` | yes | PASSED for 4 boards (drawings generated) |
| B-08 | Stack-up confirmation | physical/vendor | fab quote with stack-up drawing | no | NOT RUN |
| B-09 | Impedance coupon measurement | physical | TDR at fab | no | NOT RUN |
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

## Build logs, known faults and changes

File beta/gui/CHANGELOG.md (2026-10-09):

# beta/gui CHANGELOG

## 0.7.0b1 -- 2026-10-09 -- initial BETA reconstruction

Environment: CPython 3.14.7, Tk 9.0, macOS arm64; venv `beta/gui/.venv` (not committed).
Originals in `9_Firmware/9_3_GUI/` were read only; nothing there was modified.

### Provenance -- what was taken from which original

| Beta file | Taken from | What |
|---|---|---|
| `aeris10_gui/model.py` | `GUI_V5.py:56-88` | `RadarTarget`, `RadarSettings`, `GPSData` dataclasses (field names kept; `range`->`range_m`, `velocity`->`velocity_mps`, etc. to carry units) |
| `aeris10_gui/protocol/settings_packet.py` | `GUI_V5.py:454-467` (`_create_settings_packet`), `GUI_V5.py:401-405` (start flag), firmware `RadarSettings.cpp`, `USBHandler.cpp` | packet builder; parser and validation written from the firmware |
| `aeris10_gui/protocol/status_text.py` | `GUI_V5.py:676-751` (`parse_gps_data`, `_parse_binary_gps_with_pitch`), firmware `main.cpp:807-877`, `gps_handler.cpp:45-119` | GPS text/GPSB parsers; status-string parser/formatter written from the firmware |
| `aeris10_gui/protocol/fpga_packet.py` | `9_Firmware/9_2_FPGA/usb_data_interface.v`, `radar_system_top.v`, `doppler_processor.v` | written from the RTL; nothing from `GUI_V5.RadarPacketParser` (wrong format) was reused |
| `aeris10_gui/io/usb_cdc.py` | `GUI_V5.py:307-477` (`STM32USBInterface`: VID/PID list :323-330, open/read/write shape) | re-implemented on pyserial; pyusb fallback kept |
| `aeris10_gui/io/ftdi_ft601.py` | `GUI_V5.py:479-549` (`FTDIInterface` shape), `GUI_V6.py:119-122` (FT601 PIDs) | stub raising `NotImplementedError` |
| `aeris10_gui/dsp/clustering.py` | `GUI_V5.py:587-605` (`RadarProcessor.clustering`) | DBSCAN eps/min_samples defaults kept |
| `aeris10_gui/dsp/tracking.py` | `GUI_V5.py:607-670` (`association`, `tracking`) | Kalman matrices, gate 500, 5 s stale timeout kept |
| `aeris10_gui/dsp/cfar.py` | -- | new (no original contained CFAR) |
| `aeris10_gui/sim/simulator.py` | `GUI_V6_Demo.py:61-231` (`SimulatedRadarProcessor`: target list :71-129, drift/bounds :131-169, noise/clutter/blob/gain :171-214) | refactored to I/Q + RTL packets |
| `aeris10_gui/sim/replay.py` | `GUI_V4_2_CSV.py:354-372` (CSV columns) | csv module instead of pandas |
| `aeris10_gui/ui/theme.py` | `GUI_V5.py:44-55`, `:911-990` | colours and ttk style |
| `aeris10_gui/ui/main_window.py` | `GUI_V5.py:993-1157` (control row, notebook, imshow range-Doppler, targets Treeview, settings tab fields :1128-1157), `GUI_V6_Demo.py:718-748` (timer loop) | |
| `aeris10_gui/ui/sources.py` | `GUI_V5.py:1201-1263` (`start_radar`/`stop_radar` sequence: open, start flag, settings) | |
| `aeris10_gui/processing.py` | -- | new |
| `aeris10_gui/app.py`, `__main__.py` | `GUI_V5.py:1531-1539`, `GUI_V6_Demo.py:1196-1219` (`main()`) | argparse added |

### Behavioural changes versus the originals

1. **CDC write framing**: `GUI_V5._send_data` zero-padded every write to 64 bytes
   (`GUI_V5.py:444-446`). The firmware copies those zeros into its settings buffer so
   `SET` is not at offset 0 and the settings are never accepted (`USBHandler.cpp:51-52,70`).
   Beta default: **no padding**. `pad_to_64=True` (UI checkbox "Zero-pad CDC writes")
   reproduces the legacy behaviour. `tests/test_settings_packet.py` models the firmware
   receiver and shows both outcomes.
2. **Firmware value limits enforced in the UI** before sending (`RadarSettings.cpp:86-101`);
   V5 sent anything parseable as float.
3. **Transport**: STM32 CDC opened as an OS serial port (pyserial) instead of pyusb bulk
   endpoints on interface (0,0); pyusb fallback now selects the CDC *data* interface.
   `pyserial` added to requirements. No mock devices are returned on enumeration failure
   (V5 returned fake devices, `GUI_V5.py:355,502`).
4. **FPGA packet format**: V2-V5 expected `A5 C3` + type + length + payload + CRC16; V6 a
   constant 64-byte packet. Beta decodes the RTL's actual 35-byte `0xAA ... 0x55`
   format, with footer + redundant-copy integrity checks (the RTL has no CRC) and
   stream resynchronisation. The V5 buffer-advance bug (`GUI_V5.py:1313`, packet length
   always 6) is moot.
5. **GPS text**: V3-V5 required 4 fields (`GUI_V5.py:686`); firmware sends 3
   (`gps_handler.cpp:53`). Beta accepts 3 (firmware) or 4 (legacy).
6. **Status string**: new parser for `getSystemStatusForGUI` output (no GUI version
   parsed it); BeamPos/Azimuth drive the PPI azimuth.
7. **CFAR**: implemented on the host (CA-CFAR). V5 only logged the FPGA detection flag;
   V6_Demo drew "detections" from the truth list with `random() < snr/35`.
8. **Clustering/tracking** are now in the processing path; in V5 they were defined but
   never called (`engineering/SOFTWARE_DIAGRAMS/PYTHON/python_gui_architecture.dot`).
9. **Threads removed**: V5 used two daemon threads + a Tk timer; beta polls the source
   from a single Tk timer (`GUI_V6_Demo` style), making `--selftest` deterministic.
10. **Simulator geometry**: 64 x 32 complex I/Q cells (RTL parameters) instead of V6's
    1024 x 32 power map; velocities scaled x0.75 and demo `prf1` = 10 kHz so the V6
    scene fits the unambiguous Doppler span; detection bit per cell = `|I|+|Q| > 10000`
    (`radar_system_top.v:318`).
11. **Dropped**: Google Maps HTML export (placeholder API key), FT2232H/pyftdi path,
    Mercury-colour A-scope/spectrum tabs of V6_Demo (not reconstructed in this beta).
12. **Added**: PPI polar plot, STM32 status tab, `--demo`, `--selftest`, `--port`,
    pytest suite, PyInstaller build script.

### Verification performed

* `pytest -q`: 46 passed (see README "Test").
* `python -m aeris10_gui --selftest --frames 3`: OK (3 frames, 6144 packets, 0 resync drops, 3 status strings).
* `./build_app.sh`: PyInstaller 6.22.3 `--onedir` bundle built; `dist/aeris10-gui/aeris10-gui --demo --selftest` exit 0.
* Not performed: any hardware test; Windows/Linux; Python < 3.14.

## 2026-10-09 — host-link option B (DSN-LINK-01)
- Added `aeris10_gui/protocol/bridge_frame.py`: parser/serialiser for the FPGA→STM32→CDC range-Doppler frame (sync A5 5A, 16-byte header, 2048 × uint8 log-magnitude, detection list, CRC-16/CCITT-FALSE) and `BridgeStreamParser` (resync, status-text pass-through). Reference vector `tests/vectors/bridge_frame_from_rtl_tb.hex` is dumped by the Verilog testbench `engineering/DESIGN/HOST_LINK/rtl/tb_host_bridge.v`. Tests: `tests/test_bridge_frame.py` (9). Not yet wired into `ui/sources.py` (the hardware source still expects the raw RTL packet stream).

## 2026-10-09 — bridge link as default hardware path, register access (DSN-LINK-01 §5, §7)

### Added
- `ui/sources.py` rewritten around `LinkDecoder`: **default link = `bridge`** (option B). The CDC byte stream goes through `BridgeStreamParser`; frames → `RadarPipeline.process_bridge_frame`, non-frame bytes → `StatusStreamParser` (status strings, GPS text/GPSB, REG replies). The raw-RTL-packet path (option A) is kept behind `--raw-ft601` (`LINK_RAW_FT601`). Sources return a `PollResult`; `HardwareSource` accepts an injected CDC object (used by tests).
- `processing.py`: `process_bridge_frame`, `process_power`, `bridge_frame_to_power` (uint8 `8·log2(|I|+|Q|)` → power proxy `2**(u8/4)`, detection list → map). Azimuth/elevation come from the frame header in bridge mode.
- `sim/simulator.py`: `logmag()` (bit-exact copy of `rd_map_packer.v` `logmag`, checked against the testbench formula), `bridge_frame_from_iq()`, `RadarSimulator.next_bridge_frame()` and the `bridge_frames(count)` generator (serialised with `build_frame`). Detection list = first 32 cells with `|I|+|Q| > CFAR_THR`, range-major, as the packer does.
- `sim/register_file.py`: `DemoRegisterFile`, in-memory model of `radar_control_regs.v` (write/read arms, toggle bits, RO registers, reset values) with a simulated calibration result (auto start → lock 0xFF, window [10, 22], tap 16). Answers `REG` lines in demo mode; CFAR_THR and CONTROL.use_long_chirp feed back into the simulated frames.
- `protocol/register_map.py`: register map transcribed from `beta/fpga/rtl/radar_control_regs.v` (field encode/decode, `describe_cal_stat`).
- `protocol/register_cmd.py`: `REG W <addr> <value>` / `REG R <addr>` formatter and device-side parser; reply parser for `REG <addr> <value>` / `REG ERR`; `RegisterClient` (FIFO of outstanding requests, per-lane CAL_LANE_INFO read-all that restores CAL_LANE).
- `protocol/status_text.py`: `StatusStreamParser` now recognises `REG` lines at a line start and yields `RegisterReply`.
- `io/usb_cdc.py`: `send_register_write` / `send_register_read` on `CdcSerialPort` and `PyUsbCdc` (same connection as the settings packet).
- `ui/register_panel.py`: notebook tab "FPGA registers / ADC calibration": CONTROL bits, CFAR threshold, decimation, start bin; auto (pattern) calibration, pattern-check enable, manual tap + lane load, bitslip + lane, pattern A/B; decoded CAL_STAT lock mask/done/busy/align_fail/fifo_ovf, chosen tap + pass window for all 8 lanes, CAL_ERR, CAL_UNDET, ID; "Read all / refresh". Inputs are range-checked against the RTL field widths.
- `app.py`: `--raw-ft601`; `--selftest` now also performs a register read-all against the demo register file and fails if any reply is missing, any `REG ERR` occurs, or any parser error is counted.
- Tests: `tests/test_register_cmd.py` (7), `tests/test_bridge_source.py` (7), 2 new UI smoke tests (raw-FT601 demo, register panel), 1 new bridge-parser regression test. Total 72.

### Changed
- `protocol/bridge_frame.py` `BridgeStreamParser.feed`: when no sync word is buffered it used to hold back the last byte unconditionally. That delayed a text line's closing `\n` (e.g. a trailing `REG` reply) until the next CDC chunk arrived. It now holds the byte back only when it is `0xA5`, i.e. a possible first sync byte. Regression test added.
- Demo detection threshold: taken from the simulated CFAR_THR register (reset 10000, same as before) instead of a constant.

### Discrepancies / unresolved (recorded, not papered over)
1. ~~HOST_LINK_DESIGN.md §7 register table ≠ RTL.~~ **Resolved**: §7 was rewritten to mirror `radar_control_regs.v` (run / mixers / NCO removed). The GUI follows the RTL (see the final-map entry below).
2. ~~Blind calibration not reachable through registers.~~ **Resolved**: CAL_CTRL bit4 + 0x0D/0x0E/0x10 (see below).
3. ~~`radar_system_top.v` ties the register write port off.~~ The register port is now driven by `host_bridge_spi` (RTL header of `radar_control_regs.v`); see the final-map entry for the GUI-side check.
4. ~~No firmware implements the REG text commands.~~ **Resolved the same day**: `beta/stm32/Core/Src/host_bridge_proto.c` (`hb_cmd_parse`/`hb_cmd_execute`), `LIB/USBHandler.cpp` (`captureTextCommand` single slot) and `main.cpp` (main-loop reply) now implement them. `protocol/register_cmd.py` was re-aligned to the firmware (see the entry below); the GUI's line rules are now "same as firmware", not a proposal.
5. There is no request ID in the protocol; replies are matched to the single in-flight command. A lost reply is handled by the client's timeout/retransmit, not by sequence numbers.

### Verification performed
- `pytest -q`: **72 passed**, 0 skipped.
- `python -m aeris10_gui --selftest`: bridge link: 3 frames, 0 CRC errors, 31 REG replies, read-all OK. `--selftest --raw-ft601`: 6144 packets, 0 drops, read-all OK.
- `./build_app.sh`: PyInstaller 6.22.3 rebuild OK (135 MB `--onedir`). The bundle passes `--demo --selftest` (bridge) and `--demo --selftest --raw-ft601`, both exit 0.
- Environment note: Homebrew had upgraded `tcl-tk` to 9.1, which broke `_tkinter` (`libtcl9.0.dylib` not found) and silently skipped the UI tests. Fixed with `brew reinstall python-tk@3.14` (Tk 9.1 now loads).

## 2026-10-09 (later) — REG commands aligned with the firmware implementation

Firmware read: `beta/stm32/Core/Src/host_bridge_proto.c`, `beta/stm32/Core/Src/host_bridge.c`
(`HostBridge_ExecuteTextCommand`), `beta/stm32/LIB/USBHandler.cpp` (`captureTextCommand`,
`takePendingCommand`), `beta/stm32/Core/Src/main.cpp:1713-1726`.

### Changed (`protocol/register_cmd.py`)
- Replies parsed/formatted exactly as the firmware prints them: `REG 0x%04X 0x%08X\r\n`
  and `REG ERR\r\n`. A **write reply echoes the written value** (`hb_cmd_execute` echoes
  `c.value`); the earlier GUI proposal (read-back) is gone. `DemoRegisterFile` does the same.
- Device-side parser (`parse_command`, used by the demo register file) mirrors `hb_cmd_parse`
  / `parse_u32`: `REG` upper case at byte 0 of the transfer, `W`/`R` either case, `0x`/`0X`
  hex with at most 8 digits or decimal, address <= 0xFFFF, trailing junk is an error, the line
  is cut at the first `\0`/`\r`/`\n` (**one command per USB transfer**; later lines are
  discarded). New `is_text_command()` = `hb_cmd_is_text_command`.
- `RegisterClient` now enforces the **firmware single slot**: exactly one command in flight;
  the next queued command is written only after the reply (or after `timeout` s, with
  `retries` retransmits, then recorded as `("…", "timeout")` in `errors`). `pending` still
  lists everything unanswered; new `in_flight`, `sent`, `retransmits`, `poll(now)`.
- New `parse_bridge_status()` / `BridgeStatus` for the SPI command 0x04 payload (four
  little-endian u16: status bits frame-ready / ADAR CS conflict / FIFO overflow /
  calibration lock, version, frames, reserved). No text form exists in the firmware yet.
- `ui/sources.py` `DemoSource` emulates the firmware slot: a `REG` transfer is captured,
  executed at the next poll (main loop), and a second transfer before that is dropped
  (`dropped_commands` counter). `--selftest` now steps until the read-all is fully answered
  and prints `sent` / `dropped_by_slot`.
- `ui/main_window.py` calls `reg_client.poll()` every tick (timeouts); panel shows sent /
  retransmits / timeouts.

### Tests
- `tests/test_register_cmd.py` rewritten (11): firmware-literal reply strings incl. `\r\n`
  and upper-case zero-padded hex, device-parser rules (`REG R 0x1\nREG R 0x2\n` executes only
  the first), a `FakeFirmware` with the single slot proving the client never triggers a drop
  (one command per main-loop iteration, 44 commands for write + read + read-all), the
  counter-example (unpaced sender loses the second command), timeout → 2 retransmits →
  error → next command, status bytes.
- `tests/test_bridge_source.py`: demo source slot semantics (second transfer dropped, replies
  arrive one per poll, write echoes the value). `tests/test_ui_smoke.py`: register panel
  loops `step()` until the read-all is answered; asserts 0 drops, `sent == polls`.

## 2026-10-09 (final register map, RTL 0x0002)

`beta/fpga/rtl/radar_control_regs.v` and HOST_LINK_DESIGN.md §7 are now identical; the GUI was
updated to that map.

### Changed
- `protocol/register_map.py`: 5-bit addresses (`ADDR_MASK = 0x1F`, unmapped 0x11..0x1F); CAL_CTRL
  bit4 `blind` (level: 0 = ADC test pattern, 1 = CW tone at the IF); new registers 0x0D
  `CAL_BLIND_COEF` (rw, signed Q1.14, reset 0xEC39), 0x0E `CAL_BLIND_MARGIN` (rw, reset 0x0040),
  0x10 `CAL_BLIND_MIN` (ro, per CAL_LANE); `RTL_VERSION = 0x0002`; helpers `blind_coef_to_cos`,
  `blind_coef_from_if` (120 MHz @ 400 MSPS -> 0xEC39, matches the RTL default). The discrepancy
  docstring is gone.
- `protocol/register_cmd.py`: `BridgeStatus.packer_overflow` (status word bit4); `RegisterClient.
  read_all` also reads CAL_BLIND_MIN for every lane (`lane_blind_min`), 3 commands per lane.
- `sim/register_file.py`: 5-bit decode, bit4 blind level, 0x0D/0x0E rw, 0x10 ro; blind auto
  calibration yields a per-lane minimum metric (0x0120 at the default coefficient) and a window
  that narrows as the coefficient is detuned from the default IF.
- `ui/register_panel.py`: the "unavailable" note is replaced by a plain map note; new blind-method
  checkbox (bit4), blind coef / margin fields with Write buttons, "IF -> coef" helper, per-lane
  `blind_min` readout and a method/coef/margin summary line. `auto_pattern`/`write_check` renamed
  `auto_start`/`write_cal_ctrl` (old names kept as aliases).
- Tests updated: map resets/fields/unmapped range, status bit4, register-file blind behaviour,
  read-all now 3 commands per lane (client pacing test: 52 commands, 0 drops), UI panel exercises
  compute-coef -> write -> blind auto calibration -> read-all.

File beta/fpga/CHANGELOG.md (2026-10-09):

# beta/fpga CHANGELOG - every difference versus `9_Firmware/9_2_FPGA/`

Status of everything in `beta/fpga`: **BETA** - parses, elaborates, lints and simulates with
Icarus Verilog 13.0 / Verilator 5.052; **not synthesised** (no Vivado available) and **not tested on
hardware**. Line numbers "orig :N" refer to the unmodified files in `9_Firmware/9_2_FPGA/`
(CRLF->LF normalisation did not change line numbers); "beta :N" refers to `beta/fpga/rtl/`.
Nothing under `9_Firmware/9_2_FPGA/` was modified.

Legend: **SYN** syntax/elaboration fix, **BUG** functional defect fix, **ARCH** architecture/interface
change (documented in README), **NEW** file written for the beta, **CLEAN** lint/readability only.

## Files copied unchanged except line endings

`dac_interface_single.v`, `fir_lowpass.v`, `level_shifter_interface.v`, `ddc_input_interface.v`
(a trailing newline was added where missing). `plfm_chirp_controller.v` LUT contents unchanged.

## Files moved to `rtl/unused_orig/` (not compiled)

`ad9484_interface_400m.v`, `lvds_to_cmos_400m.v`, `cdc_modules.v`, `latency_buffer_2159.v`,
`usb_packet_analyzer.v` - see `rtl/unused_orig/README.md` for the reason per file.
`chirp_lut_init.v` (module-less `initial` fragment, orig :6) and `radar_system_tb.v`
(SystemVerilog assertions, orig :528-543) were not copied into `rtl/`; the original testbench is kept
as `tb/radar_system_tb_original.v` for reference only (not run).

## `radar_system_top.v`

| Type | orig | Change | Reason |
|---|---|---|---|
| SYN | :312-313 | `wire [16:0] mag` moved to module scope (beta :355-357) | wire declaration inside `always` is a syntax error (iverilog/Verilator stop here) |
| SYN | :155-156 | `rx_cfar_detection`, `rx_cfar_valid` `wire` -> `reg` | assigned procedurally at :304-318 |
| ARCH | :184-187 | `BUFG bufg_ft601` removed; `ft601_clk_in` kept as an (unused) port | FT601 not wired on the board; USB FSM runs on clk_100m |
| ARCH | new | `radar_control_regs ctl_regs` instance (write port tied to 0) | single driver for use_long_chirp / adc_pwdn / CFAR threshold / decimation controls |
| ARCH | :270-286 | `rx_inst` gets the new receiver ports (STM32 toggles, register controls, range profile out, status) | receiver controls were undriven |
| BUG | :298-323 | CFAR placeholder: `rx_cfar_valid` pulses on every `rx_doppler_valid`, detection = `mag > ctl_cfar_threshold`; `rx_cfar_detection` was set and never cleared | threshold from register map; valid/detection semantics |
| BUG | :329-332 | `usb_range_profile` = real decimated range profile (`rx_range_profile_w`), `usb_*_valid` gated by `ctl_usb_enable` | original sent Doppler data "as a placeholder" |
| CLEAN | :398 | `status_reg[1]` also ORs the CDC-FIFO overflow flag | observability of lost samples |

## `radar_receiver_final.v` (rewritten; instance names and chain order kept)

| Type | orig | Change | Reason |
|---|---|---|---|
| SYN | :150 vs :192 | `sample_addr_from_chain` declared before use | use-before-declare |
| SYN | :216-217 | `.ref_i(16'd0)`, `.ref_q(16'd0)` removed | ports do not exist in `matched_filter_multi_segment` |
| SYN | :14-17 | outputs `reg` -> `wire` | driven by instance output ports |
| SYN/BUG | :21-25, :204-208 | `use_long_chirp`, `chirp_counter`, `mc_new_*` are now driven: `use_long_chirp` is an input (register map); `mc_new_*` come from three `edge_detector_enhanced` instances on the STM32 toggle inputs (new ports); `chirp_counter` is a local 0..CHIRPS_PER_FRAME-1 counter | undriven wires -> matched filter never started |
| ARCH | :59-69, :94-105 | `lvds_to_cmos_400m` instance and the first `cdc_adc_to_processing` removed; `clk_400m` = `adc_dco_cmos` from `ad9484_lvds_to_cmos_400m` | two IBUFDS on the same pins are illegal; flop-derived clock (orig lvds_to_cmos_400m.v:35-43) is not a clock |
| ARCH | new | `reset_synchronizer rst_sync_400m` -> `ddc.reset_n_400m` | synchronous reset release in the 400 MHz domain |
| ARCH | :168-189 | `latency_buffer_2159` removed; `long/short_chirp_*` fed directly from the memory outputs | reference now fetched by address at FFT-output time (see processing chain) |
| BUG | :125-126 | `ddc.mixers_enable` stays 1'b1; `bypass_mode` now from port `ddc_bypass` (top ties 0) | original tied `bypass_mode = 1'b1` to an unimplemented test input |
| BUG | :201-202 | `ddc_i = {adc_i_scaled, 2'b00}` instead of sign extension | the multi-segment filter stores `ddc_i[17:2]`; sign extension lost 2 LSB (/4) |
| BUG | :244-283 | frame-sync: pulse on the first chirp of every CHIRPS_PER_FRAME (32) chirps | original compared an undriven counter against 0/32 |
| ARCH | new | outputs `range_profile_out/valid/bin`, `rx_chirp_counter`, `new_chirp_frame`, `cdc_overflow` | host path and observability |
| CLEAN | :320-349 | debug `$display` block removed | uninitialised counters, noise |

## `radar_transmitter.v` (rewritten; ports unchanged)

| Type | orig | Change | Reason |
|---|---|---|---|
| BUG | :93-112 | edge detectors clocked by `clk_120m_dac` | their pulses are consumed by the clk_120m FSM; a 10 ns pulse sampled at 120 MHz is unsafe |
| BUG | :59-71 | four `level_shifter_interface` instances drive `stm32_*_1v8` / `stm32_miso_3v3` | outputs were undriven (module was an orphan) |

## `plfm_chirp_controller.v`

| Type | orig | Change | Reason |
|---|---|---|---|
| BUG | :563-576 | clk_100m `chirp_counter` block deleted (beta :566-569) | second driver of `chirp_counter` (also written at :683-784 on clk_120m) |
| BUG | :580, :597 | elevation/azimuth counters clocked by `clk_120m` | single clock domain for the TX controller |
| CLEAN | :5 | `clk_100m` port kept, marked unused | interface compatibility |

## `edge_detector.v` (rewritten; ports unchanged)

| Type | orig | Change | Reason |
|---|---|---|---|
| BUG | :16-23 | two ASYNC_REG synchroniser flops + history flop; edge from stage 2 | edge was taken from the first synchroniser stage |

## `ddc_400m.v`

| Type | orig | Change | Reason |
|---|---|---|---|
| SYN | :252-266 vs :272-275 | `fir_*` wires declared before the CDC instances | use-before-declare |
| ARCH | new port | `reset_n_400m` for NCO/mixer/CIC/dither; control inputs double-synchronised | async reset release in the 400 MHz domain |
| ARCH | :243-267 | `cdc_adc_to_processing` x2 -> `async_fifo` x2 (Gray pointers, depth 16) + `cdc_overflow` output | Gray-coding data words is not a CDC |
| BUG | :117-125 | `reset_monitors` removed from the async reset condition (synchronous now); `saturation_count` written only in the mixer block | data-dependent async reset; multi-driven register |
| BUG | :156 | NCO `phase_valid` from `mixers_enable_sync` | raw asynchronous input used as an enable |
| BUG | :306 | output stage on `posedge clk_100m` | negedge register halves the timing budget |
| BUG | :21 | `bypass_mode` implemented (mixer bypass, I = adc, Q = 0) | input existed but did nothing |
| BUG | :19 | `filter_overflow` driven from the two FIR overflow flags | undriven output |
| CLEAN | :223-240 | CIC monitor pins connected explicitly | PINMISSING |
| CLEAN | :332-371 | debug `$display` blocks removed | uninitialised counters |

## `cic_decimator_4x_enhanced.v`

| Type | orig | Change | Reason |
|---|---|---|---|
| BUG | :71, :181, :291 | `saturation_detected` = `int_saturation` (integrator block) OR `comb_saturation` (comb block); `overflow_latched`/`saturation_event_count` split likewise; `always @(posedge reset_monitors)` block deleted; `data_valid_comb` written only in its pipeline block (:77 removed) | three/two drivers per register, control input used as a clock |
| ARCH | :9 | `saturation_detected` `output reg` -> `output wire` | OR of two flags |

## `nco_400m_enhanced.v` (rewritten; ports and 2-cycle latency unchanged)

| Type | orig | Change | Reason |
|---|---|---|---|
| BUG | :34-49 | 65-entry table `sin(90deg*i/64)` (generated, monotonic, ends at 0x7FFF) | original table peaks at index 42 and ends at 0x3B71 (not a sine) |
| BUG | :54, :58 | mirroring on `quadrant[0]`; `cos = lut[64-idx]` | mirrored on `quadrant[1]`; `lut[63-idx]` is one step off |
| CLEAN | :111-115 | `initial $display` removed | |

## `chirp_memory_loader_param.v`

| Type | orig | Change | Reason |
|---|---|---|---|
| SYN | :3-12 | absolute Windows paths -> `mem/<file>.mem` | files did not exist; `long_chirp_seg3_*.mem` generated (`gen_chirp_mem.py`) |
| CLEAN | :104 | `long_addr` is a wire | blocking assignment in a clocked block |
| CLEAN | :13, :64-65 | `DEBUG` default 0; explicit `$readmemh` range 0..49 for the short chirp | noise / warning |

## `matched_filter_multi_segment.v` (rewritten; ports, states, parameters kept)

| Type | orig | Change | Reason |
|---|---|---|---|
| ARCH | :60-61, :329-332 | circular 1024-entry RAM, overlap = pointer move (`blk_start += 896`) | per-cycle copy of 128 entries forced 2x1024x16 flip-flops |
| ARCH | :199 | first block waits for 1024 samples (not 896 + unwritten tail) | undefined data in the block |
| ARCH | :27-29, :265 | `mem_request`/`segment_request`/`sample_addr_out` multiplexed between the FSM priming request and the processing chain's `ref_addr` requests; no per-sample request while feeding | reference fetched at FFT-output time |
| ARCH | :361-386 | chain instance gets `segment_in`, `use_long_chirp`, `ref_addr`, `ref_req` | new chain interface |
| CLEAN | :47 | `DEBUG` default 0; every `$display` gated | simulation noise |
| CLEAN | :165 | `LONG_SEGMENTS[2:0]` part-select -> sized localparams | part-select of an unsized parameter |

## `frequency_matched_filter.v`

| Type | orig | Change | Reason |
|---|---|---|---|
| BUG | :26-27, :85-86 | `CONJUGATE_REF` parameter (default 1 = original); the chain uses 0 | the memories already hold `conj(FFT(chirp))`; a second conjugation turns the correlation into a convolution (verified: no compression peak with the original form, peak at the injected delay with `CONJUGATE_REF = 0`) |

## `fft_1024_forward.v`, `fft_1024_inverse.v`

| Type | orig | Change | Reason |
|---|---|---|---|
| BUG | :38-58 | `tlast` counter counts every valid sample (first sample was not counted) | tlast one sample late -> stray tlast -> an extra zero-filled FFT frame per block (observed in simulation: 8192 outputs for 4096 inputs) |
| BUG | :28 | `SCALE_SCH` parameter; config = `{5'b0, SCALE_SCH, FWD_INV}` (fwd default 2^-6, inv 2^-5) | fixed `16'h0001`/`16'h0000` = no scaling -> 16-bit overflow |
| CLEAN | inverse :66-75 | uninitialised debug counter removed | |

## `doppler_processor.v`

| Type | orig | Change | Reason |
|---|---|---|---|
| BUG | :217-229 | `fft_input_valid/last` delayed one cycle (`load_valid_p/load_last_p`) | valid asserted before the registered product was ready: first word stale, tlast early |
| BUG | :238 | `processing_timeout <= FFT_WAIT_TIMEOUT` (1000) | 100 cycles < FFT latency + 32 outputs |
| BUG | :286 | `FFT_CONFIG_WORD` parameter, default `8'h35` (forward, 2^-5) | `8'h01` = no scaling |
| CLEAN | :159, :245, :283 | `default` case; `doppler_bin <= fft_sample_counter[4:0]`; `.s_axis_data_tready()` | CASEINCOMPLETE, width, PINMISSING |

## `usb_data_interface.v` (rewritten; ports unchanged)

| Type | orig | Change | Reason |
|---|---|---|---|
| SYN | :46-56 | `typedef enum` -> localparams | SystemVerilog in a `.v` file |
| BUG | :65-79 vs :176-182 | `ft601_clk_out` single driver | two always blocks on different clocks |
| ARCH | :65 | FSM on `clk` (100 MHz); payload latched at packet start; fixed 11-word packet | inputs were sampled across clock domains without synchronisation and the FSM waited for one-cycle valids on every word; FT601 has no hardware (see README "Host path") |
| BUG | :20-21 | `ft601_txe_n/rxf_n` driven inactive | they are FT601 outputs per the datasheet |

## New files (`NEW`)

| File | Content |
|---|---|
| `rtl/ad9484_lvds_to_cmos_400m.v` | AD9484 SDR LVDS capture (IBUFDS + BUFG + IDDR as dual-edge sampler, `CAPTURE_FALLING`), `ifdef SIM` behavioural model, reset synchroniser, `adc_valid`, `adc_pwdn` from `pwdn_req` |
| `rtl/matched_filter_processing_chain.v` | FFT1024 -> x conj(ref) -> IFFT1024 with address-driven reference fetch and segment queue |
| `rtl/range_bin_decimator.v` | 1024 -> 64 bins, modes first/peak/mean/sum, `start_bin` |
| `rtl/xfft_32.v`, `rtl/FFT_enhanced.v` | IP-named AXI4-Stream wrappers: behavioural model under `ifndef SYNTHESIS`, fail-loud placeholder under `SYNTHESIS` (see `ip/README.md`) |
| `rtl/axis_fft_behav.v` | behavioural AXI4-Stream FFT (simulation only) |
| `rtl/async_fifo.v`, `rtl/reset_synchronizer.v`, `rtl/radar_control_regs.v` | CDC FIFO, reset synchroniser, register map |
| `rtl/sim/unisim_sim_models.v` | BUFG / IBUFDS / IDDR models for simulation and lint (excluded from Vivado) |
| `mem/long_chirp_seg3_{i,q}.mem` | generated (all zero - segment beyond the 3000-sample chirp), `gen_chirp_mem.py` |
| `tb/tb_*.v`, `tb/gen_vectors.py`, `tb/vectors/` | self-checking testbenches and numpy references |
| `constraints/radar_system_top_beta.xdc`, `vivado/*.tcl`, `ip/README.md`, `build.sh` | constraints, Vivado scripts (not executed), IP settings, open-source flow |

## Host-link option B integration (follow-up, 2026-10-09)

Source: `engineering/DESIGN/HOST_LINK/` (HOST_LINK_DESIGN.md section 5, `option_b_signal_map.csv`,
`rtl/rd_map_packer.v`, `rtl/host_bridge_spi.v`, `rtl/tb_host_bridge.v`). Originals untouched.

| Type | File | Change | Reason |
|---|---|---|---|
| NEW | `rtl/host_bridge_spi.v` | byte-identical copy of `engineering/DESIGN/HOST_LINK/rtl/host_bridge_spi.v` | SPI slave + 2-bank frame RAM |
| NEW/BUG | `rtl/rd_map_packer.v` | copy with one fix: `det_wr` widened `[5:0]` -> `[6:0]` (beta :44) | the detection-list write counter must reach `3*MAX_DET = 96`; with 6 bits the packer never left its header/detection state once `n_det >= 22` (frame never completed, DRDY never asserted). Found by `tb_host_bridge_top` (91 detections); the source unit test uses 3 detections. **To be back-ported to `engineering/DESIGN/HOST_LINK/rtl/rd_map_packer.v`.** |
| NEW | `tb/tb_host_bridge.v` | copy of the source unit test; only the dump path changed to `logs/tb_frame.hex` | runs inside `build.sh` from `beta/fpga` |
| NEW | `tb/tb_host_bridge_top.v` | top-level test: behavioural SPI master (mode 0, 25 MHz) reads one frame after DRDY in the smoke scenario; checks sync/version/flags/az-el/chirp-count/dims/n_det/2048 map bytes/detection entries/CRC/DRDY-clear/consumed/overflow, pass-through gating during the transfer and pass-through operation after it | requested by the coordinator |
| ARCH | `rtl/radar_system_top.v` | new ports `spi_bridge_cs_n` (in), `spi_bridge_drdy` (out), `spi_bridge_spare` (out); instances `rd_packer` (`rd_map_packer`) and `host_bridge` (`host_bridge_spi`) on the shared SPI1 lines; `stm32_miso_3v3 = bridge_active ? bridge_miso : passthrough_miso_3v3`; `spi_bridge_spare = packer overflow`; sticky `bridge_cs_conflict` (any ADAR CS low while the bridge CS is low) ORed into `system_status[1]`; new parameter `CFAR_THRESHOLD_DEFAULT` (default 10000, passed to the register map) | option B bridge; RTL check demanded by `option_b_signal_map.csv`; the TB lowers the threshold to exercise detections |
| ARCH | `rtl/radar_system_top.v` | cell stream to the packer: Doppler I/Q delayed one clock so that they line up with `rx_cfar_valid/detection` (which lag `rx_doppler_valid` by one clock); `cell_valid = rx_cfar_valid`, `cell_det = rx_cfar_detection`; `frame_start` = undelayed first cell (`range_bin == 0 && doppler_bin == 0`), one clock before the delayed first cell as the packer requires | the Doppler stream is range-major (64 x 32) exactly as the packer expects |
| ARCH | `rtl/radar_system_top.v` | `az_idx/el_idx` = transmitter counters `current_azimuth/elevation` (clk_120m domain) through a 2-flop synchroniser + "two equal samples" filter; `chirp_count` = 16-bit count of receiver chirp-counter changes (clk_100m); `long_chirp` = register-map `use_long_chirp` | the TX STM32-toggle counters are the only beam-position source in the design (the register map has no az/el field); they change milliseconds apart so the stability filter is sufficient |
| ARCH | `rtl/radar_transmitter.v` | new input `spi_passthrough_gate`; while high the level-shifter inputs are forced idle (`cs_3v3 | gate`, `sclk/mosi & ~gate`) so the ADAR1000 CS stay high and SCLK/MOSI are quiet on the 1.8 V side; `stm32_miso_3v3` output now carries only the pass-through MISO (muxed at the top) | bridge transfers on the shared bus must not reach the beamformers |
| — | `rtl/usb_data_interface.v` | unchanged | option A path kept for Main Board rev. B |
| XDC | `constraints/radar_system_top_beta.xdc` | `PACKAGE_PIN H11/G12/H12` + `LVCMOS33` (+ `PULLUP` on CS) for the three bridge ports (bank 15, nets DIG_5/6/7 exist on the board); `create_clock spi_sclk` 37 ns on `stm32_sclk_3v3` added to the asynchronous clock groups; the pass-through false paths narrowed to the `ls_adar*` cells; bridge input/output delays left as commented placeholders (STM32 SPI1 timing + trace delays UNRESOLVED); DIG_5..7 removed from the "no RTL port" list | option B pins |
| — | `build.sh` | no logic change (picks up `tb/tb_*.v`); header lists the two new testbenches | |

## ISERDES capture + polyphase DDC (follow-up, 2026-10-09) - `ADC_CAPTURE_MODE`

Datasheet re-check (`AD9484.pdf`, Table 4 / "Output Data Rate" / register map): LVDS **SDR**, DCO at
the sample clock rate, data valid on the rising DCO edge, tSKEW -0.07..+0.07 ns, tPD 0.85 ns,
tCPD 0.6 ns, latency 15 clocks; test modes in register 0x0D[3:0] (0100 checkerboard, 0101 PN23,
0110 PN9, 0111 one/zero toggle, 1000 user defined with 0x0D[7:6] = 01 "toggle P1/P2", P1 =
0x19/0x1A, P2 = 0x1B/0x1C); output format offset binary by default (0x14).

| Type | File | Change | Reason |
|---|---|---|---|
| NEW | `rtl/ad9484_iserdes_capture.v` | IBUFDS(DCO) -> BUFIO + BUFR/4; 8 x IBUFDS -> IDELAYE2 (VAR_LOAD, tap from `adc_capture_calib`) -> ISERDESE2 (SDR 1:4, NETWORKING, IOBDELAY IFD); IDELAYCTRL on `clk_200m_ref`; 4 x 8-bit word per clk_div cycle + valid; `async_fifo` (32-bit) into clk_100m; `fifo_overflow` sticky; `Q1_IS_OLDEST` parameter | no fabric logic at 400 MHz; SDR per datasheet (DDR 1:8 not needed) |
| NEW | `rtl/adc_capture_calib.v` | calibration FSM in the clk_div domain: default taps (16) after reset; manual tap / bitslip per lane; auto sweep taps 0..31 (SETTLE 16, MEAS 64 words, per-lane pass mask, longest circular run, centre tap, lock if run >= MIN_WINDOW 4 and < 32, undetermined for constant pattern bits); lane alignment pass (rotation majority, BITSLIP for minority lanes, `align_fail`); word-level pattern error counter | per-lane eye centring and framing consistency; see header for the AD9484 SPI writes the host must do (SPI path UNRESOLVED on the schematic) |
| NEW | `rtl/ddc_4x_100m.v` | 4-phase NCO (same FTW, table, quadrant logic and dither sequence as the legacy path, LFSR unrolled 4 steps/clock), 8 x (9x16) mixers bit-exact to `mixed[33:16]`, CIC/4 as the 16-tap FIR (1+z^-1+z^-2+z^-3)^5 >> 10 saturated (`CIC_PHASE` 0 = legacy decimation phase), the two unchanged `fir_lowpass_parallel_enhanced`, registered output with the legacy valid semantics | 100 MHz implementation of the 400 MHz mixer + CIC; `tb_ddc_4x`: max diff **0 LSB** vs the legacy over 1855 outputs |
| NEW | `rtl/clk_gen.v` | MMCME2_BASE clk_100m x8/4 -> 200 MHz BUFG (`clk_200m_ref`, `locked`); `ifdef SIM` behavioural | IDELAYCTRL reference; the design had no MMCM |
| NEW | `rtl/sim/unisim_sim_models.v` (+) | BUFIO, BUFR (/N), IDELAYE2 (78.125 ps/tap transport delay, VAR_LOAD/CE), IDELAYCTRL (RDY after 16 REFCLK), ISERDESE2 (SDR 1:N networking, BITSLIP, Q1 = oldest, 0.2 ns setup/hold metastability window -> random bit), MMCME2_BASE (CLKOUT0/CLKFBOUT/LOCKED) | iverilog/Verilator stand-ins; the metastability window is what makes the IDELAY sweep find a fail region in simulation |
| ARCH | `rtl/radar_receiver_final.v` | `ADC_CAPTURE_MODE` parameter (default 1) with a `generate`: 0 = `ad9484_lvds_to_cmos_400m` + `ddc_400m_enhanced` (unchanged legacy), 1 = `clk_gen` + `ad9484_iserdes_capture` + `adc_capture_calib` + `ddc_4x_100m`; calibration control/status ports added; `cdc_overflow` = capture FIFO overflow in mode 1 | selectable implementation, identical baseband format into `ddc_input_interface` |
| ARCH | `rtl/radar_system_top.v` | `ADC_CAPTURE_MODE` parameter passed to the receiver; register-map calibration signals wired | |
| ARCH | `rtl/radar_control_regs.v` | registers 0x4..0xC (CAL_CTRL toggles/check-enable, CAL_LANE, CAL_TAP, CAL_SLIP, CAL_PATT = 0x55AA, read-only CAL_STAT/CAL_LANE_INFO/CAL_ERR/CAL_UNDET) | host control of the calibration (write port still tied off at the top) |
| BUG | `rtl/ddc_400m.v` | legacy NCO `phase_valid` = `mixers_enable_sync & adc_data_valid` (was `mixers_enable_sync`) | phase becomes a function of the sample index; required for the bit-exact comparison; identical behaviour for a continuous stream |
| NEW | `tb/tb_adc_iserdes_capture.v` | 400 MHz source, 8 lanes at +0.25 ns (tPD-tCPD), lane 5 +0.85 ns; auto cal locks 8/8 (taps 12, lane 5 -> 4, 8 taps less = 0.6 ns), error counter 0 at the centres, 1 bitslip on lane 0 -> errors, 4 -> none, manual tap visible on CNTVALUEOUT, 4000 sine samples reproduced exactly through the FIFO with clk_100m offset 1.3 ns vs DCO/4 | |
| NEW | `tb/tb_ddc_4x.v` | same 8000-sample sequence (two IF tones + chirp burst + noise) through `ddc_400m_enhanced` and `ddc_4x_100m`; baseband outputs compared after lag search (first 64 skipped); `CIC_PHASE_TB` parameter | PASS: max diff 0 LSB |
| — | `tb/tb_system_smoke.v`, `build.sh` | `ADC_MODE` parameter; `build.sh` runs the smoke test twice (`_mode1`, `_mode0`) via `-P` | both capture paths exercised end to end |
| XDC | `constraints/radar_system_top_beta.xdc` | ADC `set_input_delay` = datasheet tSKEW +/-0.070 ns (board trace skew to be added), legacy falling-edge lines commented, `IODELAY_GROUP adc_idelay_grp` for IDELAYCTRL + IDELAYE2, notes on BUFIO/BUFR/MMCM auto-derived clocks and the Vivado checks | |

## Command set v2, blind calibration, UG471 checks (follow-up, 2026-10-09)

Sources: `engineering/DESIGN/HOST_LINK/HOST_LINK_DESIGN.md` section 7 (byte sequences fixed by the
firmware `beta/stm32/Core/Src/host_bridge_proto.c`), UG471 v1.10 (`build/docs_ext/ug471.txt`, quotes
in README "UG471 checks"). Originals untouched. The previous, uncommitted attempt at these changes
(did not compile: `rd_data_tog` used before declaration, top/module port mismatch, undeclared
`inherit_tap`, undriven `lane_metric`) was replaced.

| Type | File | Change | Reason |
|---|---|---|---|
| ARCH | `rtl/host_bridge_spi.v` | command set v2: `cmd`/`bytec` decode after the command byte; 0x02 write (addr bytes 0-1, data bytes 2-5 little-endian, `wr_req_t` toggle at d3, ack 0xA2 loaded for byte 7), 0x03 read (`rd_req_t` toggle when a0 is complete, `reg_addr = {8'h00, a0}`, data captured one clk after the address through `rd_fetch`, d0..d3 in bytes 3..6), 0x04 status (`status_snap` = {0, frames_produced, RTL_VERSION, status_in} sampled at the command byte, bytes 1..8), unknown/0x00 -> 0xEE; new parameter `RTL_VERSION` (0x0002), new ports `reg_we/reg_addr[15:0]/reg_wdata[31:0]/reg_rdata[31:0]/status_in[15:0]/frames_produced[15:0]`; 3-flop toggle synchronisers for the register requests; 0x01 path unchanged | register access over the existing bridge; byte positions match `hb_proto_write_reg/read_reg/status` exactly (rx[7] ack, rx[3..6] value, rx[1..8] status) |
| ARCH | `rtl/radar_control_regs.v` | `reg_addr` 4 -> 5 bits (existing addresses unchanged); CAL_CTRL bit4 `cal_blind` (level); new 0x0D `CAL_BLIND_COEF` (Q1.14 cos, default 0xEC39 = -5063 = cos(2*pi*120/400)*16384), 0x0E `CAL_BLIND_MARGIN` (default 0x0040), 0x10 `CAL_BLIND_MIN` (ro); header comment = section 7 table | blind calibration controls; address space for the read-back |
| ARCH | `rtl/radar_system_top.v` | bridge register port wired to `ctl_regs` (`reg_addr[4:0]`, `reg_wdata[15:0]`, `reg_rdata = {16'h0, rdata}`); `frames_produced` counter of `pk_frame_done`; `bridge_status = {11'b0, pk_overflow, cal_status[7:0] == 8'hFF, rx_cdc_overflow, bridge_cs_conflict, spi_bridge_drdy}`; blind calibration signals routed register map <-> receiver | the register write port was tied off (`1'b0`) since the first beta |
| ARCH | `rtl/radar_receiver_final.v` | ports `cal_blind`, `cal_blind_coef`, `cal_blind_margin`, `cal_blind_min`; mode 0 ties `cal_blind_min = 0`; `Q1_IS_OLDEST(0)` on the capture instance | |
| ARCH | `rtl/adc_capture_calib.v` | blind method (`ctrl_blind`): notch residual r[n] = x[n] - (coef*x[n-1])/8192 + x[n-2] on the 4 samples of each word (x = sample - 128, x[-1]/x[-2] from the previous word), metric = sum of abs(r) over `MEAS_BLIND = 512` words, 24-bit saturating, per-tap store `met[0:31]` + running minimum; lanes swept one at a time MSB first with the result applied before the next lane; pass mask = metric <= min + margin + min/16, 1-tap holes closed, linear longest run; centre = (lo+hi)/2, or hi+1-16+FAIL_HALF when the run touches tap 0, lo-1+16-FAIL_HALF when it touches tap 31 (32 taps = 1 bit at 400 MSPS), truncated runs accepted from 2 taps, untruncated need MIN_WINDOW, 32/32 -> undetermined (tap kept); `BLIND_PASSES = 2`; blind framing alignment (metric for the 4 framings of every lane via BITSLIP, minimum kept) before the first pass and after every pass; `lane_metric_min` output; `meas_cnt` 8 -> 10 bits; states 5 bits (S_BL_*). Pattern method, manual mode, check counter unchanged | calibration without the ADC test pattern (AD9484 SPI not wired); the originally suggested abs(x[n]-x[n-1]) does not discriminate for a 120 MHz tone at 400 MSPS (adjacent samples legitimately differ by up to 1.6 A) |
| BUG | `rtl/sim/unisim_sim_models.v` (ISERDESE2) | Q order: `word <= sr & WMASK` so that Q1 = newest, Q(N) = oldest = first received (was Q1 = oldest); BITSLIP moves the frame boundary one bit later (`cnt + N - slip`, was earlier); hold-window corruption fixed: the old code did `sr[0] <= $random` and then `sr <= {sr[6:0], din}` in the same block, so the second assignment overrode the first and the declared 0.2 ns hold window never acted - now `nxt[1] = rnd[1]` before `sr <= nxt` (the two block-local temporaries carry a local `lint_off BLKSEQ`). Fail region per lane is now 5 taps (27..31) instead of 2 (27..28) | UG471 p. 146 / Fig. 3-3 / p. 158 Fig. 3-11 (quotes in README); model fidelity |
| ARCH | `rtl/ad9484_iserdes_capture.v` | `Q1_IS_OLDEST` default 1 -> 0, header cites UG471 | first bit received on the highest-order Q |
| TB | `tb/tb_host_bridge_top.v` | DUT at the default `CFAR_THRESHOLD_DEFAULT` (10000); v2 register commands before the chirps (ID, CFAR_THR default, writes of CFAR_THR = 150 / CAL_CTRL = 0x18 / CAL_LANE = 3 / CAL_BLIND_COEF = 0xDEAD1234, read-backs incl. upper-16-bit masking, DUT control outputs checked, 0x04 status, 0x7F -> 0xEE, 0x01 without a frame -> zeros, DRDY still 0, pass-through gated); 0x04 with a frame pending (bit0 = 1, frames = 1) and after the read (bit0 = 0); detections must be present (threshold reached the detector only through the bridge write) | PASS: 2162-byte frame, 32 detections |
| TB | `tb/tb_host_bridge.v` (= `engineering/DESIGN/HOST_LINK/rtl/tb_host_bridge.v`) | now the engineering version (scenario 2: 32-detection regression) plus scenario 3: v2 write/read against a 4-word register model, 0x04 (status = DRDY, version 2, frames 2), 0xEE; the frame dump falls back to `tb_frame.hex` when `logs/` does not exist, so both copies are byte-identical | PASS |
| TB | `tb/tb_adc_iserdes_capture.v` | step 5 (blind): 120 MHz tone (100 LSB peak) + -1/0/+1 LSB noise, `tone_n` phase index (the `src` store stops at 65536 samples - the previous attempt froze the source mid-run), lane 2 parked on tap 27 (metastable), lane 0 bitslipped once, blind run with coef 0xEC39 / margin 64; checks: 8/8 lock, no undetermined, every lane within +/-2 taps of its pattern centre (result: +/-0), tone sequence reproduced exactly (framing restored); `check_sequence` task; `Q1_IS_OLDEST(0)`; timeout 12 ms. Pattern-method expectations unchanged (centre is now 13 / lane 5 -> 5 because of the model's wider fail region) | PASS |
| DOC | `engineering/DESIGN/HOST_LINK/HOST_LINK_DESIGN.md` section 7 | byte counts, no-turnaround read, status-word bits, full register table 0x00..0x10 identical to the RTL (run / mixers / NCO entries that never existed removed) | the shared source for firmware and GUI |
| DOC | `engineering/DESIGN/HOST_LINK/rtl/host_bridge_spi.v`, `.../tb_host_bridge.v` | byte-identical copies of the beta files; `run_tb.sh` PASS | back-port |
| XDC | `constraints/radar_system_top_beta.xdc` | header quotes the UG471 LVDS criteria verbatim; per-pin comments on the 18 bank-14 LVDS lines cite them; external 100 Ohm RDIFF + DS181 VIN/VIDIFF/VICM check marked REQUIRED / REQUIRES VERIFICATION | |
| DOC | `README.md` | results table, register-map paragraph, blind method + limits, "UG471 checks" section with the quotes, remaining-work list (items 7/8 closed, GUI register_map follow-up added) | |
| — | `build.sh` | unchanged; full run after these changes: 0 failures, 324 verilator warning lines (165 synth + 159 sim, identical to the previous state) | |

Not changed: `beta/gui/aeris10_gui/protocol/register_map.py` (GUI, out of scope here) - it masks
addresses with 0xF and documents a section-7 discrepancy that no longer exists; see README item 8.

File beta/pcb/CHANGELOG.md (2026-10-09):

# AERIS-10 — BETA PCB changelog

All boards under `beta/pcb/<BOARD>/` are **BETA: KiCad 10.0.6-routed/checked copies of the EAGLE conversion in `engineering/PCB/`; DRC-checked; not reviewed by the original designer; not fabricated.** The EAGLE originals (`4_Schematics and Boards Layout/`) and `engineering/PCB/` were not modified. No change below alters the netlist; only routing, placement of parts that were outside the outline, zone fills/priorities, copper-polygon net labels, silkscreen text positions and documentation.

Tooling: `beta/pcb/tools/` (pcbnew Python scripts, `beta_drc.sh`, `beta_export_package.sh`), Freerouting **2.5.0** (`beta/pcb/tools/freerouting-2.5.0.jar`, build 2026-10-05, SHA-256 `f6f51bb02245e8e717f9359bd260cc9c5c0b1bc0acc8b7cb2cd5b8ffeb5de3c7`, run with OpenJDK 27 `java -jar freerouting-2.5.0.jar -de X.dsn -do X.ses -mp N -mt 8 -l en`; the `-oit` flag of older versions no longer exists in 2.5.0 `--help`), KiCad Python 3 (pcbnew: `ExportSpecctraDSN`, `ZONE_FILLER` via `kicad-cli pcb drc --refill-zones --save-board`).

## 2026-10-09 — initial BETA

### All boards
- Copied `engineering/PCB/<BOARD>/kicad/<BOARD>.kicad_pcb` + `.kicad_pro` (+ `.kicad_dru` for the synthesizer) to `beta/pcb/<BOARD>/`.
- `BOM_<BOARD>_beta.csv` generated by `tools/beta_bom_mpn.py` from `docs/BOM/BOM_<BOARD>.csv`: columns `manufacturer, mpn, mpn_confidence (HIGH/MEDIUM/LOW/EMPTY), dnp, note`.
- `FAB_NOTES.md`: PCBWay stack-up proposal per DRU layer count, materials, ENIG, mask/silk colours, DRU minima, impedance targets with the trace widths measured on the boards (all PROPOSED).
- Full export package in `exports/` with the same export set as `tools/kicad_pcb_pipeline.sh` (`tools/beta_export_package.sh`, log in `exports/EXPORT_LOG.md`).

### RF_PA
- Added GND track F.Cu 0.5 mm, via (16.20, −11.20) → U$1 paddle centre (16.20, −13.40) (`fixes.json`). Unconnected 1 → 0.
- U$1 net-less footprint copper polygon (QPA2962 paddle) → board-level copper polygon, net GND (touched 21 GND items only). `POLYGON_NET_DISPOSITION.md`.
- 6 overlapping same-net GND zones re-prioritised (`zone_priorities.json`). DRC 67 → 18 (remaining: 1 clearance in the source, 17 silkscreen).

### FREQUENCY_SYNTHESIZER
- No copper change. 43 silkscreen reference texts nudged (`silk_nudges.json`); 103 remain in conflict (`silk_conflicts_remaining.json`).
- `DRC_DISPOSITION.md`: 639 items classified — 7 courtyard overlaps (review), 35 GND arc stubs (cosmetic), silk/mask items (cosmetic / fab CAM; KiCad report cap 199 explained).

### POWER_SUPPLY
- Netclass `Default` in `POWER_SUPPLY.kicad_pro` set to track 0.25 mm / clearance 0.2 mm (BETA routing rule; existing tracks unchanged).
- 132 footprints that were parked outside the outline (y = +77…+701 mm) placed inside by `tools/beta_place_outside.py` (clusters by shared nets, 1 mm grid, free-space search, 22 KK connectors on the board edges). Logs `placement_moves.json`, `placement_moves_connectors.json`.
- Freerouting 2.5.0 pass 1 (`POWER_SUPPLY.dsn/.ses`, existing tracks exported as `(type fix)`): 1336 track segments + 168 vias merged by `tools/beta_specctra.py merge` (`ses_merge.json`). Freerouting result: 45 unrouted, 23 of its own violations; KiCad unconnected 308 → 102.
- 45 overlapping same-net zones re-prioritised (`zone_priorities.json`); board-wide GND zone added on B.Cu (`BETA_GND_plane_B.Cu`, priority 0; it fills only where the EAGLE B.Cu GND polygon does not).
- `tools/beta_bridge_unconnected.py`: 96 straight same-net bridges added, 67 reverted after DRC (clearance/crossing) → 29 kept (`bridges_pass1.json`). Unconnected 102 → 96.
- Freerouting pass 2 on the bridged board (`POWER_SUPPLY_pass2.*`) — see the final entry below.

### MAIN_BOARD
- 7 arc tails added (same net/layer/width, inside the arc's own copper) where EAGLE arcs ended at a pad centre but KiCad reported them unconnected: AMP_IN_P/L9, +3V3_AN/L18 & L16, RF_RX_FIL/U$3, VG_11/R121, DAC_2_VG_CLR/U69, N$49/R19 (`fixes_stubs.json`).
- +3V3_FT filter parts L19, C159, C184, C185, C186 (outside the outline at y = +63…+75 mm) placed inside at (5…12, −232…−240) on F.Cu (`placement_moves.json`). R60/R61/R83/R84/R145/R146 (no net on any pin) left outside and marked DNP in the BOM.
- 30 net-less footprint copper polygons (BPF2 filters U$2/U$3, U13, U5) dispositioned: 14 unambiguous ones (GND ×8, RF_TX, RF_RX ×2, RF_TX_FIL ×2, RF_RX_FIL) re-created as board-level copper polygons with their net; 4 ambiguous (touch GND and an RF net) and 12 isolated left as they are (`POLYGON_NET_DISPOSITION.md`).
- Routing of the placed filter cluster (+3V3_FPGA, +3V3_FT, GND) — see the final entry below.

### POWER_SUPPLY — final BETA state (2026-10-09)
- Freerouting pass 2 (12 passes) merged: +36 tracks, +3 vias (`ses_merge_pass2.json`); no change in unconnected count.
- GND stitching (`tools/beta_gnd_stitch.py`): 50 items tried, 22 kept after DRC revert (`stitch_gnd.json`). Unconnected 96 → **89**.
- Final: **89 unconnected** (49 GND, 10 VIN, 30 on regulator-output nets — all listed with reasons in `UNROUTED.md`), DRC 328 (clearance 56 source/footprint-level, silk 233, via_dangling 20, drill_out_of_range 8, mask 8, dangling 2, zones_intersect 1). Package exported to `exports/`.

### MAIN_BOARD — final BETA state (2026-10-09)
- Scripted straight bridges for the 9 cluster connections: 3 kept, 6 reverted after DRC (`bridges.json`); the diagonal GND bridge was removed again in favour of plane vias.
- Hand routing (`manual_routing.json`): 4 GND vias 0.45/0.20 mm to the inner GND planes, +3V3_FT bus 0.3 mm, +3V3_FPGA feed 0.5 mm to X16 pin 1. **Unconnected 15 → 0.**
- Freerouting run on the locked 10-layer DSN stopped (killed) during its fanout stage after ~15 min — not needed.
- Overlapping same-net zones re-prioritised. Final DRC 1049 (0 unconnected): 125 shorting / 87 hole / 72 clearance dominated by the no-net thermal-via pads of U69/U7 and the 4 ambiguous BPF2 polygons (schematic/footprint level, see `README.md` §3), 130 dangling track ends, 35 dangling vias, silk/mask ≥ 199 each (report cap).

### MAIN_BOARD_REVB — rev. B PROPOSAL, explicit NETLIST CHANGE (2026-10-09)
- New directory `MAIN_BOARD_REVB/` created from the BETA `MAIN_BOARD/` board by `tools/beta_revb_ft601.py` (reproducible; rev. A board untouched).
- **Netlist change (rev. B):** 64 new nets; 123 pad connections on U6 (FT601) and U42 (XC7A50T bank 35) per `engineering/DESIGN/HOST_LINK/ft601_pin_assignment.csv`; U6 VCC33/VCCIO → `+3V3_FT`, GND pads → GND, AVDD/VDDA → `FT_AVDD`, VD10/DV10 → `FT_VD10`, XI/XO, RREF, VBUS detect, D±, SS TX/RX. Full list: `MAIN_BOARD_REVB/NETLIST_DELTA.csv` and README §3.
- 20 parts added (USB-C Amphenol 12401610E4#2A on the left edge, 2 × TPD4E05U06, 30 MHz crystal + 2 × 18 pF, RREF 3.24 k, VBUS divider 10 k/3.3 k, CC 2 × 5.1 k, SSTX AC caps 2 × 100 nF, FB + 2 caps AVDD, 4 × 4.7 µF VD10). Netclasses FT_BUS 0.204/0.1, USB_DIFF 0.204 gap 0.18, FT_PWR 0.3/0.1.
- Freerouting 2.5.0 on a DSN restricted to the new nets (`tools/beta_dsn_restrict.py`; all existing copper `(type fix)`): 1 pass (25 min), FR result 62 unrouted. Merged: GND 89 tracks + 6 vias, signals 319 tracks + 70 vias; then 127 items of the 47 still-open bus nets removed again (`removed_unfinished_routes.json`).
- Result: unconnected 0 (rev. A) → 129 (rev. B unrouted) → **59** (rev. B routed); DRC 1049 → 1071. Bus not routable without re-doing the U42 bank-35 breakout (36 of 47 balls have no escape-via position) — `MAIN_BOARD_REVB/UNROUTED.md`.
- Full export package `MAIN_BOARD_REVB/exports/`; BOM `BOM_MAIN_BOARD_REVB_beta.csv`.
- Not executed (tool permission denied in this session): second restricted routing pass for the open power nets, widening of 0.075 mm neck-downs, nudging C_XI/C_XO. The EAGLE schematic must be updated by the designer to match.

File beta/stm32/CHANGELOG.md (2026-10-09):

# beta/stm32 — CHANGELOG versus the original sources

Scope: every difference between `beta/stm32/` and `9_Firmware/9_1_Microcontroller/` (originals untouched).
Date 2026-10-09. Author: embedded engineer, BETA bring-up. Line numbers refer to the **original** files
(`CODE` = `9_1_3_C_Cpp_Code`, `LIB` = `9_1_1_C_Cpp_Libraries`).

Category legend: **DEFECT** = fix of code that could not work as written; **HW-TRUTH** = change that
re-aligns the firmware with the schematic/board evidence (each one has an entry in `DECISIONS.md`);
**BUILD** = needed to compile/link; **REFACTOR** = no functional change; **NEW** = file did not exist.

Note on line endings: the originals use CRLF; files rewritten here were saved with LF. `diff -u` therefore
shows whole-file hunks; use `diff -u --strip-trailing-cr` to see the real changes.

## 1. Tree re-arrangement (no content change unless listed below)

| Original | Beta | Category |
|---|---|---|
| `CODE/main.cpp`, `CODE/main.h` | `Core/Src/main.cpp`, `Core/Inc/main.h` (`main.h` byte-identical) | REFACTOR (CubeMX layout) |
| `LIB/stm32f7xx_hal_conf.h`, `LIB/stm32f7xx_it.h` | `Core/Inc/` (`_it.h` identical) | REFACTOR |
| `LIB/stm32f7xx_hal_msp.c`, `LIB/stm32f7xx_it.c`, `LIB/system_stm32f7xx.c`, `LIB/syscalls.c`, `LIB/sysmem.c` | `Core/Src/` (all five byte-identical) | REFACTOR |
| `LIB/ADS7830.H`, `LIB/DAC5578.H` | `LIB/ADS7830.h`, `LIB/DAC5578.h` (content identical) | BUILD — sources include them as `.h` (`LIB/ADS7830.c:1`, `LIB/DA5578.c:1`, `CODE/main.cpp:64-65`); case-sensitive filesystems/CI |
| `LIB/platform_noos_stm32.c/.H` | `LIB/_excluded/` | BUILD — `.c` calls undefined `hal_set_gpio_by_index()` (`:50-58`); no caller of its API; include removed from `main.cpp:53-55` |
| `LIB/errno.h` | `LIB/_excluded/errno.h` | BUILD — ARMCC-only shim; with GCC its `#include_next <errno.h>` (`:94`) re-included itself when reached via `#include "errno.h"` from the same directory (`LIB/no_os_util.c:37`) and `EINVAL` was never defined |
| all other `LIB/*` (116 files) | `LIB/` | copied verbatim; only the files listed in §2 are compiled (`CMakeLists.txt`) |

## 2. Source changes

### Core/Src/main.cpp (from CODE/main.cpp)
| Orig. lines | Change | Category |
|---|---|---|
| 53-55 | removed `extern "C" { #include "platform_noos_stm32.h" }` | BUILD (file excluded) |
| 66 | added `#include "aeris_beam.h"` | REFACTOR |
| 285, 294 | comments: TIM1 tick now 216 MHz / 216 | HW-TRUTH D-02 |
| 317-326 | `degreesTo7BitPhase()` body → calls `aeris_degrees_to_7bit_phase()` (identical arithmetic in `LIB/aeris_beam.c`) | REFACTOR (host-testable) |
| 328-339 | removed dead `extern "C" void CDC_Receive_FS()` (never called: CubeMX `usbd_cdc_if.c` binds its own static function). Added `extern "C" void AERIS_USB_OnReceive(const uint8_t*, uint32_t)` → `usbHandler.processUSBData()`, called from `USB_DEVICE/App/usbd_cdc_if.c` | DEFECT C4 (D-10) |
| 328-339 | added `extern "C" int __io_putchar(int)` → `HAL_UART_Transmit(&huart3, ...)`. `syscalls.c:_write()` calls the weak `__io_putchar`; with no definition every `printf()` (used throughout `adf4382a_manager.c`) would branch to address 0 | DEFECT |
| 380-382 | `systemPowerDownSequence()`: added `EN_DIS_RFPA_VDD` LOW + 10 ms **before** the PA 5 V enables are dropped | HW-TRUTH D-11 |
| 403-406 | `systemPowerDownSequence()`: added `EN_P_5V5_PA` LOW + 10 ms as the last step | HW-TRUTH D-11 |
| 416-439 | `initializeBeamMatrices()` body → `aeris_build_beam_matrices(phase_differences, matrix1, matrix2, vector_0)` | REFACTOR |
| 1037 | `init_param.spi_init.chip_select = 0` → `STM32_SPI_CS_AD9523` (same value 0, now meaningful: PF7) | HW-TRUTH D-05 |
| 1045-1047 | removed `ad9523_init(&init_param); ret = ad9523_setup(&dev, &init_param);` — `ad9523_init()` (`LIB/ad9523.c:344-418`) resets every `pdata` field (all channels → num 0 / divider 0 / LVPECL, PLL1 bypass, N=16), discarding the configuration built in lines 929-1030; the second `ad9523_setup()` at 1058 then ran again and leaked the first device | DEFECT C8/C9 (found by `tests/test_ad9523_regs.c`) |
| 1229 | added `GPS_Init(&huart3);` after `MX_USB_DEVICE_Init()` | DEFECT C6 |
| 1560-1562 | PA bring-up: added `EN_P_5V5_PA` HIGH + 100 ms before `DAC5578_Init()` (VG driver rails were never enabled) | HW-TRUTH D-11 |
| 1600-1601 | added 20 ms settle between the VG DAC/LDAC update and `EN_DIS_RFPA_VDD` HIGH | HW-TRUTH D-11 |
| 1653 | `adc1_readings[channel] = ADS7830_Measure_SingleEnded(&hadc2, ...)` → `adc2_readings[...]` (the value was read into the wrong array and `Idq_reading[channel+8]` used stale `adc2_readings`) | DEFECT U10 |
| 1815 | `PWR_REGULATOR_VOLTAGE_SCALE3` → `SCALE1` | HW-TRUTH D-01 |
| 1824-1827 | PLL `M=25,N=144,P=2,Q=3` → `M=8,N=432,P=2,Q=9`; added `HAL_PWREx_EnableOverDrive()` | HW-TRUTH D-01 |
| 1838-1842 | `APB1 /2, APB2 /1, FLASH_LATENCY_2` → `APB1 /4, APB2 /2, FLASH_LATENCY_7` | HW-TRUTH D-02 |
| 1858-1859 | `PeriphCommonClock_Config()`: added `RCC_PERIPHCLK_CLK48` with `RCC_CLK48SOURCE_PLL` | HW-TRUTH D-01 (USB 48 MHz source made explicit) |
| 1883, 1931, 1979 | I2C1/2/3 `Timing 0x00808CD2` → `0x10916EA0` | HW-TRUTH D-03 |
| 2034, 2074 | SPI1/SPI4 `BaudRatePrescaler _2` → `_16` | HW-TRUTH D-06 |
| 2110 | TIM1 `Prescaler 71` → `215` | HW-TRUTH D-02 |
| 2338-2340 | `MX_GPIO_Init()` USER CODE 2: park `AD9523_CS`, `ADF4382_TX_CS`, `ADF4382_RX_CS`, `ADAR_1..4_CS` HIGH (generated code left them LOW = all slaves selected) | DEFECT C7 (D-05) |

### LIB/USBHandler.cpp, LIB/USBHandler.h
| Orig. lines | Change | Category |
|---|---|---|
| `.cpp` 41 | `for (i = 0; i <= length - 4; ...)` → guard `length < 4` + `i + 4 <= length` (unsigned underflow → out-of-bounds read on short packets) | DEFECT |
| `.cpp` 59-93 | `processSettingsData()` now synchronises on `"SET"` (drops leading bytes, keeps ≤2 possible partial-marker bytes), resets/re-syncs on a rejected packet or on overflow | DEFECT C5 |
| `.h` 40 | added member `bool synced_on_set` | DEFECT C5 |

### LIB/adf4382a_manager.h, LIB/adf4382a_manager.c
| Orig. lines | Change | Category |
|---|---|---|
| `.h` 6 | added `#include "stm32_spi.h"` | BUILD |
| `.h` 8-29 | `TX_*`/`RX_*` pin macros PG0..PG9 → aliases of `main.h` `ADF4382_TX_*`/`ADF4382_RX_*` (PG6..PG15) | HW-TRUTH D-04 (DEFECT C2) |
| `.c` 10, 480 | `set_chip_enable(uint8_t ce_pin, ...)` → `uint16_t` (GPIO_PIN_9/15 do not fit in 8 bits) | DEFECT (consequence of C2) |
| `.c` 40, 49 | `chip_select = TX_CS_Pin/RX_CS_Pin` → `STM32_SPI_CS_ADF4382_TX/RX` (logical index; the 16-bit pin mask was truncated into the `uint8_t` field) | HW-TRUTH D-05 |
| `.c` 42, 51 | `platform_ops = NULL` → `&stm32_spi_ops` | DEFECT C3 |

### LIB/stm32_spi.c, LIB/stm32_spi.h (rewritten)
| Orig. lines | Change | Category |
|---|---|---|
| `.c` 23-26 | `write_and_read(..., uint32_t)` → `uint16_t` to match `no_os_spi_platform_ops` (`LIB/no_os_spi.h:214`); GCC 14 rejects the incompatible pointer | BUILD |
| `.c` 5-21 | `init()`: validates `extra`/`chip_select`, stores `device_id`, `bit_order`, `chip_select`; derives the SPI prescaler from `max_speed_hz` via `stm32_spi_prescaler_for(HAL_RCC_GetPCLK2Freq(), ...)` and re-inits the HAL handle; parks CS high | DEFECT C7 (D-05/D-06) |
| `.c` 23-38 | `write_and_read()`: asserts the CS GPIO low around `HAL_SPI_TransmitReceive()` | DEFECT C7 (D-05) |
| `.h` | added `enum stm32_spi_cs_index` (PF7 / PG14 / PG10 from `main.h`) and `stm32_spi_prescaler_for()` | HW-TRUTH D-05 |

### LIB/ADAR1000_Manager.cpp
| Orig. lines | Change | Category |
|---|---|---|
| 332, 336, 351, 368-370, 436, 446-448, 472-474, 488, 539-541, 545-547, 551, 555 | 22 raw `HAL_GPIO_WritePin(GPIOE, GPIO_PIN_13/14/15, ...)` / `(GPIOG, GPIO_PIN_0/1/2, ...)` → `main.h` macros `EN_P_3V3_ADTR`, `EN_P_3V3_SW`, `EN_P_3V3_VDD_SW`, `EN_P_5V0_PA1/2/3` (same pins; traceable to the schematic nets) | REFACTOR |

### Core/Inc/stm32f7xx_hal_conf.h
| Orig. lines | Change | Category |
|---|---|---|
| 97 | `HSE_VALUE 25000000U` → `8000000U` | HW-TRUTH D-01 |
| 80 | stale commented `/* #define HAL_EXTI_MODULE_ENABLED */` line blanked (the active define at 82 is unchanged) | REFACTOR |

## 3. New files

| Path | Origin | Category |
|---|---|---|
| `USB_DEVICE/Target/usbd_conf.c/.h` | hand-written CubeMX-equivalent, from ST template `Core/Src/usbd_conf_template.c` + reference `cube/Projects/STM32F746ZG-Nucleo/Applications/USB_Device/HID_Standalone/Src/usbd_conf.c` | NEW (D-07, D-08) |
| `USB_DEVICE/App/usb_device.c/.h`, `usbd_desc.c/.h`, `usbd_cdc_if.c/.h` | hand-written CubeMX-equivalent, from ST templates `usbd_desc_template.c`, `usbd_cdc_if_template.c` | NEW (D-09, D-10) |
| `Core/Startup/startup_stm32f746xx.s` | verbatim `cube/Drivers/CMSIS/Device/ST/STM32F7xx/Source/Templates/gcc/startup_stm32f746xx.s` | NEW |
| `STM32F746ZGTx_FLASH.ld` | verbatim `cube/Projects/STM32F746ZG-Nucleo/Templates/SW4STM32/STM32F746ZG_Nucleo_AXIM-FLASH/STM32F746ZGTx_FLASH.ld` | NEW |
| `LIB/aeris_beam.c/.h` | extracted from `CODE/main.cpp:317-443` | REFACTOR |
| `CMakeLists.txt`, `cmake/arm-none-eabi.cmake`, `build.sh`, `setup_cube.sh`, `.gitignore` | new | BUILD (D-13, D-14) |
| `tests/*` | new host unit tests | NEW |
| `README.md`, `DECISIONS.md`, `CUBEMX_SETTINGS.md`, this file | new | docs |
| `cube/` | STM32CubeF7 sparse checkout, pinned commits in `DECISIONS.md` D-15 / `setup_cube.sh` (git-ignored) | third-party |

## 2026-10-09 — host-link option B (DSN-LINK-01)
- New `Core/Src/host_bridge.c`, `Core/Inc/host_bridge.h` (copies of `engineering/DESIGN/HOST_LINK/stm32/`): SPI1 bridge to the FPGA using the already-routed DIG_5 (PD13 → FPGA_CS_N, reconfigured as output), DIG_6 (PD14 → DRDY, EXTI14 rising), DIG_7 (PD15 spare). `HostBridge_Init()` after `MX_SPI1_Init()` (main.cpp), `HostBridge_Poll()` at the top of the main loop; `EXTI15_10_IRQHandler` added to `stm32f7xx_it.c`; `HAL_GPIO_EXTI_Callback` defined in host_bridge.c (no other user). Frame (≤ 2162 B) is CRC-checked and forwarded unchanged with `CDC_Transmit_FS`. SPI1 stays at the ADAR1000 setting (6.75 MHz, mode 0) → ≈ 2.5 ms per frame; the firmware must not start an ADAR1000 transaction while `HostBridge_Busy()`. Build: 0 errors; RAM 17 296 B, FLASH 91 948 B. Not run on hardware.

## 2026-10-09 — ADAR1000 vector-modulator tables + bridge command set v2

| File (beta) | Change | Category |
|---|---|---|
| `LIB/adar1000_vm_tables.h/.c` (NEW) | 128-entry I/Q phase words parsed mechanically from ADAR1000 data sheet Rev. B, Tables 10-13, pp. 35-36 (`pdftotext -layout`); bit layout per Tables 47/48 (bit 5 polarity, bits 4:0 magnitude); `VM_GAIN` all zero (D-19) | DEFECT (tables were empty) |
| `LIB/ADAR1000_Manager.cpp` orig. 22-33 | empty `VM_I/VM_Q/VM_GAIN` initialisers → `ADAR1000_VM_TABLE_*` macros; `#include "adar1000_vm_tables.h"` | DEFECT |
| `LIB/ADAR1000_Manager.cpp` `adarSetRxPhase/TxPhase/RxVgaGain/TxVgaGain` (orig. ~710-745) | register offset `(channel & 0x03)` → `((channel - 1) & 0x03)`: every caller passes channel 1..4 (`:161-180`, `:524-526`, `main.cpp:1113,1121`), so channel 1 wrote CH2's registers … channel 4 wrapped to CH1 (beam pattern rotated by one element per device) | DEFECT C10 |
| `Core/Inc/host_bridge_proto.h`, `Core/Src/host_bridge_proto.c` (NEW) | HAL-free command set v2 (0x02 write/ack 0xA2, 0x03 read, 0x04 status) + ASCII `REG W/R` parser/executor/reply formatter | NEW (D-17, D-18) |
| `Core/Inc/host_bridge.h`, `Core/Src/host_bridge.c` | `HostBridge_WriteReg/ReadReg/Status/ExecuteTextCommand` over a HAL transport that refuses while `s_busy` (frame read), checks all ADAR CS high, drives `FPGA_CS_N` and sets `s_busy` exactly like the frame read | NEW (D-17) |
| `LIB/USBHandler.h/.cpp` | text-command branch: a CDC packet starting with `REG` is captured (≤64 chars, up to CR/LF/NUL) into a one-slot buffer, except while a synchronised settings packet is being assembled; `hasPendingCommand()/takePendingCommand()`; `reset()` clears it | NEW (D-17) |
| `Core/Src/main.cpp` main loop (after `HostBridge_Poll()`) | executes a pending `REG` command and sends the reply with `CDC_Transmit_FS` (bounded 50 ms busy wait) | NEW (D-17) |
| `CMakeLists.txt` | + `host_bridge_proto.c`, `adar1000_vm_tables.c` | BUILD |
| `tests/test_adar_vm_tables.c`, `tests/test_host_bridge_cmds.c` (NEW), `tests/test_settings_parser.cpp` (+T10), `tests/run_tests.sh` | host tests | NEW |

Build after this change: 0 errors, same 5 pre-existing warnings; RAM 17 480 B (5.33 %), FLASH 93 276 B (8.90 %); text 92 480 / data 788 / bss 16 704.

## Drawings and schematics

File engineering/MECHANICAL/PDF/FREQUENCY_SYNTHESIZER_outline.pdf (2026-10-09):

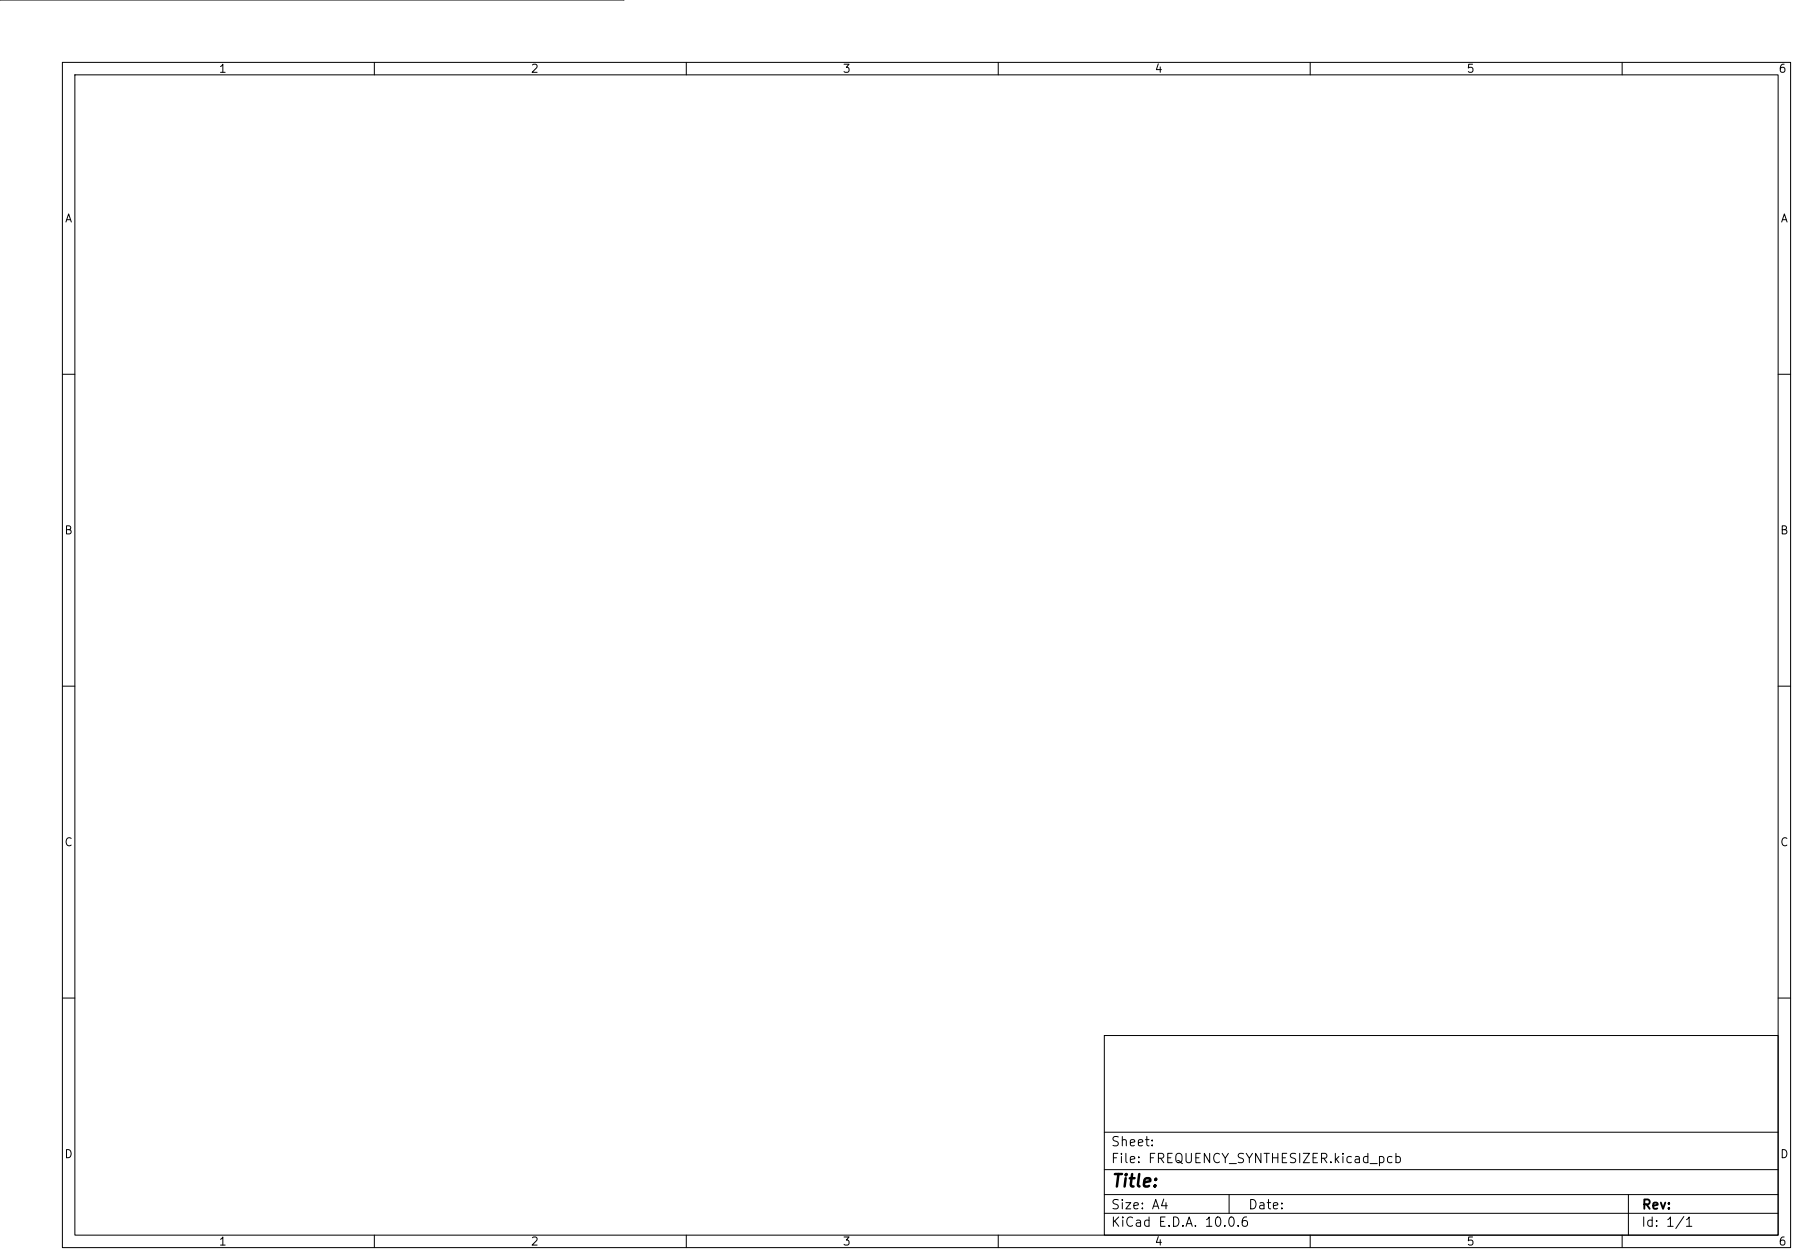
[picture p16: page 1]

Size: A4 | Rev:
KiCad E.D.A. 10.0.6 | Id: 1/1

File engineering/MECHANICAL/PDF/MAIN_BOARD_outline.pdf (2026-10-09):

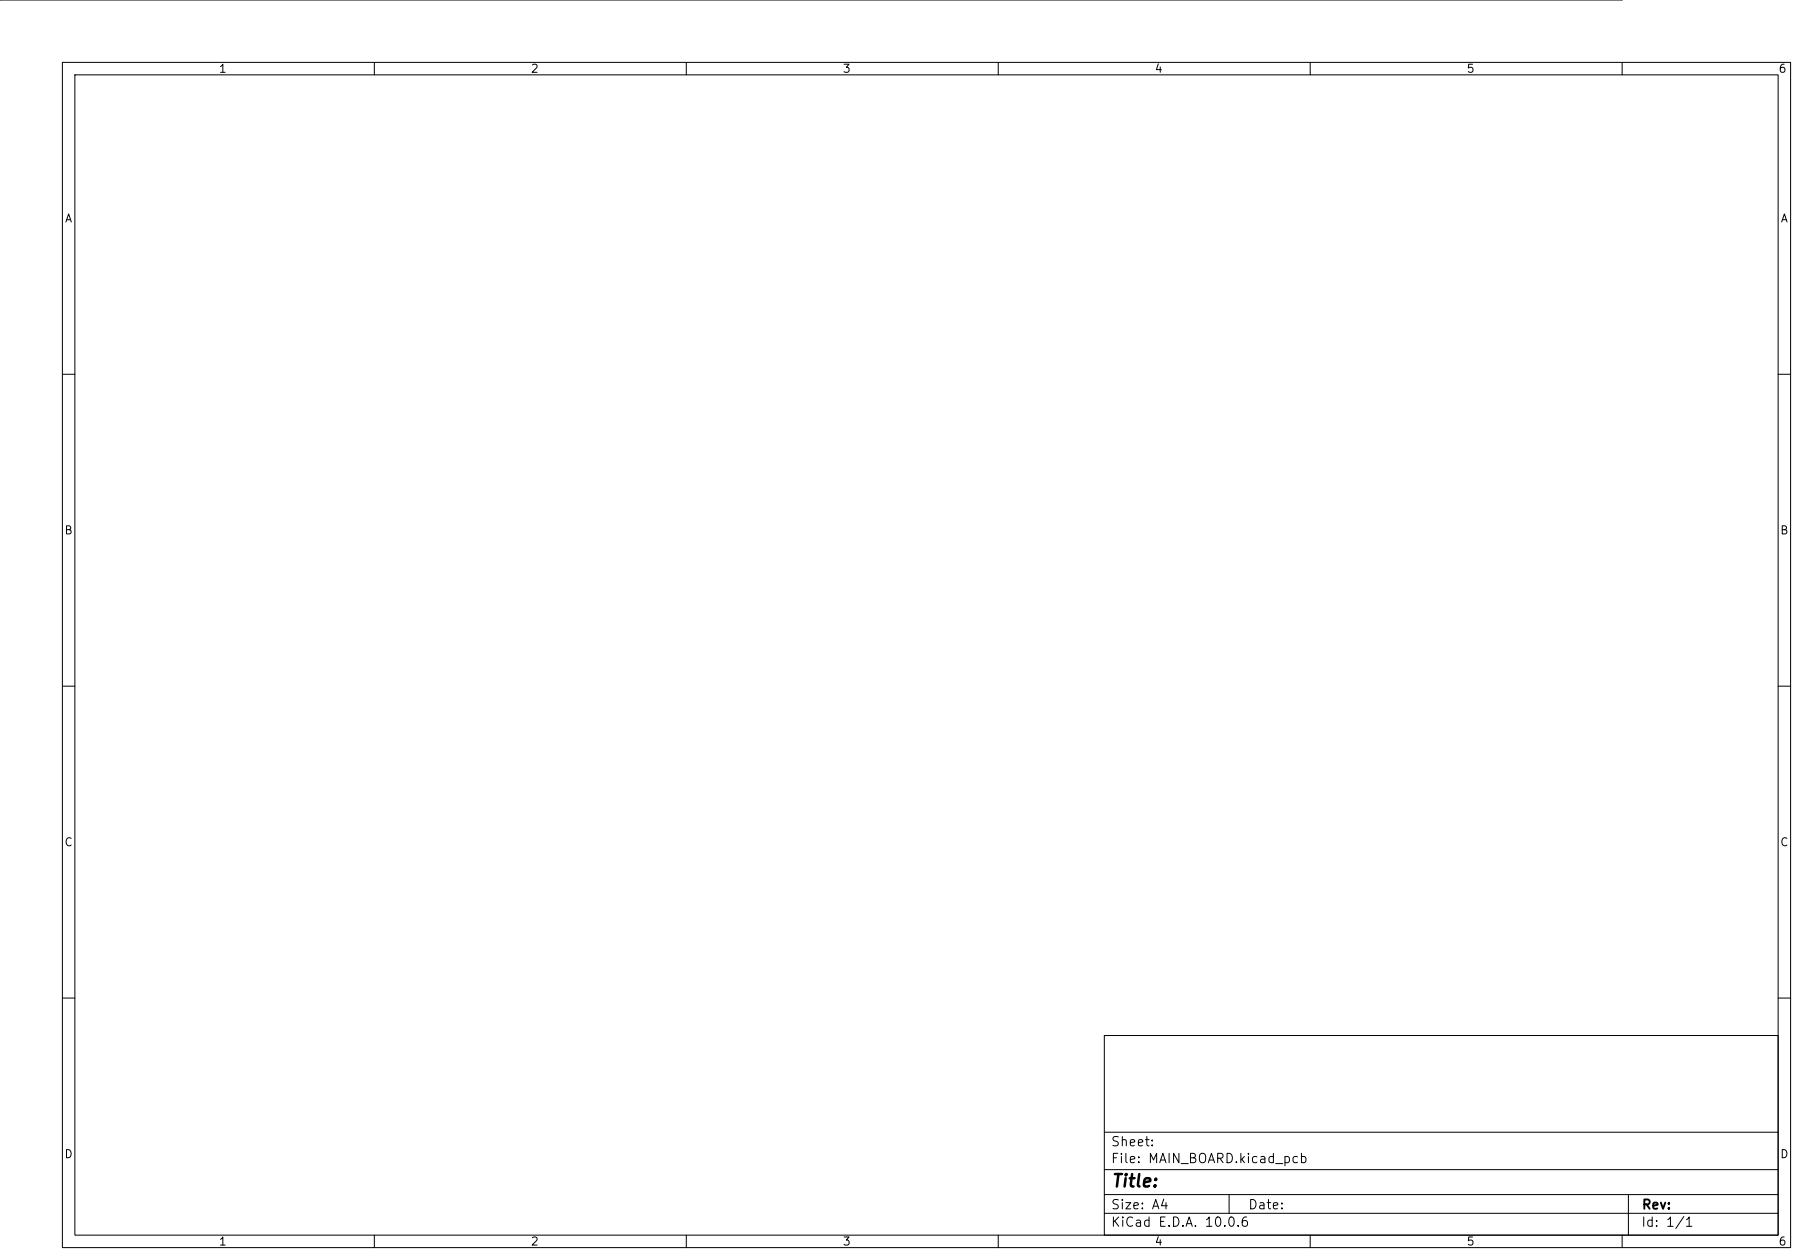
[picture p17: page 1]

Size: A4 | Rev:
KiCad E.D.A. 10.0.6 | Id: 1/1

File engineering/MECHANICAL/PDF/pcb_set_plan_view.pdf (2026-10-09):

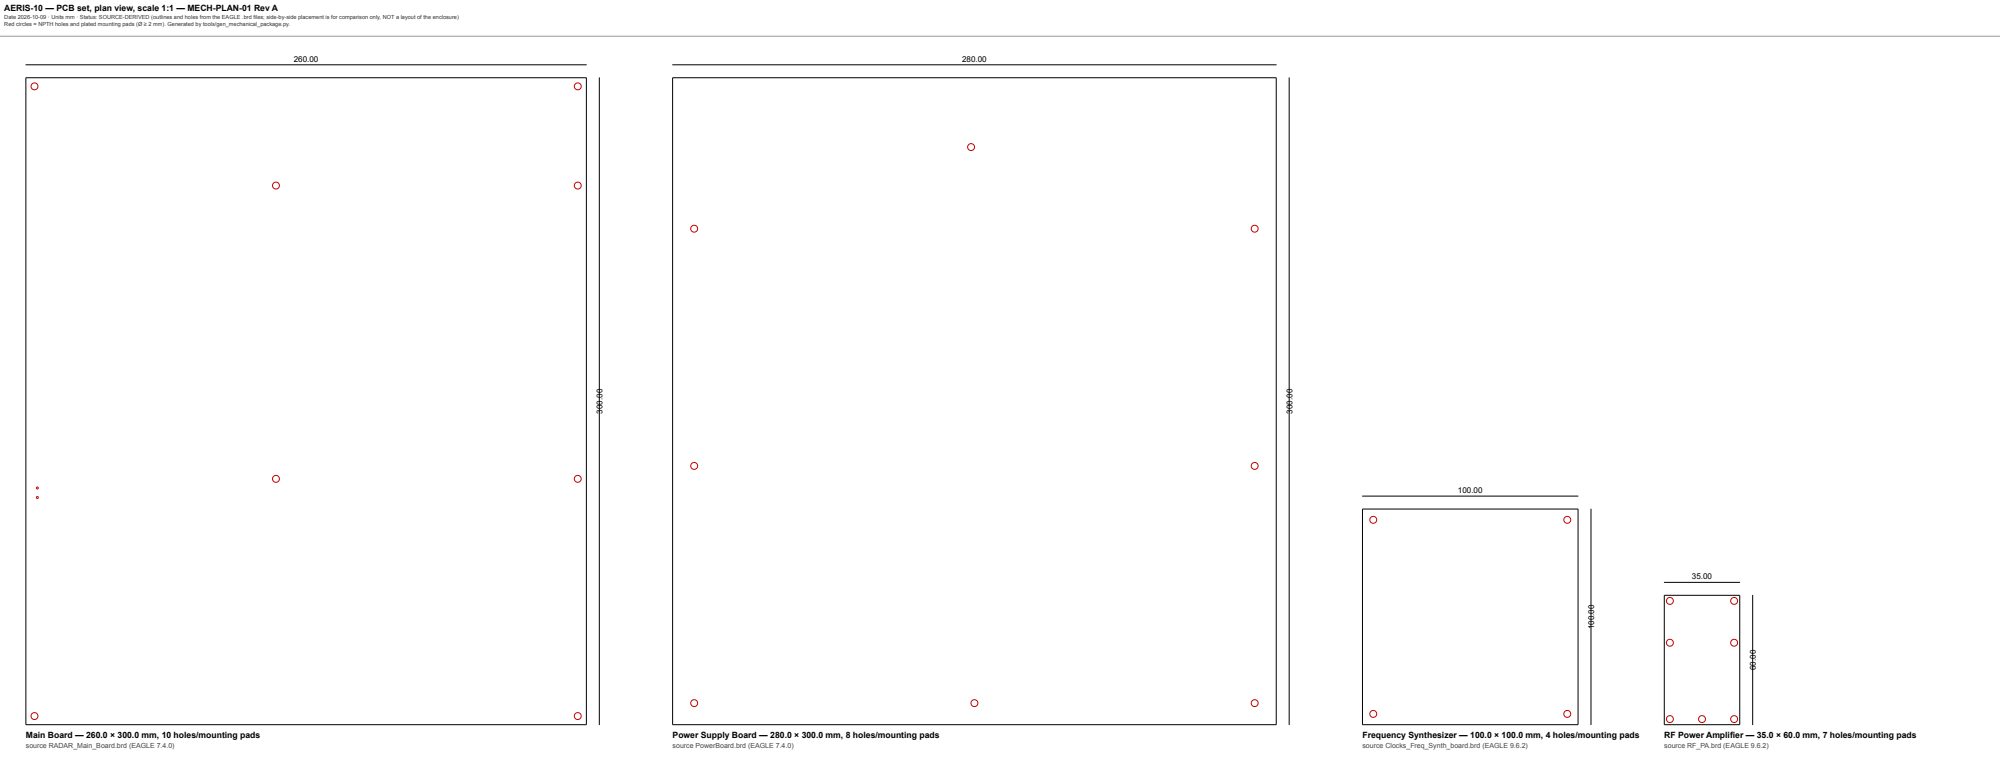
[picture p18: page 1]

AERIS-10 — PCB set, plan view, scale 1:1 — MECH-PLAN-01 Rev A
Date 2026-10-09 · Units mm · Status: SOURCE-DERIVED (outlines and holes from the EAGLE .brd files; side-by-side placement is for comparison only, NOT a layout of the enclosure)
Red circles = NPTH holes and plated mounting pads (Ø ≥ 2 mm). Generated by tools/gen_mechanical_package.py.

Main Board — 260.0 × 300.0 mm, 10 holes/mounting pads
source RADAR_Main_Board.brd (EAGLE 7.4.0)

Power Supply Board — 280.0 × 300.0 mm, 8 holes/mounting pads
source PowerBoard.brd (EAGLE 7.4.0)

Frequency Synthesizer — 100.0 × 100.0 mm, 4 holes/mounting pads
source Clocks_Freq_Synth_board.brd (EAGLE 9.6.2)

RF Power Amplifier — 35.0 × 60.0 mm, 7 holes/mounting pads
source RF_PA.brd (EAGLE 9.6.2)

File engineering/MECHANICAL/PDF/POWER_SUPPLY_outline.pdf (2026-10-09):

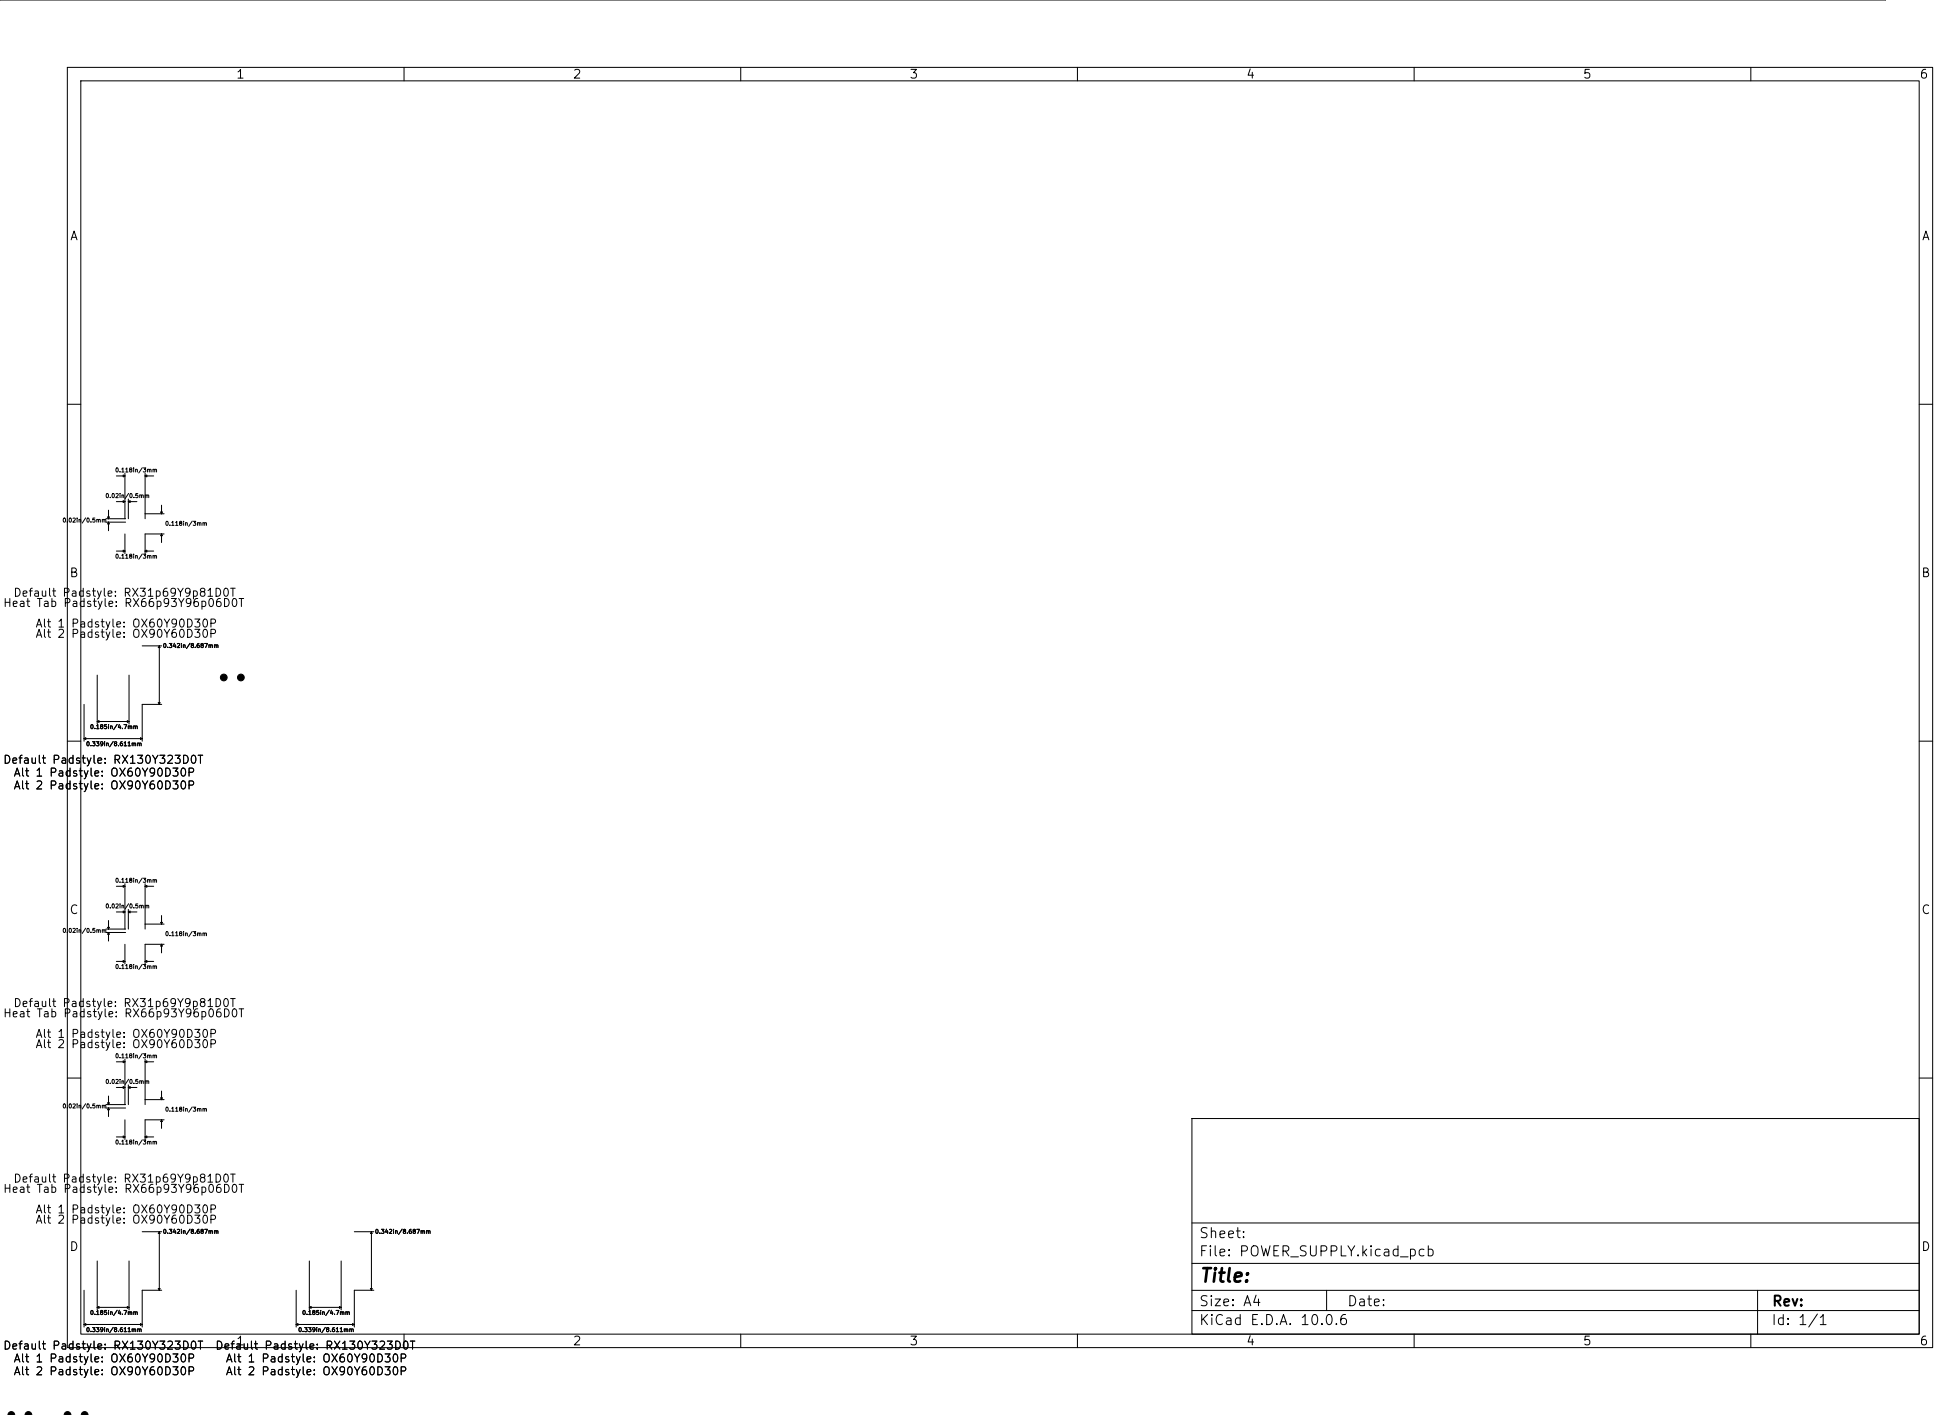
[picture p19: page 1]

0.118in/3mm Default Padstyle: RX130Y323D0T Alt 1 Padstyle: OX60Y90D30P

0.342in/8.687mm Default Padstyle: RX130Y323D0T Alt 1 Padstyle: OX60Y90D30P

Default Padstyle: RX130Y323D0T Alt 1 Padstyle: OX60Y90D30P

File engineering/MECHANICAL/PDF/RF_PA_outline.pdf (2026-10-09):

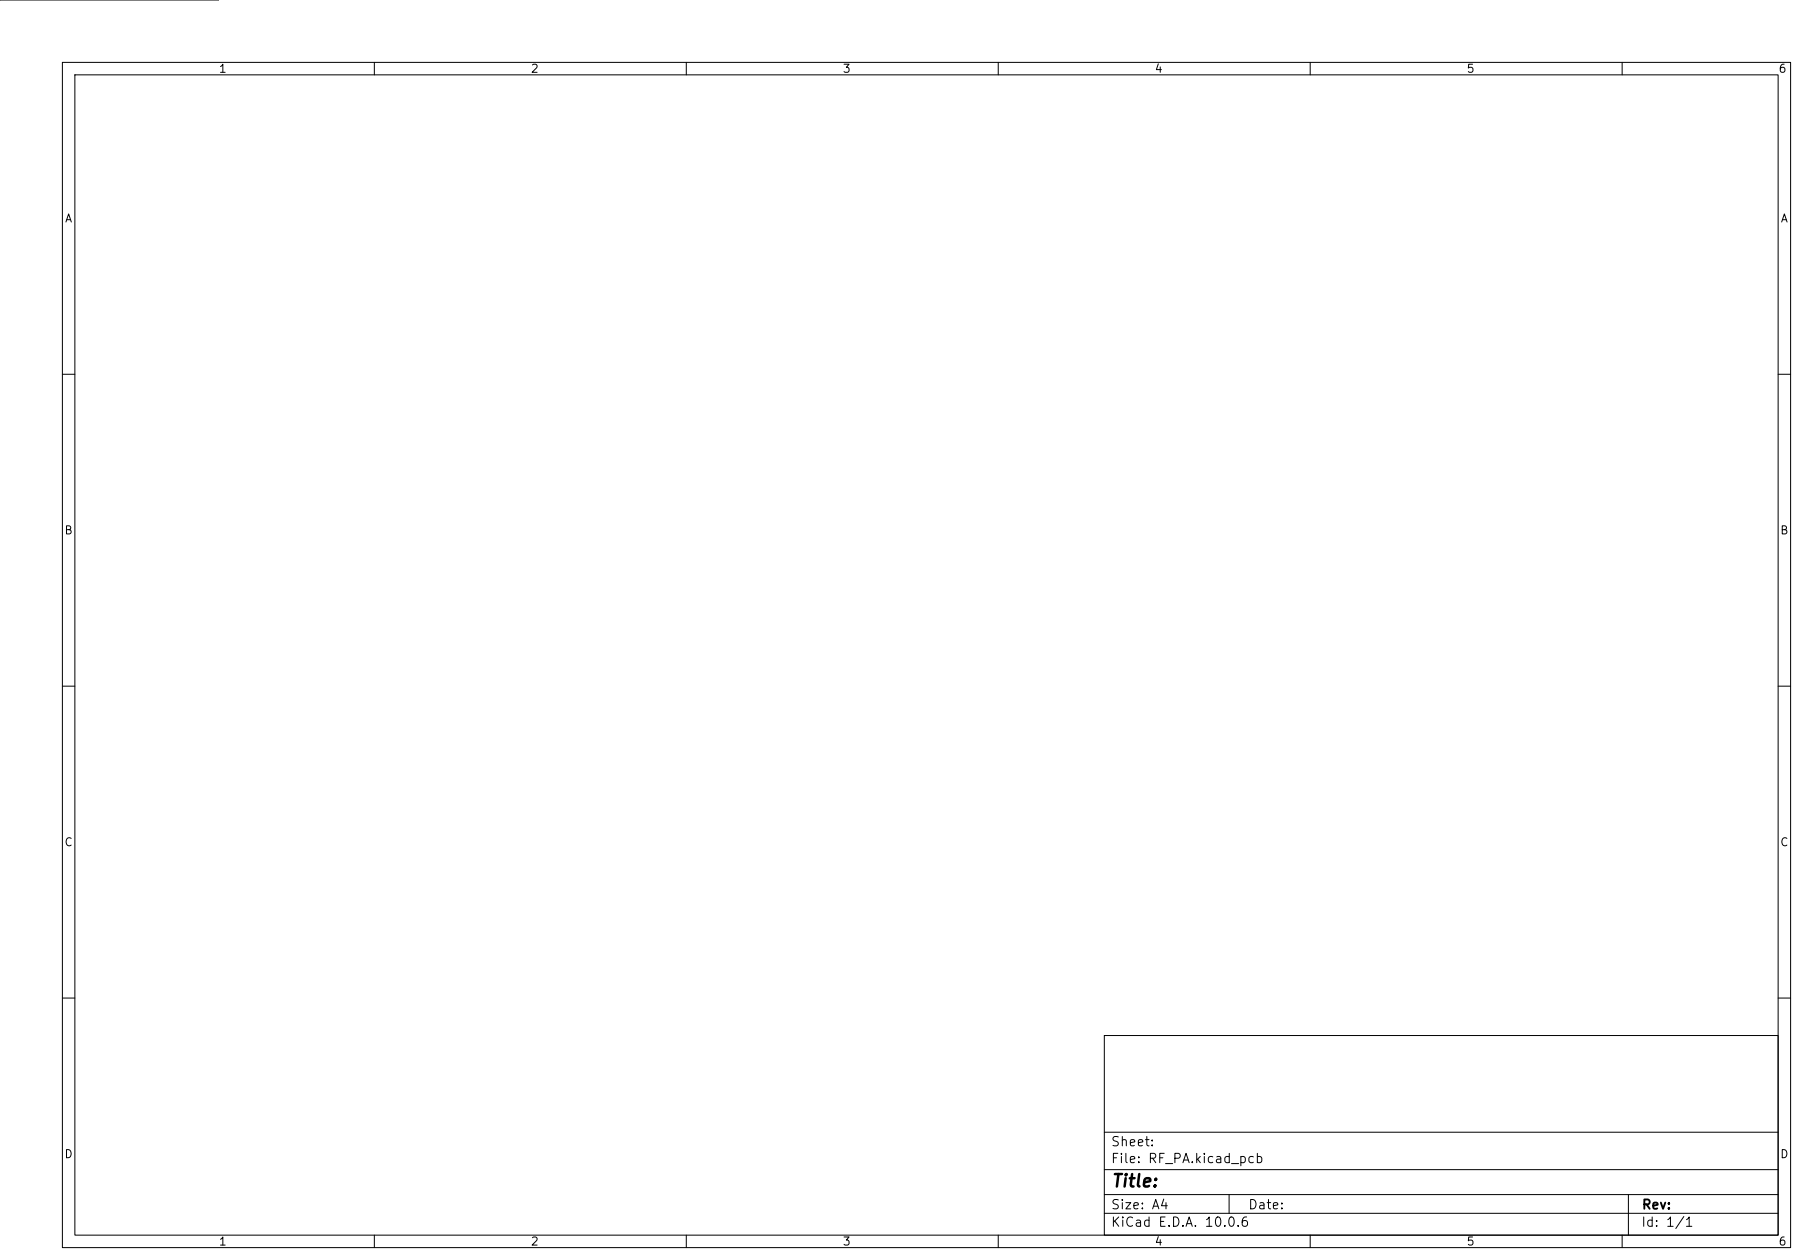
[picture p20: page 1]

Size: A4 | Rev:
KiCad E.D.A. 10.0.6 | Id: 1/1

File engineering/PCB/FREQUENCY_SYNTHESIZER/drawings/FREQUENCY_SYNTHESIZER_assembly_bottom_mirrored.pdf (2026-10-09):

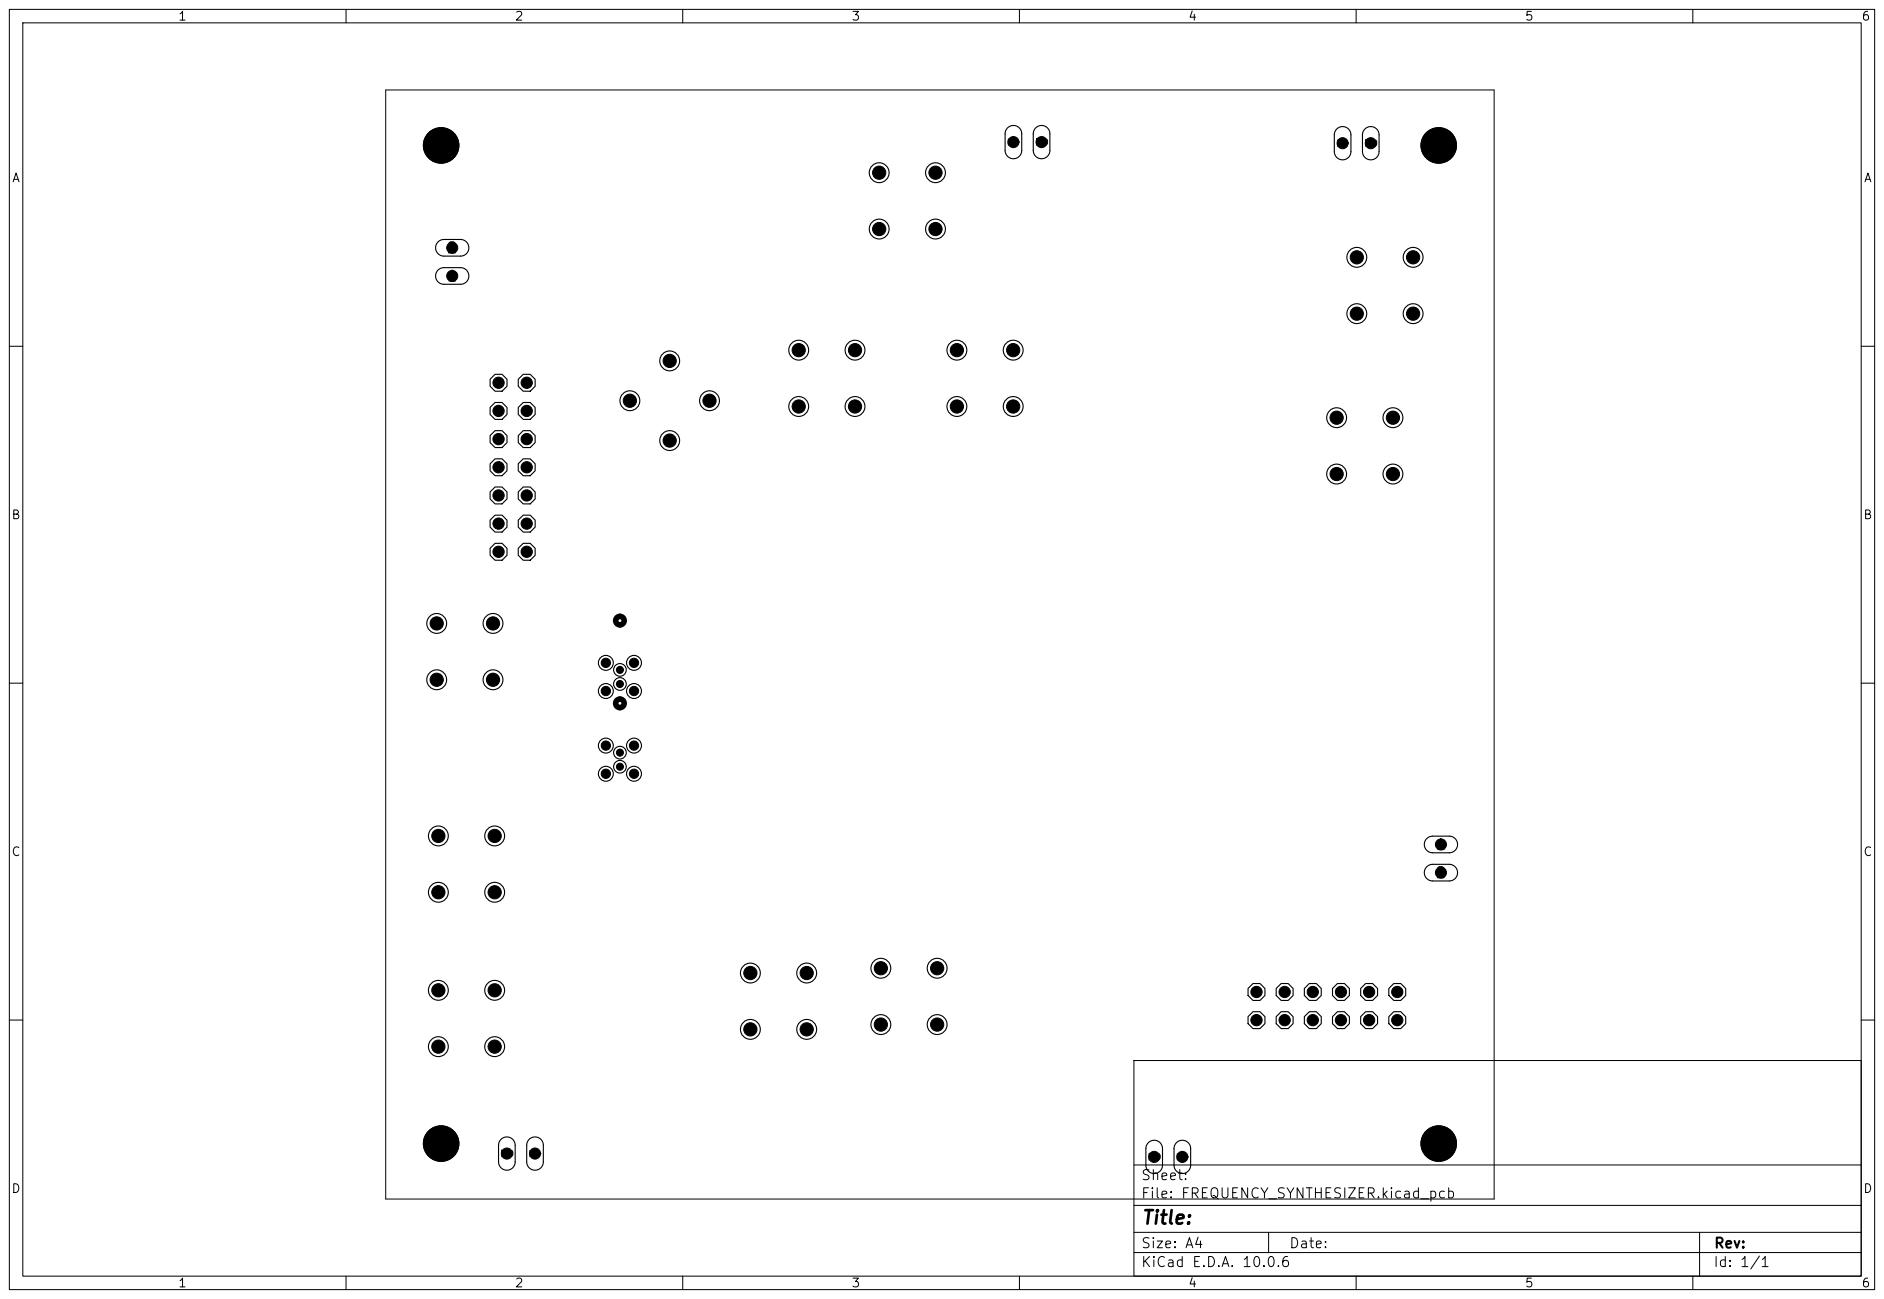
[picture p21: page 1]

Size: A4 | Rev:
KiCad E.D.A. 10.0.6 | Id: 1/1

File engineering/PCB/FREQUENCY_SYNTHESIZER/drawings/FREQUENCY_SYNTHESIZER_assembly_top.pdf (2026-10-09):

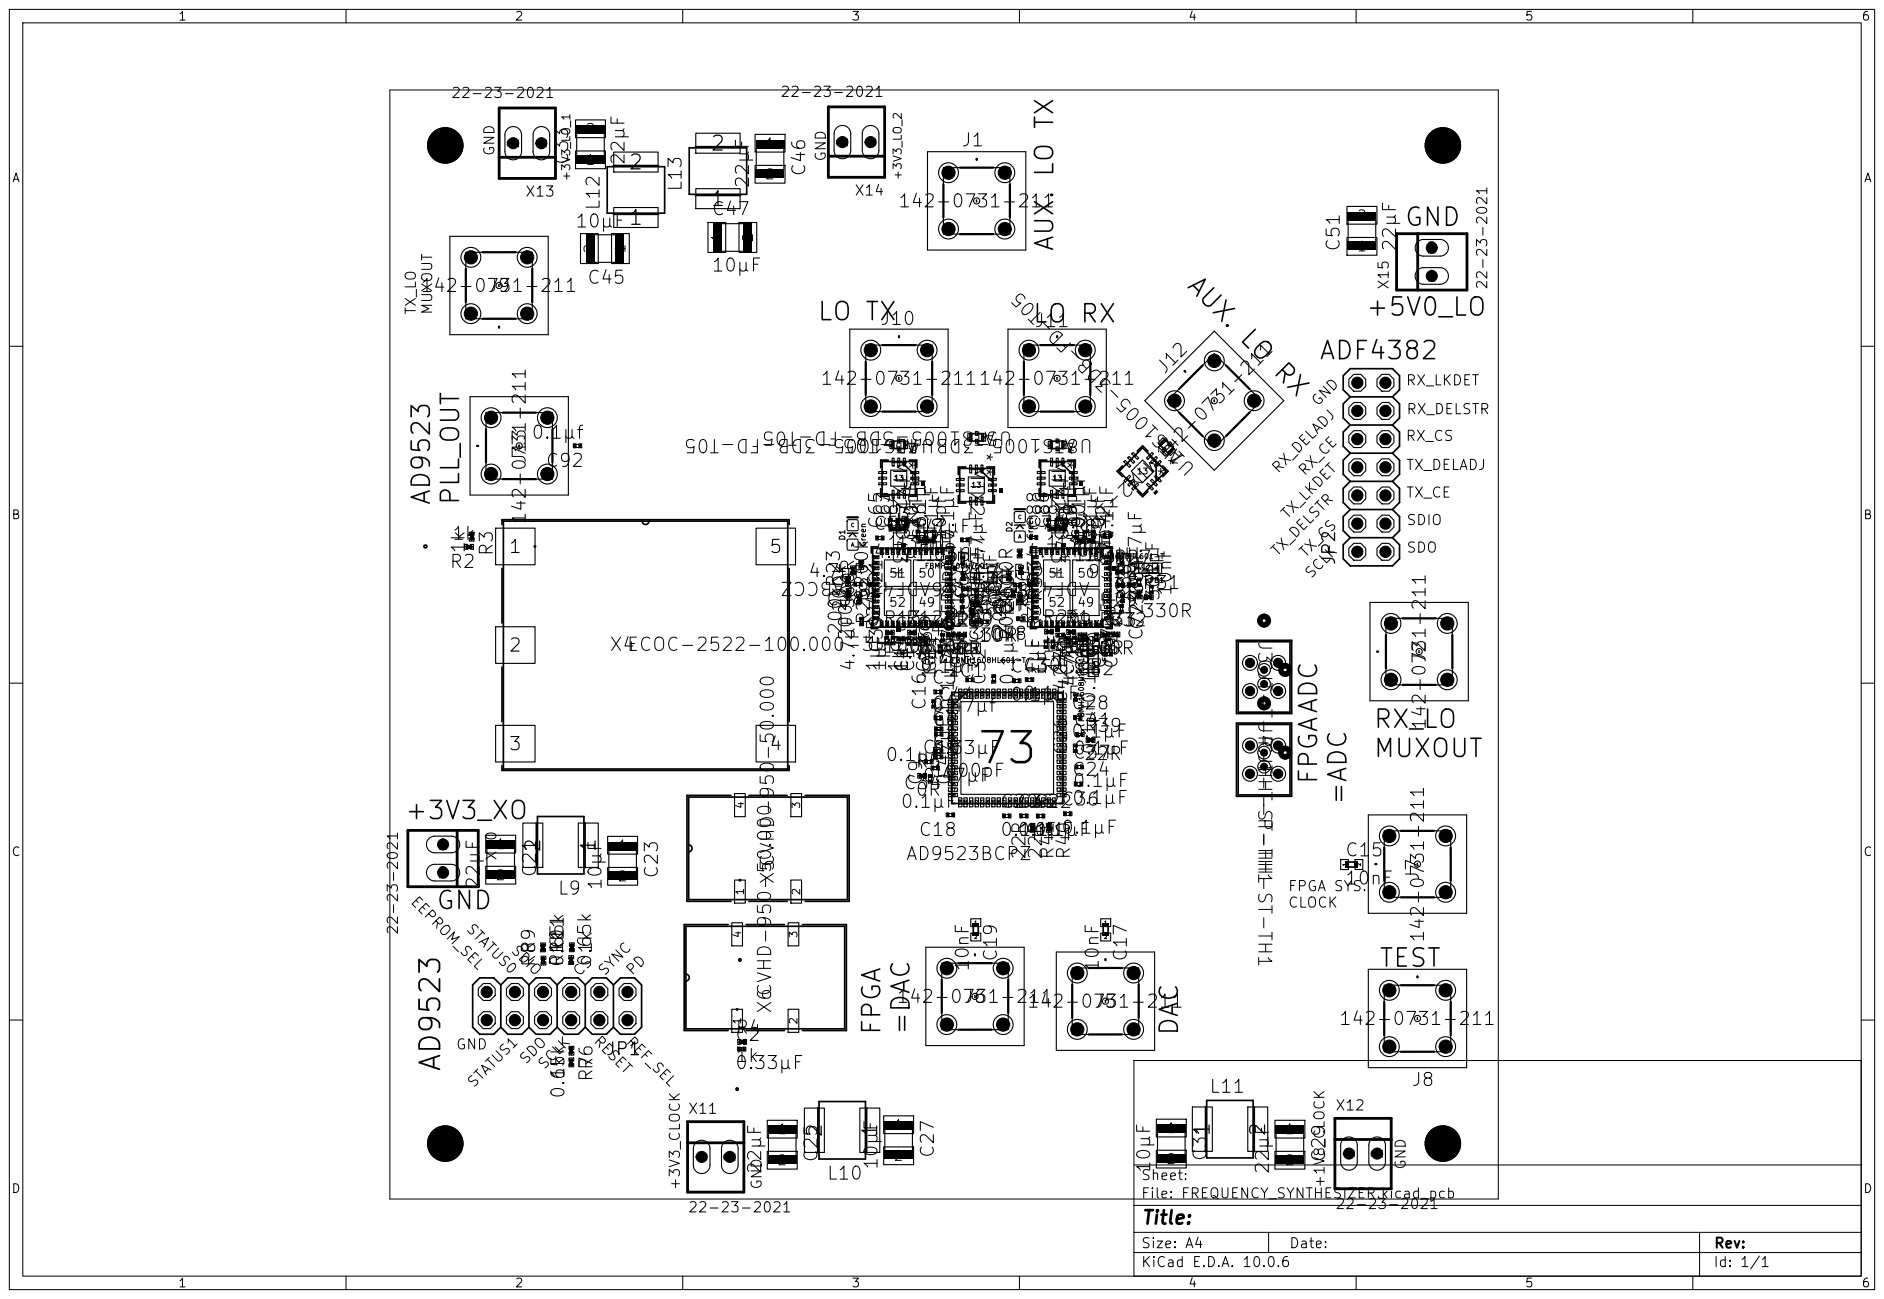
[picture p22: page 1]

Size: A4 | Rev:
KiCad E.D.A. 10.0.6 | Id: 1/1

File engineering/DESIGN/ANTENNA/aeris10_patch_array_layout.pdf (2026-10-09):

AERIS-10 — 16×8 microstrip patch array, top copper, scale 1:1 — DSN-ANT-01 Rev A — STATUS: PROPOSED D

165

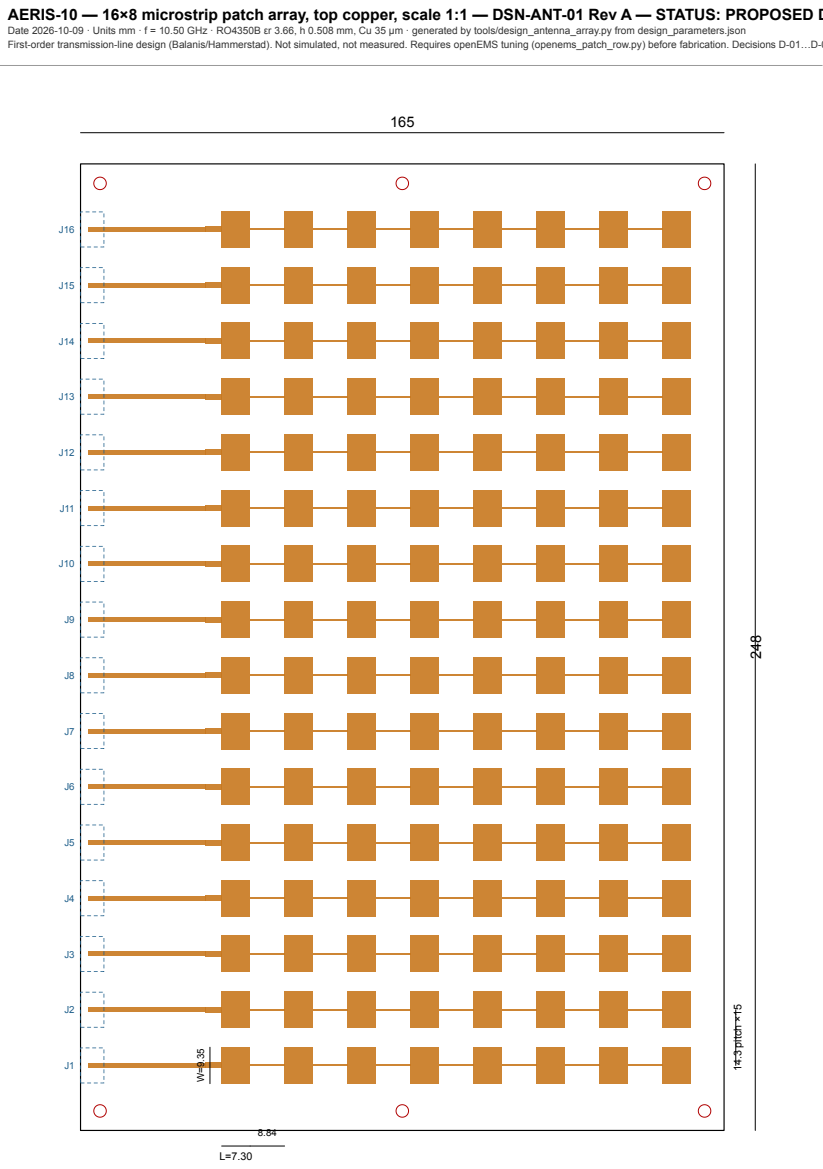
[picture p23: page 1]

Date 2026-10-09 · Units mm · f = 10.50 GHz · RO4350B εr 3.66, h 0.508 mm, Cu 35 µm · generated by tools/design_antenna_array.py from design_parameters.json
First-order transmission-line design (Balanis/Hammerstad). Not simulated, not measured. Requires openEMS tuning (openems_patch_row.py) before fabrication. Decisions D-01…D-0

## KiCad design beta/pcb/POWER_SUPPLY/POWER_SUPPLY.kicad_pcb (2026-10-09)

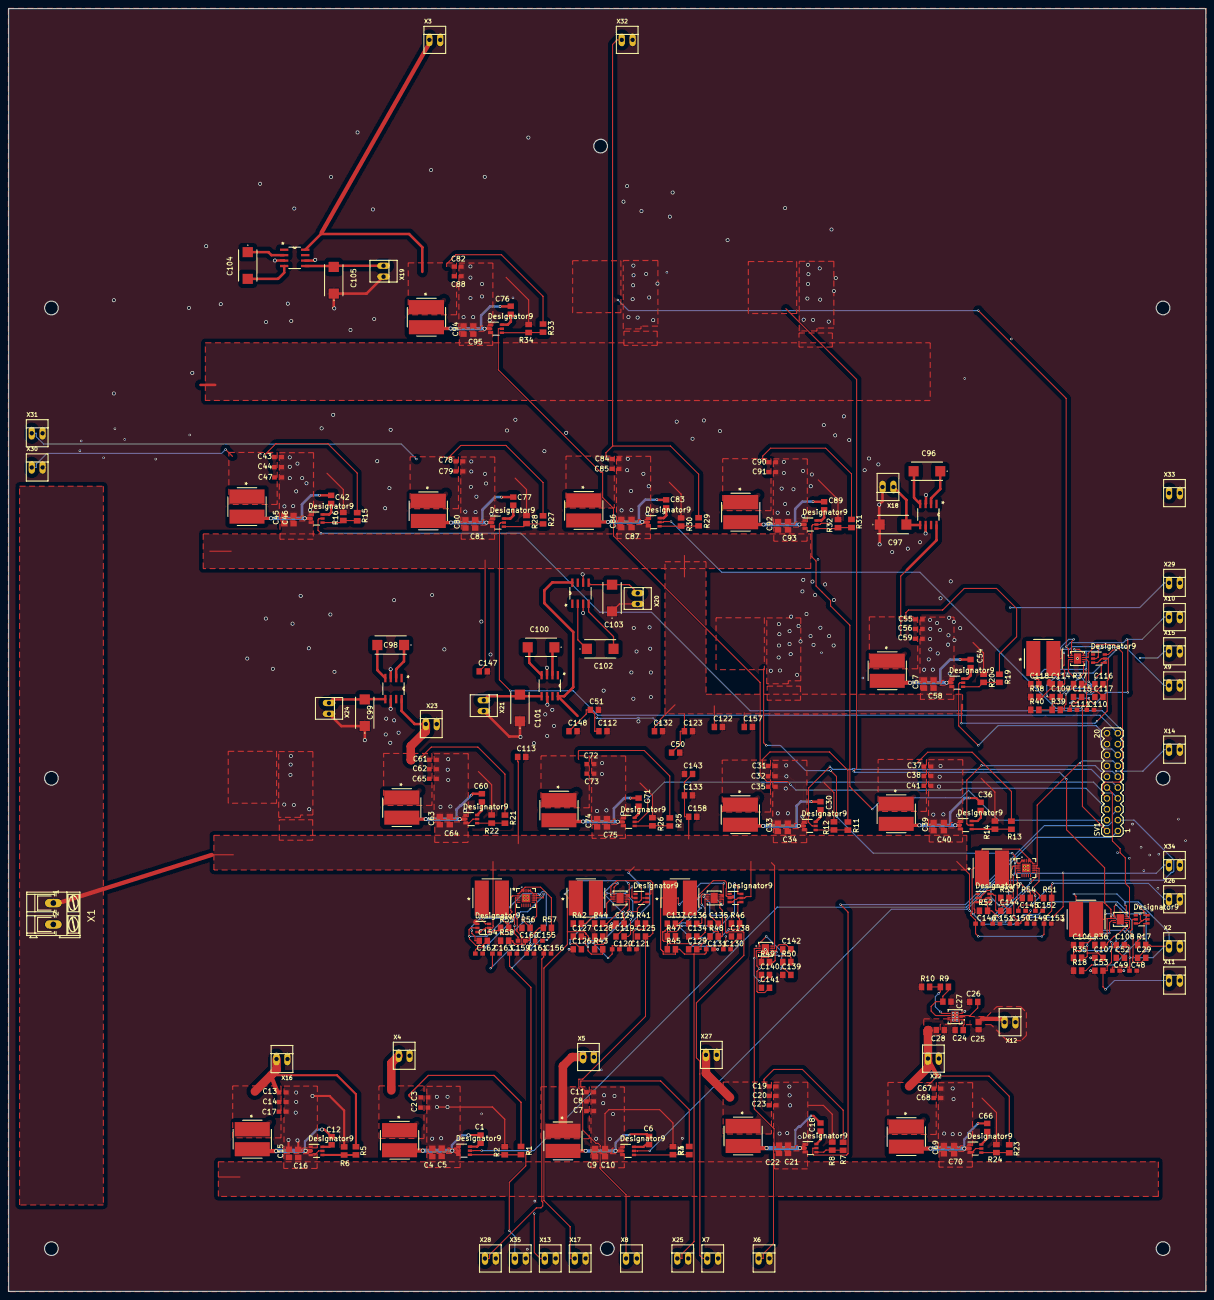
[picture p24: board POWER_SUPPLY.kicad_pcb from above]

Board: 2 copper layers, 280.0 x 300.0 mm, 320 parts (0 on the bottom side), 156 nets.

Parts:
C1, C6, C12, C18, C29, C30, C36, C42, C54, C60, C66, C71, C76, C77, C83, C89, C109, C119, C129, C144, C154: 0.1µF; C0805
C2, C3, C7, C8, C11, C13, C14, C17, C19, C20, C23, C31, C32, C35, C37, C38, C41, C43, C44, C47, C48, C49, C55, C56, C59, C61, C62, C65, C67, C68, C72, C73, C78, C79, C82, C84, C85, C88, C90, C91, C110, C111, C120, C121, C130, C131, C145, C146, C149, C155, C156, C159: 22µF; C0603
C4, C5, C9, C10, C15, C16, C21, C22, C24, C25, C28, C33, C34, C39, C40, C45, C46, C50, C51, C52, C53, C57, C58, C63, C64, C69, C70, C74, C75, C80, C81, C86, C87, C92, C93, C94, C95, C108, C112, C113, C114, C115, C118, C122, C123, C124, C125, C128, C132, C133, C134, C135, C138, C139, C140, C143, C147, C148, C157, C158: 10µF; C0805
C26, C27, C106, C107, C116, C117, C126, C127, C136, C137, C141, C142: 1µF; C0805
C96, C97, C98, C99, C100, C101, C102, C103, C104, C105: T521W476M020ATE045; T521W
C150, C152, C160, C162: 10nF; C0603
C151, C153, C161, C163: 10µF; C0603
R1: 3.09k; M0805
R2, R4, R6, R8, R10, R12, R14, R16, R18, R20, R22, R24, R26, R28, R30, R32, R34, R36, R38, R40, R42, R44, R46, R48, R50, R52, R56: 10k; M0805
R3: 13.7k; M0805
R5, R7, R11, R13, R15, R19: 32.2k; M0805
R9, R35, R43, R47: 12k; M0805
R17, R23, R25, R27, R29, R31, R37, R41, R45, R51, R55: 56.2k; M0805
R21: 34.8k; M0805
R33: 61.9k; M0805
R39: 2k; M0805
R49: 23.4k; M0805
R53, R57: 35.7k; M0805
R54, R58: 11.5k; M0805
SV1: MA10-2
U1, U2, U3, U4, U6, U7, U8, U9, U10, U11, U12, U13, U14, U15, U16, U17, U24, U26, U28, U31, U33: TPS562208DDCT; DDC0006A_N
U5, U23, U25, U27, U29, U30: ADM7151ACPZ-04-R7; CP_8_11_ADI
U18, U19, U20, U21, U22: LM2662MX/NOPB; M08A
U32, U34: TPS7A8300RGRR; RGR20_2P05X2P05_TEX
U$1, U$2: 2.2µH; IND_VLP8040T-1R0N_TDK
U$3, U$4, U$5, U$6, U$7, U$8, U$9, U$10, U$11, U$12, U$13, U$14, U$15, U$16, U$17, U$18, U$19, U$20, U$21: 3.3µH; IND_VLP8040T-1R0N_TDK
UNK_HOLE_0: dummyfp0
UNK_HOLE_1: dummyfp1
UNK_HOLE_2: dummyfp2
UNK_HOLE_3: dummyfp3
UNK_HOLE_4: dummyfp4
UNK_HOLE_5: dummyfp5
UNK_HOLE_6: dummyfp6
UNK_HOLE_7: dummyfp7
X1: AK300_2
X2, X3, X4, X5, X6, X7, X8, X9, X10, X11, X12, X13, X14, X15, X16, X17, X18, X19, X20, X21, X22, X23, X24, X25, X26, X27, X28, X29, X30, X31, X32, X33, X34, X35: 22-23-2021

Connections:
+1V0_FPGA: C2.1, C3.1, R1.2, U$1.1, X4.1
+1V8_CLOCK: C115.2, U25.2, X10.1
+1V8_FPGA: C7.1, C8.1, C11.1, R3.2, U$2.1, X5.1
+3V3: C13.1, C14.1, C17.1, R5.2, U$3.1, X16.1
+3V3_ADAR_12: C31.1, C32.1, C35.1, R11.2, U$6.1, X14.1
+3V3_ADAR_34: C37.1, C38.1, C41.1, R13.2, U$7.1, X15.1
+3V3_ADTR: C149.1, R53.2, U32.1, U32.19, U32.20, X34.1
+3V3_AN: C25.2, U5.2, X12.1
+3V3_CLOCK: C53.2, U23.2, X11.1
+3V3_FPGA: C19.1, C20.1, C23.1, R7.2, U$4.1, X27.1
+3V3_LO_1: C125.2, U27.2, X8.1
+3V3_LO_2: C135.2, U29.2, X7.1
+3V3_SW: C55.1, C56.1, C59.1, R19.2, U18.8, U$10.1, X29.1
+3V3_VDD_SW: C43.1, C44.1, C47.1, R15.2, U$8.1, X30.1
+3V3_XO: C159.1, R57.2, U34.1, U34.19, U34.20, X35.1
+3V4: C61.1, C62.1, C65.1, R21.2, U19.8, U$11.1, X23.1
+5V0_0: C28.2, C67.1, C68.1, R23.2, U5.7, U5.8, U$12.1, X22.1
+5V0_1: C48.1, C49.1, C108.2, R17.2, U23.8, U$5.1, X2.1
+5V0_2: C110.1, C111.1, C118.2, R37.2, U25.8, U$9.1, X9.1
+5V0_3: C120.1, C121.1, C128.2, R41.2, U27.7, U27.8, U$18.1, X17.1
+5V0_4: C130.1, C131.1, C138.2, R45.2, U29.7, U29.8, U$19.1, X25.1
+5V0_5: C155.1, C156.1, C163.1, R55.2, U34.14, U34.15, U34.16, U34.17, U$21.1, X28.1
+5V0_ADAR: C72.1, C73.1, R25.2, U20.8, U21.8, U$13.1, X13.1
+5V0_ADTR: C145.1, C146.1, C153.1, R51.2, U32.15, U32.16, U32.17, U$20.1, X26.1
+5V0_LO: C140.2, U30.2, X6.1
+5V0_PA_1: C78.1, C79.1, R27.2, U$14.1, X31.1
+5V0_PA_2: C84.1, C85.1, R29.2, U$15.1, X32.1
+5V0_PA_3: C90.1, C91.1, R31.2, U$16.1, X33.1
+5V5_PA: C82.1, C88.1, R33.2, U22.8, U$17.1, X3.1
-3V3_SW: C97.2, U18.5, X18.1
-3V4: C99.2, U19.5, X24.1
-5V0_ADAR12: C101.2, U20.5, X21.1
-5V0_ADAR34: C103.2, U21.5, X20.1
-5V5_PA: C105.2, U22.5, X19.1
EN_+1V0_FPGA: SV1.1, U1.5
EN_+1V8_CLOCK: SV1.8, U25.7
EN_+1V8_FPGA: SV1.3, U2.5
EN_+3V3_ADAR12: SV1.9, U6.5
EN_+3V3_ADAR34: SV1.11, U7.5
EN_+3V3_ADTR: SV1.13, U32.14
EN_+3V3_CLOCK: SV1.10, U23.7
EN_+3V3_FPGA: SV1.5, U4.5
EN_+3V3_SW: SV1.15, U10.5
EN_+3V3_VDD_SW: SV1.17, U8.5
EN_+5V0_ADAR: SV1.7, U13.5
EN_+5V0_PA1: SV1.19, U14.5
EN_+5V0_PA2: SV1.2, U15.5
EN_+5V0_PA3: SV1.4, U16.5
EN_+5V5_PA: SV1.6, U17.5
GND: C2.2, C3.2, C4.2, C5.2, C7.2, C8.2, C9.2, C10.2, C11.2, C13.2, C14.2, C15.2, C16.2, C17.2, C19.2, C20.2, C21.2, C22.2, C23.2, C24.1, C25.1, C26.1, C27.1, C28.1, C31.2, C32.2, C33.2, C34.2, C35.2, C37.2, C38.2, C39.2, C40.2, C41.2, C43.2, C44.2, C45.2, C46.2, C47.2, C48.2, C49.2, C50.2, C51.2, C52.1, C53.1, C55.2, C56.2, C57.2, C58.2, C59.2, C61.2, C62.2, C63.2, C64.2, C65.2, C67.2, C68.2, C69.2, C70.2, C72.2, C73.2, C74.2, C75.2, C78.2, C79.2, C80.2, C81.2, C82.2, C84.2, C85.2, C86.2, C87.2, C88.2, C90.2, C91.2, C92.2, C93.2, C94.2, C95.2, C97.1, C99.1, C101.1, C103.1, C105.1, C106.1, C107.1, C108.1, C110.2, C111.2, C112.2, C113.2, C114.1, C115.1, C116.1, C117.1, C118.1, C120.2, C121.2, C122.2, C123.2, C124.1, C125.1, C126.1, C127.1, C128.1, C130.2, C131.2, C132.2, C133.2, C134.1, C135.1, C136.1, C137.1, C138.1, C139.1, C140.1, C141.1, C142.1, C143.1, C145.2, C146.2, C147.2, C148.2, C149.2, C151.2, C152.2, C153.2, C155.2, C156.2, C157.2, C158.2, C159.2, C161.2, C162.2, C163.2, R2.1, R4.1, R6.1, R8.1, R10.1, R12.1, R14.1, R16.1, R18.1, R20.1, R22.1, R24.1, R26.1, R28.1, R30.1, R32.1, R34.1, R36.1, R38.1, R40.1, R42.1, R44.1, R46.1, R48.1, R50.1, R52.1, R54.1, R56.1, R58.1, SV1.12, SV1.14, SV1.16, SV1.18, SV1.20, U1.1, U2.1, U3.1, U4.1, U5.4, U5.9, U6.1, U7.1, U8.1, U9.1, U10.1, U11.1, U12.1, U13.1, U14.1, U15.1, U16.1, U17.1, U18.3, U18.6, U19.3, U19.6, U20.3, U20.6, U21.3, U21.6, U22.3, U22.6, U23.4, U23.9, U24.1, U25.4, U25.9, U26.1, U27.4, U27.9, U28.1, U29.4, U29.9, U30.4, U30.9, U31.1, U32.8, U32.18, U32.21, U33.1, U34.8, U34.18, U34.21, X1.2, X2.2, X3.2, X4.2, X5.2, X6.2, X7.2, X8.2, X9.2, X10.2, X11.2, X12.2, X13.2, X14.2, X15.2, X16.2, X17.2, X18.2, X19.2, X20.2, X21.2, X22.2, X23.2, X24.2, X25.2, X26.2, X27.2, X28.2, X29.2, X30.2, X31.2, X32.2, X33.2, X34.2, X35.2
unnamed: C1.2, U1.2, U$1.2
unnamed: C1.1, U1.6
unnamed: C6.2, U2.2, U$2.2
unnamed: R1.1, R2.2, U1.4
unnamed: C6.1, U2.6
unnamed: R3.1, R4.2, U2.4
unnamed: C12.2, U3.2, U$3.2
unnamed: C12.1, U3.6
unnamed: R5.1, R6.2, U3.4
unnamed: C18.2, U4.2, U$4.2
unnamed: C18.1, U4.6
unnamed: R7.1, R8.2, U4.4
unnamed: C24.2, U5.1
unnamed: C139.2, U30.1
unnamed: C26.2, U5.3
unnamed: C30.2, U6.2, U$6.2
unnamed: C30.1, U6.6
unnamed: R11.1, R12.2, U6.4
unnamed: C36.2, U7.2, U$7.2
unnamed: C36.1, U7.6
unnamed: R13.1, R14.2, U7.4
unnamed: C42.2, U8.2, U$8.2
unnamed: C42.1, U8.6
unnamed: R15.1, R16.2, U8.4
unnamed: R9.1, R10.2, U5.5
unnamed: C29.2, U9.2, U$5.2
unnamed: C27.2, R9.2, U5.6
unnamed: C54.2, U10.2, U$10.2
unnamed: C54.1, U10.6
unnamed: R19.1, R20.2, U10.4
unnamed: C60.2, U11.2, U$11.2
unnamed: C60.1, U11.6
unnamed: R21.1, R22.2, U11.4
unnamed: C66.2, U12.2, U$12.2
unnamed: C66.1, U12.6
unnamed: R23.1, R24.2, U12.4
unnamed: C71.2, U13.2, U$13.2
unnamed: C71.1, U13.6
unnamed: R25.1, R26.2, U13.4
unnamed: C77.2, U14.2, U$14.2
unnamed: C77.1, U14.6
unnamed: R27.1, R28.2, U14.4
unnamed: C83.2, U15.2, U$15.2
unnamed: C83.1, U15.6
unnamed: R29.1, R30.2, U15.4
unnamed: C89.2, U16.2, U$16.2
unnamed: C89.1, U16.6
unnamed: R31.1, R32.2, U16.4
unnamed: C76.2, U17.2, U$17.2
unnamed: C76.1, U17.6
unnamed: R33.1, R34.2, U17.4
unnamed: C98.1, U19.2
unnamed: C98.2, U19.4
unnamed: C96.1, U18.2
unnamed: C96.2, U18.4
unnamed: C100.1, U20.2
unnamed: C100.2, U20.4
unnamed: C102.1, U21.2
unnamed: C102.2, U21.4
unnamed: C104.1, U22.2
unnamed: C104.2, U22.4
unnamed: C141.2, U30.3
unnamed: R49.1, R50.2, U30.5
unnamed: C29.1, U9.6
unnamed: R17.1, R18.2, U9.4
unnamed: C52.2, U23.1
unnamed: C142.2, R49.2, U30.6
unnamed: C106.2, U23.3
unnamed: R35.1, R36.2, U23.5
unnamed: C107.2, R35.2, U23.6
unnamed: C144.2, U31.2, U$20.2
unnamed: C144.1, U31.6
unnamed: C109.2, U24.2, U$9.2
unnamed: C109.1, U24.6
unnamed: R37.1, R38.2, U24.4
unnamed: C114.2, U25.1
unnamed: R51.1, R52.2, U31.4
unnamed: C116.2, U25.3
unnamed: R39.1, R40.2, U25.5
unnamed: C117.2, R39.2, U25.6
unnamed: C154.2, U33.2, U$21.2
unnamed: C150.1, U32.2
unnamed: C119.2, U26.2, U$18.2
unnamed: C119.1, U26.6
unnamed: R41.1, R42.2, U26.4
unnamed: C124.2, U27.1
unnamed: C154.1, U33.6
unnamed: C126.2, U27.3
unnamed: R43.1, R44.2, U27.5
unnamed: C127.2, R43.2, U27.6
unnamed: C150.2, R53.1, R54.2, U32.3
unnamed: C151.1, U32.12
unnamed: C129.2, U28.2, U$19.2
unnamed: C129.1, U28.6
unnamed: R45.1, R46.2, U28.4
unnamed: C134.2, U29.1
unnamed: R55.1, R56.2, U33.4
unnamed: C136.2, U29.3
unnamed: R47.1, R48.2, U29.5
unnamed: C137.2, R47.2, U29.6
unnamed: C152.1, U32.13
unnamed: C160.1, U34.2
unnamed: C160.2, R57.1, R58.2, U34.3
unnamed: C161.1, U34.12
unnamed: C162.1, U34.13
VIN: C4.1, C5.1, C9.1, C10.1, C15.1, C16.1, C21.1, C22.1, C33.1, C34.1, C39.1, C40.1, C45.1, C46.1, C50.1, C51.1, C57.1, C58.1, C63.1, C64.1, C69.1, C70.1, C74.1, C75.1, C80.1, C81.1, C86.1, C87.1, C92.1, C93.1, C94.1, C95.1, C112.1, C113.1, C122.1, C123.1, C132.1, C133.1, C143.2, C147.1, C148.1, C157.1, C158.1, U1.3, U2.3, U3.3, U3.5, U4.3, U6.3, U7.3, U8.3, U9.3, U9.5, U10.3, U11.3, U11.5, U12.3, U12.5, U13.3, U14.3, U15.3, U16.3, U17.3, U24.3, U24.5, U26.3, U26.5, U28.3, U28.5, U30.7, U30.8, U31.3, U31.5, U33.3, U33.5, X1.1

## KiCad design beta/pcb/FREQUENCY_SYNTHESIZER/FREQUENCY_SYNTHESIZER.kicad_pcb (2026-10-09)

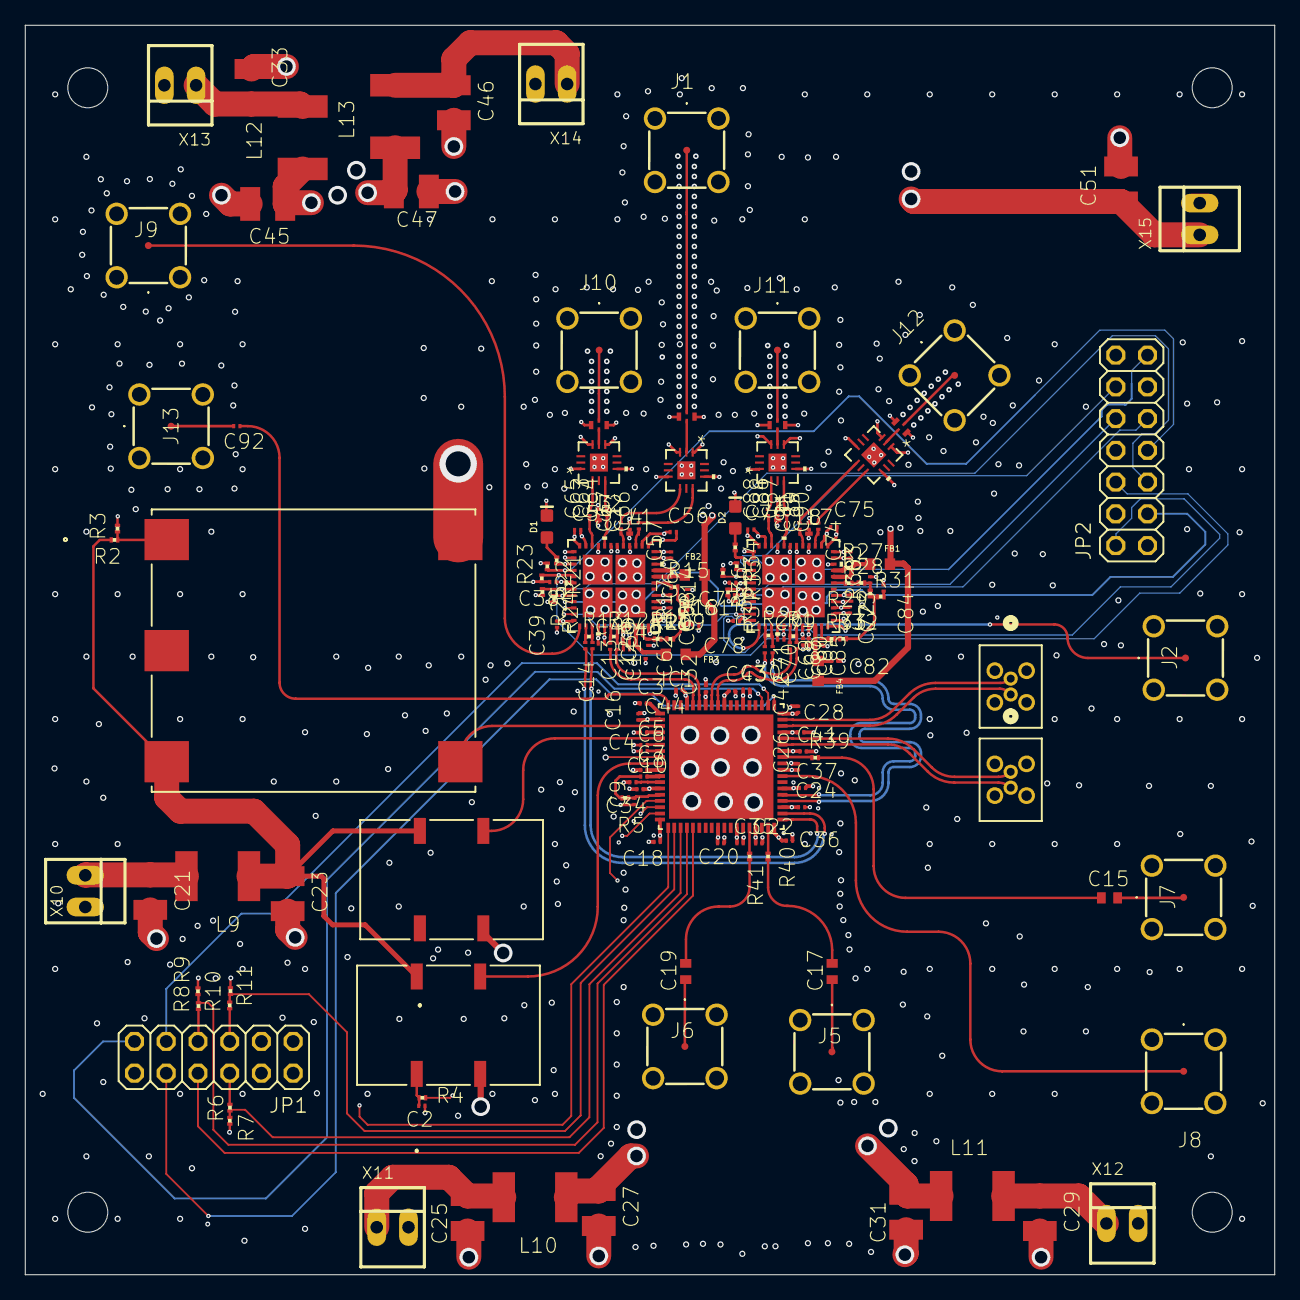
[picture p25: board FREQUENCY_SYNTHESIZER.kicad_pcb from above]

Board: 6 copper layers, 100.0 x 100.0 mm, 188 parts (0 on the bottom side), 134 nets.

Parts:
C1, C62, C63, C85, C86, C89: 10pF; C0201
C2, C6: 0.33µF; C0201
C3: 0.47µf; C0201
C4, C5, C7: C0201
C8: 1000pF; C0201
C9, C10: 0.47µF; C0201
C11, C12, C13, C14, C59, C68, C69, C70, C71, C82: 1µF; C0201
C15, C17, C19: 10nF; C0402
C16, C18, C20, C22, C24, C26, C28, C30, C32, C34, C35, C36, C37, C41, C42, C43, C44, C64, C65, C66, C67, C87, C88, C90, C91: 0.1µF; C0201
C21, C25, C29, C33, C46, C51: 22µF; C1210
C23, C27, C31, C45, C47: 10µF; C1210
C38, C39, C40, C48, C49, C50, C55, C56, C57, C58, C72, C73, C74, C75, C76, C77, C78, C79, C80, C81: 4.7µF; C0201
C60, C83: 31pF; C0201
C61, C84: 10nF; C0201
C92: 0.1µf; C0201
D1, D2: Green; LED-0603
FB1, FB2, FB3, FB4: FBMH1608HL601-T; BEADC1608X90N
IC1: AD9523BCPZ; QFN50P1000X1000X100-73N
J1, J2, J5, J6, J7, J8, J9, J10, J11, J12, J13: 142-0731-211; 1420731211
J3, J4: CJT-T-P-HH-ST-TH1; CONN_CJT-T-P-XX-ST-TH1_SAI
JP1: 2X06
JP2: 2X07
L1, L2, L3, L4, L5, L6, L7, L8: 1.3nH; L0201
L9, L10, L11, L12, L13: L5650M
R1, R12, R13, R26: 100R; R0201
R2, R3, R4, R7, R9, R11: 1k; R0201
R5, R14, R15, R19, R20, R27, R28, R32, R33: 0R; R0201
R6, R8, R10: 0.65k; R0201
R16, R29: 931R; R0201
R17, R30: 30R; R0201
R18, R31: 330R; R0201
R21, R34: 500R; R0201
R22, R23, R24, R25, R35, R36, R37, R38: 200k; R0201
R39, R40, R41: 22R; R0201
U1, U6: ADF4382ABCCZ; CC-48-10_ADI
U2, U3, U7, U9: MTX2-143+; DQ1225_MNC
U4, U5, U8, U10: ATS1005-3DB-FD-T05; SMT_DB-FD-T05_SUS
UNK_HOLE_0: dummyfp0
UNK_HOLE_1: dummyfp1
UNK_HOLE_2: dummyfp2
UNK_HOLE_3: dummyfp3
X4: ECOC-2522-100.000-3HC; SMD5_ECOC-2522_25P4X22_ECS
X5, X6: CVHD-950-50.000; SMD4_CVHD-950_CRX
X10, X11, X12, X13, X14, X15: 22-23-2021

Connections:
10MHZ_OUT: IC1.3, X4.4
100MHZ_OUT: IC1.5, X5.3
+1V8_CLOCK: C31.1, C35.1, C36.1, C37.1, C41.1, C42.1, C43.1, C44.1, IC1.30, IC1.36, IC1.42, IC1.48, IC1.54, IC1.63, IC1.69, L11.1
+3V3_CLOCK: C16.1, C18.1, C20.1, C22.1, C24.1, C26.1, C27.1, C28.1, C30.1, C32.1, C34.1, IC1.2, IC1.13, IC1.18, IC1.27, IC1.33, IC1.39, IC1.45, IC1.51, IC1.60, IC1.66, L10.1
+3V3_LO_1: C38.1, C39.1, C40.1, C45.1, C48.1, C49.1, C50.1, C72.1, C77.1, C78.1, C79.1, C80.1, C81.1, L12.1, R24.2, R25.2, R37.2, R38.2, U1.3, U1.30, U1.36, U1.40, U1.44, U1.45, U6.3, U6.30, U6.36, U6.40, U6.44, U6.45
+3V3_LO_2: C1.1, C47.1, C55.1, C56.1, C57.1, C58.1, C63.1, C73.1, C74.1, C75.1, C76.1, C86.1, C89.1, L1.1, L2.1, L3.2, L4.2, L5.1, L6.2, L7.1, L8.2, L13.1, U1.5, U1.11, U1.13, U1.24, U6.5, U6.11, U6.13, U6.24
+3V3_XO: C23.1, L9.1, R2.2, X4.3, X5.4, X6.4
+5V0_LO: C51.1, FB1.1, FB2.1, FB3.2, FB4.2, X15.1
AD9523_CS: JP1.5, R10.1
AD9523_EEPROM_SEL: IC1.57, JP1.11
AD9523_OUT0_N: C11.2, IC1.67
AD9523_OUT0_P: C12.2, IC1.68
AD9523_OUT1_N: C68.2, IC1.64
AD9523_OUT1_P: C69.2, IC1.65
AD9523_OUT4_N: IC1.52, J3.2
AD9523_OUT4_P: IC1.53, J3.1
AD9523_OUT5_N: IC1.49, J4.2
AD9523_OUT5_P: IC1.50, J4.1
AD9523_OUT6+: C15.2, J7.1
AD9523_OUT7+: IC1.44, J8.1
AD9523_OUT8_N: C70.2, IC1.40
AD9523_OUT8_P: C71.2, IC1.41
AD9523_OUT9_N: C13.2, IC1.37
AD9523_OUT9_P: C14.2, IC1.38
AD9523_OUT10+: IC1.35, R40.1
AD9523_OUT11+: IC1.32, R41.1
AD9523_PD: IC1.15, JP1.1
AD9523_REF_SEL: IC1.16, JP1.2
AD9523_RESET: IC1.19, JP1.4
AD9523_SCLK: JP1.6, R6.1
AD9523_SDIO: JP1.7, R8.1
AD9523_SDO: IC1.23, JP1.8
AD9523_STATUS0: IC1.56, JP1.9
AD9523_STATUS1: IC1.55, JP1.10
AD9523_SYNC: IC1.17, JP1.3
ADF4382_RX_CE: JP2.10, R38.1, U6.31
ADF4382_RX_CS: JP2.9, R37.1, U6.32
ADF4382_RX_DELADJ: JP2.12, R35.2, U6.28
ADF4382_RX_DELSTR: JP2.11, R36.2, U6.29
ADF4382_RX_LKDET: JP2.13, R34.2, U6.27
ADF4382_RX_SYNC_N: C70.1, R26.2, U6.39
ADF4382_RX_SYNC_P: C71.1, R26.1, U6.38
ADF4382_SCLK: JP2.2, U1.34, U6.34
ADF4382_SDIO: JP2.3, U1.33, U6.33
ADF4382_SDO: JP2.1, U1.35, U6.35
ADF4382_TX_CE: JP2.5, R25.1, U1.31
ADF4382_TX_CS: JP2.4, R24.1, U1.32
ADF4382_TX_DELADJ: JP2.7, R22.2, U1.28
ADF4382_TX_DELSTR: JP2.6, R23.2, U1.29
ADF4382_TX_LKDET: JP2.8, R21.2, U1.27
ADF4382_TX_SYNC_N: C13.1, R13.2, U1.39
ADF4382_TX_SYNC_P: C14.1, R13.1, U1.38
GND: C1.2, C2.2, C3.1, C4.1, C5.1, C6.1, C7.1, C9.1, C10.1, C16.2, C18.2, C20.2, C21.2, C22.2, C23.2, C24.2, C25.2, C26.2, C27.2, C28.2, C29.2, C30.2, C31.2, C32.2, C33.2, C34.2, C35.2, C36.2, C37.2, C38.2, C39.2, C40.2, C41.2, C42.2, C43.2, C44.2, C45.2, C46.2, C47.2, C48.2, C49.2, C50.2, C51.2, C55.2, C56.2, C57.2, C58.2, C59.1, C60.2, C61.2, C62.2, C63.2, C72.2, C73.2, C74.2, C75.2, C76.2, C77.2, C78.2, C79.2, C80.2, C81.2, C82.1, C83.2, C84.2, C85.2, C86.2, C89.2, D1.C, D2.C, IC1.73, J1.2, J1.3, J1.4, J1.5, J2.2, J2.3, J2.4, J2.5, J5.2, J5.3, J5.4, J5.5, J6.2, J6.3, J6.4, J6.5, J7.2, J7.3, J7.4, J7.5, J8.2, J8.3, J8.4, J8.5, J9.2, J9.3, J9.4, J9.5, J10.2, J10.3, J10.4, J10.5, J11.2, J11.3, J11.4, J11.5, J12.2, J12.3, J12.4, J12.5, J13.2, J13.3, J13.4, J13.5, JP1.12, JP2.14, R3.1, R7.2, R9.2, R11.2, R22.1, R23.1, R35.1, R36.1, U1.1, U1.2, U1.4, U1.10, U1.12, U1.14, U1.16, U1.18, U1.19, U1.21, U1.23, U1.25, U1.26, U1.41, U1.48, U1.49, U1.50, U1.51, U1.52, U2.1, U2.3, U2.6, U2.10, U2.13, U3.1, U3.3, U3.6, U3.10, U3.13, U4.3, U4.4, U5.3, U5.4, U6.1, U6.2, U6.4, U6.10, U6.12, U6.14, U6.16, U6.18, U6.19, U6.21, U6.23, U6.25, U6.26, U6.41, U6.48, U6.49, U6.50, U6.51, U6.52, U7.1, U7.3, U7.6, U7.10, U7.13, U8.3, U8.4, U9.1, U9.3, U9.6, U9.10, U9.13, U10.3, U10.4, X4.5, X5.2, X6.2, X10.2, X11.2, X12.2, X13.2, X14.2, X15.2
unnamed: R2.1, R3.2, X4.1
unnamed: C2.1, R4.1, X6.1
unnamed: C3.2, IC1.1
unnamed: C6.2, IC1.7
unnamed: C4.2, IC1.4
unnamed: C5.2, IC1.6
unnamed: C7.2, IC1.10
unnamed: C8.2, IC1.11
unnamed: C8.1, R5.1
unnamed: C9.2, IC1.14, R5.2
unnamed: C10.2, IC1.12
unnamed: IC1.21, R6.2, R7.1
unnamed: IC1.22, R8.2, R9.1
unnamed: IC1.20, R10.2, R11.1
unnamed: C11.1, R12.2, U1.43
unnamed: C12.1, R12.1, U1.42
unnamed: C61.1, R18.2
unnamed: R14.1, U1.9
unnamed: FB2.2, R14.2, U1.8
unnamed: C59.2, FB3.1, U1.46
unnamed: R19.1, R20.2
unnamed: R15.1, U1.7
unnamed: R15.2, R16.2
unnamed: C60.1, R16.1, R17.2
unnamed: R17.1, R18.1, R19.2
unnamed: C62.1, R20.1, U1.47
unnamed: U2.2, U4.1
unnamed: C65.2, U2.7
unnamed: J10.1, U4.2
unnamed: C64.2, U2.9
unnamed: C67.2, U3.7
unnamed: C66.2, U3.9
unnamed: U3.2, U5.1
unnamed: J1.1, U5.2
unnamed: D1.A, R21.1
unnamed: J9.1, U1.37
unnamed: C68.1, R1.2, U6.43
unnamed: C69.1, R1.1, U6.42
unnamed: R27.1, U6.9
unnamed: FB1.2, R27.2, U6.8
unnamed: C82.2, FB4.1, U6.46
unnamed: C84.1, R31.2
unnamed: R32.1, R33.2
unnamed: R28.1, U6.7
unnamed: R28.2, R29.2
unnamed: C83.1, R29.1, R30.2
unnamed: R30.1, R31.1, R32.2
unnamed: C85.1, R33.1, U6.47
unnamed: D2.A, R34.1
unnamed: J2.1, U6.37
unnamed: C88.2, U7.7
unnamed: C87.2, U7.9
unnamed: U7.2, U8.1
unnamed: J11.1, U8.2
unnamed: C91.2, U9.7
unnamed: C90.2, U9.9
unnamed: U9.2, U10.1
unnamed: J12.1, U10.2
unnamed: C92.1, IC1.72
unnamed: C92.2, J13.1
unnamed: IC1.47, R39.1
unnamed: C15.1, R39.2
unnamed: C17.2, J5.1
unnamed: C17.1, R40.2
unnamed: C19.2, J6.1
unnamed: C19.1, R41.2
unnamed: C21.1, L9.2, X10.1
unnamed: C25.1, L10.2, X11.1
unnamed: C29.1, L11.2, X12.1
unnamed: C33.1, L12.2, X13.1
unnamed: C46.1, L13.2, X14.1
OSC_CTRL: IC1.8, R4.2
RX_RFOUT_1_N: C87.1, L5.2, U6.20
RX_RFOUT_1_P: C88.1, L6.1, U6.22
RX_RFOUT_2_N: C90.1, L7.2, U6.15
RX_RFOUT_2_P: C91.1, L8.1, U6.17
TX_RFOUT_1_N: C64.1, L2.2, U1.20
TX_RFOUT_1_P: C65.1, L3.1, U1.22
TX_RFOUT_2_N: C66.1, L1.2, U1.15
TX_RFOUT_2_P: C67.1, L4.1, U1.17
VCXO_OUT: IC1.9, X6.3

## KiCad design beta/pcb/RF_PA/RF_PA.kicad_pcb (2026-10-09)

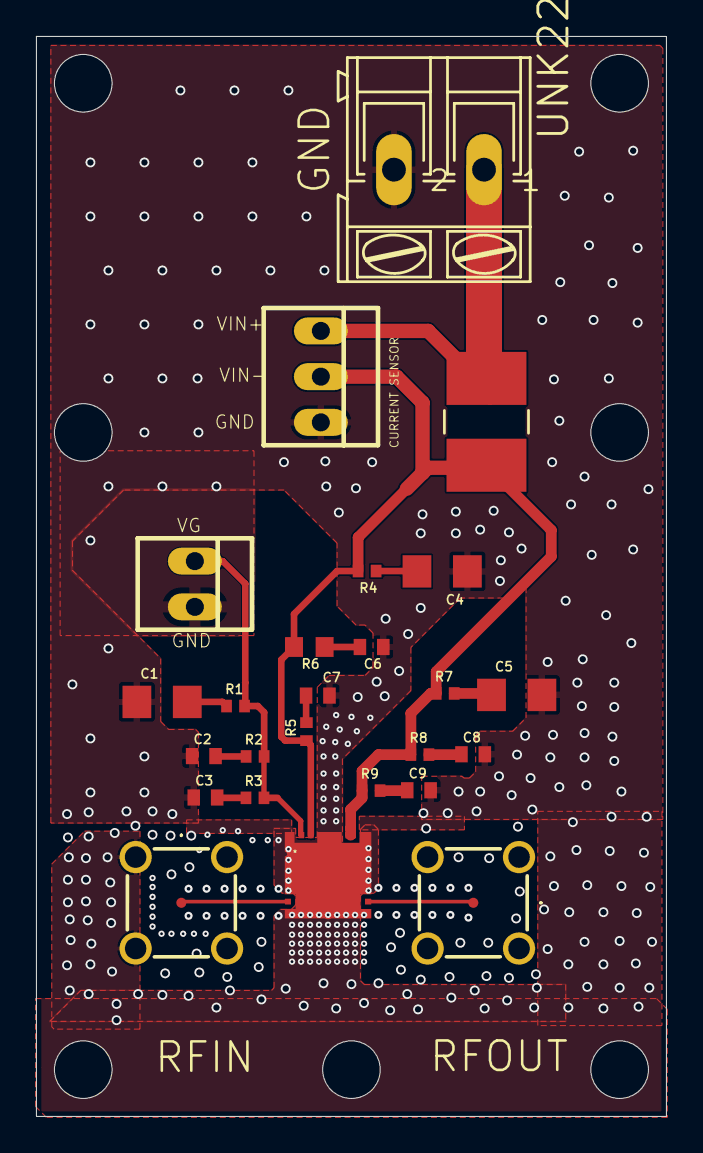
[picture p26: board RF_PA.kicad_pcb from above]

Board: 4 copper layers, 35.0 x 60.0 mm, 32 parts (0 on the bottom side), 15 nets.

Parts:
C1, C4, C5: 10µF; C1206
C2, C3, C6, C7, C8, C9: 0.1µF; C0402
J1, J2: 142-0731-211; 1420731211
R1, R4: 10R; R0402
R2, R3, R5, R7, R8, R9: 0R; R0402
R6: 0R; R0603
R10: 5mR; WSL2816_VIS
U$1: QPA2962_B
UNK22V0: AK300_2
UNK_HOLE_0: dummyfp0
UNK_HOLE_1: dummyfp1
UNK_HOLE_2: dummyfp2
UNK_HOLE_3: dummyfp3
UNK_HOLE_4: dummyfp4
UNK_HOLE_5: dummyfp5
UNK_HOLE_6: dummyfp6
X2: 22-23-2021
X3: 22-23-2031

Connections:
GND: C1.1, C2.1, C3.1, C4.1, C5.2, C6.1, C7.1, C8.2, C9.2, J1.2, J1.3, J1.4, J1.5, J2.2, J2.3, J2.4, J2.5, U$1.GND, UNK22V0.2, X2.2, X3.3
unnamed: C3.2, R3.1
unnamed: J1.1, U$1.RFIN
unnamed: C1.2, R1.1
unnamed: C2.2, R2.1
unnamed: C4.2, R4.1
unnamed: C6.2, R6.1
unnamed: C7.2, R5.1
unnamed: J2.1, U$1.RFOUT
unnamed: C5.1, R7.2
unnamed: C8.1, R8.2
unnamed: C9.1, R9.2
VD: R10.2, UNK22V0.1, X3.1
VG: R1.2, R2.2, R3.2, U$1.VG, X2.1
VIN_M: R4.2, R5.2, R6.2, R7.1, R8.1, R9.1, R10.1, U$1.VD1, U$1.VD2, X3.2

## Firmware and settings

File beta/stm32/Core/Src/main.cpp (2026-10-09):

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
/* Includes ------------------------------------------------------------------*/
#include "main.h"
#include "usb_device.h"
#include "USBHandler.h"
#include "usbd_cdc_if.h"
#include "adar1000.h"
#include "ADAR1000_Manager.h"
extern "C" {
#include "ad9523.h"
}
#include "no_os_delay.h"
#include "no_os_alloc.h"
#include "no_os_print_log.h"
#include "no_os_error.h"
#include "no_os_units.h"
#include "no_os_dma.h"
#include "no_os_spi.h"
#include "no_os_uart.h"
#include "no_os_util.h"
#include <stdint.h>
#include <errno.h>
#include <math.h>
#include <stdio.h>
#include <string.h>
#include <inttypes.h>
#include <iostream>
#include <vector>
#include "stm32_spi.h"
#include "stm32_delay.h"
#include "TinyGPSPlus.h"
extern "C" {
#include "GY_85_HAL.h"
}
#include "BMP180.h"
/* BETA: platform_noos_stm32.h removed from the build (LIB/_excluded): its .c calls an
 * undefined hal_set_gpio_by_index() and nothing in main.cpp uses its API. */
extern "C" {

#include "adf4382a_manager.h"
#include "host_bridge.h"   /* DSN-LINK-01 option B: FPGA→STM32 SPI bridge (BETA) */
#include "adf4382.h"
#include "no_os_delay.h"
#include "no_os_error.h"
}
#include <cmath>
#include "DAC5578.h"
#include "ADS7830.h"
#include "gps_handler.h"
#include "aeris_beam.h"   /* BETA: pure beam-matrix maths (host-testable) */

#include "stm32f7xx_hal.h"




/* USER CODE BEGIN PD */


/* -------- GPIO index mapping for no-OS interface -------- */
#define GPIO_IDX_TX_CS       0
#define GPIO_IDX_RX_CS       1
#define GPIO_IDX_TX_DELSTR   2
#define GPIO_IDX_TX_DELADJ   3
#define GPIO_IDX_RX_DELSTR   4
#define GPIO_IDX_RX_DELADJ   5
#define GPIO_IDX_TX_CE       6
#define GPIO_IDX_RX_CE       7
#define GPIO_IDX_SW_SYNC     8

/* USER CODE END PD */


I2C_HandleTypeDef hi2c1;
I2C_HandleTypeDef hi2c2;
I2C_HandleTypeDef hi2c3;

SPI_HandleTypeDef hspi1;
SPI_HandleTypeDef hspi4;

TIM_HandleTypeDef htim1;

UART_HandleTypeDef huart5;
UART_HandleTypeDef huart3;

/* USER CODE BEGIN PV */
// The TinyGPSPlus object
TinyGPSPlus gps;

// Global data structures
GPS_Data_t current_gps_data = {0};

// Global USB handler
USBHandler usbHandler;
extern USBD_HandleTypeDef hUsbDeviceFS;

// Buffer for USB reception
uint8_t usb_rx_buffer[64];

//IMU variable
GY85_t imu;

float Pitch_Sensor, Yaw_Sensor, Roll_Sensor;

float abias[3] = {-0.108, -0.038, -0.006}, gbias[3] = {-10, 6, -12}, mbias[3]={0.0,0.0,0.0};
float M11=1.0,  M12=-0.0,  M13=0.0,
      M21=0.0,  M22=1.0,   M23=0.0,
      M31=0.0,  M32=-0.0,  M33=1.0;
float ax, ay, az, gx, gy, gz, mx, my, mz,mxc,myc,mzc; // variables to hold latest sensor data values
float q[4] = {1.0f, 0.0f, 0.0f, 0.0f};    // vector to hold quaternion
float temperature;
float Mag_Declination = -0.61; //0°

float RxAcc,RyAcc,RzAcc;
float Rate_Ayz_1,Rate_Axz_1,Rate_Axy_1;
float Axz_1,Ayz_1,Axy_1, Axz_0,Ayz_0,Axy_0;
float RxEst_0,RyEst_0,RzEst_0, RxEst_1,RyEst_1,RzEst_1,Azr_Est;
float RxGyro,RyGyro,RzGyro, R_Est;

unsigned long now_timeperiod;
unsigned long lasttime_timeperiod = 0;
int Time_Period = 0;

//Barometer BMP180

/*resolution:
BMP180_ULTRALOWPOWER - pressure oversampled 1 time  & power consumption 3μA
BMP180_STANDARD      - pressure oversampled 2 times & power consumption 5μA
BMP180_HIGHRES       - pressure oversampled 4 times & power consumption 7μA
BMP180_ULTRAHIGHRES  - pressure oversampled 8 times & power consumption 12μA, library default
*/
BMP180 myBMP(BMP180_ULTRAHIGHRES);
float RADAR_Altitude;

//GPS
double RADAR_Longitude = 0;
double RADAR_Latitude = 0;

extern uint8_t GUI_start_flag_received;


//RADAR
// Radar parameters
const int m_max = 32;  // Number of chirps per beam position
const int n_max = 31;   // Number of beam positions
const float T1 = 30.0f; // Chirp duration in microseconds
const float PRI1 = 167.0f; // Pulse repetition interval in microseconds
const float T2 = 0.5f;  // Short chirp duration in microseconds
const float PRI2 = 175.0f; // Short PRI in microseconds
const float Guard = 175.4f; // Guard time in microseconds

uint8_t	m = 1; // m = N° of chirp/ position = 16 (made of T1 and PRF1)+ Guard = 175µs +16 (made of T2 and PRF2)
uint8_t	n = 1; // n =[1-31] N° of elevations/azimuth
uint8_t	y = 1;// y = N° of azimuths/revolution = 50 controlled by a microcontroller connected to a stepper motor
uint8_t y_max = 50;// y = N° of azimuths/revolution
uint64_t IF_freq = 120000000ULL;//120MHz

#define PowerAmplifier 1

//Stepper Motor
float Stepper_steps = 200.0f;//step per revolution

// DAC5578 handles (RF Power Amplifier DAC controlling Vg)
DAC5578_HandleTypeDef hdac1, hdac2;
/* Phase accumulators */
float phase_dac1[8] = {0};
float phase_dac2[8] = {0};
const uint32_t sampleRate = 370;    // Sample rate in Hz
const uint32_t period = 2700;       // Period in microseconds
uint8_t DAC_val = 126;

// ADC handles (RF Power Amplifier ADC measuring Idq)
ADS7830_HandleTypeDef hadc1, hadc2;
uint8_t adc1_readings[8] = {0};
uint8_t adc2_readings[8] = {0};
float Idq_reading[16]={0.0f};


// Global manager instance ADF4382A
ADF4382A_Manager lo_manager;
extern SPI_HandleTypeDef hspi4;

//ADAR1000

ADAR1000Manager adarManager;
static uint8_t matrix1[15][16];
static uint8_t matrix2[15][16];
static uint8_t vector_0[16] = {0,0,0,0,0,0,0,0,0,0,0,0,0,0,0,0};

/* Radar parameters
const int m_max = 32;  // Number of chirps per beam position
const int n_max = 31;   // Number of beam positions
const float T1 = 30.0f; // Chirp duration in microseconds
const float PRI1 = 167.0f; // Pulse repetition interval in microseconds
const float T2 = 0.5f;  // Short chirp duration in microseconds
const float T2 = 175.0f; // Short PRI in microseconds
const float Guard = 175.40f; // Guard time in microseconds*/

//Temperature Sensors
ADS7830_HandleTypeDef hadc3;
float Temperature_1 = 0.0f, Temperature_2 = 0.0f, Temperature_3 = 0.0f, Temperature_4 = 0.0f;
float Temperature_5 = 0.0f, Temperature_6 = 0.0f, Temperature_7 = 0.0f, Temperature_8 = 0.0f;

// Phase differences for 31 beam positions
const float phase_differences[31] = {
    160.0f, 80.0f, 53.333f, 40.0f, 32.0f, 26.667f, 22.857f, 20.0f, 17.778f, 16.0f,
    14.545f, 13.333f, 12.308f, 11.429f, 10.667f, 0.0f,
    -10.667f, -11.429f, -12.308f, -13.333f, -14.545f, -16.0f, -17.778f, -20.0f,
    -22.857f, -26.667f, -32.0f, -40.0f, -53.333f, -80.0f, -160.0f
};

// Convenience HAL wrappers for AD9523 control pins (GPIOF as you said)
static inline void AD9523_PD(bool v)        { HAL_GPIO_WritePin(GPIOF, AD9523_PD_Pin, v ? GPIO_PIN_SET : GPIO_PIN_RESET); }
static inline void AD9523_REF_SEL(bool v)   { HAL_GPIO_WritePin(GPIOF, AD9523_REF_SEL_Pin, v ? GPIO_PIN_SET : GPIO_PIN_RESET); }
static inline void AD9523_SYNC_PULSE(void)  { HAL_GPIO_WritePin(GPIOF, AD9523_SYNC_Pin, GPIO_PIN_SET); HAL_Delay(1); HAL_GPIO_WritePin(GPIOF, AD9523_SYNC_Pin, GPIO_PIN_RESET); }
static inline void AD9523_RESET_ASSERT()    { HAL_GPIO_WritePin(GPIOF, AD9523_RESET_Pin, GPIO_PIN_RESET); } // check polarity
static inline void AD9523_RESET_RELEASE()   { HAL_GPIO_WritePin(GPIOF, AD9523_RESET_Pin, GPIO_PIN_SET); }
static inline void AD9523_CS(bool v)        { HAL_GPIO_WritePin(GPIOF, AD9523_CS_Pin, v ? GPIO_PIN_SET : GPIO_PIN_RESET); }
static inline void AD9523_EEPROM_SEL(bool v){ HAL_GPIO_WritePin(GPIOF, AD9523_EEPROM_SEL_Pin, v ? GPIO_PIN_SET : GPIO_PIN_RESET); }

/* USER CODE END PV */

void SystemClock_Config(void);
void PeriphCommonClock_Config(void);
static void MPU_Config(void);
static void MX_GPIO_Init(void);
static void MX_TIM1_Init(void);
static void MX_I2C1_Init(void);
static void MX_I2C2_Init(void);
static void MX_I2C3_Init(void);
static void MX_SPI1_Init(void);
static void MX_SPI4_Init(void);
static void MX_UART5_Init(void);
static void MX_USART3_UART_Init(void);
/* USER CODE BEGIN PFP */

// Function prototypes
void systemPowerUpSequence();
void systemPowerDownSequence();
void initializeBeamMatrices();
void runRadarPulseSequence();
void executeChirpSequence(int num_chirps, uint32_t T1, uint32_t PRI1, uint32_t T2, uint32_t PRI2);
void printSystemStatus();

//////////////////////////////////////////////
////////////////////micros()//////////////////
//////////////////////////////////////////////
unsigned long micros(void){
unsigned long Micros = __HAL_TIM_GET_COUNTER(&htim1);
return Micros; //Clock TIM1 = 216 MHz (HCLK, TIMPRE=1) / (presc+1), presc = 215 -> 1 MHz (BETA)
}

//////////////////////////////////////////////
//////////////////Delay_us()//////////////////
//////////////////////////////////////////////

void delay_us(volatile uint32_t us){
__HAL_TIM_SET_COUNTER(&htim1,0);  // set the counter value a
while (__HAL_TIM_GET_COUNTER(&htim1) < us);  // TIM1 tick = 1 MHz (216 MHz / 216), see MX_TIM1_Init (BETA)
}

//////////////////////////////////////////////
//////////////////delay_ns()//////////////////
//////////////////////////////////////////////
void delay_ns(uint32_t nanoseconds)
{
    // Get the starting cycle count
    uint32_t start_cycles = DWT->CYCCNT;

    // Convert nanoseconds to the number of CPU clock cycles
    // Use `SystemCoreClock` to get the current CPU frequency.
    // Use 64-bit math to prevent overflow for large nanosecond values.
    uint32_t cycles = (uint32_t)(((uint64_t)nanoseconds * SystemCoreClock) / 1000000000);

    // Busy-wait until the required number of cycles has passed
    while ((DWT->CYCCNT - start_cycles) < cycles);
}

//////////////////////////////////////////////
//////////////////////RADAR///////////////////
//////////////////////////////////////////////
uint8_t degreesTo7BitPhase(float degrees) {
    /* BETA: arithmetic moved verbatim to LIB/aeris_beam.c (unit-tested on host) */
    return aeris_degrees_to_7bit_phase(degrees);
}

extern "C" {

    /* BETA fix C4: application hook called by USB_DEVICE/App/usbd_cdc_if.c
     * CDC_Receive_FS() for every OUT packet (interrupt context). The original
     * file defined its own CDC_Receive_FS here, which the CubeMX CDC interface
     * never calls (it binds a static function of the same name). */
    void AERIS_USB_OnReceive(const uint8_t* Buf, uint32_t Len) {
        usbHandler.processUSBData(Buf, Len);
    }

    /* BETA: retarget newlib printf() to USART3 (115200 8N1, debug header).
     * syscalls.c:_write() calls the weak __io_putchar(); without a definition
     * every printf() in adf4382a_manager.c would branch to address 0. */
    int __io_putchar(int ch) {
        uint8_t c = (uint8_t)ch;
        HAL_UART_Transmit(&huart3, &c, 1, 10);
        return ch;
    }
}

void systemPowerUpSequence() {
    uint8_t msg[] = "Starting Power Up Sequence...\r\n";
    HAL_UART_Transmit(&huart3, msg, sizeof(msg)-1, 1000);

    // Step 1: Initialize ADTR1107 power sequence
    if (!adarManager.initializeADTR1107Sequence()) {
        uint8_t err[] = "ERROR: ADTR1107 power sequence failed!\r\n";
        HAL_UART_Transmit(&huart3, err, sizeof(err)-1, 1000);
        Error_Handler();
    }

    // Step 2: Initialize all ADAR1000 devices
    if (!adarManager.initializeAllDevices()) {
        uint8_t err[] = "ERROR: ADAR1000 initialization failed!\r\n";
        HAL_UART_Transmit(&huart3, err, sizeof(err)-1, 1000);
        Error_Handler();
    }

    // Step 3: Perform system calibration
    if (!adarManager.performSystemCalibration()) {
        uint8_t warn[] = "WARNING: System calibration issues\r\n";
        HAL_UART_Transmit(&huart3, warn, sizeof(warn)-1, 1000);
    }

    // Step 4: Set to safe TX mode
    adarManager.setAllDevicesTXMode();

    uint8_t success[] = "Power Up Sequence Completed Successfully\r\n";
    HAL_UART_Transmit(&huart3, success, sizeof(success)-1, 1000);
}

void systemPowerDownSequence() {
    uint8_t msg[] = "Starting Power Down Sequence...\r\n";
    HAL_UART_Transmit(&huart3, msg, sizeof(msg)-1, 1000);

    // Step 1: Set all devices to RX mode (safest state)
    adarManager.setAllDevicesRXMode();
    HAL_Delay(10);

    // BETA (DECISIONS.md D-11): remove the QPA2962 22 V drain (VD) before anything
    // else so that the PA is never left with VD applied while its gate driver
    // rails are collapsing (xlsx bias-down order: RF off -> VD off -> VG off).
    HAL_GPIO_WritePin(EN_DIS_RFPA_VDD_GPIO_Port, EN_DIS_RFPA_VDD_Pin, GPIO_PIN_RESET);
    HAL_Delay(10);

    // Step 2: Disable PA power supplies
    HAL_GPIO_WritePin(EN_P_5V0_PA1_GPIO_Port, EN_P_5V0_PA1_Pin | EN_P_5V0_PA2_Pin | EN_P_5V0_PA3_Pin, GPIO_PIN_RESET);
    HAL_Delay(10);

    // Step 3: Set PA biases to safe values
    for (uint8_t dev = 0; dev < 4; dev++) {
        adarManager.adarWrite(dev, REG_PA_CH1_BIAS_ON, 0x20, BROADCAST_OFF);
        adarManager.adarWrite(dev, REG_PA_CH2_BIAS_ON, 0x20, BROADCAST_OFF);
        adarManager.adarWrite(dev, REG_PA_CH3_BIAS_ON, 0x20, BROADCAST_OFF);
        adarManager.adarWrite(dev, REG_PA_CH4_BIAS_ON, 0x20, BROADCAST_OFF);
    }
    HAL_Delay(10);

    // Step 4: Disable LNA power supply
    HAL_GPIO_WritePin(EN_P_3V3_ADTR_GPIO_Port, EN_P_3V3_ADTR_Pin, GPIO_PIN_RESET);
    HAL_Delay(10);

    // Step 5: Set LNA bias to safe value
    for (uint8_t dev = 0; dev < 4; dev++) {
        adarManager.adarWrite(dev, REG_LNA_BIAS_ON, 0x00, BROADCAST_OFF);
    }
    HAL_Delay(10);

    // Step 6: Disable switch power supplies
    HAL_GPIO_WritePin(EN_P_3V3_VDD_SW_GPIO_Port, EN_P_3V3_VDD_SW_Pin, GPIO_PIN_RESET);
    HAL_GPIO_WritePin(EN_P_3V3_SW_GPIO_Port, EN_P_3V3_SW_Pin, GPIO_PIN_RESET);
    HAL_Delay(10);

    // BETA (D-11): VG driver rails (+5V5_PA / -5V5_PA via LM2662) last, after VD is off.
    HAL_GPIO_WritePin(EN_P_5V5_PA_GPIO_Port, EN_P_5V5_PA_Pin, GPIO_PIN_RESET);
    HAL_Delay(10);

    uint8_t success[] = "Power Down Sequence Completed\r\n";
    HAL_UART_Transmit(&huart3, success, sizeof(success)-1, 1000);
}
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
int main(void)
{

  /* MPU Configuration--------------------------------------------------------*/
  MPU_Config();

  /* MCU Configuration--------------------------------------------------------*/

  /* Reset of all peripherals, Initializes the Flash interface and the Systick. */
  HAL_Init();

  /* Configure the system clock */
  SystemClock_Config();

  /* Configure the peripherals common clocks */
  PeriphCommonClock_Config();

  /* Initialize all configured peripherals */
  MX_GPIO_Init();
  MX_TIM1_Init();
  MX_I2C1_Init();
  MX_I2C2_Init();
  MX_I2C3_Init();
  MX_SPI1_Init();
  HostBridge_Init();   /* DSN-LINK-01: PD13 = FPGA_CS_N, PD14 = DRDY (EXTI), SPI1 shared with the ADAR1000 path */
  MX_SPI4_Init();
  MX_UART5_Init();
  MX_USART3_UART_Init();
  MX_USB_DEVICE_Init();
  /* USER CODE BEGIN 2 */
  GPS_Init(&huart3);   /* BETA fix C6: gps_handler's gui_huart was never set, so
                          GPS_SendBinaryToGUI() returned before CDC_Transmit_FS(). */

  HAL_TIM_Base_Start(&htim1);

  /* --- Enable DWT cycle counter for accurate microsecond delays --- */
  DWT_Init();
  //Wait for OCXO 3mn
  HAL_Delay(180000);
  HAL_GPIO_WritePin(AD9523_RESET_GPIO_Port,AD9523_RESET_Pin,GPIO_PIN_RESET);

  //Power sequencing AD9523
  HAL_GPIO_WritePin(EN_P_1V8_CLOCK_GPIO_Port,EN_P_1V8_CLOCK_Pin,GPIO_PIN_SET);
  HAL_Delay(100);
  HAL_GPIO_WritePin(EN_P_3V3_CLOCK_GPIO_Port,EN_P_3V3_CLOCK_Pin,GPIO_PIN_SET);
  HAL_Delay(100);
  HAL_GPIO_WritePin(AD9523_RESET_GPIO_Port,AD9523_RESET_Pin,GPIO_PIN_SET);
  HAL_Delay(100);

  //Set planned Clocks on AD9523
  /*
  o Channel 0 = 300MHz LVDS (ADF4382 TX)
  o Channel 1 = 300MHz LVDS (ADF4382 RX) (Phase aligned with Channel 0)
  o Channel 4 = 400MHz LVDS (ADC)
  o Channel 5 = 400MHz LVDS (FPGA_ADC)(Phase aligned with Channel 4)
  o Channel 6 = 100MHz LVCMOS (FPGA system clock)
  o Channel 7 = 20MHz LVCMOS (FPGA test)
  o Channel 8 = 60MHz LVDS (ADF4382 TX sync)
  o Channel 9 = 60MHz LVDS (ADF4382 RX sync)(Phase aligned with Channel 8)
  o Channel 10 = 120MHz LVCMOS
  o Channel 11 = 120MHz LVCMOS (Phase aligned with Channel 10)
   */


  // Ensure stm32_spi.c and stm32_delay.c are compiled and linked

  if (configure_ad9523() != 0) {
      // configuration error - handle as needed
      while (1) { HAL_Delay(1000); }
  }

  //Power sequencing FPGA
  HAL_GPIO_WritePin(EN_P_1V0_FPGA_GPIO_Port,EN_P_1V0_FPGA_Pin,GPIO_PIN_SET);
  HAL_Delay(100);
  HAL_GPIO_WritePin(EN_P_1V8_FPGA_GPIO_Port,EN_P_1V8_FPGA_Pin,GPIO_PIN_SET);
  HAL_Delay(100);
  HAL_GPIO_WritePin(EN_P_3V3_FPGA_GPIO_Port,EN_P_3V3_FPGA_Pin,GPIO_PIN_SET);
  HAL_Delay(100);


// Initialize module IMU
  GY85_Init();
  for(int i=0; i<10;i++){
  GY85_Update(&imu);

  ax = imu.ax;
  ay = imu.ay;
  az = imu.az;
  gx = -imu.gx;
  gy = -imu.gy;
  gz = imu.gz;
  mx = imu.mx;
  my = imu.my;
  mz = imu.mz;

  ax *= 6.10351e-5;   //2.0 / 32768.0;
  ay *= 6.10351e-5;
  az *= 6.10351e-5;

  ax -= abias[0];   // Convert to g's, remove accelerometer biases
  ay -= abias[1];
  az -= abias[2];

  gx *= 0.0152588f;   //500.0 / 32768.0;
  gy *= 0.0152588f;
  gz *= 0.0152588f;

  gx -= gbias[0];   // Convert to degrees per seconds, remove gyro biases
  gy -= gbias[1];
  gz -= gbias[2];

  mx *= 6.10351e-5;   //2.0 / 32768.0;
  my *= 6.10351e-5;
  mz *= 6.10351e-5;

  mxc = M11*(mx-mbias[0]) + M12*(my-mbias[1]) +M13*(mz-mbias[2]);
  myc = M21*(mx-mbias[0]) + M22*(my-mbias[1]) +M23*(mz-mbias[2]);
  mzc = M31*(mx-mbias[0]) + M32*(my-mbias[1]) +M33*(mz-mbias[2]);

  mx = mxc;
  my = myc;
  mz = mzc;

  float norm = sqrt((mx*mx) + (my*my) + (mz*mz));
  mx /=norm;
  my /=norm;
  mz /=norm;

  /***************************************************************/
  /*********************IMU Complementary Filter******************/
  /***************************************************************/
    RxAcc = ax;
    RyAcc = ay;
    RzAcc = az;

    Rate_Ayz_1 = gx;
    Rate_Axz_1 = gy;
    Rate_Axy_1 = gz;

    Rate_Ayz_1 = Rate_Ayz_1*0.01745;//Convertion from °/s to Radians/s
    Rate_Axz_1 = Rate_Axz_1*0.01745;
    Rate_Axy_1 = Rate_Axy_1*0.01745;

    /*Combining Accelerometer & Gyroscope Data*/
    Axz_0 = atan2(RxEst_0,RzEst_0);
    Ayz_0 = atan2(RyEst_0,RzEst_0);
    Axy_0 = atan2(RxEst_0,RyEst_0);

    now_timeperiod = micros();

    Time_Period = now_timeperiod - lasttime_timeperiod;

    Axz_1= Axz_0 + Rate_Axz_1*Time_Period*0.000001;
    Ayz_1= Ayz_0 + Rate_Ayz_1*Time_Period*0.000001;
    Axy_1= Axy_0 + Rate_Axy_1*Time_Period*0.000001;

    lasttime_timeperiod = now_timeperiod;

    RxGyro = sin(Axz_1)/(sqrt(1.0 + cos(Axz_1)*cos(Axz_1) * tan(Ayz_1)*tan(Ayz_1)));
    RyGyro = sin(Ayz_1)/(sqrt(1.0 + cos(Ayz_1)*cos(Ayz_1) * tan(Axz_1)*tan(Axz_1)));
    if(RzEst_0 >= 0){
      RzGyro = 1.0*sqrt(1 - RxGyro*RxGyro - RyGyro*RyGyro);
    }
    else {
      RzGyro = -1*sqrt(1 - RxGyro*RxGyro - RyGyro*RyGyro);
    }

    RxEst_1 = RxAcc*0.5 + RxGyro*0.5 ;// Weight of Gyro. over Acc.
    RyEst_1 = RyAcc*0.5 + RyGyro*0.5 ;
    RzEst_1 = RzAcc*0.5 + RzGyro*0.5 ;

    R_Est = sqrt(RxEst_1*RxEst_1+RyEst_1*RyEst_1+RzEst_1*RzEst_1);

    Pitch_Sensor = atan2(RxEst_1,sqrt(RyEst_1*RyEst_1)+(RzEst_1*RzEst_1))*180/PI;
    Roll_Sensor = atan2(RyEst_1,sqrt(RxEst_1*RxEst_1)+(RzEst_1*RzEst_1))*180/PI;

    float magRawX = mx*cos(Pitch_Sensor*PI/180.0f)  - mz*sin(Pitch_Sensor*PI/180.0f);
	float magRawY = mx*sin(Roll_Sensor*PI/180.0f)*sin(Pitch_Sensor*PI/180.0f) + my*cos(Roll_Sensor*PI/180.0f)- mz*sin(Roll_Sensor*PI/180.0f)*cos(Pitch_Sensor*PI/180.0f);
    Yaw_Sensor = (180*atan2(magRawY,magRawX)/PI) - Mag_Declination;

    if(Yaw_Sensor<0)Yaw_Sensor+=360;
    RxEst_0 = RxEst_1;
    RyEst_0 = RyEst_1;
    RzEst_0 = RzEst_1;

    HAL_Delay(300);

  }

    ///////////////////////////////////////////////////////////////////////////////////
    ///////////////////////////////////BAROMETER BMP180////////////////////////////////
    ///////////////////////////////////////////////////////////////////////////////////
  	for(int i = 0; i<5 ; i++){
		float BMP_Perssure = myBMP.getPressure();
		RADAR_Altitude = 44330*(1-(pow((BMP_Perssure/101325),(1/5.255))));
		HAL_Delay(100);
  	}

    ///////////////////////////////////////////////////////////////////////////////////
    ///////////////////////////////////////ADF4382/////////////////////////////////////
    ///////////////////////////////////////////////////////////////////////////////////
    printf("Starting ADF4382A Radar LO System...\n");
    printf("Using SPI4 with TIMED SYNCHRONIZATION (60 MHz clocks)\n");

    // Initialize LO manager with TIMED synchronization
    int ret = ADF4382A_Manager_Init(&lo_manager, SYNC_METHOD_TIMED);
    // Set phase shift (e.g., 500 ps for TX, 500 ps for RX)
    ADF4382A_SetPhaseShift(&lo_manager, 500, 500);

    // Strobe to apply phase shifts
    ADF4382A_StrobePhaseShift(&lo_manager, 0); // TX device
    ADF4382A_StrobePhaseShift(&lo_manager, 1); // RX device
    if (ret != ADF4382A_MANAGER_OK) {
        printf("LO Manager initialization failed: %d\n", ret);
        Error_Handler();
    }

    // Check initial lock status
    bool tx_locked, rx_locked;
    ret = ADF4382A_CheckLockStatus(&lo_manager, &tx_locked, &rx_locked);
    if (ret == ADF4382A_MANAGER_OK) {
        printf("Initial Lock Status - TX: %s, RX: %s\n",
               tx_locked ? "LOCKED" : "UNLOCKED",
               rx_locked ? "LOCKED" : "UNLOCKED");
    }
    // Wait for both LOs to lock
        uint32_t lock_timeout = 0;
        while (!(tx_locked && rx_locked) && lock_timeout < 100) {
            HAL_Delay(100);
            ADF4382A_CheckLockStatus(&lo_manager, &tx_locked, &rx_locked);
            lock_timeout++;

            if (lock_timeout % 10 == 0) {
                printf("Waiting for LO lock... TX: %s, RX: %s\n",
                       tx_locked ? "LOCKED" : "UNLOCKED",
                       rx_locked ? "LOCKED" : "UNLOCKED");
            }
        }

        if (tx_locked && rx_locked) {
            printf("Both LOs locked successfully!\n");
            printf("Synchronization ready - 60 MHz clocks on SYNCP/SYNCN pins\n");
            // - 60 MHz phase-aligned clocks on SYNCP/SYNCN pins
            // - SYNC pin connected for triggering
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

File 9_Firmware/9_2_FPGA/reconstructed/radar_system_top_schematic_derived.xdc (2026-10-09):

# ============================================================================
# radar_system_top — CANDIDATE pin constraints DERIVED FROM SCHEMATIC
# Source   : 4_Schematics and Boards Layout/4_6_Schematics/MainBoard/RADAR_Main_Board.sch  (part U42 = XC7A50T-2FTG256I)
# Generated: 2026-10-08 by tools/gen_xdc_from_schematic.py
# STATUS   : NOT VERIFIED ON HARDWARE. Each line cites the schematic net and FPGA pad.
#            Review PIN_MAP_FROM_SCHEMATIC.md before use. Timing constraints are NOT
#            included here — keep them in a separate file (see cntrt.xdc lines 14-27).
# NOTE     : schematic device is XC7A50T-2FTG256I; RTL/README state XC7A100T.
#            FTG256 ball names are shared across XC7A50T/XC7A100T but the part number
#            used in Vivado MUST match the board (UNRESOLVED — designer to confirm).
# ============================================================================

set_property PACKAGE_PIN E12 [get_ports {clk_100m}]   ;# net FPGA_SYS_CLOCK, pin IO_L13P_T2_MRCC_15 [MEDIUM]
set_property IOSTANDARD LVCMOS33 [get_ports {clk_100m}]   ;# bank 15 VCCO=+3V3_FPGA
set_property PACKAGE_PIN C13 [get_ports {clk_120m_dac}]   ;# net FPGA_DAC_CLOCK, pin IO_L12N_T1_MRCC_15 [MEDIUM]
set_property IOSTANDARD LVCMOS33 [get_ports {clk_120m_dac}]   ;# bank 15 VCCO=+3V3_FPGA
set_property PACKAGE_PIN N14 [get_ports {adc_dco_p}]   ;# net ADC_DCO_P, pin IO_L12P_T1_MRCC_14 [HIGH]
set_property IOSTANDARD LVDS_25 [get_ports {adc_dco_p}]   ;# bank 14 VCCO=+3V3_FPGA: LVDS_25 input with DIFF_TERM requires 2.5 V VCCO (UG471) — REQUIRES VERIFICATION
set_property PACKAGE_PIN P14 [get_ports {adc_dco_n}]   ;# net ADC_DCO_N, pin IO_L12N_T1_MRCC_14 [HIGH]
set_property IOSTANDARD LVDS_25 [get_ports {adc_dco_n}]   ;# bank 14 VCCO=+3V3_FPGA: LVDS_25 input with DIFF_TERM requires 2.5 V VCCO (UG471) — REQUIRES VERIFICATION
set_property PACKAGE_PIN T5 [get_ports {adc_pwdn}]   ;# net ADC_PWRD, pin IO_L23N_T3_A02_D18_14 [HIGH]
set_property IOSTANDARD LVCMOS33 [get_ports {adc_pwdn}]   ;# bank 14 VCCO=+3V3_FPGA
set_property PACKAGE_PIN A15 [get_ports {dac_sleep}]   ;# net DAC_SLEEP, pin IO_L9N_T1_DQS_AD3N_15 [HIGH]
set_property IOSTANDARD LVCMOS33 [get_ports {dac_sleep}]   ;# bank 15 VCCO=+3V3_FPGA
set_property PACKAGE_PIN C11 [get_ports {tx_mixer_en}]   ;# net MIX_TX_EN, pin IO_L11P_T1_SRCC_15 [HIGH]
set_property IOSTANDARD LVCMOS33 [get_ports {tx_mixer_en}]   ;# bank 15 VCCO=+3V3_FPGA
set_property PACKAGE_PIN D11 [get_ports {rx_mixer_en}]   ;# net MIX_RX_EN, pin IO_L14N_T2_SRCC_15 [HIGH]
set_property IOSTANDARD LVCMOS33 [get_ports {rx_mixer_en}]   ;# bank 15 VCCO=+3V3_FPGA
set_property PACKAGE_PIN G15 [get_ports {fpga_rf_switch}]   ;# net M3S_VCTRL, pin IO_L24N_T3_RS0_15 [MEDIUM]
set_property IOSTANDARD LVCMOS33 [get_ports {fpga_rf_switch}]   ;# bank 15 VCCO=+3V3_FPGA
set_property PACKAGE_PIN F13 [get_ports {stm32_new_chirp}]   ;# net DIG_0, pin IO_L16N_T2_A27_15 [MEDIUM]
set_property IOSTANDARD LVCMOS33 [get_ports {stm32_new_chirp}]   ;# bank 15 VCCO=+3V3_FPGA
set_property PACKAGE_PIN E16 [get_ports {stm32_new_elevation}]   ;# net DIG_1, pin IO_L17P_T2_A26_15 [MEDIUM]
set_property IOSTANDARD LVCMOS33 [get_ports {stm32_new_elevation}]   ;# bank 15 VCCO=+3V3_FPGA
set_property PACKAGE_PIN D16 [get_ports {stm32_new_azimuth}]   ;# net DIG_2, pin IO_L17N_T2_A25_15 [MEDIUM]
set_property IOSTANDARD LVCMOS33 [get_ports {stm32_new_azimuth}]   ;# bank 15 VCCO=+3V3_FPGA
set_property PACKAGE_PIN F15 [get_ports {stm32_mixers_enable}]   ;# net DIG_3, pin IO_L18P_T2_A24_15 [MEDIUM]
set_property IOSTANDARD LVCMOS33 [get_ports {stm32_mixers_enable}]   ;# bank 15 VCCO=+3V3_FPGA
set_property PACKAGE_PIN E15 [get_ports {reset_n}]   ;# net DIG_4, pin IO_L18N_T2_A23_15 [MEDIUM]
set_property IOSTANDARD LVCMOS33 [get_ports {reset_n}]   ;# bank 15 VCCO=+3V3_FPGA
set_property PACKAGE_PIN J16 [get_ports {stm32_sclk_3v3}]   ;# net STM32_SCLK1, pin IO_L23N_T3_FWE_B_15 [HIGH]
set_property IOSTANDARD LVCMOS33 [get_ports {stm32_sclk_3v3}]   ;# bank 15 VCCO=+3V3_FPGA
set_property PACKAGE_PIN H13 [get_ports {stm32_mosi_3v3}]   ;# net STM32_MOSI1, pin IO_L20N_T3_A19_15 [HIGH]
set_property IOSTANDARD LVCMOS33 [get_ports {stm32_mosi_3v3}]   ;# bank 15 VCCO=+3V3_FPGA
set_property PACKAGE_PIN G14 [get_ports {stm32_miso_3v3}]   ;# net STM32_MISO1, pin IO_L21P_T3_DQS_15 [HIGH]
set_property IOSTANDARD LVCMOS33 [get_ports {stm32_miso_3v3}]   ;# bank 15 VCCO=+3V3_FPGA
set_property PACKAGE_PIN P5 [get_ports {stm32_sclk_1v8}]   ;# net STM32_SCLK_1V8, pin IO_L10P_T1_34 [HIGH]
set_property IOSTANDARD LVCMOS18 [get_ports {stm32_sclk_1v8}]   ;# bank 34 VCCO=+1V8_FPGA
set_property PACKAGE_PIN M1 [get_ports {stm32_mosi_1v8}]   ;# net STM32_MOSI_1V8, pin IO_L2N_T0_34 [HIGH]
set_property IOSTANDARD LVCMOS18 [get_ports {stm32_mosi_1v8}]   ;# bank 34 VCCO=+1V8_FPGA
set_property PACKAGE_PIN N3 [get_ports {stm32_miso_1v8}]   ;# net STM32_MISO_1V8, pin IO_L3P_T0_DQS_34 [HIGH]
set_property IOSTANDARD LVCMOS18 [get_ports {stm32_miso_1v8}]   ;# bank 34 VCCO=+1V8_FPGA
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

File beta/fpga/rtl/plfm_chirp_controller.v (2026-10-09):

`timescale 1ns / 1ps

// BETA (beta/fpga/CHANGELOG.md): single clock domain (clk_120m). clk_100m is kept in the port
// list for interface compatibility but is no longer used inside this module.
module plfm_chirp_controller_enhanced (
    input wire clk_120m,
    /* verilator lint_off UNUSEDSIGNAL */
    input wire clk_100m,
    /* verilator lint_on UNUSEDSIGNAL */
    input wire reset_n,
    input wire new_chirp,
    input wire new_elevation,
    input wire new_azimuth,
    input wire mixers_enable,
    output reg [7:0] chirp_data,
    output reg chirp_valid,
	 output wire new_chirp_frame,
    output reg chirp_done,
    output reg rf_switch_ctrl,
    output wire rx_mixer_en,
    output wire tx_mixer_en,
    output wire adar_tx_load_1,
    output wire adar_rx_load_1,
    output wire adar_tx_load_2,
    output wire adar_rx_load_2,
    output wire adar_tx_load_3,
    output wire adar_rx_load_3,
    output wire adar_tx_load_4,
    output wire adar_rx_load_4,
    output reg adar_tr_1,
    output reg adar_tr_2,
    output reg adar_tr_3,
    output reg adar_tr_4,
    output reg [5:0] chirp_counter,
    output reg [5:0] elevation_counter,
    output reg [5:0] azimuth_counter
);

// Chirp parameters
parameter F_START = 30000000;       // 30 MHz (starting frequency)
parameter F_END = 10000000;         // 10 MHz (ending frequency)
parameter FS = 120000000;           // 120 MHz

// Timing parameters
parameter T1_SAMPLES = 3600;        // 30us at 120MHz
parameter T1_RADAR_LISTENING = 16440; //137us at 120MHz
parameter T2_SAMPLES = 60;          // 0.5us at 120MHz
parameter T2_RADAR_LISTENING = 20940; //174.5us at 120MHz
parameter GUARD_SAMPLES = 21048;    // 175.4us at 120MHz

// Chirp and beam parameters
parameter CHIRP_MAX = 32;
parameter ELEVATION_MAX = 31;
parameter AZIMUTH_MAX = 50;

// State parameters
parameter IDLE        = 3'b000;
parameter LONG_CHIRP  = 3'b001;
parameter LONG_LISTEN = 3'b010;
parameter GUARD_TIME  = 3'b011;
parameter SHORT_CHIRP = 3'b100;
parameter SHORT_LISTEN = 3'b101;
parameter DONE        = 3'b110;

reg [2:0] current_state;
reg [2:0] next_state;

// Control registers
reg [15:0] sample_counter;

// Edge detection for input signals
wire chirp__toggling, elevation__toggling, azimuth__toggling;

// LUTs for chirp waveforms
reg [7:0] long_chirp_lut [0:3599];  // T1_SAMPLES-1
reg [7:0] short_chirp_lut [0:59];   // T2_SAMPLES-1

// Edge detection
assign chirp__toggling = new_chirp;
assign elevation__toggling = new_elevation;
assign azimuth__toggling = new_azimuth;
assign new_chirp_frame = (current_state == IDLE && next_state == LONG_CHIRP);

// Mixers Enabling
assign rx_mixer_en = mixers_enable;
assign tx_mixer_en = mixers_enable;

// ADTR1000 pull to ground tx and rx load pins if not used
assign adar_tx_load_1 = 1'b0;
assign adar_rx_load_1 = 1'b0;
assign adar_tx_load_2 = 1'b0;
assign adar_rx_load_2 = 1'b0;
assign adar_tx_load_3 = 1'b0;
assign adar_rx_load_3 = 1'b0;
assign adar_tx_load_4 = 1'b0;
assign adar_rx_load_4 = 1'b0;
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

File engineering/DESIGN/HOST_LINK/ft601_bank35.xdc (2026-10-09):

## FT601 32-bit FT245 synchronous FIFO on FPGA bank 35 — PROPOSED (DSN-LINK-01 option A, 2026-10-09)
## Bank 35 VCCO = +3V3_FPGA (schematic); FT601 VCCIO = 3.3 V. Pins chosen from the 50 I/Os of bank 35 that have NO net
## in RADAR_Main_Board.sch; they become real only after the Main Board rev. B routes them (see HOST_LINK_DESIGN.md).
## RTL port names follow 9_Firmware/9_2_FPGA/usb_data_interface.v (ft601_*); BE must be widened to 4 bits (RTL defect).

set_property -dict {PACKAGE_PIN C4 IOSTANDARD LVCMOS33} [get_ports {ft601_clk}]   ;# IO_L12N_T1_MRCC_35
set_property -dict {PACKAGE_PIN A2 IOSTANDARD LVCMOS33} [get_ports {ft601_data[0]}]   ;# IO_L8N_T1_AD14N_35
set_property -dict {PACKAGE_PIN A3 IOSTANDARD LVCMOS33} [get_ports {ft601_data[1]}]   ;# IO_L4N_T0_35
set_property -dict {PACKAGE_PIN A4 IOSTANDARD LVCMOS33} [get_ports {ft601_data[2]}]   ;# IO_L3N_T0_DQS_AD5N_35
set_property -dict {PACKAGE_PIN A5 IOSTANDARD LVCMOS33} [get_ports {ft601_data[3]}]   ;# IO_L3P_T0_DQS_AD5P_35
set_property -dict {PACKAGE_PIN A7 IOSTANDARD LVCMOS33} [get_ports {ft601_data[4]}]   ;# IO_L1N_T0_AD4N_35
set_property -dict {PACKAGE_PIN B1 IOSTANDARD LVCMOS33} [get_ports {ft601_data[5]}]   ;# IO_L9N_T1_DQS_AD7N_35
set_property -dict {PACKAGE_PIN B2 IOSTANDARD LVCMOS33} [get_ports {ft601_data[6]}]   ;# IO_L8P_T1_AD14P_35
set_property -dict {PACKAGE_PIN B4 IOSTANDARD LVCMOS33} [get_ports {ft601_data[7]}]   ;# IO_L4P_T0_35
set_property -dict {PACKAGE_PIN B5 IOSTANDARD LVCMOS33} [get_ports {ft601_data[8]}]   ;# IO_L2N_T0_AD12N_35
set_property -dict {PACKAGE_PIN B6 IOSTANDARD LVCMOS33} [get_ports {ft601_data[9]}]   ;# IO_L2P_T0_AD12P_35
set_property -dict {PACKAGE_PIN B7 IOSTANDARD LVCMOS33} [get_ports {ft601_data[10]}]   ;# IO_L1P_T0_AD4P_35
set_property -dict {PACKAGE_PIN C1 IOSTANDARD LVCMOS33} [get_ports {ft601_data[11]}]   ;# IO_L9P_T1_DQS_AD7P_35
set_property -dict {PACKAGE_PIN C2 IOSTANDARD LVCMOS33} [get_ports {ft601_data[12]}]   ;# IO_L7N_T1_AD6N_35
set_property -dict {PACKAGE_PIN C3 IOSTANDARD LVCMOS33} [get_ports {ft601_data[13]}]   ;# IO_L7P_T1_AD6P_35
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

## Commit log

2026-10-09 Engineering reconstruction, drawings package and proposed designs (AERIS-10)
    - docs/: inventory, dependency map, missing components, recovery tasks,
    traceability matrix, FPGA/STM32/PCB/GUI/mechanical/testing documents,
    master manual v1.2 (Parts I–XII)
    - tools/: 36 validation/generation scripts (inventory, manifest, link,
    XDC, include, import and manufacturing checks; EAGLE→SVG schematic
    renderer; KiCad pipeline; BOM/netlist/connection reports; drawing
    register; mechanical/assembly generators; design generators)
    - engineering/: 84 registered drawings — schematics (SVG/PDF/PNG),
    netlists, KiCad-converted manufacturing packages for 4 boards
    (Gerber, drill, PDF, SVG, DXF, STE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
    [BOM_FREQUENCY_SYNTHESIZER.csv, BOM_MAIN_BOARD.csv, BOM_POWER_SUPPLY.csv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]
2026-10-09 README: correct Gerber/FPGA/10_docs statements; add beta/ index
    Claude-Session: https://claude.ai/code/session_01NeKhno53oHrfgWctGYA3Qu
2026-10-09 beta/stm32: buildable STM32F746 firmware (CMake + Arm GNU 14.2, HAL 1.3.3), CubeMX-equivalent USB CDC/startup/linker, 11 defect fixes, host tests 4/4
    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
    [main.cpp]
2026-10-09 Host link DSN-LINK-01 (FT601 bank-35 plan + SPI bridge RTL/STM32/GUI, tests pass), antenna openEMS simulation, register 86 drawings
    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
    [ft601_added_parts_BOM.csv, ft601_pin_assignment.csv, option_b_signal_map.csv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]
2026-10-09 beta/fpga: RTL builds (iverilog + verilator 0 errors), 5 missing modules written, seg3 mem generated, 5 self-checking testbenches PASS incl. end-to-end smoke test, timing+schematic XDC, Vivado Tcl
    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
    [cic_decimator_4x_enhanced.v, ddc_400m.v]
2026-10-09 antenna: S11 data/plot of the selected row configuration (openEMS)
    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
    [s11.csv]
2026-10-09 antenna: correct bandwidth statement (contiguous -10 dB band, comb response) in tuning log and calc sheet
    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
2026-10-09 beta/pcb: routing completion (Main 15→0, RF PA 1→0, Power 308→89 + 132 parts placed), DRC dispositions, BOMs with proposed MPNs, fab notes/stack-ups, re-exported packages; detailed enclosure/pedestal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
    [BOM_FREQUENCY_SYNTHESIZER_beta.csv, BOM_MAIN_BOARD_beta.csv, BOM_POWER_SUPPLY_beta.csv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]
2026-10-09 enclosure detail: flat patterns (DSN-MECH-06), assembly section with fasteners (DSN-MECH-07), mechanical parts list, isometrics; register 89 drawings
    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
2026-10-09 docs: manual v1.3 Part XIII (BETA completions), recovery tasks R-BETA, acceptance H, assembly pointer
    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
2026-10-09 beta/fpga: SPI host bridge integrated into the top (tb_host_bridge_top PASS, ADAR pass-through gated); HOST_LINK: back-port det_wr width fix + 32-detection regression test; check suite: beta hooks
    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
    [host_bridge_spi.v, tb_host_bridge.v, tb_host_bridge_top.v]
2026-10-09 beta/fpga: ISERDESE2 1:4 ADC capture with IDELAY calibration FSM, MMCM 200 MHz ref, bit-exact polyphase DDC/CIC at 100 MHz (ADC_CAPTURE_MODE), 9 testbench runs PASS; manual/tasks updated
    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
2026-10-09 design calcs: 2-D thermal map of the PA plate, pedestal torque vs move time (revises D-12), radar range equation; three-row antenna coupling model
    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
2026-10-09 beta/stm32: ADAR1000 VM tables from datasheet (Tables 10-13), channel-index bug fix C10, bridge register commands v2 (REG W/R ASCII), tests 6/6
    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
    [host_bridge.c, main.cpp]
2026-10-09 antenna: three-row mutual coupling simulation (S12 -20.7 dB at f0)
    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
    [coupling_3rows.csv]
2026-10-09 beta/gui: bridge frames as default hardware path, REG register commands + FPGA register/ADC calibration panel, demo register file, 72 tests, PyInstaller rebuilt
    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
2026-10-09 manual build kit: spec for Claude Design, outline/style/figure plan/assembly steps, asset index (225), chapter stubs, build_manual.py; beta/gui REG alignment (76 tests)
    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
2026-10-09 beta/pcb: Main Board rev. B with FT601 netlist (64 nets, USB-C, crystal, ESD), partial routing — bus blocked by U42 bank-35 fan-out (documented), full export package
    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
    [BOM_MAIN_BOARD_REVB_beta.csv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]
2026-10-09 manual: 7 board/antenna/manufacturing/parts chapters + figures; build_manual figure regex accepts [STATUS]; KiCad PDF exports autoscaled (--scale 0) and re-exported
    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
2026-10-09 beta/fpga_synth: open-source synthesis (Yosys) of the beta FPGA — 106/120 DSP, 12.8k LUT, async-read RAMs, pin budget; nextpnr-xilinx packed but placement incomplete (documented)
    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
2026-10-09 beta/fpga: SPI bridge command set v2 wired to the register map, blind ADC calibration (notch residual), UG471-verified ISERDES bit order and LVDS rules; build 0 failures, 9 testbench runs PASS; HOST_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
    [host_bridge_spi.v, tb_adc_iserdes_capture.v]
2026-10-09 beta/gui: final RTL register map v0x0002 (blind calibration registers, 5-bit addresses, status bit4), 76 tests, selftests OK
    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
2026-10-09 manual: complete 22-chapter AERIS-10 engineering & assembly manual (97.6k words, 69 figures), HTML + PDF (191 pages), figure log, validation record; manual v1.4 pointer
    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

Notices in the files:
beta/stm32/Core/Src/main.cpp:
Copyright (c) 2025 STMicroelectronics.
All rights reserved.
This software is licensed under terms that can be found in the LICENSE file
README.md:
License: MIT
